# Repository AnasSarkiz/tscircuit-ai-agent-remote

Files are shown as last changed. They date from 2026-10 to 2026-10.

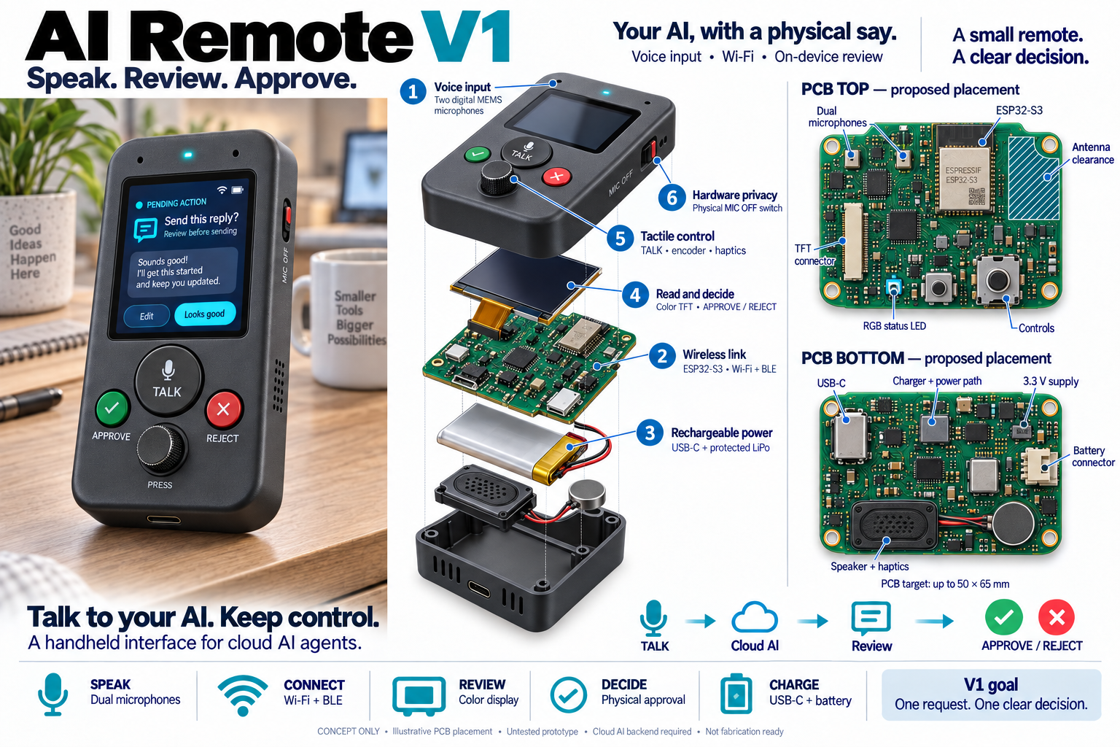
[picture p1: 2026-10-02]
assets/product-concepts/ai-remote-v1-infographic.png

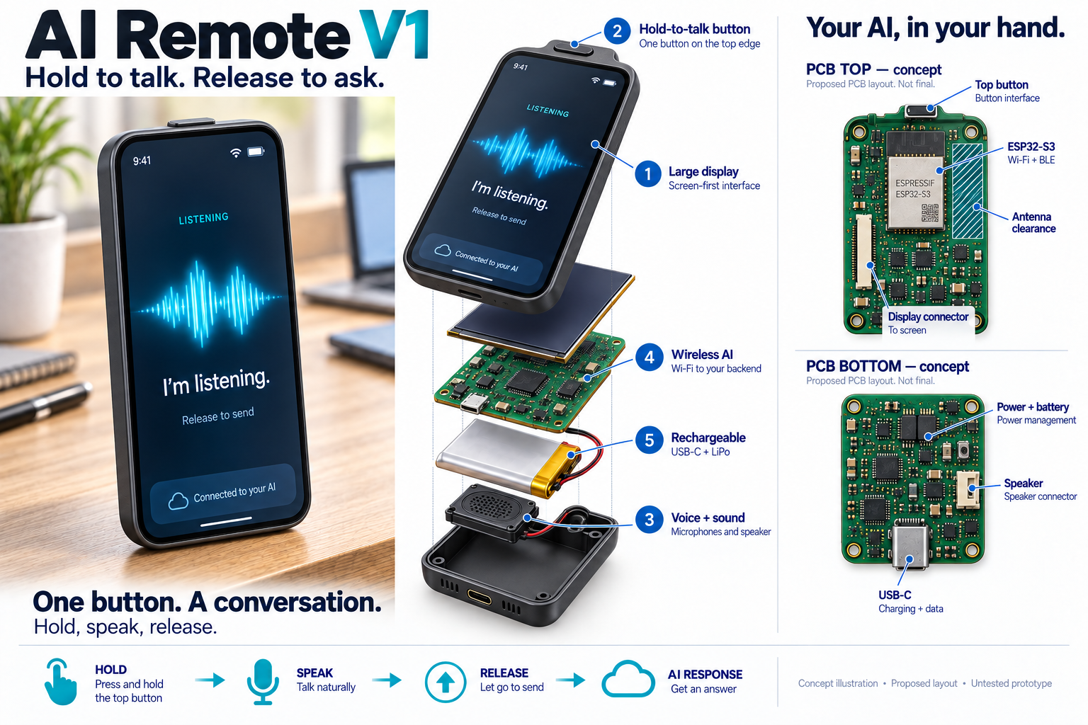
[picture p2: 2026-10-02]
assets/product-concepts/ai-remote-v1-infographic-v2.png

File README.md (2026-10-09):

**0.0.11-wip-generator-qualification — NOT READY TO ORDER.** Canonical project
runtime fixes eliminate all 169 schema failures and missing pill paste. The
untouched genuine C7848 import clears U14 supplier rotation. Local regulator
escape requirements now explicitly preserve 1 mm trunks. All 9,813 existing
connected pairs are preserved; all 125 purchased component poses are unchanged.
Fresh native checks still report 50 connection errors / 12 physically open
assigned nets plus two unassigned battery contacts. Shorts and measured copper
clearance violations are zero. The final 2.8-inch LCD, backlight, RF/mechanical
integration and battery polarity remain unqualified.

The corrected canonical Gerber library preserves USB slots. Independent strict
Gerber parsing and Excellon inspection pass; actual exports are explicitly
NOT FOR FABRICATION. Strict PnP rotation passes for all 125 parts, and the official
resolved BOM covers all 43 supplier identities. Current inventory confirms 39
identities conservatively; D2 is out of stock and three positive-stock records
require assembly-availability confirmation. Complete current/thermal and full fabrication gates remain open.
All 15 original schematic style issues are corrected in the actual schematic
trial, with identical PCB/CAD geometry. One newly exposed alignment advisory
misclassifies the VMOTOR flyback/bleeder parallel branches as a series pair;
its exact six-contact topology and conflicting orientation advice are reviewed
and retained in the schematic-style-repair evidence. Final routed checks are
recorded independently; no failure is hidden.

Core also prevents disabled subcircuits from starting autorouting during
updates; both disabled controls and an enabled control are regression-tested.
The actual isolated MCU diagnostic now has zero copper and zero routing events.
Board tests: 51 pass; the full-board fabrication gate still fails on 50
unresolved native connections. These are 50 assigned open contacts plus two
unassigned J3 contacts, not a completed board.

Receipts and source patches: `evidence/pcb-completion-2026-10-08/` and `toolchain/`.
Older entries below are historical.

---

**0.0.10-wip-microphone-bypass — NOT READY TO ORDER.** The existing C81
100 nF X7R capacitor moves beside U5 to (17.05, -28.1) mm / 180 degrees on top.
Its authored 0.3 mm top copper connects directly to the U5 supply escape and
ground pour; the remote capacitor escapes are explicitly retired.
R93 moves to (16.5, -31.42) mm to clear the capacitor; its actual supply and
clock-bias copper is rerouted while retaining/reusing existing drill positions.
A finite 2 mm supply limit is declared because the untouched supplier
courtyards impose a 1.38 mm minimum; the proposed direct route is 1.44 mm.
The ground branch has a finite 2.5 mm limit: preflight uses a GND pad 2.15 mm
away before the pour exists, while the actual top pour-entry stub is 0.60 mm. No part is
added or replaced, and no new via is required. The exact manufacturer recommends
short connections on one layer for this bypass. Actual native qualification,
remaining full-board gates and public delivery receipts are recorded in the
[current repair review](https://github.com/AnasSarkiz/tscircuit-ai-agent-remote/blob/main/evidence/microphone-local-bypass-2026-10-08/review.md).
The display/battery interfaces and fabrication gates remain unresolved; this
revision does not establish zero DRC, complete connectivity or order readiness.
Older entries below are historical.

---

**0.0.9-wip-standard-uart — NOT READY TO ORDER.** J6 now uses the genuine
JLCPCB **C160389 / JST BM03B-SRSS-TB(LF)(SN)** three-contact upward SH header.
Its UART contacts are RX/GND/TX (pins 1/2/3); hold-downs 4/5 are GND.
Authored native routes replace the former six-contact connector's connections,
with a local audio-gate detour, a 0.8 mm bottom-layer 3.3 V trunk bypass
and ordinary 0.30/0.45 mm through-via escapes.
The standard JST programmer's TX/GND/RX cable maps directly to these contacts;
the custom three-to-six adapter is removed. Programming requires separate
USB/battery power, manual BOOT/RESET and an open enclosure: mated connector
height is 6.3 mm. Hardware operation and cable assembly are untested.

The 2026-10-07 20:07 UTC official JLCPCB page reports C160389
`overseasStockCount=32191` and `canPresaleNumber=31559`, at a reference
$0.2743 each. These are public inventory fields; they do not establish global
warehouse totals, assembler allocation or an order quote. Purchased count
remains 125 parts / 43 identities. All other component poses are retained.

The requested 2.8-inch LCD is still unimplemented. Exact panel/flex/antenna
fit, J7 mapping, battery outer-contact numbering, full connectivity, toolchain
schema/paste/Gerber issues and current-carrying qualification remain gates.
See the [actual native qualification and remaining blockers](https://github.com/AnasSarkiz/tscircuit-ai-agent-remote/blob/main/evidence/programmer-direct-uart-2026-10-07/review.md).
Publication is recorded separately after exact remote byte verification.
Older status and connector references below describe historical revisions.

---

## Current speaker routing — 2026-10-07

**0.0.8-wip-speaker-routing — NOT READY TO ORDER.** Both amplifier outputs now
connect to J4 through short, explicitly authored top-layer routes. Five existing
purchased components and TP1 move to make this possible; no purchased part is
added. All 125 part identities and imported footprints/models are retained.

The completed official CLI output contains 384 traces, 325 full-span 0.30/0.45 mm
vias and 270 pours. Independent geometry checks measure **zero shorts and zero
clearance violations**, preserve all 9,842 prior terminal pairs and verify all
247 active authored regions at their nominal widths. High-current trunks use
outer layers. **50 native open-port errors and 12 physically open nets remain**
around the deferred display. J3 outer polarity is still unassigned and excluded
from that count. These measurements do not establish full zero DRC.

TypeScript, formatting, 92 routing regressions and the five source/placement
checks pass. Board tests are 48 pass / 2 fail. All 26 schematic pages were
inspected; CLI style analysis reports zero issues, while UI analysis is blocked
by the CDN certificate. Native schema, pill-pad paste, official shorts/Gerber
export, supplier rotation and current/width qualification remain blocked.

The battery PDF is retrieved, but does not number its outer harness contacts.
Display contact orientation remains unverified. Exact stock covers 42 of 43
part identities for two boards; J6/C160405 is unavailable. Reference parts cost
is $26.333 per board before fabrication, assembly, external assemblies and
shipping. This is not an orderable quotation.

[Current evidence and remaining gates](evidence/routing-continuation-2026-10-07/review.md).
[Versioned public package](https://tscircuit.com/AnasSarkiz/tscircuit-ai-agent-remote?version=0.0.8-wip-speaker-routing#files).
Publication verification is recorded in the evidence receipts. The older
checkpoints below are historical and are superseded by this entry.

---

## Historical manual routing repair — 2026-10-07

**0.0.7-wip-manual-routing-repairs — NOT READY TO ORDER.** This entry
supersedes the historical checkpoints below. U4 now has a real 0.36 mm ground
escape to a 0.30/0.45 mm through via. Its clock/data escapes were moved to make
room while retaining their original nets and minimum widths.

The supported source CLI build completes in 251.86 seconds and exits 1 with
**52 open-port errors**: 46 J7 display contacts, four U27 backlight contacts and
two SPEAKER_N contacts. The unchanged generated JSON contains 381 traces,
325 through vias and 271 pours. Independent geometric checks measure **zero
shorts and zero clearance violations**, preserve all 9,842 previously connected
numbered-terminal pairs and verify all 247 authored regions at their nominal
widths. There are still 13 physically open nets. J3's unassigned outer contacts
are excluded from that count; battery polarity and display mating remain
unqualified. Every purchased component footprint, pose and model is unchanged.

A speaker/VSYS candidate was rejected: its native output disconnected U25.2 and
C76.2 ground, losing 266 existing terminal pairs, and reported a bus-skew error.
The candidate and follow-up proposals are preserved as evidence, not accepted
routing. Original speaker constraints and original power copper remain intact.
No native errors or checks were suppressed.

The five source/placement checks pass. Board tests remain 48 pass / 2 fail;
169 strict native-schema failures, 32 missing U16/U27 paste records and the
official shorts/export error “Unsupported shape polygon” still block approval.
Two regulator traces violate explicit source widths; 63 nominal-width branches
and current/signal-integrity qualification remain open. Stock and programmer
limitations in the prior review still apply. No order or physical test occurred.

Primary supplier retrieval is blocked by HTTP 403 from the cloud policy. Add
`www.buydisplay.com` and `www.elektronik.ropla.eu` to the existing Environment
settings allowlist, then save and publish it to resume exact J3/J7 qualification.
The editable allowlist was unavailable; no unknown list was replaced.

[Current repair review and exact receipts](https://github.com/AnasSarkiz/tscircuit-ai-agent-remote/blob/main/evidence/routing-zero-drc-2026-10-07/review.md).
Matching public publication and cloud CI are separate observations; a WIP
preview does not establish zero DRC or fabrication readiness.

---

## Previous connection repairs — 2026-10-06

**0.0.6-wip-connection-repairs — NOT READY TO ORDER.** This is a historical
source/native checkpoint, superseded by the manual routing repair above.

Manual native routing reduces open-port errors from 89 to **53** and physically
open nets from 25 to **13**. The actual frozen-install CLI build completes in
256.86 seconds and exits 1 on the remaining errors. Its unchanged native output
has 380 traces, 322 full-span 0.30/0.45 mm vias and 269 pours. Independent copper
measurement finds **zero shorts and zero clearance violations**, preserves all
8,152 previously connected numbered-terminal pairs and adds 1,690 connected
pairs. All 245 authored regions meet their nominal widths after fixing an
outline-generator defect at short bends. Component footprints, poses, models
and original solver caches remain unchanged.

Source checks, CLI schematic style, TypeScript, formatting and 80 routing
regressions pass. Full board tests remain 48 pass / 2 fail. Remaining native
errors are 46 J7, four backlight U27, two SPEAKER_N contacts and U4 ground.
J3's centre NTC is routed; its outer polarity and J7 mating remain unqualified.
Two regulator routes violate their explicit source widths; 63 nominal-width
branches, current/signal integrity, 169 schema failures, 32 missing paste
records and polygon Gerber export still block fabrication. Dated stock still
shows J6/C160405 unavailable. The standard programmer needs the documented
adapter and has not been hardware-tested.

[Actual repair review and receipts](https://github.com/AnasSarkiz/tscircuit-ai-agent-remote/blob/main/evidence/connection-repair-2026-10-06/review.md).
Matching public source/native publication is established by its anonymous
verification receipts, not by preview availability or a passing cloud CI claim.
No fabrication order or physical test has been performed.

---

## Current six-point review — 2026-10-06

**0.0.5-wip-style-vias-power — NOT READY TO ORDER.** This entry supersedes the older counts and status below.

J1 now uses the requested native USB-C schematic symbol while preserving its numbered contacts, supplier identity, physical footprint and models. CLI schematic-placement analysis reports zero issues. The actual UI analysis was invoked but its external analysis module failed to load; this is a blocked check, not a passing result.

The clarified high-current requirement is implemented: all 80 authored high-current trunks and 59 audited native high-current traces use top/bottom copper. Six low-current pull-up/control/probe branches have separate documented requirements. All 217 vias physically span all four layers, with exactly 0.30 mm holes and 0.45 mm pads; blind/buried vias are explicitly disabled. All 151 native supply/control and relocated signal regions meet their nominal widths.

The supported frozen-install CLI build completes in 247.03 seconds and exits 1 with **89 real open-port errors**. Native output contains 328 traces, 217 vias and 183 pours. The independent geometry audit measures zero shorts and zero clearance violations, preserves all 8,146 previously connected port pairs, and still finds **25 physically open nets**. All 125 purchased component footprints, poses and models are unchanged. TP1 moves to (-22.2, 12.3) mm inside the main ground island. The five source checks, copper-free placement build, TypeScript, formatting and 64 routing regressions pass. Board tests report 48 pass / 2 fail (fabrication and strict native schema).

Official exact-part JLCPCB pages cover all 43 identities / 125 placements: 42 identities report enough total stock for one board; **J6 C160405 reports zero stock**. Positive stock for U1, D2 and U16 does not qualify assembly allocation. No stock reservation or assembler rotation approval is claimed.

Remaining fabrication blockers include unresolved J3 numbered outer polarity and J7 FPC mating, incomplete connections, 169 strict native-schema failures, missing pill-pad paste, unsupported polygon Gerber shorts/export, two regulator switching routes with 0.275 mm necks below their explicit 1.0 mm source requirement, 55 nominal-net-width branches requiring load review, and supplier rotations/current/stackup/signal-integrity/mechanical qualification. The standard JST programmer needs the documented adapter; direct connector mating and hardware operation are untested.

The supported source snapshot comparison completes in 61.13 seconds and fails on PCB and schematic differences; committed references are retained. All 26 native A4 pages, four copper layers, mask/paste and critical zooms were inspected. Native component guides cover all 135 references with valid annotation schema. Final component inventory confirms 32 missing pill-pad paste records on U16/U27.

[Full review and actual receipts](evidence/six-point-board-review-2026-10-06/review.md). Publication is recorded independently; native preview availability does not establish passing cloud CI or fabrication approval. No order or physical test has been performed.

---

## Schematic component explanations — 2026-10-06

Revision `0.0.4-wip-schematic-notes` adds a plain-English explanation for every
schematic component reference: 125 purchased components and 10 solder/test
pads. The 13 circuit drawings link to paired A4 component-guide pages, numbered
14–26, to keep the original symbols and connections readable.

Open the schematic sheet selector in tscircuit and choose a **Component guide**
page for the relevant circuit. Guides explain power, controls, USB/programming,
display, speaker, haptic drive, microphones, backlight and measurement access.
Battery connector polarity and display mating remain explicitly unverified.

[Annotation validation and rendered pages](https://github.com/AnasSarkiz/tscircuit-ai-agent-remote/blob/main/evidence/schematic-component-notes-2026-10-06/review.md).
This documentation revision does not establish fabrication or hardware readiness.

The fresh frozen-install native CLI build completed in249.96seconds and
retains90open-port errors. Annotation coverage/native schema, TypeScript and
formatting checks pass. AllPCB/source nets/ports and the original schematic
symbols/wires/labels match the prior board. The source checkpoint verifies
unchanged imports, models, lockfile and routing artifacts. The accepted schematic
snapshot adds all26A4pages; the PCB reference remains unchanged.

Final board checks remain blocked:47tests pass/3fail,169native schema failures
and90open ports. The placement fixture's extra mismatch is only10native test
pads receiving empty supplier maps from the CLI; strict PCB/net comparison
passes. The required source snapshot reaches its recorded360-second budget;
the supported snapshot of accepted native JSON completes, passes the reviewed
schematic reference and retains the original PCB-reference mismatch.

---

## Latest MCU correction — 2026-10-06

**Revision `0.0.3-wip-local-bypass`; NOT READY TO ORDER.** C31 now has a
native top-layer local supply/ground connection beside U1: supply-pin distance
falls from36.000mm to2.000mm, with a0.8mm branch to the existing U1 supply
escape and no additional supply via. C30 now uses the genuine imported
22µF GRM188R61A226ME15D/C84419 shown in Espressif's reference circuit.
Bulk placement/effective capacitance and microphone bypasses still need work.

Fresh native copper has306 traces,249 full-span ordinary vias and190 pours:
**0measured shorts/clearance violations**, but26 open nets/90 native errors and
35GND islands remain. All152 authored region widths pass; two switch traces
and55 nominal-width branches still need correction/current qualification.
Eight target programmer copper groups pass; programming is not hardware-tested.
The supported BOM resolver generates125 purchased rows with verified recorded
MPNs/package labels and no blank descriptions. Current stock, rotations,
169schema failures,32missing paste apertures, polygon Gerber export and exact
battery/display mating still block fabrication.

[Correction evidence](evidence/board-corrections-2026-10-06/review.md).
The complete publication package now installs with the original frozen lockfile.
Its native CLI build finishes in222.33seconds and reports the90open-port errors;
all physical copper records match the validated board. Publication/remote CI
receipts are separate; this is a WIP step, not fabrication approval.

Fresh frozen-install snapshot also completes and fails on both original SVG
references (246.93seconds); references were not updated. Source discovery is
working, while board validation remains blocked.

---

## Latest placement, component and programmer review — 2026-10-06

**NOT READY TO ORDER.** Electrical placement needs correction even though the
native overlap check passes: U1's nearest external3V3 bypass is26.160mm away;
U5's assigned100nF bypass is18.191mm away on a different supply copper island.
The manufacturer's local microphone bypass recommendation is not met by the
current separate-via arrangement.19 IC supply locations are measured in the
[new six-point review](evidence/board-programmer-stock-review-2026-10-06/review.md).

The requested Standard JST programmer v0.8.0 can use UART conditionally:
J5.1TX→J6.6RX, J5.2GND→J6.1GND, J5.3RX→J6.5TX. A custom3-to6 adapter,
separate target power, matching firmware and manual BOOT/RESET are required.
5host logical and8target logical/physical groups pass; no actual flashing test.
Fresh manufacturer pin tests5pass/0fail. Board copper/parts/imports remain
unchanged:26 open nets/90 native port errors and existing fabrication blockers.

All43 exact JLCPCB identities/125 placements have a dated stock manifest;
**current stock is unverified**, because the inherited proxy denies
jlcsearch.tscircuit.com with403. That one domain was added to the reusable
network draft; review/save and publish it in environment settings before retry.
Saving the draft does not apply or publish it. Historical C107701 stock8vs5
per board and C98220 stock22vs20 warrant priority refresh. No unchanged board
registry upload or fabrication approval is claimed.

## Current order-readiness audit — 2026-10-06

**NOT READY TO ORDER.** Fresh current native render is byte-identical to the
canonical board. Measured geometry:0 shorts/0 clearance violations, but26
physically open nets and90 native connection errors; J3 outer contacts are
additional unassigned omissions. All306 traces/792 wire segments checked:
0 below0.20 mm,2 regulator switch routes below explicit1.0 mm source minima,
and55 traces below named-net nominal widths needing current/escape review.
All152 authored region widths pass. Current critical manufacturer pin tests
pass; physical connectivity and current capacity remain unapproved.

Assembly still fails:32 missing U16/U27 paste records,169 native schema
failures,31 blank BOM descriptions,125 unqualified supplier rotations.
J3 pack polarity/J7 flex mating, stock/stackup/current/mechanical/fabrication
qualification remain open. Types and60 routing regressions pass; board tests
47pass/2real failed gates. Board/import/dependency/cache bytes unchanged.
[Full order-readiness report and measurements](evidence/order-readiness-2026-10-06/review.md).
This verification adds no copper and does not create a duplicate registry upload.

## Current cloud routing checkpoint — 2026-10-05

Public [tscircuit0.0.2-wip-cloud-routing](https://tscircuit.com/AnasSarkiz/tscircuit-ai-agent-remote?version=0.0.2-wip-cloud-routing#files) now has**116/116 exact-matching files**, including current native JSON and required display-connector STEP. A supported multipart archive resumed the existing release and enabled its normal cloud build, which has started. [Exact upload/build evidence](evidence/cloud-tsci-publication/review.md). This is an engineering WIP; fabrication is not approved.

[Board preview](https://tscircuit.com/AnasSarkiz/tscircuit-ai-agent-remote/releases/c6bd1e5c-0979-498a-bb8a-9533013cf51d/preview): the registry preview endpoint finds `index.circuit.tsx` and returns the native board array identical to the locally generated artifact. The separate cloud CI build remains running in the latest observation; no completed CI result is claimed.

**Engineering WIP — routing incomplete; NOT FABRICATION READY.** Native output from the matching current source has **306 traces, 250 ordinary full-span vias, 190 pours and 90 native open-port errors**. The independent geometry audit reports **0 measured violations / 0 shorts**, with all **152 authored region widths preserved**, but **26 physically disconnected nets** remain. J7 accounts for46 native errors; unassigned J3 outer contacts are outside that count.

[Current review](evidence/cloud-runs/review.md) · [Exact build receipt](context/build-checkpoint.json) · [Cloud continuation](CLOUD_HANDOFF.md). Native JSON SHA256 `81c31f77ac0871bfc4414b0940752e4f4fe0692a62089320b409908d4a8d5315`. TypeScript/maintained-source formatting pass; routing regressions17pass; board tests42pass/2failing fabrication/schema gates. Five electrical/placement checks and copper-free CLI placement build pass. Full routed CLI build/bitmap shorts/snapshot exceed time budgets; Gerber export/shorts fail unsupported polygon. Native schema169failures and32missing U16/U27 paste records remain. Battery/display mating, current/SI, BOM/CPL/stock and final mechanical/fabrication qualification are open.

The managed cloud instance supports the checked native workflow. Source `scripts/cloud/env.sh`; use the single-operation supervisor. Verified lossless event archives prevent CLI file-loader memory exhaustion. Clean frozen installation still needs the unapplied api.github.com network allowance; startup instructions are saved as a draft. GitHub and complete registry WIP publication do not approve fabrication; do not repeat unchanged uploads.

---

## A7 Codex Cloud migration checkpoint — 2026-10-05

Local memory-intensive routing is stopped at the user's request. Continue this existing board in Codex Cloud using [CLOUD_HANDOFF.md](CLOUD_HANDOFF.md), [cloud start prompt](context/cloud-start-prompt.txt), root AGENTS.md, repository skills and original request/decision records. Linux setup: `bash scripts/cloud/setup.sh`; task shell: `source scripts/cloud/env.sh`. Every heavy command uses the single-operation memory/time supervisor. No cloud VM execution has yet been verified; the GitHub connector currently omits this board repository and needs the user's browser connection update.

Canonical generated `dist/index/circuit.json` is byte-identical to the last completed native replay and its restored board source: **138 traces, 116 vias, 275 native unconnected-port errors**. It is a partial engineering prototype. The two battery outer contacts and contact-dependent display fanout remain deferred. Known actual U2 ordinary-via clearance is **0.192053 mm versus 0.20 mm required**; its unbuilt correction is saved separately. Full copper/placement/mechanical/current/USB/paste/BOM/fabrication gates remain open. No new registry publication is attempted under the current A7 brief.

[Exact build receipt](context/build-checkpoint.json) and [296-file checkpoint manifest](context/checkpoint-sha256.json) identify the carried-over bytes. TypeScript passes; tests **40 pass / 4 fail**, formatting **13 errors** retained. These failures are not suppressed. Linux dependency setup/supervisor execution awaits the actual cloud environment. Historical raw native trials are losslessly archived with per-file hashes; accepted route files remain directly usable. Do not restart incomplete trials as accepted copper.

---

## A6 public outcome — verified 2026-10-04

Public [GitHub A6 implementation](https://github.com/AnasSarkiz/tscircuit-ai-agent-remote/commit/a699a2d4337d5eafa26a777fee58c037de491f8f) and committed circuit JSON are anonymously byte-verified. Public [tscircuit0.0.2-wip-a6-bom-routing](https://tscircuit.com/AnasSarkiz/tscircuit-ai-agent-remote?version=0.0.2-wip-a6-bom-routing#files) has102/103matching board-only files, including this JSON and all saved routes. The required11.4MB C262650 connector STEP is404 after native compressed/fallbackHTTP413; publisher exit1, ready_to_build=false, no mismatched/unverified or extra files. **B-009 publication remains incomplete.** GitHub push succeeded. [Exact receipts](evidence/a6-bom-routing-2026-10-04/publication/review.md). Receipt-only update changes no runtime inputs and does not trigger another upload. **NOT FABRICATION READY.**

---

## A6 current checkpoint — 2026-10-04

**Engineering prototype — NOT FABRICATION READY.** This supersedes historical A5 counts below. Genuine in-stock replacements are implemented: seven C22548→C21190 (eight C21190 total), six C105588→C22775. Active125 purchased PCB parts /43identities plus10native pads. Published core0.0.2083 polygon paste fixes13 formerly missing pads;32 pill pads still lack paste. Current native copper20traces/2vias; five missing backlight traces resolved, unconnected-port errors413→402. Genuine saved phase replay and actual added-copper geometry verified; all prior11traces/2vias unchanged.

Required five native checks and copper-free placement CAD build pass. Format/types pass; tests42pass/2retained failures and full native strict schema169failures. Diagnostic PCB-image shorts passes, but **required Gerber-based shorts check fails “Unsupported shape polygon”**. Canonical routed build exits1 with402 retained unconnected-port errors. Final layout/assembly/fabrication gates remain blocked. Fresh4layer/paste/detail/13A4/3D prototype previews inspected.

Battery centreNTC confirmed; outer numbered polarity is still absent from the exact supplier drawing and stays unrouted. BuyDisplay panel has integrated ILI9341 and82.712% nominal physical coverage; actual FPC/contactface/pin1 mating and current bare-panel availability remain unqualified. JST board-thickness tolerance requires a mechanical/stackup revision; current conservative height becomes15.07 mm at a qualifying1mm PCB, above15mm. PCB stays50×65 mm; case max60×75×15 mm. No fabricated confirmation, generic imports or orders.

[Detailed A6 review](evidence/a6-bom-routing-2026-10-04/review.md) · [Active inventory](evidence/a6-bom-routing-2026-10-04/inventory.md) · [Mechanical primary sources](evidence/a6-bom-routing-2026-10-04/mechanical-search.md). Parentfaa491d22d1a55210833a8ea3086ae56dc450245. Intended public version0.0.2-wip-a6-bom-routing; verify publication receipts before claiming upload complete. Watcher stays paused; no cross-chat issue messages.

---

## A5 public publication outcome — verified 2026-10-04

Implementation [314cb1b](https://github.com/AnasSarkiz/tscircuit-ai-agent-remote/commit/314cb1b36d0a9b6d641c018ce27288eb47815c95) is on public GitHub main. Anonymous raw Circuit JSON is byte-identical to the validated local output:2,728,724bytes, SHA256 f4319f271856f07477340c3342ce9a576236be438913be4aca5bd9786487d1c5. Public [tscircuit0.0.2-wip-a5-motor-pads](https://tscircuit.com/AnasSarkiz/tscircuit-ai-agent-remote?version=0.0.2-wip-a5-motor-pads#files) verifies94of95board-only files, including current Circuit JSON and all saved phases, with no extra or unverified/mismatched files. private=false/unlisted=false. Native compressed archive and fallback both reject the required11.4MB C262650 STEP with HTTP413; publisher exit1 and ready_to_build=false. **B-009 registry publication remains incomplete**, separately from the completed J8 source removal. No same-state retry, omitted model or forced cloud readiness was used.

Native source/checks/results and169 strict-schema failures are recorded in the A5 review. All imported definitions stayed unchanged. The newly rendered native SVG/log whitespace warnings from git diff --check were accepted as generator bytes, without hand-editing output. Old dist/index/3d.glb and mechanical.html are historical and were excluded from the95-file runtime publication; PCB and native JSON are current. The public source push succeeded; registry files are partial. Receipt-only outcome commit changes no board runtime inputs and does not trigger another publication. [Detailed receipts](evidence/a5-connector-simplification-2026-10-04/publication/review.md). **NOT FABRICATION READY.**

---

## A5 — motor solder pads and independent routing, 2026-10-04

J8 is removed at the user's request. The external vibration motor remains connected through native top-side 2 mm solder pads TP_MOTOR_P (VMOTOR/M+) at (22,−8) mm and TP_MOTOR_N (HAPTIC_N/M−) at (22,−11) mm. Pad copper edge gap is 1 mm; board edge gap is 2 mm. M− is the switched motor return, not a general GND pad. The motor harness requires soldering and enclosure strain relief. J6 remains: USB-C supports ESP32-S3 flashing/debugging, while J6 is optional backup UART/BOOT/EN access. Normal USB operation is intended, not physically tested. Five plug connectors remain: J1, J3, J4, J6 and J7. No imported component definitions were changed.

Native selected phases now retain 11 actual traces and 2 ordinary 0.30/0.70 mm through vias. The original four copper records are unchanged; all saved phases replay with identical trace/via records. REG_FB, REG_PG, HOLD_BUFFER_OUT, USB_CC1, USB_CC2 and CHARGER_ILIM have no remaining native connection errors on their selected terminals. Actual new wire minima: pad clearance0.20533 mm, other-net trace0.29987 mm, drill0.33834 mm. GND pour source clearance0.21 mm gives actual via antipad clearance0.20730 mm, resolving the measured0.19735 mm aperture gap. This is partial-signal geometry review, not whole-board current/impedance/fabrication approval.

Required five native checks and shorts exit0; placement-only build0 with no traces/vias/pours. Format/types0; tests42pass/2known failures (schema fixture and full fabrication gate); full strict native JSON has169 failing elements. Canonical build exits1 with413unconnected-port/5missing-trace errors retained. PCB, all four layers, MCU A4 sheet and controls A4 sheet were inspected. Snapshot changes reviewed as prototype previews only. Full placement, display/FPC, battery outer polarity, power/paste/BOM/stackup, case/harness and complete copper gates remain open. No fabrication outputs or physical tests approved.

Earlier charger routing attempts hit native iteration limits; an R1 relocation failed actual placement (R33/U16 conflicts) and was reverted to its prior valid location. Q9/C20917 routing exports cannot save the phase due to non-unique native port selector; raw events are preserved and that gate net remains unrouted. No reconstructed cache or runtime workaround was used. The screen has an integrated ILI9341 controller per the BuyDisplay datasheet; its FPC direction is still unqualified and display routing is deferred as instructed. J3 outer contacts stay open.

Evidence: [A5 review](evidence/a5-connector-simplification-2026-10-04/review.md), [exact replay](evidence/a5-connector-simplification-2026-10-04/routing-replay-receipt.json), [via measurements](evidence/a5-independent-routing-2026-10-04/native-final-via-audit.json). Parent source bff3a87c974d4684f3fb159b0958abbb8a10620e; intended public runtime version0.0.2-wip-a5-motor-pads. Publication outcome will be recorded separately. Watcher stays paused; cross-chat messaging stays disabled. **NOT FABRICATION READY.**

---

## A4 placement-review public outcome - verified

Implementation [9364e2c8](https://github.com/AnasSarkiz/tscircuit-ai-agent-remote/commit/9364e2c817dd659daa954bf2c50e6e0bb03fdbdf) and its freshly rebuilt Circuit JSON are public on GitHub and anonymously byte-verified. Public [tscircuit 0.0.2-wip-a4-placement-review](https://tscircuit.com/AnasSarkiz/tscircuit-ai-agent-remote?version=0.0.2-wip-a4-placement-review#files) has91/92 exact-matching runtime files, including that JSON and saved routes. The required C262650 STEP remains missing after native archive/fallback HTTP413; exit1/ready_to_build=false. B-009 publication completion remains blocked separately from local placement. [Exact publication receipt](evidence/a4-placement-gate-2026-10-04/publication/review.md). This outcome changes no board inputs and does not trigger an unchanged registry retry.

## Latest placement gate review — A4

**Native PCB placement checks pass, but the full placement gate is BLOCKED before additional routing.** Added a true copper-free inspection mode: `bun run build:placement`. Its native output has zero traces/vias/pours and exactly matches canonical components, connections, pads, holes and keepouts. All five required checks pass;126 native CAD body bounds have zero overlaps. Original four traces and saved routes remain unchanged. Current tests:41 pass/2 retained fabrication-schema failures. Fresh current Circuit JSON is rebuilt from the same source.

Before additional routing: qualify the actual BuyDisplay portrait FPC/pin1/contact fold, the 0.8 mm PCB/PH-header thickness and USB stackup, and case actuators/harness/mounting fit. Battery outer contacts stay unassigned/unrouted as instructed. The431 remaining connection errors are routing work, not a circular prerequisite for starting routing. [Detailed placement review](evidence/a4-placement-gate-2026-10-04/review.md). **NOT FABRICATION READY.** Intended public runtime version `0.0.2-wip-a4-placement-review`; see its receipt before claiming publication complete. Watcher paused; cross-chat messages disabled.

## A4 publication verified — partial registry outcome

Public [GitHub A4 implementation 1a0b0d0b](https://github.com/AnasSarkiz/tscircuit-ai-agent-remote/commit/1a0b0d0b77294438c431a3e4246079e4363f2f50) and anonymous committed Circuit JSON are verified. Public [tscircuit 0.0.2-wip-a4-display-coverage](https://tscircuit.com/AnasSarkiz/tscircuit-ai-agent-remote?version=0.0.2-wip-a4-display-coverage#files) contains 91 of 92 matching runtime files, including the same fresh built Circuit JSON. The required C262650 connector STEP remains missing after HTTP413 in the official compressed upload and native fallback; publisher exit 1, ready_to_build=false. **B-009 publication remains incomplete; NOT FABRICATION READY.** [Exact receipts](evidence/a4-display-coverage-2026-10-04/publication/review.md). These outcome notes change no board input and do not trigger another registry retry.

# Latest A4 — 82.7% physical display coverage trial

**WIP prototype; NOT FABRICATION READY.** This supersedes conflicting A3/A2 selections below. Provisional external BuyDisplay **ER-TFT026-1**, 46 × 64 mm portrait body, overlaps the unchanged 50 × 65 mm PCB by **82.712%** (81.737% with stated dimensional/position allocation). Overhang, flex and bezel are excluded. Bare-panel availability and the current drawing/FPC are still unconfirmed; this is not a qualified purchasable display selection.

Implemented genuine C157929/C173752 internal side-entry PH headers, TPS60230RGTR/C1848364 four-channel backlight with 10 kΩ nominal 62.4 mA total, moved placement/mounting trial, rotated battery envelope and **0.8 mm trial PCB**. The thin stackup and USB impedance need new qualification. Battery pin2=NTC; both outer contacts stay open. Four original native traces are preserved; most connections remain unrouted. Fresh canonical build retains 431 connection errors; 38 tests pass and two fabrication/schema gates fail. Placement and short checks pass without claiming full routing or fabrication approval.

[Full A4 engineering review](evidence/a4-display-coverage-2026-10-04/review.md) · [Interactive A4 native model and display envelope](http://127.0.0.1:4949/evidence/a4-display-coverage-2026-10-04/mechanical.html). Current PCB count:134 physical components,496PCB ports,76named nets. Watcher remains paused and cross-chat issue messages remain disabled. Publication receipts are recorded separately; intended public package version `0.0.2-wip-a4-display-coverage`.

---

## Latest A3 result — verified approved compressed attempt

The human approved official compression. The registry rejected the archive with HTTP 413; the native CLI fallback exited 1. Anonymous readback of [`0.0.2-wip-a3-buydisplay-first-copper-compressed`](https://tscircuit.com/AnasSarkiz/tscircuit-ai-agent-remote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) verifies 87 of 88 matching board-only files, including the current `dist/index/circuit.json`. The required C262650 STEP model is missing. HTTP 413 blocks both supported publication modes. B-009 remains open and `ready_to_build=false`; no custom upload, model omission or retry loop was used. [Exact outcome](evidence/a3-routing-2026-10-04/buydisplay/publication/compressed/review.md).

The reviewed Espressif WROOM-1 drawing (v1.8, page 42) specifies a module height of 3.1 ± 0.15 mm. At its maximum, the glass study has only 0.05 mm clearance before other assembly tolerances. Retaining the CAD model's 0.19 mm gap would conditionally require 15.01 mm total thickness, exceeding the 15 mm enclosure maximum. No enclosure enlargement or placement freeze is claimed. [Manufacturer-height calculation](evidence/a3-routing-2026-10-04/buydisplay/module-height-tolerance.json). Runtime source, package and Circuit JSON bytes remain unchanged by these outcome and qualification notes. **NOT FABRICATION READY.**

## A3 publication result — verified 2026-10-04

Public GitHub implementation [`68d79568`](https://github.com/AnasSarkiz/tscircuit-ai-agent-remote/commit/68d79568bb39478c9745e1b5a5fc102d3687b0a7) is verified. Public tscircuit [`0.0.2-wip-a3-buydisplay-first-copper`](https://tscircuit.com/AnasSarkiz/tscircuit-ai-agent-remote?version=0.0.2-wip-a3-buydisplay-first-copper#files) contains87of88exact matching runtime files, including the current built Circuit JSON; required C262650 connector STEP is missing after HTTP413. Native publication exits1; registry ready_to_build=false. The USB STEP timeout persisted correctly. **B-009 publication remains incomplete; NOT FABRICATION READY.** Exact receipts and details: [publication review](evidence/a3-routing-2026-10-04/buydisplay/publication/review.md). No runtime/package bytes changed during upload/readback. This receipt update and viewer actuator-corridor alignment change no board inputs and require no metadata-only registry version.

# Latest A3 BuyDisplay and first-copper checkpoint — 2026-10-04

**Engineering prototype — NOT FABRICATION READY.** This supersedes conflicting A2/A1 selections below. The external screen is now **BuyDisplay/EastRising ER-TFT022-1, bare 2.2-inch 240×320 TFT, no touch**, purchased separately from the PCB. JLCPCB supplies the board electronics and the genuine **AFC07-S50ECA-00/C262650 top-contact50-pin connector**, not the screen. Its54.36×40.3 mm landscape glass spans the full50 mm PCB width. The raised-glass/flex/height tolerance study remains open inside the unchanged50×65 mm PCB and60×75×15 mm maximum enclosure.

Electrical source wiring uses panel n→J7(51−n) for the planned right-edge single fold, SPI II mode1110,2.8 V logic/level translation and three separate TPS60231 current sinks. The old HS20HS072RX,12-pin connector and resistor-fed backlight are superseded. Battery centre2 staysPACK_NTC and the outer contacts stay open.

Actual partial copper now exists: two short MCU USB traces and two compact regulator switch traces,0vias. Original native routes/events and supported replay are preserved before moves; the regulator island/cache were moved together−8 mm X. The other nets are not routed. Current whole board:134physical components(126purchased+8testpoints),502PCB ports,75named nets. Required remaining-connection errors are retained; no fabrication outputs are approved. Full technical review: [BuyDisplay integration and fit limits](evidence/a3-routing-2026-10-04/buydisplay/review.md). [Live mechanical study](http://127.0.0.1:4949/evidence/a3-routing-2026-10-04/mechanical.html).

Native placement overlap/keepout errors are zero. Source, netlist and pin-specification checks have no errors; supplier metadata warnings and connector-access warnings remain disclosed. Four orientation suggestions were applied. The source-level schematic pin-map and imported connector orientation tests are distinct from physical panel operation. Full routing/schema/fabrication tests retain their failures; publication never means fabrication approval.

Source parent0300c2eed5d591b24dba9d2bdd59e17de0f94bf7. Intended public release0.0.2-wip-a3-buydisplay-first-copper; verify receipts before claiming it published. Background watcher remains paused. The user revoked cross-thread issue messages; no issues are sent to another chat.

## Public A2 remote outcome — verified 2026-10-04

Board implementation commit **8332577b7eff34815843084d4fbe5549d5066e78** reached public GitHub main; anonymous committed Circuit JSON is identical to local: 2,300,592 bytes, SHA-256 `fbf9e2b576a9e37f695e894d9458500c33d5508b052b10692dcf99bc474dcd3f`.

Public tscircuit releases **0.0.2-wip-a2-display-mounting** and the one bounded native retry **0.0.2-wip-a2-display-mounting-retry1** both contain all75 expected board-only files with exact anonymous byte-hash matches, zero missing/extra/unverified files, private=false/unlisted=false. Native publication exits1 each time:74reported successes/one timeout on `imports/TPS63802DLAR/TPS63802DLAR.step`; the timed-out model persisted correctly in both releases. The native CLI exits before its final `ready_to_build=true` update. Both releases remain **ready_to_build=false**, so **B-009 build queuing/publication completion remains blocked despite complete public file content**. Null build errors do not prove a cloud build. No forced readiness, custom upload, compression, evidence omission, repeated retry loop or imported-model edit was used.

Receipts and safe logs are in `evidence/routing-intake-2026-10-04/`; first attempt kept separately. Runtime/source bytes were frozen and unchanged throughout. Receipt-only follow-up does not change any board input or require another registry publication. Both paste/schema and this upload completion behavior were reported to the authorized correction chat. Background watcher remains paused.

[GitHub board revision](https://github.com/AnasSarkiz/tscircuit-ai-agent-remote/commit/8332577b7eff34815843084d4fbe5549d5066e78) · [Public tscircuit A2 files](https://tscircuit.com/AnasSarkiz/tscircuit-ai-agent-remote?version=0.0.2-wip-a2-display-mounting-retry1#files).

# Latest A2 checkpoint — 2026-10-04

**NOT FABRICATION READY.** This section supersedes conflicting historical A0/A1 selections and status below. A2 updates the genuine C11051 twelve-pin display connector, manufacturer display wiring, centre battery NTC, two native M2 mounting trials and provisional placement. Battery outer numbering remains pending; both outer contacts are unconnected/unrouted. Display/flex/enclosure/RF fit is still open; routing remains disabled. Full report: [A2 fabrication checkpoint](evidence/routing-intake-2026-10-04/fabrication-report.md).

# Public board publication — 2026-10-04

Both destinations are now **public** and anonymously accessible. Published source
commit **6f8f4a270e76c7455084a1d43ea92833694179f2** and registry release
**0.0.2-wip-a1-public-board**. Native upload exited0, 75 successes/zero failures;
anonymous exact-version readback verifies all 75 hashes with no missing, extra or
unverified files. Public GitHub and registry `dist/index/circuit.json` are identical
(2,298,951 bytes; SHA-256 `0be465e43d862abd74d8fa7b8f397738fcae90f8134c330cf2311bdf54d273ca`).
Registry `is_private=false`, `is_unlisted=false`, `public_dist_enabled=true`.
`ready_to_build=true` and null reported build errors do not establish a completed
cloud build or fabrication readiness. Receipt-only follow-up changes no runtime
input and needs no additional registry release.

The user requested public GitHub and tscircuit destinations and a committed built
Circuit JSON. The ignore rule now permits only `dist/index/circuit.json` within
`dist`; other build artifacts remain excluded. The board-only preparer includes
the current native build unchanged, so GitHub and the registry receive identical
bytes. Published release: **0.0.2-wip-a1-public-board**. Public visibility and identical
remote build hashes are verified below. Native build, all five pre-routing
checks, format and root/staged TypeScript pass. Tests retain the known B-010
failure (30 pass/one fail). The native JSON matches the inspected connector
revision except its filesystem metadata; zero traces/vias/native errors. Existing WIP fabrication blockers
remain explicit; routing stays disabled and the background watcher stays paused.

# AI Remote A1 — complete unrouted placement preview

Connector review, 2026-10-04: the speaker J4 and motor J8 were rotated 180° so
their actual CAD mating cavities face the left/right board edges. USB-C, battery
and service openings already face their intended edges. The display FPC stays
internal for the raised screen; exact ribbon/latch/Z clearance remains provisional.
Current full-board and connector close-up views are in
`evidence/connector-orientation-review-2026-10-04/after/`. Native placement has
zero errors and three preserved orientation warnings, detailed in that review.
No routing was enabled.

Published connector revision: **0.0.2-wip-a1-connectors-outward**, board-source
commit **0191b8e5db4c8c29dc7d75bcd43455cb1747200e**. Normal native file-by-file
upload succeeded for all 75 board-only files; exact-version readback verified
all hashes, including the fresh `dist/index/circuit.json`. No documents/scripts
were uploaded. Still a private, unrouted prototype with fabrication gates open.

Build the current board with `bun run build:placement`, then prepare the runtime-only
registry package with `bun run publish:prepare`. The preparer copies that native build
into `.publish/board/dist/index/circuit.json` byte-for-byte; commit the same root
`dist/index/circuit.json` to GitHub. Publish from `.publish/board` through the native
CLI with `--include-dist`. Keep installed dependencies outside the upload folder. The generated package contains
only the transitive board source, referenced imported OBJ/STEP models, build manifests
and `dist/index/circuit.json`; research documents, tests and scripts remain in GitHub.
Standard native file-by-file upload is used for this reduced package. It remains an
unrouted prototype. Exact file hashes and remote verification are recorded under
`evidence/minimal-board-publication-2026-10-04/`.

Following the user's magnetic-shutter package example, 27 genuine components were
re-imported with the native model-CDN option. Their footprint/pin definitions are
unchanged, and all 54 remote model assets match the original local assets byte-for-byte.
Six imports retain their reviewed local models, including the authorized microphone
hole correction; candidates with other changes were not installed. The final runtime
package has **75 files**, including the generated Circuit JSON.

Published private runtime release **0.0.2-wip-a1-board-runtime** from board-source
commit **81e745660507007623d7c0ccc5076fce237aa4b9**. Native publisher exited0 with
75 uploads/zero failures; exact-version readback verified all 75 byte hashes,
including `dist/index/circuit.json`, and no missing/extra files. Registry publication
is complete for this reduced runtime release; earlier full-evidence releases remain
historically incomplete. `ready_to_build=true` is upload/build-queue status, not proof
of a completed cloud build or fabrication approval.

**Prototype; not for fabrication.** The complete `main.tsx` now integrates all
major subsystems on a **50 × 65 mm**, four-layer, 1.6 mm board with 3 mm rounded
corners. The requested 50 × 55 mm first trial was rendered and retained; it had
connector/passive overlaps, so the preview uses the approved maximum height.

**122 genuine JLC-imported electronic components + 8 native copper test pads**,
all on top. Hardware includes ESP32-S3, USB-C, BQ24074 charging/power path,
TPS63802, two ICS-43434 microphones, MAX98357A, display connector, three-contact
battery/NTC connector, speaker connector, external motor connector/driver,
physical top HOLD button, side privacy switch and internal BOOT/RESET/service.

Views and the complete **13-page A4 schematic** are saved in
`evidence/integrated-preview-2026-10-03/`: `pcb-top.png`, `pcb-ratsnest.png`,
`3d-top.png`, `3d-bottom.png`, `schematic.pdf` and interactive `board.glb`.
These are generated from the actual circuit/models. The blue PCB rectangles
show the provisional raised LCD body/active area. The 3D images show PCB assembly;
they do not establish LCD/enclosure/battery fit.

Run `bun run build:placement` to rebuild. **Routing stays disabled**: there are
zero copper traces/vias and no saved route cache. No fabrication outputs or
physical qualification are claimed.

Provisional: HS17QS178RX display/FPC and backlight application; protected 1S
500–1000 mAh pack/NTC/polarity; enclosure-mounted 8 Ω speaker and 3 V motor;
TALK actuator, mounting/raised display/RF mechanics and privacy transitions.
Microphone polygon solder paste B-005, final electrical/thermal/mechanical
qualification, routing/DRC/fabrication exports, strict native schema B-010,
BOM-description B-015 remain open. B-009 is resolved for the runtime release above.
See `VALIDATION.md` and `BOM-preview.md`. The background watcher remains paused.

## Historical A0 records (superseded by A1 where they conflict)

# tscircuit AI agent remote

Revision A0-reference-import-review (work in progress), updated 2026-10-03: **B-008 reference labels are corrected through official JLC imports; B-003 ground ports remain verified. Independent circuit reviews exist; no complete handheld schematic or PCB exists.** Missing polygon solder paste remains a real assembly blocker. Requirements, component choices, electrical qualification and full placement remain unfinished; no routing or fabrication approval.

Private repository: https://github.com/AnasSarkiz/tscircuit-ai-agent-remote

Private tscircuit package: https://tscircuit.com/AnasSarkiz/tscircuit-ai-agent-remote
— last fully verified private source release is **0.0.2-wip-a0-core-alignment**
(274 files; Git 8bbde6e). Latest source commit **0573bf4492817ea0263827b6f0431fb7905d4959** reached GitHub; native private release
**0.0.2-wip-a0-hold-readback-review** exited1 with1081reported successes/20failures. Exact readback proves13reported failed files arrived byte-identically, while seven are404: six persistentHTTP413 files plus timeout C105188/TLV3201AIDBVR.tsx. No failed-file cases remain mismatched or unverified. Package private=true/ready_to_build=false (B-009). Exact receipt in `evidence/hold-readback-publication-2026-10-03/`; local outcome/watch notes were created after enumeration and are excluded from that release. This is disclosed work-in-progress prototype source;
no complete-board build or fabrication approval is claimed.

The accepted device is the square, screen-dominant concept with one top-edge hold-to-talk button, a speaker and rechargeable battery. Hold, speak and release to send a Wi-Fi request; show and speak the response. All PCB electronics must assemble on the top side. The encoder and separate APPROVE/REJECT controls are removed from the active design. See `REQUIREMENTS.md` for the complete requirement changes and remaining interface decisions. Firmware implementation is outside this task.

The user approved a maximum PCB envelope of **50 x 65 mm**. A **50 x 50 mm square target** starts the mechanical study within that envelope; it is not yet validated. Four copper layers are intended. Accepted visual reference: [square product concept](assets/product-concepts/ai-remote-v1-infographic-v3.png); rendered placement is illustrative.

## Rechargeable battery

One protected **1S, nominal 3.7 V, 4.2 V-charge LiPo pack**, targeting **500–1000 mAh**, USB-C charging and operation while plugged in. BQ24074RGTR / C54313 and TPS63802DLAR / C2845237 remain the charger/power-path and 3.3 V regulator candidates. A top-side SMT battery connector, JST S2B-PH-SM4-TB(LF)(SN) / **C295747**, is now imported verbatim through the supported workflow. Exact pack, harness polarity, thermistor, charge current, protection, runtime and mechanical fit still need qualification. This is requirement/BOM preparation, not an integrated battery circuit.

## Published update check

Installed and pinned **tscircuit 0.0.2736 / CLI 0.1.2232** on 2026-10-03. Fresh C5656610 import still contains the **0.3999992 mm** acoustic opening; TDK recommends at least **0.50 mm**. **B-002 is not fixed in the tested published release.** This is historical recheck evidence; the subsequently authorized local correction is described below. Version metadata, import logs, checksums and diagnostic evidence are saved under `evidence/update-check-2026-10-03/`. Dependent placement/routing remain stopped.

## User-authorized microphone correction

C5656610 / ICS-43434 now uses a **0.60 mm** acoustic hole at the original center.
Every non-diameter byte in the imported file is unchanged. Raw supplier evidence
confirms that the original 0.3999992 mm hole comes from the LCSC-owned footprint;
the converter preserves it correctly. No supplier-library or converter change
was made.

Generated geometry confirms **0.60 mm**, nine unchanged copper pad shapes and
minimum hole-edge-to-copper clearance **0.2580203 mm**. The isolated placement
check passed with zero errors/warnings. Evidence and the original source are
saved in `evidence/microphone-local-correction-2026-10-03/`.

**B-003 is resolved:** official core 0.0.2058 now generates linked ground-pad
ports and passes the native component build/checks after supported dependency
alignment. **BLOCKING B-005:** native generation omits solder paste for the four
polygon ground pads. Diagnostic Gerber export confirms those openings are absent
from F_Paste. This assembly defect was reported to the authorized issue chat;
imported pad/paste geometry has not been patched. See the evidence below.

## Historical corrected encoder import

**ALPS EC11E15244G1 / LCSC C370970:** the user explicitly authorized correcting this imported component's symbol and footprint. Its five terminal holes are now **1.05 mm**, and its two mounting slots are **2.65 mm long**, within ALPS's 1.00–1.10 mm and 2.60–2.70 mm ranges. **B-001 is resolved locally for the reported dimensions.** The external supplier library has not been changed.

C370970 uses its existing native `<chip>` as a schematic box. Pin labels, centers, slot widths/orientation, outer pads, silkscreen, courtyard and models are unchanged. This encoder is no longer part of the accepted one-button design; its correction and evidence are retained historically. The microphone now also has a diameter-only authorized correction. Other imports remain unmodified. Isolated review artifacts are not the handheld board or fabrication package. No handheld placement, routes or fabrication outputs exist.

## Commands

Run inside this directory. `bun install` installs pinned dependencies. `bun run format:check` and `bun run typecheck` check project tooling. `bun test` currently reports **26 pass / 1 fail**: the native Circuit JSON schema regression reproduces B-010. Manufacturer connection and existing import tests pass; historical encoder checks remain evidence, not active BOM approval. `bun run build` reports that the complete board has not been authored. The original proposal is preserved in `evidence/proposals/C5656610-acoustic-hole.diff`. The latest user instruction authorized applying it locally. The microphone component build now passes; B-005 paste generation blocks assembly qualification. Whole-board design remains incomplete.

## Evidence and remaining work

See `VALIDATION.md`, `BOM.md`, `issues.md`, `references/sources.md` and `routes/README.md`. Continue in this task directory. No earlier board source or validation evidence was reused.

Latest haptic review: `HAPTICS.md` and `evidence/haptic-review-2026-10-03/`.
C2942347 motor courtyard defect and model qualification block its integration.
The independent10-part regulator/flyback fixture passes five native checks,
with reference/metadata warnings and12 strict schema failures disclosed.
Type-C publication for Git6700842 is still unready:689successful/33failed upload
reports,28reported timeout files byte-verified and five actual missing404.
The high-current detector's partial-supply startup behavior remains unqualified;
fixed USB100 is under review. Battery sourcing permission is still pending.

Import provenance: **JLCEDA/EasyEDA Official Library**, accessed through the supported JLCPCB importer. [JLCEDA](https://lceda.cn/) / [EasyEDA](https://easyeda.com/).

## A0 regulator review and current fix status

Current pins: tscircuit **0.0.2742**, CLI **0.1.2235**, core **0.0.2070**, props **0.0.682**, circuit-json **0.0.513**, easyeda **0.0.370**. Earlier version checks below are historical.
Core PR [4323](https://github.com/tscircuit/core/pull/4323) merged and is present
in the published release. Native CLI uses the locally imported tscircuit renderer;
a supported Bun override and clean installation aligned its nested dependency.
The earlier failed-release attempt is preserved in `evidence/core-fix-2026-10-03/`;
the verified resolution is in `evidence/core-alignment-2026-10-03/`.

Seven exact JLCPCB power parts were imported without edits. The draft A4
regulator application source is `src/power/regulated-3v3.tsx`; its isolated
review fixture and reviewed PNG/SVG/JSON are in `evidence/power-review-2026-10-03/`.
The fixture passes the five native placement-stage commands with no reported
errors or warnings and contains seven top-side components, zero PCB traces and
zero vias. This does not qualify the full board or the final power-loop layout.
`POWER.md` records battery, USB, thermal and effective-capacitance decisions
that remain open. Routing stays disabled until whole-board prerequisite gates pass.

Catalogue searches also returned unrelated components for an exact capacitor
MPN and a display query. This was reported to the authorized issue chat; verified
exact-part imports continued. Search evidence is saved under
`evidence/component-search-2026-10-03/`.

## Verified B-003 resolution — A0-core-alignment

The earlier CLI-bundle diagnosis was incomplete. Native build imports the local
tscircuit RootCircuit, which loaded its nested core 0.0.2056. The supported
Bun `overrides` entry now pins all core dependencies to official **0.0.2058**.
A clean `bun install --force` removed the stale nested copy; plain `bun install`
alone had left it installed. No package source or imported component was patched.

The actual microphone build and all five native checks now exit 0. Generated
geometry has nine source ports and nine PCB ports, all four ground pad shapes
linked, and an internal connection joining those four contacts. No ambiguous
port errors remain. Evidence is in `evidence/core-alignment-2026-10-03/`.
The regulator and project checks were repeated successfully after alignment.
B-003 is resolved for native component generation; final microphone application,
paste/mask, placement, routing and full-board qualification remain pending.
The complete-board entry continues to report unfinished design explicitly.

## B-005 microphone stencil blocker

C5656610 produces nine copper pad shapes but only five rectangular solder-paste
records. Its four polygon GND shapes have no paste record. Native diagnostic
Gerber export succeeds but F_Paste contains only those five rectangular flashes
and no ground-pad regions. This is an unrouted component diagnostic, not a
handheld fabrication package. Evidence: `evidence/core-alignment-2026-10-03/`
(`microphone-stencil-defect.json`, diagnostic ZIP and `F_Paste.gbr`).
Manufacturer stencil geometry review and the upstream generator/export fix remain
required. The issue was sent to the authorized issue chat; independent design
work continues. No full-board stage, fabrication readiness or physical test is
claimed by the isolated checks.

## Current controls review — 2026-10-03

The regulator now uses TI's 511 kΩ / 91 kΩ divider. A separate unrouted A4
microphone power/clock/comparator application was built and checked, with
preserved warnings. It excludes the blocked microphone and hold switch.
B-006 blocks C79174 contact/locating-hole qualification; B-008 blocks C105188's
missing schematic reference label; B-007 records C2149796's missing supply
metadata. All were sent to the authorized issue chat. Read `AUDIO.md`, `POWER.md`
and the current VALIDATION.md milestone. Requirements, full schematic, component
qualification and mechanics remain incomplete. No handheld routing/fabrication
or hardware-test pass is claimed. Standing authorization covers publication of
this WIP milestone to both configured remotes.

## Current independent engineering

Native MCU/USB A4 review and lower-bias regulator build/five checks pass as
unrouted diagnostics. Current schemas still reject generated group fields and
PCB display offsets (B-010); USB polygon paste (B-005) and ESD/comparator
reference text (B-008) remain blocked. Both switch candidates lose permanent
contact groups (B-006). Cases are reported to the authorized fix chat; no
imported definitions or native runtime were patched. Routing is disabled.

Display supply/level translation/backlight/FPC and protected-pack qualification
continue. A battery-sourcing exception question is pending, because the studied
NTC protected pack's PCM only supports 1 A continuously. No elapsed-time
approval is inferred. Publication remains incomplete until supported native
upload acknowledgement succeeds; the heartbeat stays active.

## Display logic review and tested core proposal — 2026-10-03

`DISPLAY.md` records the partial 2.8 V LCD interface: 19 exact imported top-side
parts, native A4, 45×32 mm diagnostic placement, routing disabled. Build and
all five checks exit 0; current PCB/A4 renders inspected; native snapshots match.
Manufacturer physical pin tests pass; board tests total 12 pass, 1 fail (B-010),
75 assertions. TypeScript/formatting pass. Backlight, full power sequencing,
unknown LCD supply current, cable, enclosure and actual handheld fit are pending.

A genuine B-010 source correction was tested in a separate upstream checkout:
new strict-schema regression passes205 assertions; related tests29 pass/0 fail/
1 existing skip, core TypeScript and ESM/declaration build pass. Proposal and
reviewed native snapshots are in `evidence/core-b010-proposal-2026-10-03/`, sent
to the authorized fix chat. No installed board runtime was patched or upstream
release published. B-010 remains open until an official fix is verified natively.
C11050 land comparison is a tolerance/revision qualification question, not a
proven supplier defect (B-011). No footprint patch was applied.

The independent Type-C hardware current detector is reviewed in `TYPE-C.md`;
native A4/PCB output and required checks are preserved in
`evidence/type-c-current-review-2026-10-03/`. It keeps the proposed charger in
default USB100 until higher current is advertised and controller power is stable.
The charger, protected pack, temperature circuit and system-load gating are still
unfinished. This does not enable routing or qualify a complete board.

The regulated microphone clock candidate and nominal mechanical study are in
`evidence/microphone-open-drain-review-2026-10-03/qualification.md` and
`evidence/mechanical-envelope-review-2026-10-03/findings.md`. The independent
15-part A4 fixture is unrouted; required diagnostic checks pass, while strict
native JSON still fails 17 elements (B-010). Clock loading, privacy timing and
complete mechanical fit remain unqualified. Parent Git a1e76d5 reached GitHub;
private version 0.0.2-wip-a0-haptic-driver-review remains incomplete: 771 reported
successes, 13 failures; seven timeout files byte-verified and six actual missing
HTTP413 files. Package remains private=true, ready_to_build=false. The new
milestone's publication is pending.

Battery readiness is under review in `src/power/battery-ready-review.tsx`; its isolated A4/PCB fixture passes native diagnostic checks but remains electrically unqualified for arbitrary startup/reconnect, absent pack and final battery protection/temperature policy. Canonical tests currently have 22 passes and one known strict-schema failure. This is an unrouted engineering prototype; no full-board fabrication package exists.

Latest independent studies: genuine two-contact hold candidate, current JLCPCB fabrication/USB impedance rules, measured nominal native pad clearances, saved-route APIs and native BOM export metadata. They do not complete the board. New B-015 is independently confirmed: native BOM Comment loses MPN/resolver data. The exact rechargeable pack and full circuit/placement/routing remain unfinished; no fabrication package or actual saved copper routes exists. See VALIDATION.md and the dated evidence folders.

The latest independent hardware-hold readback uses a genuine Schmitt buffer to separate the MCU read pin from the microphone-enable signal. A verified genuine higher-stock resistor replaces the low-stock part only in that candidate. Native A4/build/diagnostics/snapshots pass; full JSON still fails B-010, and the canonical suite has23passes/one known failure. The top-control mechanical study also finds a17.95mm nominal switch/antenna gap by moving the module left on the50x65trial; actual enclosure, actuation, raised LCD, battery and speaker remain unfinished. This is an unrouted, untested engineering prototype. Parent Git fa90b54 is on GitHub; its private0.0.2-wip-a0-fabrication-review upload remains incomplete with six HTTP413 files verified absent,22timeout files verified present and ready_to_build=false. See the hold-readback and top-control dated evidence.

Latest review: `evidence/blocker-recheck-2026-10-03-1357/`. Four genuine imports now carry correct native reference labels through official released tooling. All four native builds and20 diagnostics pass; current suite26pass/one existing B-010fail, formatting/types pass. Missing microphone polygon paste remains an assembly blocker. Three additional speakers have no importable libraries; genuine alternate haptic C41348533 imports but still lacks polygon paste and remains mechanically/electrically unqualified. Publication/BOM-description failures do not stop independent circuit work. Complete-board routing remains gated by actual requirements, component, connectivity and placement qualification.

### Canonical generator qualification revision

The 0.0.11 WIP revision pins audited project builds of core 0.0.2090 and Circuit
JSON 0.0.521, with canonical metadata and pill-paste fixes retained in
`toolchain/`. It uses released CLI 0.1.2270 and Gerber library 0.0.112-board-fixes.1. U14 uses
the untouched genuine C7848 exact import, including its downloaded models.
These are qualified engineering changes, not fabrication approval. The final
2.8-inch display/FPC/RF integration, battery outer-contact polarity, remaining
connections, stock and complete fabrication checks still have to pass.

The regulator's existing top-layer switch paths have 0.275 mm local pad escapes
followed by 0.4/0.7 mm widening and 1 mm trunks. Their separate source contract
requires those trunks and limits the narrow escapes to 0.751 mm. The current
bound uses TI's 5.75 A peak limit and requires 35 µm finished outer copper; it
is not a change to board-wide minimum widths or complete thermal qualification.

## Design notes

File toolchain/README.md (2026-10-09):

# Qualified canonical runtime fixes

The board pins the three package artifacts in `packages/`. These are local builds
of the exact public upstream commits in `provenance.json`, with canonical source
fixes and regression tests retained under each package's `source/` directory.
They are project packages, not claimed upstream releases. No installed bundle
was edited, no yalc link is published, and no generated board JSON was repaired.

Core emits string position offsets with millimetre units, omits unset optional
group/hole ownership metadata, and creates pill paste from emitted pad geometry.
Circuit JSON supports board-level silkscreen without inventing a purchased
component owner; malformed ownership, text and layer data remain rejected.

Canonical tests and package builds use Bun 1.4.0, matching upstream core CI.
The board uses Bun 1.3.9 and its frozen lockfile. The real CLI coupon confirms the
installed packages are used in generated native output. Package SHA-256 values
are recorded in `provenance.json`; publication staging copies these exact bytes.

Build and native qualification receipts are in
`evidence/pcb-completion-2026-10-08/`. Successful toolchain tests are not a claim
of complete routing or fabrication readiness.

The current schema build is based on upstream 0.0.521 to satisfy the released
CLI's 0.0.520 or newer schema interface. Core remains based on 0.0.2090 so saved
routing semantics do not change. Group offset regressions cover explicit zero
coordinates, which revealed the two residual mounting-group errors. Reviewed
anchor snapshot changes affect numeric text formatting (for example `1.50mm`
to `1.5mm`); component and group copper positions are unchanged.

The Gerber library fixes G85 slot commands at their canonical source: both
endpoints appear in one Excellon block at four-decimal precision. All 35 scalar
Excellon regressions pass, and the complete library builds with TypeScript
declarations. The upstream visual suite remains unverified because its
optional development dependencies could not be fetched (HTTP 503). Fresh actual
exports are independently parsed using PyGerber 2.4.3 and PCB-tools 0.1.6, with
strict Gerber parser errors enabled. This artifact builds the public library;
it does not replace or claim qualification of the standalone upstream CLI.

Retained source files are patches for three separate upstream projects, not
complete projects inside this board. Board TypeScript excludes the toolchain patch/build archive; each canonical package was type-built in its complete original
checkout. Board source and imported package declarations remain type-checked.

Core also enforces routing-disable controls during subcircuit updates. The
regression reproduced routing despite disabled platform and board flags; both
now remain unrouted while the enabled control still creates actual copper.
Ten focused core regressions and the complete typed package build pass.

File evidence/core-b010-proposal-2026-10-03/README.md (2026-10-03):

# Tested source proposal for B-010

Base: core main 18e1d11a6eaebaece6f6fb75fdfd2c680a468890, version 0.0.2061.
`core-b010.patch` contains the actual source correction, regression and reviewed
snapshot changes. The isolated checkout is excluded from board publication and
board tooling. No installed board runtime or imported component was patched.
No upstream push, PR, release or merge has been performed.

Native upstream dependency installation failed with Bun 1.3.9; the repository's
CI Bun 1.4.0 installed all 619 declared packages successfully. Same source,
same declared packages, no tarball/cache injection or dependency substitution.
Package manifest and exact validation dependency versions are preserved.

Unchanged upstream fails the new regression on numeric pcb_component offsets.
The correction emits millimeter strings for component and group offsets, omits
absent anchor_alignment and normalizes absent schematic subcircuit_id to
undefined. Group initial placement and anchor-alignment update paths both needed
the same correction. No physical layout algorithms or geometry were modified.

New regression passes (205 assertions); related group, anchor and edge/calc
suite: 29 pass, 0 fail, 1 existing skip, 332 assertions across 27 files.
TypeScript exits 0; package ESM and declaration build exits 0. Canonical formatter
ran on touched source. Full upstream suite has not been run.

All five changed existing PCB snapshots were viewed. Geometry and arrows remain
unchanged; labels change from fixed numeric formatting to schema-valid mm string
labels (e.g. X: 2mm). New PCB and A4 schematic snapshots were viewed. The fixture
uses upstream's existing untouched microphone import, not a new board component.
The current mixed-calc coordinate behavior is preserved; assertions use actual
imported pin-1 pad geometry rather than assuming a symmetric footprint center.

The board's pinned core remains 0.0.2058 and its strict schema regression still
fails B-010. This proposal is useful evidence for the authorized fix chat, not a
verified published fix or permission to resume blocked full-board validation.

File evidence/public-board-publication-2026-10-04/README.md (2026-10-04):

# Public board publication — 2026-10-04

User authorization: make the existing board GitHub repository and tscircuit package
public, and push the built Circuit JSON. No routing or fabrication approval requested.

The official package update API accepts is_private/is_unlisted/public_dist_enabled;
the inspected upstream endpoint source is preserved. Only this board package was
updated to false/false/true. GitHub repository visibility changed through gh repo edit.
Anonymous GitHub metadata confirms private=false. No credentials were printed or stored.

The native root build completed with routing disabled and network available.
The restricted-network first build added 122 source_part_not_found_warning elements;
that build was rejected for publication and replaced with the successful network build.
4808 elements; zero traces/vias/errors. Every element except source_project_metadata
matches the previously visually inspected connector revision. Its schematic/PCB/GLB
reviews remain applicable because geometry/connectivity are unchanged. Three connector
orientation warnings and previous component metadata warnings remain visible.

Format and root/staged TypeScript checks pass. Canonical tests: 30 pass/one existing
B-010 schema failure/272 assertions. Native five checks are recorded separately.
B-005 microphone polygon paste, B-010 native schema, B-015 assembly BOM fields and
all remaining electrical/mechanical/routing/fabrication gates are unchanged.

.gitignore permits dist/index/circuit.json only. The preparer requires a native root
build and copies that artifact byte-for-byte into the board-only package. The staged
source closure is identical to the validated root runtime source, and staged types pass.
The package retains 75 files, no documents/scripts/evidence/tests/unused components.
package.json private=true is the npm accidental-publication guard; registry visibility
is controlled by its official API and is public. No npm publication is requested.

Both destinations are now **public** and anonymously accessible. Published source
commit **6f8f4a270e76c7455084a1d43ea92833694179f2** and registry release
**0.0.2-wip-a1-public-board**. Native upload exited0, 75 successes/zero failures;
anonymous exact-version readback verifies all 75 hashes with no missing, extra or
unverified files. Public GitHub and registry `dist/index/circuit.json` are identical
(2,298,951 bytes; SHA-256 `0be465e43d862abd74d8fa7b8f397738fcae90f8134c330cf2311bdf54d273ca`).
Registry `is_private=false`, `is_unlisted=false`, `public_dist_enabled=true`.
`ready_to_build=true` and null reported build errors do not establish a completed
cloud build or fabrication readiness. Receipt-only follow-up changes no runtime
input and needs no additional registry release.

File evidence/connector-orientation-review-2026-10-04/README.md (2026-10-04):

# A1 connector orientation review — 2026-10-04

Board source parent: `3d6649aea36a1beac5901591659110dae014415f`.
The user's request is to verify real connector openings using the 3D models and
turn them toward board edges where appropriate. This review does not authorize
routing or establish final enclosure/cable fit.

## Reviewed result

| Connector | Genuine part | Board opening after review | Change |
| --- | --- | --- | --- |
| J1 USB-C | TYPE-C-31-M-12 / C165948 | Bottom, −Y | Existing orientation retained |
| J3 protected pack/NTC | S3B-PH-SM4-TB(LF)(SN) / C265101 | Right, +X in supplied CAD | Existing −90° placement retained |
| J4 speaker | S2B-PH-SM4-TB(LF)(SN) / C295747 | Left, −X in supplied CAD | +90° → −90° |
| J6 internal service | SM06B-SRSS-TB(LF)(SN) / C160405 | Right, +X | Existing +90° placement retained |
| J7 display FPC | AFC07-S10FCC-00 / C11050 | Internal, toward +Y | Retained for raised display; final panel/flex unselected |
| J8 haptic motor | S2B-PH-SM4-TB(LF)(SN) / C295747 | Right, +X in supplied CAD | −90° → +90° |

Before/after views show J4/J8's rear solder tails facing the edge originally;
after rotation their mating cavities face the edge and the tails face inward.
Only two board placement rotations changed. Imported definitions, pin identities,
model transforms, supplier data and all source wiring are unchanged.

JST describes these S-series PH and SH headers as side-entry types:
https://www.jst-mfg.com/product/pdf/eng/ePH.pdf and the saved
`references/jst-sh.pdf`. Supplier 3D models are supporting placement evidence,
not a replacement for final mating-housing drawings and real assembly checks.

The battery, speaker and motor are internal enclosure assemblies. Their plugs
need space outside the PCB perimeter inside the enclosure; they do not require
external openings in the case. J6 also needs its service harness inserted with
the case open. Exact plug bodies, harness bend radii, enclosure wall gaps and
display removal/service access remain unqualified. J7's latch faces the proposed
raised display; flex insertion, bend and latch clearance require the exact final
panel, contact orientation and vertical stack. It is not declared fit-qualified.

## Checks and evidence

Native complete-board build with routing disabled, PCB/SVG outputs and GLB
completed with exit0 before and after. `before/board.glb` and `after/board.glb`
are actual native outputs. `render-connectors.ts` renders those saved GLBs from
whole-board and individual connector viewpoints; all final views were inspected.
`after/pcb-top.png` was inspected; the ratsnest and all 13 schematic sheet views
were regenerated. Schematic elements and electrical source connectivity are
identical to the fresh before build; only source filesystem hash metadata differs.
`comparison.json` records full geometry differences and native warning contents.

All five native pre-routing checks exit0. Placement: **zero errors, three
warnings**, on J3/J7/J4. Core infers cable direction through
`guessCableInsertCenter`, and passes it to the orientation check without writing
that temporary center into the saved component. J3/J4 inference disagrees with
the visible supplied CAD cavities; J7 is intentionally internal. These warnings
are preserved, not suppressed or fixed by changing imported metadata. The CAD /
inference discrepancy and real cable clearance remain fabrication review items.

Format and TypeScript pass. Canonical tests retain **30 passes / one existing
B-010 strict-schema failure**, 272 assertions; historical fixture tests do not
validate the new placement. Native snapshots initially differed as expected;
after inspection only the PCB snapshot was updated, schematic snapshot unchanged.
Zero traces/vias, 130 top-side physical components and zero native errors remain.

The stale first package build was stopped before publishing after detecting its
old staging input. Staging was recreated and the corrected package rebuilt.
Only the reviewed fresh package build may be published. Publication excludes
this evidence directory and all documents/scripts, retaining required board
sources, genuine model assets, manifests and generated `dist/index/circuit.json`.

Still an unrouted prototype. B-005 paste, B-010 schema, B-015 fabrication BOM,
electrical qualification, exact screen/pack/load selection, mechanical fit,
routing, copper DRC and fabrication review remain open. The watcher stays paused.

## Verified publication

Implementation `0191b8e5db4c8c29dc7d75bcd43455cb1747200e` reached GitHub main.
The normal native file-by-file publisher exited0, 75 successes/zero failures,
creating private `0.0.2-wip-a1-connectors-outward`. Final exact readback verifies
all 75 hashes, no missing/extra/mismatched/unverified files. One initial URLError
on ControlsSheet.tsx was resolved by a targeted read-only retry; the original
receipt and retry are retained. All stage inputs stayed frozen and matched the
manifest after completion. The package includes native `dist/index/circuit.json`
and excludes documents, evidence/scripts/tests and unused assets. Registry
ready_to_build is true, errors null; completed cloud build is not established.

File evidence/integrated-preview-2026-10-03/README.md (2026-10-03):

# A1 complete native board — unrouted preview

Actual integrated `main.tsx`, based on parent `98a3f7e`. The board is 50 × 65 mm,
with four layers, 1.6 mm thickness and 3 mm corner radius. It has 122 genuine
imported electronic parts and 8 copper test pads, all on top, across 13 A4 sheets.
There are zero copper traces or vias and zero native PCB geometry errors.
This is an untested prototype, not approved for fabrication.

`board-overview.png` combines the final native PCB top, actual ratsnest and actual
GLB top/bottom renders. Individual PNGs, SVGs, `board.glb`, `circuit.json` and the
native 13-page `schematic.pdf` are retained. Render helpers use public converter
APIs and the native GLB without modifying emitted Circuit JSON. Blue rectangles
on the PCB show a provisional raised LCD body and active area. The 3D views show
the PCB assembly; enclosure, display and battery fit remain unqualified.

`command-results.json` records actual results: build, all five pre-route checks,
formatting, TypeScript and snapshots exited 0. Canonical tests have 30 passes and
one existing strict-schema failure. Full-board strict schema validation rejects
156 native elements: 130 PCB components, 13 PCB groups and 13 schematic groups.
Known B-010 union/anchor/display-offset failures are preserved in compact summaries;
raw outputs have not been rewritten.

Placement reports no errors or suboptimal orientations and two connector-facing
warnings for J6 (internal service) and J7 (internal display FPC). Imported role and
category warnings remain metadata gaps. Connector access, lands, paste, silk,
current, rails, transients, privacy, RF, thermal limits and mechanical fit need
qualification. TMR and ITERM intentionally use the manufacturer's open-pin defaults.

The battery connector assumes pin 1 BAT, pin 2 GND and pin 3 NTC. The protected
pack, 8 Ω speaker, 3 V motor, LCD/backlight and TALK actuator remain provisional.
Side-switch pin mapping, inrush and transitions need qualification. B-005 missing
polygon microphone ground paste remains a fabrication blocker.

Native snapshots and all 13 schematic pages were visually reviewed. Display and
microphone-clock sheet coordinates were moved inward after inspection. These
checks do not establish full electrical qualification. The bottom is unpopulated.

The overlapping initial 50 × 55 mm trial is retained under `initial-50x55/` and
in `initial-pcb.png`; it is historical evidence, not the final design.
`source-manifest.json` hashes final source, dependencies, imports and deliverables.
Earlier publication receipts and speaker observations accompany this actual
implementation milestone. Registry publication is tracked separately from build
success. The background watcher remains paused.

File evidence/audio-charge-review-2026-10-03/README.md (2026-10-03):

# A0 amplifier application and charging intake — 2026-10-03

Independent, unrouted diagnostic work. The complete board is still unfinished;
no copper, route cache, fabrication package or hardware tests exist.

The native 46 × 32 mm amplifier fixture has 17 top-side components, 53 rectangular
pads and 53 native paste shapes. Build and all five required connectivity / placement
checks exit 0; command results are preserved. C51 was rotated 180 degrees to
resolve a native placement advisory. Connector faces the right edge. Native A4
schematic and PCB renders were inspected. The missing Q1/Q2 schematic references
remain actionable B-008; snapshot acceptance and component qualification are
withheld. Imported components/models remain byte-for-byte native imports.

The full generated JSON fails the published schema in 19 elements (B-010),
including numeric component display offsets and null group fields. The existing
board regression remains failing; new manufacturer connection tests pass.
Board total: 14 pass, 1 fail, 107 assertions. Formatting and TypeScript pass.
No global board stage is passed by these diagnostic results.

C265101 / JST S3B-PH-SM4-TB(LF)(SN), C132554 / TI TUSB320LAIRWBR,
C2862740 / TI TPS7A2033PDBVR and C6617702 / Panasonic EVQ-P4HB3B imported
successfully as candidates. Manufacturer land, orientation, current/startup,
mechanics and actual application qualification remain unfinished. C20917 /
AO3400A and C15127 / AO3401A successfully imported but reproduce B-008.

B-012: native imports C3311258 / PUI Audio AS04008PS-4W-R, C6230316 /
Taoglas SPKM.20.8.A and C50387211 / XHXDZ 23MM-8Ω2W-JFHM fail because
no EasyEDA library records exist. The first two were independently confirmed
by the fix chat. No substitute electronic definition was authored. Speaker
selection/procurement and series inductance remain unqualified. PUI drawing
page 3 inspected: 40±0.2 × 28.3±0.2 mm body, 12±0.5 mm depth, four Ø3.1
mounting holes. It is not the earlier assumed 40 × 20 mm package.

B-004: exact MPN discovery queries for RC0603FR-07470KL and
RC0603FR-07430KL imported unrelated C16195750 (inductor) and C326810
(510 kΩ 2010 resistor). These are rejected, unwired research imports. Exact
supplier IDs must be used; query-result identity never substitutes qualification.

Git c82e7deb display review is verified on private main. Native private version
0.0.2-wip-a0-display-logic-review exited 1: 582 successes and 4 failures.
Both timed-out STEP files reached the server byte-for-byte; the HTTP413 model
and PDF return404. ready_to_build=false. Exact readback receipt and native log
are saved here. No publication success, forced-ready flag or file dropping.

All material findings were sent to the user-authorized fix chat. The protected
battery sourcing exception still awaits the human reply. No pack or thermistor
is bypassed or replaced with a fabricated definition.

Exact queries were resolved with supplier-verified C114622 / RC0603FR-07470KL
and C482869 / RC0603FR-07430KL; both imported successfully, remain unwired
charging candidates. C7666 / TI SN74LVC1G08DBVR also imported for startup
qualification logic. No wrong search result was used in the circuit.

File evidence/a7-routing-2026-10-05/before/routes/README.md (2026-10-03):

# Saved routes

No copper routes exist in revision A0. Requirements and component qualification have not passed.

The user requests persisted native routes and relocation of offending segments for DRC/shorts. This is recorded as a required future routing deliverable. Do not manufacture an empty cache or treat this directory as route evidence.

The pinned props support `pcbRouteCache: { pcbTraces, cacheKey }`. Before using it, verify the canonical cache-key generation and endpoint identity semantics in the pinned core/CLI, persist a valid routed result, rebuild from the saved routes, and run shorts plus geometric/connectivity checks. Change the saved source routes through the supported API; never patch a fabrication artifact to hide a violation. Revalidate the resulting copper and regenerate the entire fabrication package.

Source/API review2026-10-03 found the pinned supported per-phase autorouting:end.pcbTracePaths export and <autoroutingphase pcbTracePaths> replay API. Its canonical generator preserves unique connection selectors and wire/via geometry; unrepresentable junction/endpoints produce an unavailable reason rather than partial paths. Save original complete routing events and final JSON alongside versioned replay paths and source/dependency/placement/phase hashes, then verify replay before relocation. Every relevant phase must be retained; a stage's paths do not necessarily describe the complete board. Legacy pcbRouteCache key/multi-net replay remains unqualified. Detailed verified source locations and round-trip requirements: evidence/saved-route-api-review-2026-10-03/qualification.md. No copper, replay-tested routes or empty placeholder cache is created by this study.

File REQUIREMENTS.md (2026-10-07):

**0.0.9-wip-standard-uart — NOT READY TO ORDER.** J6 now uses the genuine
JLCPCB **C160389 / JST BM03B-SRSS-TB(LF)(SN)** three-contact upward SH header.
Its UART contacts are RX/GND/TX (pins 1/2/3); hold-downs 4/5 are GND.
Authored native routes replace the former six-contact connector's connections,
with a local audio-gate detour and ordinary 0.30/0.45 mm through-via escapes.
The standard JST programmer's TX/GND/RX cable maps directly to these contacts;
the custom three-to-six adapter is removed. Programming requires separate
USB/battery power, manual BOOT/RESET and an open enclosure: mated connector
height is 6.3 mm. Hardware operation and cable assembly are untested.

The 2026-10-07 20:07 UTC official JLCPCB page reports C160389
`overseasStockCount=32191` and `canPresaleNumber=31559`, at a reference
$0.2743 each. These are public inventory fields; they do not establish global
warehouse totals, assembler allocation or an order quote. Purchased count
remains 125 parts / 43 identities. All other component poses are retained.

The requested 2.8-inch LCD is still unimplemented. Exact panel/flex/antenna
fit, J7 mapping, battery outer-contact numbering, full connectivity, toolchain
schema/paste/Gerber issues and current-carrying qualification remain gates.
See the [actual native qualification and remaining blockers](https://github.com/AnasSarkiz/tscircuit-ai-agent-remote/blob/main/evidence/programmer-direct-uart-2026-10-07/review.md).
Publication is recorded separately after exact remote byte verification.
Older status and connector references below describe historical revisions.

---

## Current speaker checkpoint — 2026-10-07

**0.0.8-wip-speaker-routing remains an untested, incomplete WIP.** All 325 vias
are measured at 0.30 mm drill / 0.45 mm pad and span all four copper layers.
All 80 authored high-current trunks and 68 audited native high-current traces
use top/bottom layers. The official JLCPCB capability page supports the 0.15 mm
via pad-minus-hole diameter difference; final CAM and stackup are not approved.

The speaker pair retains 0.6 mm trunks, 0.2 mm minimum gap, 2 mm maximum skew
and 5 mm maximum uncoupled length. Actual lengths are 6.684748 mm and
5.126922 mm (1.557826 mm skew). Narrow 0.275 mm pad escapes still require
load/current/thermal qualification. Two regulator routes violate their explicit
1 mm source minima; 64 traces below named-net nominal widths remain review
items. No source-width, clearance or DRC threshold was reduced to claim a pass.

J3 outer polarity and J7 FPC face/pin-1/fold remain design-critical unknowns.
The standard JST programmer still needs the documented three-to-six adapter,
separate board power and manual BOOT/RESET. The adapter, enclosure/flex/battery
fit, signal integrity, assembly allocation and physical operation are untested.

[Measured current revision](evidence/routing-continuation-2026-10-07/review.md).
The earlier checkpoints below are historical.

---

## Historical connection repair checkpoint — 2026-10-06

**0.0.6-wip-connection-repairs remains an untested, incomplete WIP.** All high-current supply/speaker trunks require outer PCB layers. The new gain-mode inner VSYS branch is separately identified and still requires input-current qualification. The 0.30 mm hole / 0.45 mm full-span via requirement is measured on all 322 emitted vias. No minimum-width or DRC requirement is lowered to accept these repairs.

[Actual source/native review](https://github.com/AnasSarkiz/tscircuit-ai-agent-remote/blob/main/evidence/connection-repair-2026-10-06/review.md). Earlier revision requirements and BOM history follow.

---

## Current six-point review — 2026-10-06

**0.0.5-wip-style-vias-power — NOT READY TO ORDER.** This entry supersedes the older counts and status below.

J1 now uses the requested native USB-C schematic symbol while preserving its numbered contacts, supplier identity, physical footprint and models. CLI schematic-placement analysis reports zero issues. The actual UI analysis was invoked but its external analysis module failed to load; this is a blocked check, not a passing result.

The clarified high-current requirement is implemented: all 80 authored high-current trunks and 59 audited native high-current traces use top/bottom copper. Six low-current pull-up/control/probe branches have separate documented requirements. All 217 vias physically span all four layers, with exactly 0.30 mm holes and 0.45 mm pads; blind/buried vias are explicitly disabled. All 151 native supply/control and relocated signal regions meet their nominal widths.

The supported frozen-install CLI build completes in 247.03 seconds and exits 1 with **89 real open-port errors**. Native output contains 328 traces, 217 vias and 183 pours. The independent geometry audit measures zero shorts and zero clearance violations, preserves all 8,146 previously connected port pairs, and still finds **25 physically open nets**. All 125 purchased component footprints, poses and models are unchanged. TP1 moves to (-22.2, 12.3) mm inside the main ground island. The five source checks, copper-free placement build, TypeScript, formatting and 64 routing regressions pass. Board tests report 48 pass / 2 fail (fabrication and strict native schema).

Official exact-part JLCPCB pages cover all 43 identities / 125 placements: 42 identities report enough total stock for one board; **J6 C160405 reports zero stock**. Positive stock for U1, D2 and U16 does not qualify assembly allocation. No stock reservation or assembler rotation approval is claimed.

Remaining fabrication blockers include unresolved J3 numbered outer polarity and J7 FPC mating, incomplete connections, 169 strict native-schema failures, missing pill-pad paste, unsupported polygon Gerber shorts/export, two regulator switching routes with 0.275 mm necks below their explicit 1.0 mm source requirement, 55 nominal-net-width branches requiring load review, and supplier rotations/current/stackup/signal-integrity/mechanical qualification. The standard JST programmer needs the documented adapter; direct connector mating and hardware operation are untested.

The supported source snapshot comparison completes in 61.13 seconds and fails on PCB and schematic differences; committed references are retained. All 26 native A4 pages, four copper layers, mask/paste and critical zooms were inspected. Native component guides cover all 135 references with valid annotation schema. Final component inventory confirms 32 missing pill-pad paste records on U16/U27.

[Full review and actual receipts](evidence/six-point-board-review-2026-10-06/review.md). Publication is recorded independently; native preview availability does not establish passing cloud CI or fabrication approval. No order or physical test has been performed.

---

## A6 current checkpoint — 2026-10-04

**Engineering prototype — NOT FABRICATION READY.** This supersedes historical A5 counts below. Genuine in-stock replacements are implemented: seven C22548→C21190 (eight C21190 total), six C105588→C22775. Active125 purchased PCB parts /43identities plus10native pads. Published core0.0.2083 polygon paste fixes13 formerly missing pads;32 pill pads still lack paste. Current native copper20traces/2vias; five missing backlight traces resolved, unconnected-port errors413→402. Genuine saved phase replay and actual added-copper geometry verified; all prior11traces/2vias unchanged.

Required five native checks and copper-free placement CAD build pass. Format/types pass; tests42pass/2retained failures and full native strict schema169failures. Diagnostic PCB-image shorts passes, but **required Gerber-based shorts check fails “Unsupported shape polygon”**. Canonical routed build exits1 with402 retained unconnected-port errors. Final layout/assembly/fabrication gates remain blocked. Fresh4layer/paste/detail/13A4/3D prototype previews inspected.

Battery centreNTC confirmed; outer numbered polarity is still absent from the exact supplier drawing and stays unrouted. BuyDisplay panel has integrated ILI9341 and82.712% nominal physical coverage; actual FPC/contactface/pin1 mating and current bare-panel availability remain unqualified. JST board-thickness tolerance requires a mechanical/stackup revision; current conservative height becomes15.07 mm at a qualifying1mm PCB, above15mm. PCB stays50×65 mm; case max60×75×15 mm. No fabricated confirmation, generic imports or orders.

[Detailed A6 review](evidence/a6-bom-routing-2026-10-04/review.md) · [Active inventory](evidence/a6-bom-routing-2026-10-04/inventory.md) · [Mechanical primary sources](evidence/a6-bom-routing-2026-10-04/mechanical-search.md). Parentfaa491d22d1a55210833a8ea3086ae56dc450245. Intended public version0.0.2-wip-a6-bom-routing; verify publication receipts before claiming upload complete. Watcher stays paused; no cross-chat issue messages.

---

## A5 — motor solder pads and independent routing, 2026-10-04

J8 is removed at the user's request. The external vibration motor remains connected through native top-side 2 mm solder pads TP_MOTOR_P (VMOTOR/M+) at (22,−8) mm and TP_MOTOR_N (HAPTIC_N/M−) at (22,−11) mm. Pad copper edge gap is 1 mm; board edge gap is 2 mm. M− is the switched motor return, not a general GND pad. The motor harness requires soldering and enclosure strain relief. J6 remains: USB-C supports ESP32-S3 flashing/debugging, while J6 is optional backup UART/BOOT/EN access. Normal USB operation is intended, not physically tested. Five plug connectors remain: J1, J3, J4, J6 and J7. No imported component definitions were changed.

Native selected phases now retain 11 actual traces and 2 ordinary 0.30/0.70 mm through vias. The original four copper records are unchanged; all saved phases replay with identical trace/via records. REG_FB, REG_PG, HOLD_BUFFER_OUT, USB_CC1, USB_CC2 and CHARGER_ILIM have no remaining native connection errors on their selected terminals. Actual new wire minima: pad clearance0.20533 mm, other-net trace0.29987 mm, drill0.33834 mm. GND pour source clearance0.21 mm gives actual via antipad clearance0.20730 mm, resolving the measured0.19735 mm aperture gap. This is partial-signal geometry review, not whole-board current/impedance/fabrication approval.

Required five native checks and shorts exit0; placement-only build0 with no traces/vias/pours. Format/types0; tests42pass/2known failures (schema fixture and full fabrication gate); full strict native JSON has169 failing elements. Canonical build exits1 with413unconnected-port/5missing-trace errors retained. PCB, all four layers, MCU A4 sheet and controls A4 sheet were inspected. Snapshot changes reviewed as prototype previews only. Full placement, display/FPC, battery outer polarity, power/paste/BOM/stackup, case/harness and complete copper gates remain open. No fabrication outputs or physical tests approved.

Earlier charger routing attempts hit native iteration limits; an R1 relocation failed actual placement (R33/U16 conflicts) and was reverted to its prior valid location. Q9/C20917 routing exports cannot save the phase due to non-unique native port selector; raw events are preserved and that gate net remains unrouted. No reconstructed cache or runtime workaround was used. The screen has an integrated ILI9341 controller per the BuyDisplay datasheet; its FPC direction is still unqualified and display routing is deferred as instructed. J3 outer contacts stay open.

Evidence: [A5 review](evidence/a5-connector-simplification-2026-10-04/review.md), [exact replay](evidence/a5-connector-simplification-2026-10-04/routing-replay-receipt.json), [via measurements](evidence/a5-independent-routing-2026-10-04/native-final-via-audit.json). Parent source bff3a87c974d4684f3fb159b0958abbb8a10620e; intended public runtime version0.0.2-wip-a5-motor-pads. Publication outcome will be recorded separately. Watcher stays paused; cross-chat messaging stays disabled. **NOT FABRICATION READY.**

---

# Latest A4 — 82.7% physical display coverage trial

**WIP prototype; NOT FABRICATION READY.** This supersedes conflicting A3/A2 selections below. Provisional external BuyDisplay **ER-TFT026-1**, 46 × 64 mm portrait body, overlaps the unchanged 50 × 65 mm PCB by **82.712%** (81.737% with stated dimensional/position allocation). Overhang, flex and bezel are excluded. Bare-panel availability and the current drawing/FPC are still unconfirmed; this is not a qualified purchasable display selection.

Implemented genuine C157929/C173752 internal side-entry PH headers, TPS60230RGTR/C1848364 four-channel backlight with 10 kΩ nominal 62.4 mA total, moved placement/mounting trial, rotated battery envelope and **0.8 mm trial PCB**. The thin stackup and USB impedance need new qualification. Battery pin2=NTC; both outer contacts stay open. Four original native traces are preserved; most connections remain unrouted. Fresh canonical build retains 431 connection errors; 38 tests pass and two fabrication/schema gates fail. Placement and short checks pass without claiming full routing or fabrication approval.

[Full A4 engineering review](evidence/a4-display-coverage-2026-10-04/review.md) · [Interactive A4 native model and display envelope](http://127.0.0.1:4949/evidence/a4-display-coverage-2026-10-04/mechanical.html). Current PCB count:134 physical components,496PCB ports,76named nets. Watcher remains paused and cross-chat issue messages remain disabled. Publication receipts are recorded separately; intended public package version `0.0.2-wip-a4-display-coverage`.

---

# Latest A3 BuyDisplay and first-copper checkpoint — 2026-10-04

**Engineering prototype — NOT FABRICATION READY.** This supersedes conflicting A2/A1 selections below. The external screen is now **BuyDisplay/EastRising ER-TFT022-1, bare 2.2-inch 240×320 TFT, no touch**, purchased separately from the PCB. JLCPCB supplies the board electronics and the genuine **AFC07-S50ECA-00/C262650 top-contact50-pin connector**, not the screen. Its54.36×40.3 mm landscape glass spans the full50 mm PCB width. The raised-glass/flex/height tolerance study remains open inside the unchanged50×65 mm PCB and60×75×15 mm maximum enclosure.

Electrical source wiring uses panel n→J7(51−n) for the planned right-edge single fold, SPI II mode1110,2.8 V logic/level translation and three separate TPS60231 current sinks. The old HS20HS072RX,12-pin connector and resistor-fed backlight are superseded. Battery centre2 staysPACK_NTC and the outer contacts stay open.

Actual partial copper now exists: two short MCU USB traces and two compact regulator switch traces,0vias. Original native routes/events and supported replay are preserved before moves; the regulator island/cache were moved together−8 mm X. The other nets are not routed. Current whole board:134physical components(126purchased+8testpoints),502PCB ports,75named nets. Required remaining-connection errors are retained; no fabrication outputs are approved. Full technical review: [BuyDisplay integration and fit limits](evidence/a3-routing-2026-10-04/buydisplay/review.md). [Live mechanical study](http://127.0.0.1:4949/evidence/a3-routing-2026-10-04/mechanical.html).

Native placement overlap/keepout errors are zero. Source, netlist and pin-specification checks have no errors; supplier metadata warnings and connector-access warnings remain disclosed. Four orientation suggestions were applied. The source-level schematic pin-map and imported connector orientation tests are distinct from physical panel operation. Full routing/schema/fabrication tests retain their failures; publication never means fabrication approval.

Source parent0300c2eed5d591b24dba9d2bdd59e17de0f94bf7. Intended public release0.0.2-wip-a3-buydisplay-first-copper; verify receipts before claiming it published. Background watcher remains paused. The user revoked cross-thread issue messages; no issues are sent to another chat.

# Latest A2 checkpoint — 2026-10-04

**NOT FABRICATION READY.** This section supersedes conflicting historical A0/A1 selections and status below. A2 updates the genuine C11051 twelve-pin display connector, manufacturer display wiring, centre battery NTC, two native M2 mounting trials and provisional placement. Battery outer numbering remains pending; both outer contacts are unconnected/unrouted. Display/flex/enclosure/RF fit is still open; routing remains disabled. Full report: [A2 fabrication checkpoint](evidence/routing-intake-2026-10-04/fabrication-report.md).

Display HS20HS072RX/C5329582, bottom-contact twelve-pin AFC07-S12FCC-00/C11051; protected AKY2945/LP5234501000mAh3.7/4.2V, max pack35×52.5×5.7mm, PH3, 10kNTC. Approved PCBmax50×65mm; current50×65. Red/black outer contacts **PENDING PIN-NUMBER CONFIRMATION**; centre yellow NTC. No final mechanical or current acceptance implied.

# AI Remote — accepted product direction

Updated 2026-10-03 from the user's direct follow-up instructions. These requirements
supersede conflicting controls and enclosure styling in `references/user-brief.txt`.
The original brief is preserved as historical input.

## Form and interaction

- Compact square enclosure with rounded corners and a display dominating the front.
- Primary top-edge hold-to-talk button plus a side-edge physical microphone privacy switch (latest user instruction).
- Hold → speak → release → send over Wi-Fi → show and speak the AI response.
- No exterior encoder, APPROVE/REJECT buttons or separate power button. BOOT/RESET stay inside the enclosure.
- Status indication belongs on the screen; no separate front status LED is required.
- Top-side PCB assembly only: all populated electronic parts and connector solder
  joints must be assembled from the top. Four copper layers remain intended.
- Enclosure-mounted speaker and rechargeable battery connect to the top-side PCB;
  they are separate mechanical parts, not bottom-side PCB population.
- USB-C access at the bottom edge. Speaker grille and microphone acoustics must
  follow the real parts and acoustic paths, rather than the illustration alone.

Accepted visual reference: `assets/product-concepts/ai-remote-v1-infographic-v3.png`.
This is a concept illustration, not dimensioned CAD or a validated placement.

Latest preview milestone starts at **50 × 55 mm**, within the approved **50 × 65 mm** maximum. The actual A1 preview expanded to 50 × 65 mm to resolve first-trial overlaps. Enclosure square styling and final fit remain provisional. Final enclosure dimensions,
display active area/glass, mounting, speaker depth, battery thickness and antenna
clearances remain unresolved. A 1.54–1.9 inch display from the original brief must
be checked against the desired front coverage; the concept does not prove that fit.

## Rechargeable power

- One protected **1S rechargeable LiPo/Li-ion pack**, nominal 3.7 V, with a 4.2 V
  charge termination specification. No series-cell battery architecture.
- Target **500–1000 mAh**, preferring 1000 mAh if the actual protected pack fits.
- USB-C 5 V charging and power-path operation while plugged in.
- BQ24074RGTR / C54313 remains the charger/power-path candidate.
- TPS63802DLAR / C2845237 remains the 3.3 V regulator candidate.
- JST S2B-PH-SM4-TB(LF)(SN) / C295747 is a newly imported surface-mount battery
  connector candidate. Its exact mating harness polarity must be documented and
  verified; a PH connector name does not establish battery polarity.
- Pack protection must cover overcharge, overdischarge and overcurrent/short
  protection. The charger alone does not complete pack protection.
- Retain battery temperature monitoring and ADC battery-voltage measurement.
- Set charge/input current only after pack ratings, USB current policy and the
  complete peak-load/thermal budget are established. No charge current or runtime
  has been validated.
- Keep the battery, display metal and speaker clear of the ESP32 antenna region.

The exact pack manufacturer/MPN, procurement/import path, protection circuit,
thermistor and harness are still unselected. No generic purchased-part definition
or fake battery footprint is permitted by the workspace instructions.

## Retained electronics and open interface decisions

Retain ESP32-S3 Wi-Fi/BLE/native USB, two digital microphones, I2S amplifier and
external 8 Ω speaker, and internal haptic feedback from the original brief.
Firmware implementation remains outside scope.

Hardware microphone privacy remains a requirement. The new single-control design
needs a reviewed hardware mechanism that prevents firmware enabling the microphones
when disabled, without adding a second exterior control. Button-controlled power
and signal isolation are an architecture candidate, not a verified implementation.
Do not silently replace hardware privacy with a software-only mute.

Any action confirmation, navigation and power/sleep behavior must use the screen
and the single button. Touch support is not assumed without selecting a compatible
display/interface. BOOT/RESET and test access are service features inside the
enclosure, not additional exterior controls; physical access is still to be planned.

## Validation state

Stage 1 remains in progress. B-002 is corrected locally with user authorization:
C5656610 now has a 0.60 mm hole. B-003 now passes native component generation on aligned core 0.0.2058. B-005 now blocks microphone ground-paste qualification. Stage 2
remains incomplete because the complete circuit/BOM and component qualification
are still being authored. No complete schematic, PCB placement, copper routes or fabrication files
exist. See `VALIDATION.md` for evidence and gates.

## A1 preview scope — latest user priority, 2026-10-03

The user explicitly permits a complete provisional schematic/placement before
full qualification, while still prohibiting routing. External protected battery,
speaker and motor use genuine imported PCB connectors; their exact enclosure
models can remain provisional. This supersedes earlier unresolved permission
for an externally sourced protected battery and the old absent-speaker/motor
import gates for this preview. All PCB electronic components remain genuine JLC
imports; imported definitions are not manually patched. The historical C370970
and C5656610 exceptions retain their narrow scope.

Four layers/1.6 mm/3 mm board corners are preview assumptions, not a released
manufacturing stackup. The LCD envelope is 33.7 × 42.94 mm, active 28.03 × 35.04 mm,
center (0, -3); it sits above top assembly with unqualified vertical separation.
The module antenna overhang and all-layer exclusion are explicit; RF clearance
from the final LCD, harnesses, pack, metal and enclosure still needs review.
Charging starts in hardware USB100; TMR/ITERM remain intentionally open for TI's
default safety timer/termination. TS goes to actual external pack NTC, with no
fake thermistor resistor. Pack capacity alone does not qualify current or safety.

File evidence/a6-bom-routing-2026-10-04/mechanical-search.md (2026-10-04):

# A6 primary-source battery and mechanical follow-up — 2026-10-04

Exact protected pack remains AKY2945/LP523450. Supplier specification: https://www.elektronik.ropla.eu/pdf/stock/aky/aky2945.pdf (release 2026-08-20). Page 5 inspected as battery-drawing.png: red BAT+, yellow NTC, black BAT−; yellow centre. No numbered outer contacts. Page 2 and product metadata contain an inconsistent "2 pins" field even though the drawing/description show PHR-3 and three wires. This cannot establish contact 1 polarity. Generic JST housing numbering and different LP523450 packs do not qualify this harness. J3.2 remains PACK_NTC; J3.1/3 remain open. No supplier messages were sent.

The same drawing specifies thickness expansion 7% ±3%. Therefore the previously allocated 10% upper expansion is manufacturer-backed; 5.7 mm maximum pack thickness becomes 6.27 mm. Dimensions are specified under a 300 gf measurement load; uncompressed installed shape, tape, lead exit and case retention still require qualification. Supplier product https://www.elektronik.ropla.eu/en/magazyn/magazyn/?ic=AKY2945 currently lists zero stock/MOQ 10; cannot claim immediate procurement. Search found AKY1178 with PCM/NTC/3C but same cell envelope and zero stock, no mechanical benefit. AKY2531 is an 850 mAh PCM/10kNTC/3C candidate with a different Molex connector and 5.7 mm cell thickness, not a qualified thinner substitute; no change made. No compatible thinner protected, 10kNTC, sufficient-current pack with exact confirmed harness was qualified in this search.

JST PH manufacturer's https://www.jst-mfg.com/product/pdf/eng/ePH.pdf page 1 requires 0.8–1.6 mm PCB thickness. JLC https://jlcpcb.com/capabilities/pcb-capabilities gives ±0.1 mm below 1 mm and ±10% at/above 1 mm. The existing nominal 0.8 mm trial can be 0.7 mm, outside JST's specified range. A nominal 1.0 mm board would be 0.9–1.1 mm and meet it, but changes the previous conservative height sum from 14.87 to 15.07 mm. This is a specific 0.07 mm conflict with the user's 15 mm hard maximum under the present flat-cover assumptions, not proof that all possible redesigned cases fail. Actual cover/adhesive/flatness/flex tolerances remain open. Board thickness and USB impedance were not changed without a validated mechanical/stackup replacement. Arbitrarily shaving walls/clearance is not accepted.

Display remains provisional bare BuyDisplay ER-TFT026-1 no touch, integrated ILI9341, 46×64×2.55 mm, 82.712% nominal physical overlap. Current official PDF https://www.buydisplay.com/download/manual/ER-TFT026-1_Datasheet.pdf exposes Rev3 text via web reader but drawing screenshot fails with cache miss and direct download returns HTTP403. Historical Rev1 drawing cannot establish current flex shape/thickness. Physical portrait fold, contact face, and which J7 contact meets display pin 1 remain unqualified; logical manufacturer pin-map tests do not prove mating. Existing reverse contact assignment is provisional and dependent J7 routing stays deferred. No 8051 kit or touch-only panel was substituted. Existing RF display gap 0.475 mm nominal /0.175 mm under stated dimensional/position allocation remains conditional, not full enclosure approval. J8 is removed; old A4 diagrams showing J8 are historical.

PCB remains 50×65 mm; external case maximum remains 60×75×15 mm. Speaker, motor, screw heads, wire paths/strain relief, PCB pin ends and actuator tolerances still require actual assembly-envelope review. No fabrication or physical fit approval.

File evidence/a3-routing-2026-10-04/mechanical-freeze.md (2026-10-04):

# A3 prototype placement freeze

**DISPLAY / FPC PLACEMENT FROZEN FOR PROTOTYPE ROUTING. A3 PLACEMENT FROZEN FOR ROUTING.** This freezes a reviewed assembly study, not enclosure tooling or verified physical fit. Native board GLB plus actual supplier model dimensions were inspected in perspective and side views in `mechanical.html`; this is a 3D assembly envelope study, not an electronic component definition. Native models remain unchanged. Five required checks: netlist/pin specification/source/schematic placement exit0; final placement exit0 with zero errors and three reviewed insertion-direction warnings. First placement checker also detected a 0.057 mm U14/C40 clearance conflict; C40 was moved 0.3 mm and passive orientations corrected before the final pass. Exact placement/source/GLB hashes are saved in placement-freeze-manifest.json. Copper is still absent at this checkpoint.

## Enclosure and display

PCB50x65x1.6 unchanged. Maximum external study60x75x14.82 mm: X[-30,30],Y[-34,41],Z[-7.97,6.85]. Conditional walls0.8 mm,back0.6 mm and frontcover/bezel0.6 mm. These are design allowances, not a mechanically qualified case. Preference57–58x72–73x13–14 is not currently proven; maximum is needed for the present display fold.

HS20HS072RX landscape body51.8x36.2x2.05(+/-0.05) at(0,-7.3). RearZ4.15;frontnominal6.20/max6.25. Actual tallest under-glass native part J6 top3.71 leaves0.44 nominal gap. J7 top2.81;U25 top2.449. Taller J3/J4/J8 (top6.30) are all beyond glass topY10.8. LCD is supported by bezel rails; neither FPC nor parts carry the glass load. Active area40.8x30.6; exact manufacturer active-area offsets remain represented by its drawing, approximate note rectangle is not a machining datum.

C11051 bottom-contact connector rotation90 faces left, mouthX-15.15236. Contact plane~Z1.90 from supplier section. FPC glass departure~Z5.10,0.5 mm outward straight, then a cylindrical180degree1.6 mm radius fold aroundY, minimumX-28.0. InsidecaseleftwallX-29.2 allows1.2 mm nominal gap. Pre-cut L tail is retained: horizontal root atY-14.9,vertical legX-17.5 toY-7.73, terminal tongue6.5 mm wide endingX-11.22655. 20.7(+/-0.5) mm drawing projection minus1 mm straight reversal and pi*1.6 gives3.926 mm insertion versus4 mm supplier section. Last5 mm stiffener remains straight; no bent stiffener or in-plane bend invented. Root offset and undimensioned strip shape are scaled drawing study assumptions, NOT manufacturer toleranced dimensions. Radius is a design target, not a supplier-certified minimum. Physical flex, latch access and assembly trial must confirm this before fabrication approval.

Native CAD intersection check across folded strip/tongue: only C25 lies below free flex; top1.60 vsflexlower1.84 =>0.24 mm nominal clearance. U7 moved away from flex to(-17,-19). J7 contact overlap is intentional. Assemble LCD/FPC before closing the bezel; removal requires opening case and lifting display while releasing C11051 slider. Internal J6 service plug must be fitted before display installation or accessed after removing glass. No claim of external service access.

The folded contact face points toward PCB. LCD terminal1 is at the north edge, corresponding to native J7 pin12; LCDn mates J7(13-n). Board wiring is reversed accordingly, including NC at J7pin6 and power/LED polarity. Imported connector definition is unchanged. Original exact display and connector drawings are retained under references/routing-a2 and evidence/display-review.

## Battery, RF and acoustic paths

AKY2945/LP523450 rotated behindPCB:52.5x35 at(0,-8),XY[-26.25,26.25]x[-25.5,9.5],topZ-1.10;5.7 mm nominal,conditional10% swelling6.27 givesbottom-7.37. PCBbottom-.8 =>0.30 mm nominal separation; no compressive mounting. Real pack thickness, foam, wiring and swelling policy remain physical qualification. NTC centre confirmed; outer numbered contacts still unproven after final authoritative drawing review. J3pin1/pin3 remain deliberately OPEN.

U1 antenna region dimensioned6 mm antennaX[-21,-3],Y[32.675,38.675]. All-layer keepoutX[-22,-2],Y[31.675,39.675], excludes only actual U1. Antenna native modeltopY38.675;internalcaseceiling40.2 =>1.525 mm nominal plastic/air margin. Glass/FPC topY10.8 gives>=21.875 mm longitudinal separation; packtop9.5 gives>=23.175 mm. Keepout is clear through the entire enclosure height. Metal speaker/motor envelopes and right-side wiring remainX>=14, at least17 mm horizontally from antenna. No battery/screw/cable crosses antenna exclusion.

Microphones now(-16.4,-28.8) and(21,-29), below packbottom-25.5. Rear acoustic corridors lead to case bottom without traversing pack;0.6 mm native acoustic holes unchanged. Acoustic channel/gasket design and noise/isolation are untested. Slim external speaker15x11x3 study at(19.5,18) fits rear pocket; PUI AS01508AO-WP-R8ohm/.7W is a manufacturer-backed candidate, exact JLC search empty, procurement acceptance remains OPEN. LEADER LCM0720A3176F7x7x2.65 envelope at(19.5,31), wire mounted, remains clear of antenna and speaker. No external part was fabricated as a PCB component.

J4/J8 mouths face+X with actual bodyfront22.5. Conservative3.4 mm mated housing extension plus2.5 mm wire-turn radius reaches28.4 vsinsidewall29.2 (0.8 nominal gap). JST side-entry assembled drawing gives9.6 mm totalprojection;3.4 mm here is a conservative study reserve, not claimed exact outer overhang. Plug insertion/removal is performed with the unscrewed board outsidecase; leaving in-case axial withdrawal space is not assumed. J3mouth+Y,top25.525,wire path right of antenna. USBshell reachesY-33.775 withinexternalbottom-34 and requires a real shell opening throughwall. TALK plastic actuator volume is modeled fromtopedge to actualtop push switch at(19,30.4); real force/travel/lever/case tolerances remain physical qualification.

## Mounts

Nylon M2 head envelope4 mm diameter,1.5 mm height abovePCB; plasticboss6 mm diameter. No metallic fastening near antenna. All-layer native radius3 keepouts preserved; actual routedcopper still needs audit.

| Hole | X mm | Y mm | NPTH drill mm | Keepout diameter mm | Hole edge to straight PCB edge mm | RF status |
|---|---:|---:|---:|---:|---:|---|
| M1 | 2 | 13 | 2.2 | 6 | 18.4 | Outside antenna; bossleft-1 vs modulecourtyardright-2.25 gives1.25 nominal gap |
| M2 | -21.5 | -29.5 | 2.2 | 6 | 1.9 | Far below antenna; nearest roundedcorner arc gives1.94 mm; bottomstraight governs1.90 mm |

M1bossbottomY10 vspacktop9.5 gives0.5 mm nominal gap; nylonheadtop2.30 vsglassrear4.15 gap1.85. M2bossupperY-26.5 vspackbottom-25.5 gap1.0; glassbottom-25.4 gap1.1. Boss/screw hole registration, torque and tolerance stack need physical test; two-point case stiffness not claimed validated.

### Keepout amendment before first successful copper

Espressif figure11-1 (saved esp32-antenna.png) distinguishes6 mm antenna area from7.49 mm pad-centre offset. Earlier oversized RF estimate overlapped U1 ground lands. Native keepout corrected to actual6 mm antenna+1 mm longitudinal margin, without moving any component or reducing manufacturer antenna exclusion. Antenna underside beginsY32.675,0.175 mm beyond PCBedge32.5. Original failed routing artifacts and original freeze manifest preserved; amendment changes only keepout/note metadata and routing settings. No successful copper existed at amendment.

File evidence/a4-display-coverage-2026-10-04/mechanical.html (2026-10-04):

A4 — 82.7% physical display coverage trial

TopSideBottomToggle glassToggle pack

PROVISIONAL BuyDisplay ER-TFT026-1: 46 × 64 mm portrait body. Overlap with the 50 × 65 mm PCB is 82.7%, excluding overhang and flex; dimensional and ±0.2 mm positioning allocations retain 81.7%. Cyan: body; dark cyan: provisional active-area position. Grey: PH mated envelopes, mouths down the right rail. Gold: rotated battery with conditional swelling allowance. Red: antenna exclusion. Case remains 60 × 75 × 15 mm maximum.

Not fabrication ready: bare-panel availability/current drawing, portrait flex/contact orientation, 0.8 mm stackup/USB impedance and full assembly tolerance stack remain open. Original native copper preserved; four traces only. The display, battery and loads are engineering envelopes, not fabricated hardware.

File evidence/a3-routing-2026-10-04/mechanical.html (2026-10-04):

A3 mechanical study — native board + assembly envelopes

TopSideBottomToggle glassToggle pack

BuyDisplay ER-TFT022-1, no touch: 54.36 × 40.3 mm landscape glass spans the 50 mm PCB width. Cyan: glass; dark cyan: active pixels. Orange: cable planning space, NOT a qualified fold. Maximum case 60 × 75 × 15 mm; model glass-to-module gap 0.19 mm; drawing maximum leaves only 0.05 mm before other tolerances. Flex/COF, mating contact face and tolerance stack still need verification. Gold: conditional battery swelling. Red: antenna exclusion. Native components + external envelopes; not fabrication ready.

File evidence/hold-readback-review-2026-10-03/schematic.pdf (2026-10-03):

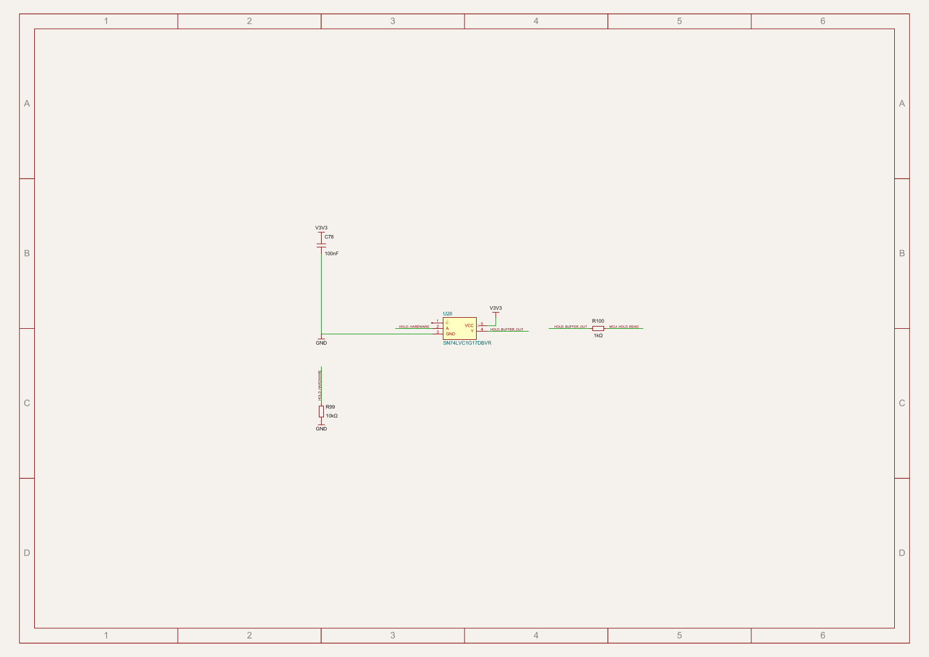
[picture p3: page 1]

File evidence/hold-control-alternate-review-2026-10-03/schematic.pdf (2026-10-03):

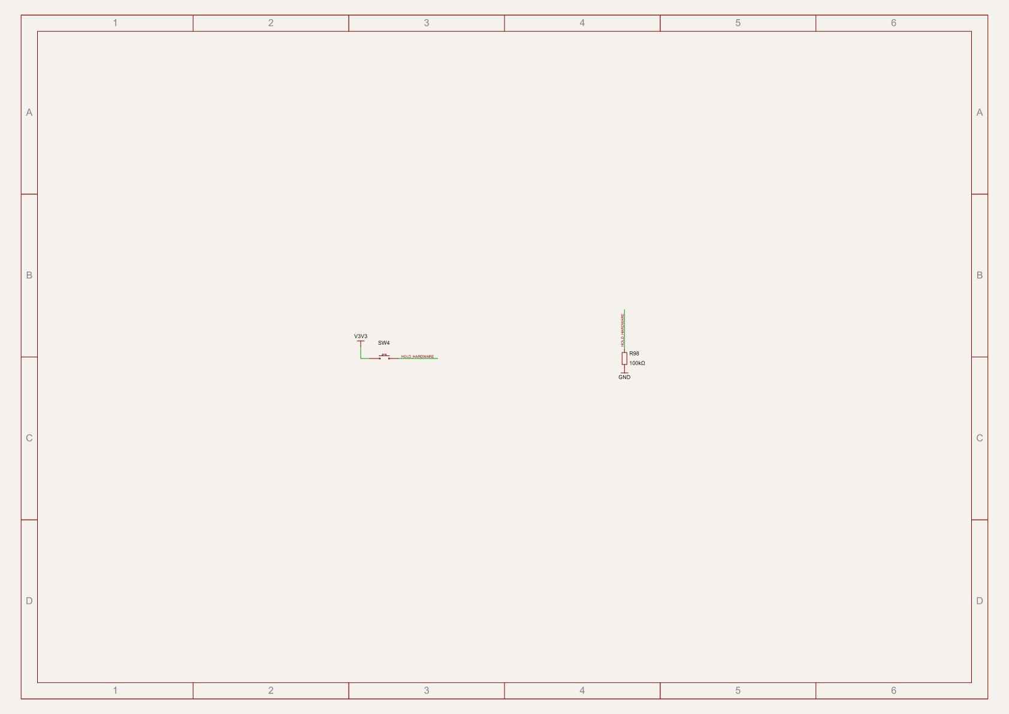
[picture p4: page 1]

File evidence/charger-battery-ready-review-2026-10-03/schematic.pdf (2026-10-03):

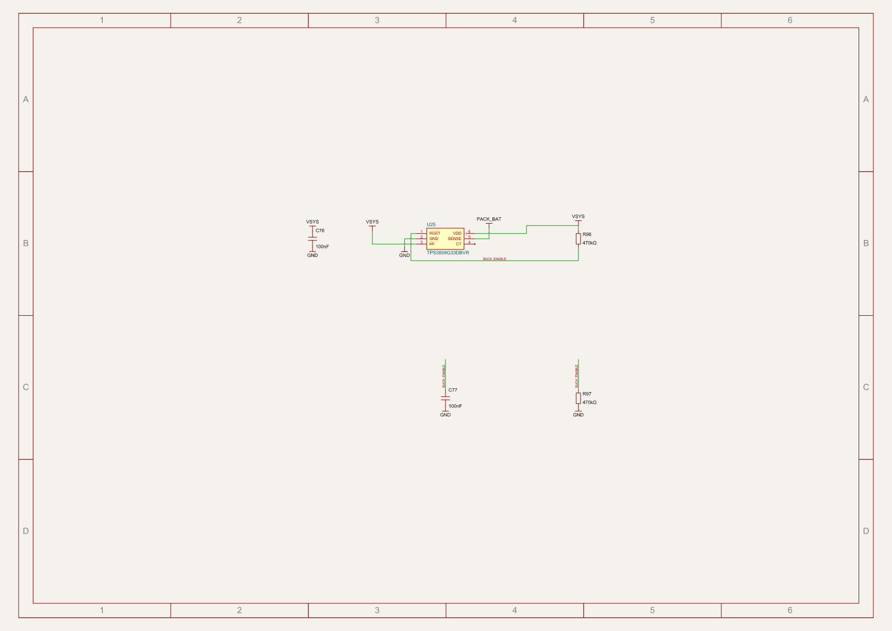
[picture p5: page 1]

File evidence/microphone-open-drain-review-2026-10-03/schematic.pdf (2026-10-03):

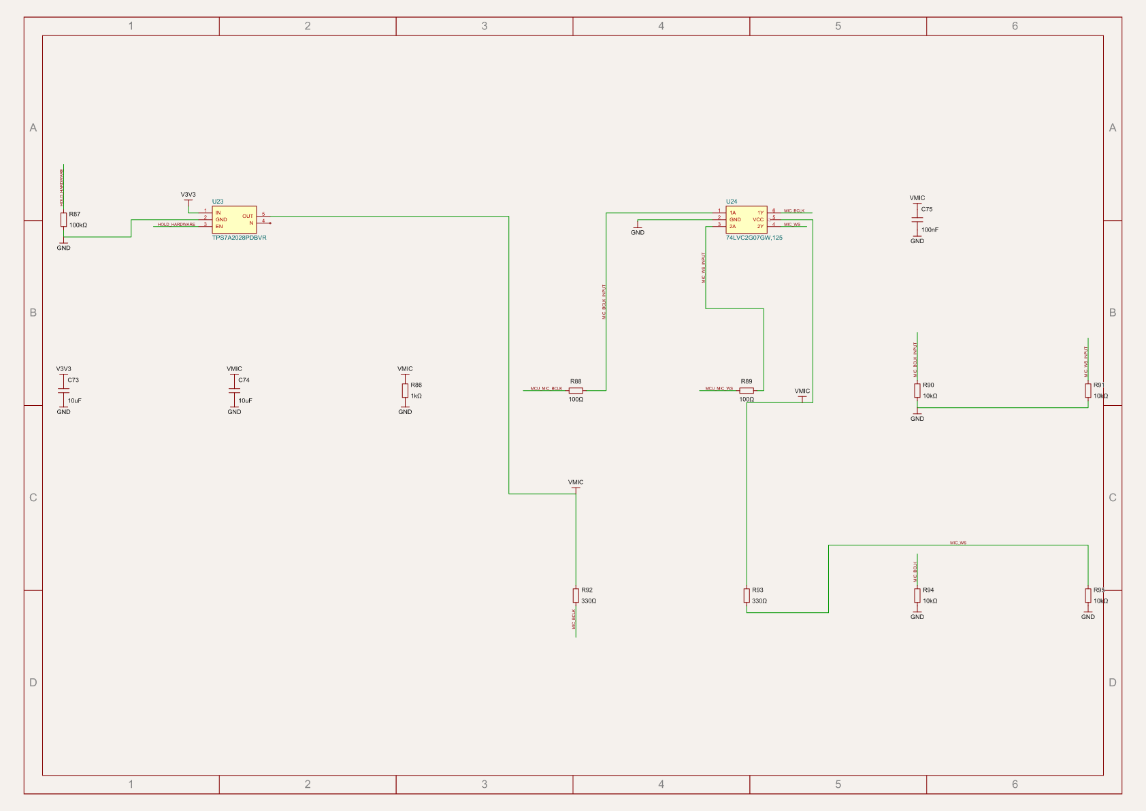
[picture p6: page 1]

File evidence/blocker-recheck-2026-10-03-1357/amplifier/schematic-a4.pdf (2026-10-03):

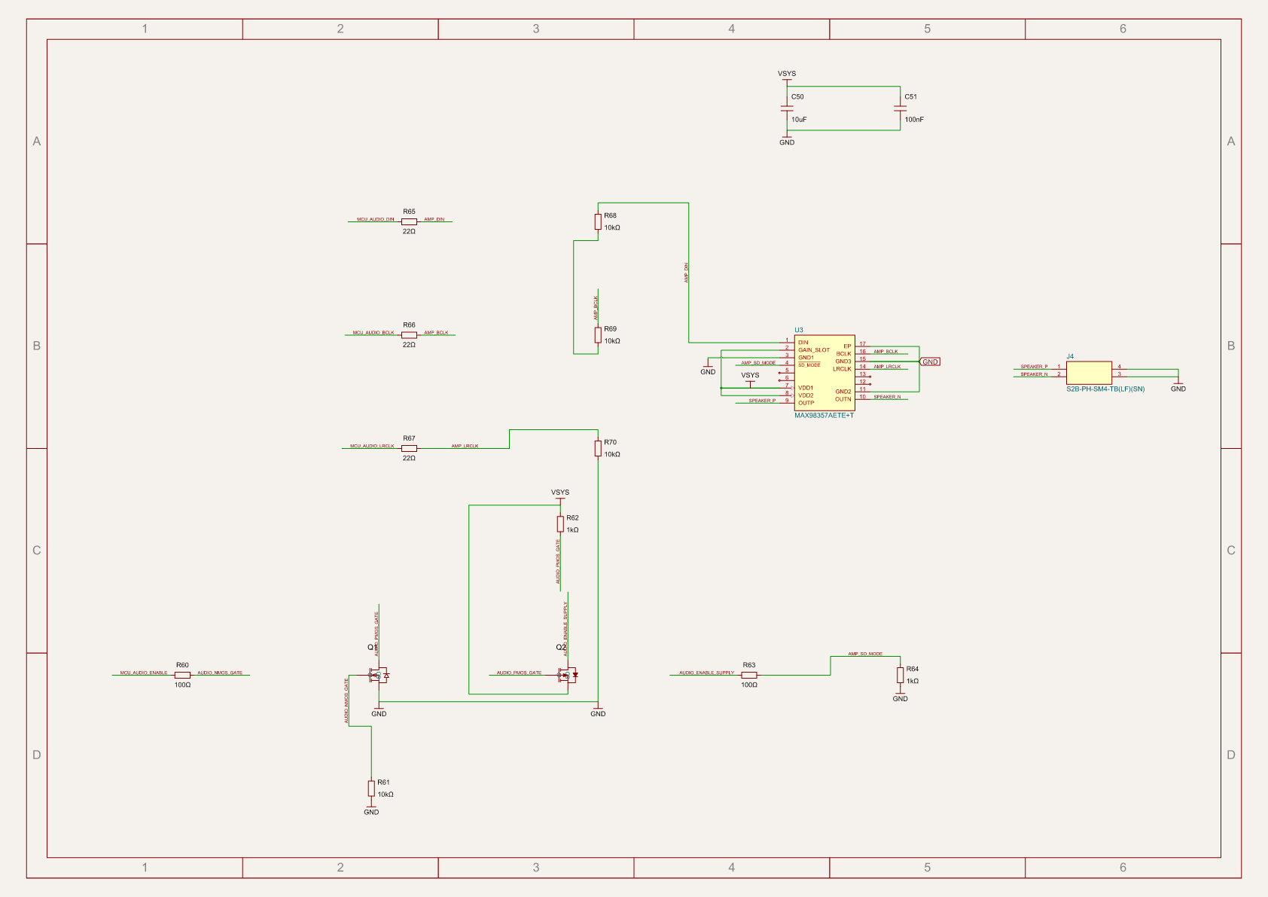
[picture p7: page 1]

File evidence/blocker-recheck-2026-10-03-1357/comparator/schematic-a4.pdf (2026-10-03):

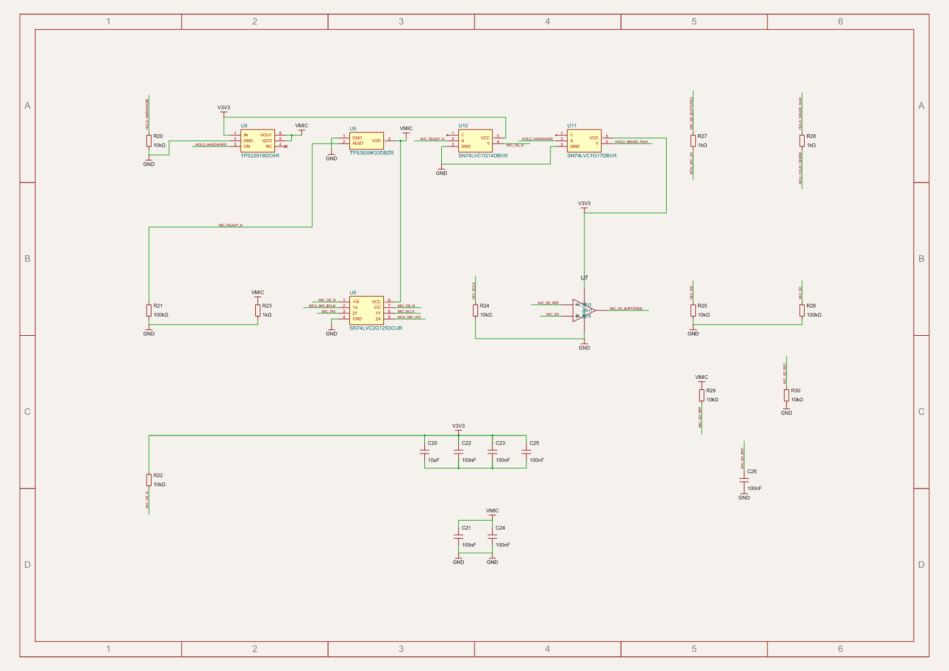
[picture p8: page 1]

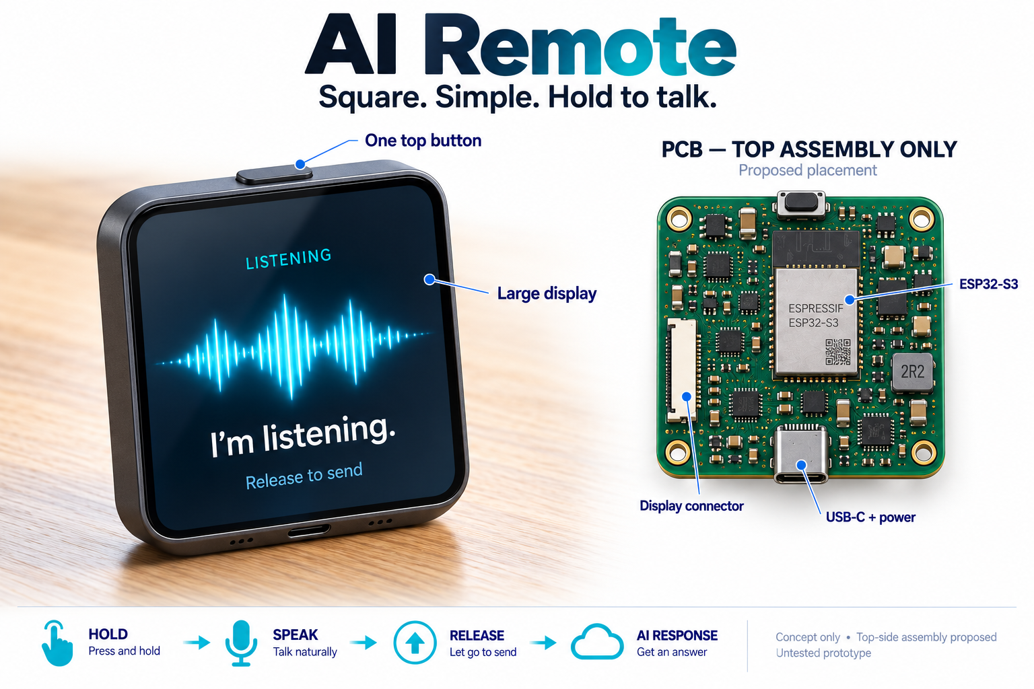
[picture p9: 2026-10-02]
assets/product-concepts/ai-remote-v1-infographic-v3.png

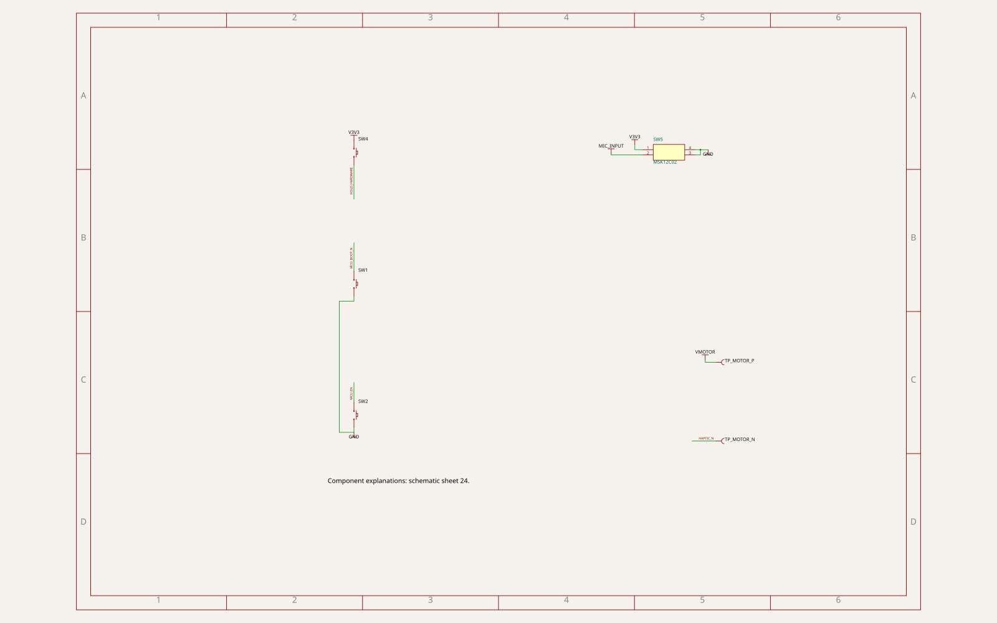
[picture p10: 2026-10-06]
evidence/microphone-local-bypass-2026-10-08/schematics/11-ControlsSheet.png

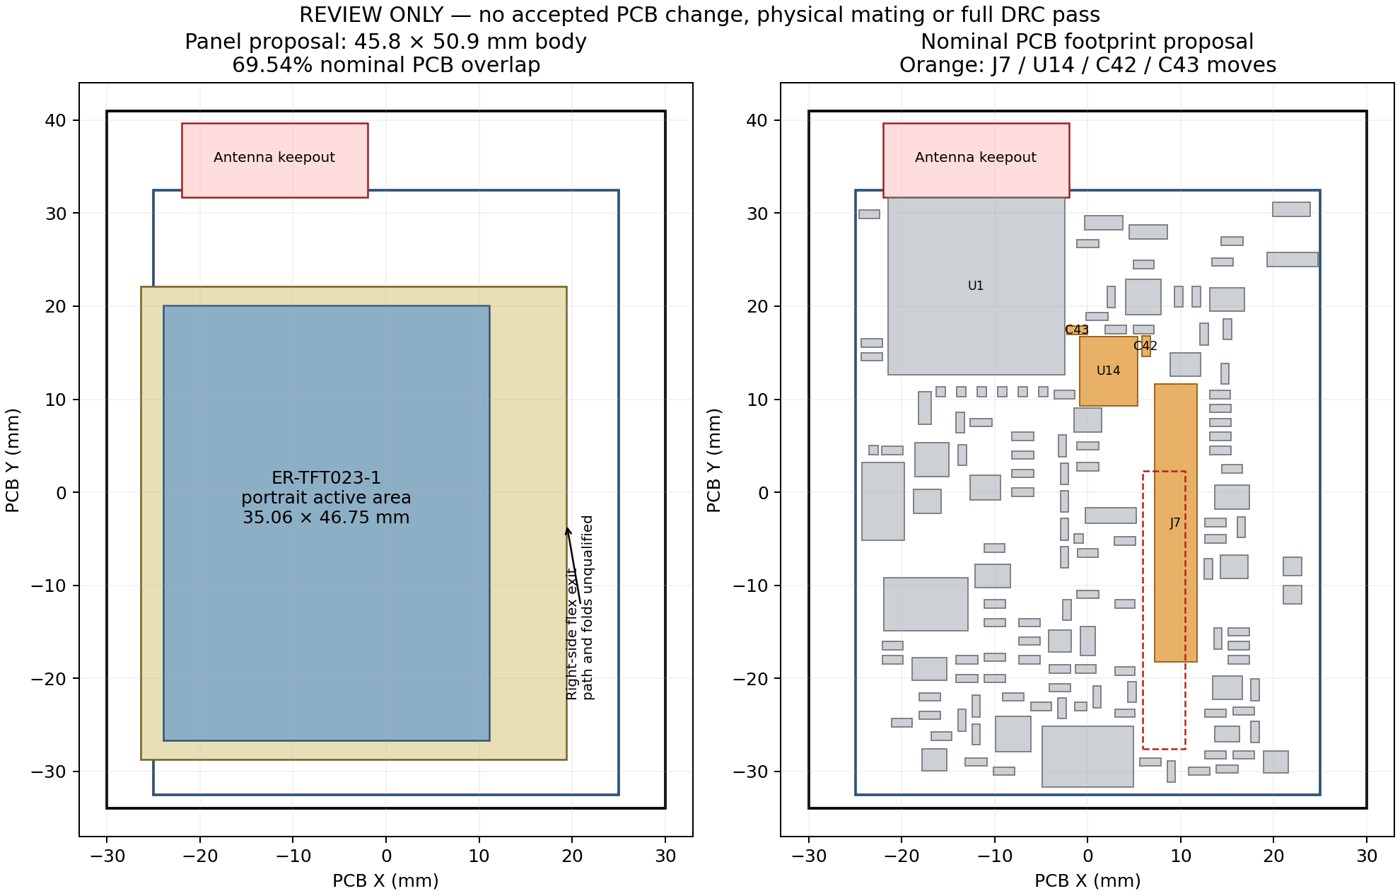
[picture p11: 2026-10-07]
evidence/display023-primary-review-2026-10-07/nominal-placement-proposal.png

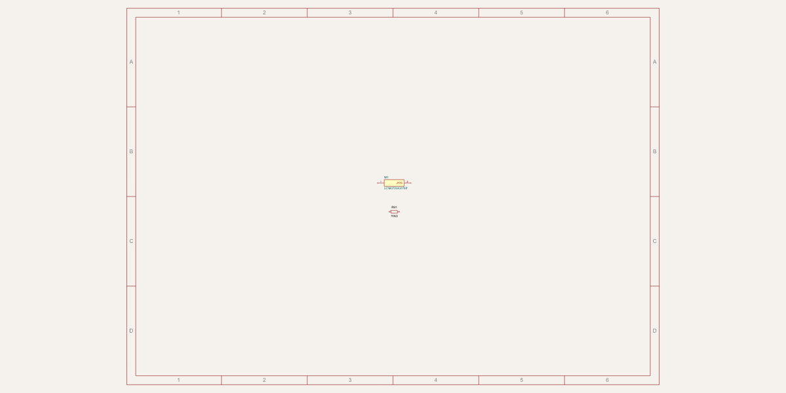
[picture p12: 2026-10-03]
evidence/haptic-review-2026-10-03/schematic.png

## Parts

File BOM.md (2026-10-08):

**0.0.10-wip-microphone-bypass — NOT READY TO ORDER.** The existing C81
100 nF X7R capacitor moves beside U5 to (17.05, -28.1) mm / 180 degrees on top.
Its authored 0.3 mm top copper connects directly to the U5 supply escape and
ground pour; the remote capacitor escapes are explicitly retired.
R93 moves to (16.5, -31.42) mm to clear the capacitor; its actual supply and
clock-bias copper is rerouted while retaining/reusing existing drill positions.
A finite 2 mm supply limit is declared because the untouched supplier
courtyards impose a 1.38 mm minimum; the proposed direct route is 1.44 mm.
The ground branch has a finite 2.5 mm limit: preflight uses a GND pad 2.15 mm
away before the pour exists, while the actual top pour-entry stub is 0.60 mm. No part is
added or replaced, and no new via is required. The exact manufacturer recommends
short connections on one layer for this bypass. Actual native qualification,
remaining full-board gates and public delivery receipts are recorded in the
[current repair review](https://github.com/AnasSarkiz/tscircuit-ai-agent-remote/blob/main/evidence/microphone-local-bypass-2026-10-08/review.md).
The display/battery interfaces and fabrication gates remain unresolved; this
revision does not establish zero DRC, complete connectivity or order readiness.
Older entries below are historical.

---

**0.0.9-wip-standard-uart — NOT READY TO ORDER.** J6 now uses the genuine
JLCPCB **C160389 / JST BM03B-SRSS-TB(LF)(SN)** three-contact upward SH header.
Its UART contacts are RX/GND/TX (pins 1/2/3); hold-downs 4/5 are GND.
Authored native routes replace the former six-contact connector's connections,
with a local audio-gate detour and ordinary 0.30/0.45 mm through-via escapes.
The standard JST programmer's TX/GND/RX cable maps directly to these contacts;
the custom three-to-six adapter is removed. Programming requires separate
USB/battery power, manual BOOT/RESET and an open enclosure: mated connector
height is 6.3 mm. Hardware operation and cable assembly are untested.

The 2026-10-07 20:07 UTC official JLCPCB page reports C160389
`overseasStockCount=32191` and `canPresaleNumber=31559`, at a reference
$0.2743 each. These are public inventory fields; they do not establish global
warehouse totals, assembler allocation or an order quote. Purchased count
remains 125 parts / 43 identities. All other component poses are retained.

The requested 2.8-inch LCD is still unimplemented. Exact panel/flex/antenna
fit, J7 mapping, battery outer-contact numbering, full connectivity, toolchain
schema/paste/Gerber issues and current-carrying qualification remain gates.
See the [actual native qualification and remaining blockers](https://github.com/AnasSarkiz/tscircuit-ai-agent-remote/blob/main/evidence/programmer-direct-uart-2026-10-07/review.md).
Publication is recorded separately after exact remote byte verification.
Older status and connector references below describe historical revisions.

---

## Current exact inventory and cost — 2026-10-07

**0.0.8-wip-speaker-routing — NOT READY TO ORDER.** The speaker repair retains
all 125 purchased placements / 43 exact JLCPCB identities and adds no electronic
parts. Five existing purchased components move; 120 remain stationary.

All 43 identities were checked against dated official stock responses. Total
stock covers two prototypes for 42 identities. **J6/C160405 has zero stock**;
C265110 is a different SHL connector and its supported exact-footprint import
fails on EasyEDA HTTP 403. It is not an accepted substitute. Total stock and
`canPresaleNumber` do not establish assembler allocation or a reservation.
U1's official page requires Standard PCBA; D2 reports only five units.

Reference component prices total **$26.333 per board**, including the unavailable
J6 reference price. PCB fabrication, assembly setup/loading, minimum quantities,
shipping/tax and the external display/battery/speaker/motor are excluded. The
two microphones account for $9.029 and the MCU for $5.0038. No feature removal,
extra purchased part, reservation or order was made to obtain this estimate.

The resolved BOM has 125 rows with no blank descriptions or supplier codes used
as packages. The raw official converter still produces 31 blank comments and
125 supplier-code footprint fields. Strict PnP rotation qualification stops at
U14 with `incompatible_pin1_locations`; the assembly files are not approved.

[Current stock binding](evidence/routing-continuation-2026-10-07/dated-stock-application.json),
[reference cost](evidence/routing-continuation-2026-10-07/complete-reference-cost-review.json)
and [remaining qualification](evidence/routing-continuation-2026-10-07/review.md).
Older inventory and status entries below are historical.

---

## Historical manual routing repair — 2026-10-07

**0.0.7-wip-manual-routing-repairs — NOT READY TO ORDER.** This entry
supersedes the historical checkpoints below. U4 now has a real 0.36 mm ground
escape to a 0.30/0.45 mm through via. Its clock/data escapes were moved to make
room while retaining their original nets and minimum widths.

The supported source CLI build completes in 251.86 seconds and exits 1 with
**52 open-port errors**: 46 J7 display contacts, four U27 backlight contacts and
two SPEAKER_N contacts. The unchanged generated JSON contains 381 traces,
325 through vias and 271 pours. Independent geometric checks measure **zero
shorts and zero clearance violations**, preserve all 9,842 previously connected
numbered-terminal pairs and verify all 247 authored regions at their nominal
widths. There are still 13 physically open nets. J3's unassigned outer contacts
are excluded from that count; battery polarity and display mating remain
unqualified. Every purchased component footprint, pose and model is unchanged.

A speaker/VSYS candidate was rejected: its native output disconnected U25.2 and
C76.2 ground, losing 266 existing terminal pairs, and reported a bus-skew error.
The candidate and follow-up proposals are preserved as evidence, not accepted
routing. Original speaker constraints and original power copper remain intact.
No native errors or checks were suppressed.

The five source/placement checks pass. Board tests remain 48 pass / 2 fail;
169 strict native-schema failures, 32 missing U16/U27 paste records and the
official shorts/export error “Unsupported shape polygon” still block approval.
Two regulator traces violate explicit source widths; 63 nominal-width branches
and current/signal-integrity qualification remain open. Stock and programmer
limitations in the prior review still apply. No order or physical test occurred.

Primary supplier retrieval is blocked by HTTP 403 from the cloud policy. Add
`www.buydisplay.com` and `www.elektronik.ropla.eu` to the existing Environment
settings allowlist, then save and publish it to resume exact J3/J7 qualification.
The editable allowlist was unavailable; no unknown list was replaced.

[Current repair review and exact receipts](https://github.com/AnasSarkiz/tscircuit-ai-agent-remote/blob/main/evidence/routing-zero-drc-2026-10-07/review.md).
Matching public publication and cloud CI are separate observations; a WIP
preview does not establish zero DRC or fabrication readiness.

---

## Connection repair checkpoint — 2026-10-06

**0.0.6-wip-connection-repairs remains an untested, incomplete WIP.** Connection repairs retain all 125 purchased placements / 43 exact JLCPCB identities and ten native pads. No part, footprint, position or model is replaced. Dated October 6 stock matches the actual current identities: J6/C160405 remains unavailable, and positive total stock does not qualify assembly allocation, reservations or rotations. U16/U27 still have 32 missing native paste records.

[Actual source/native review](https://github.com/AnasSarkiz/tscircuit-ai-agent-remote/blob/main/evidence/connection-repair-2026-10-06/review.md). Earlier revision requirements and BOM history follow.

---

## Current six-point review — 2026-10-06

**0.0.5-wip-style-vias-power — NOT READY TO ORDER.** This entry supersedes the older counts and status below.

J1 now uses the requested native USB-C schematic symbol while preserving its numbered contacts, supplier identity, physical footprint and models. CLI schematic-placement analysis reports zero issues. The actual UI analysis was invoked but its external analysis module failed to load; this is a blocked check, not a passing result.

The clarified high-current requirement is implemented: all 80 authored high-current trunks and 59 audited native high-current traces use top/bottom copper. Six low-current pull-up/control/probe branches have separate documented requirements. All 217 vias physically span all four layers, with exactly 0.30 mm holes and 0.45 mm pads; blind/buried vias are explicitly disabled. All 151 native supply/control and relocated signal regions meet their nominal widths.

The supported frozen-install CLI build completes in 247.03 seconds and exits 1 with **89 real open-port errors**. Native output contains 328 traces, 217 vias and 183 pours. The independent geometry audit measures zero shorts and zero clearance violations, preserves all 8,146 previously connected port pairs, and still finds **25 physically open nets**. All 125 purchased component footprints, poses and models are unchanged. TP1 moves to (-22.2, 12.3) mm inside the main ground island. The five source checks, copper-free placement build, TypeScript, formatting and 64 routing regressions pass. Board tests report 48 pass / 2 fail (fabrication and strict native schema).

Official exact-part JLCPCB pages cover all 43 identities / 125 placements: 42 identities report enough total stock for one board; **J6 C160405 reports zero stock**. Positive stock for U1, D2 and U16 does not qualify assembly allocation. No stock reservation or assembler rotation approval is claimed.

Remaining fabrication blockers include unresolved J3 numbered outer polarity and J7 FPC mating, incomplete connections, 169 strict native-schema failures, missing pill-pad paste, unsupported polygon Gerber shorts/export, two regulator switching routes with 0.275 mm necks below their explicit 1.0 mm source requirement, 55 nominal-net-width branches requiring load review, and supplier rotations/current/stackup/signal-integrity/mechanical qualification. The standard JST programmer needs the documented adapter; direct connector mating and hardware operation are untested.

The supported source snapshot comparison completes in 61.13 seconds and fails on PCB and schematic differences; committed references are retained. All 26 native A4 pages, four copper layers, mask/paste and critical zooms were inspected. Native component guides cover all 135 references with valid annotation schema. Final component inventory confirms 32 missing pill-pad paste records on U16/U27.

[Full review and actual receipts](evidence/six-point-board-review-2026-10-06/review.md). Publication is recorded independently; native preview availability does not establish passing cloud CI or fabrication approval. No order or physical test has been performed.

---

## Latest C30 and BOM export correction — 2026-10-06

C30 is now genuine **GRM188R61A226ME15D/C84419,22µF**, replacing
GRM188R61A106ME69D/C90053,10µF. C84419 quantity is4; C90053 quantity is10.
There are125 purchased placements and43 exact JLC identities, plus10native
solder pads. Imported definitions/models were not edited.

The official BOM0.0.19 `resolvePart` API matches each native part to a recorded
exact supplier MPN/package label:125rows,0blank descriptions,0supplier codes
used as package labels. [Export method and receipt](evidence/board-corrections-2026-10-06/resolved-bom-receipt.json).
These dated labels do not qualify current stock, land patterns, rotation or
assembly. Export remains marked NOT-FOR-FABRICATION until all board gates pass.

---

## A6 current checkpoint — 2026-10-04

**Engineering prototype — NOT FABRICATION READY.** This supersedes historical A5 counts below. Genuine in-stock replacements are implemented: seven C22548→C21190 (eight C21190 total), six C105588→C22775. Active125 purchased PCB parts /43identities plus10native pads. Published core0.0.2083 polygon paste fixes13 formerly missing pads;32 pill pads still lack paste. Current native copper20traces/2vias; five missing backlight traces resolved, unconnected-port errors413→402. Genuine saved phase replay and actual added-copper geometry verified; all prior11traces/2vias unchanged.

Required five native checks and copper-free placement CAD build pass. Format/types pass; tests42pass/2retained failures and full native strict schema169failures. Diagnostic PCB-image shorts passes, but **required Gerber-based shorts check fails “Unsupported shape polygon”**. Canonical routed build exits1 with402 retained unconnected-port errors. Final layout/assembly/fabrication gates remain blocked. Fresh4layer/paste/detail/13A4/3D prototype previews inspected.

Battery centreNTC confirmed; outer numbered polarity is still absent from the exact supplier drawing and stays unrouted. BuyDisplay panel has integrated ILI9341 and82.712% nominal physical coverage; actual FPC/contactface/pin1 mating and current bare-panel availability remain unqualified. JST board-thickness tolerance requires a mechanical/stackup revision; current conservative height becomes15.07 mm at a qualifying1mm PCB, above15mm. PCB stays50×65 mm; case max60×75×15 mm. No fabricated confirmation, generic imports or orders.

[Detailed A6 review](evidence/a6-bom-routing-2026-10-04/review.md) · [Active inventory](evidence/a6-bom-routing-2026-10-04/inventory.md) · [Mechanical primary sources](evidence/a6-bom-routing-2026-10-04/mechanical-search.md). Parentfaa491d22d1a55210833a8ea3086ae56dc450245. Intended public version0.0.2-wip-a6-bom-routing; verify publication receipts before claiming upload complete. Watcher stays paused; no cross-chat issue messages.

---

## Current layout/BOM audit — 2026-10-04

Preliminary native placement/connectivity/shorts checks pass; final layout and assembly BOM remain **blocked**. Current 135 components = 125 purchased parts + 10 native pads. Fresh supplier audit:43/44 exact identities match; C22548 stock 5 versus 7 required, C105588 (six 100 Ω parts) has no in-stock result. Current native paste is missing on45 SMT pads: U16 (17), U27 (16), U4/U5 (8), J1 (4). Official BOM probe125 rows / 31 blank Comment fields / 125 supplier-code footprints. Fresh current 3D and 13 A4 sheets reviewed; display physical mating, pack outer polarity,0.8 mm stackup/case fit and full routing remain open. Tests42 pass / 2 retained failures. In-stock resistor alternatives were found but not substituted. [Full audit](evidence/layout-bom-audit-2026-10-04/review.md) · [Current inventory](evidence/layout-bom-audit-2026-10-04/inventory.md). Source/copper/imports unchanged; no new package retry, watcher resume or cross-chat message. **NOT FABRICATION READY.**

---

## A5 BOM change — 2026-10-04

J8/C173752 quantity reduced by one. Native TP_MOTOR_P/TP_MOTOR_N solder pads are PCB features, not purchased components. J6 remains. Earlier component counts below are historical; current total135 includes125purchased parts and10native testpoints. Motor remains external and its exact assembly/harness qualification is open. No manually repaired fabrication BOM is approved.

# Latest A4 — 82.7% physical display coverage trial

**WIP prototype; NOT FABRICATION READY.** This supersedes conflicting A3/A2 selections below. Provisional external BuyDisplay **ER-TFT026-1**, 46 × 64 mm portrait body, overlaps the unchanged 50 × 65 mm PCB by **82.712%** (81.737% with stated dimensional/position allocation). Overhang, flex and bezel are excluded. Bare-panel availability and the current drawing/FPC are still unconfirmed; this is not a qualified purchasable display selection.

Implemented genuine C157929/C173752 internal side-entry PH headers, TPS60230RGTR/C1848364 four-channel backlight with 10 kΩ nominal 62.4 mA total, moved placement/mounting trial, rotated battery envelope and **0.8 mm trial PCB**. The thin stackup and USB impedance need new qualification. Battery pin2=NTC; both outer contacts stay open. Four original native traces are preserved; most connections remain unrouted. Fresh canonical build retains 431 connection errors; 38 tests pass and two fabrication/schema gates fail. Placement and short checks pass without claiming full routing or fabrication approval.

[Full A4 engineering review](evidence/a4-display-coverage-2026-10-04/review.md) · [Interactive A4 native model and display envelope](http://127.0.0.1:4949/evidence/a4-display-coverage-2026-10-04/mechanical.html). Current PCB count:134 physical components,496PCB ports,76named nets. Watcher remains paused and cross-chat issue messages remain disabled. Publication receipts are recorded separately; intended public package version `0.0.2-wip-a4-display-coverage`.

## Active A4 substitutions

| Reference | Exact part | Source | Quantity |
|---|---|---|---:|
|External provisional display|ER-TFT026-1 no-touch bare panel|BuyDisplay; no current bare-panel orderability verified|1|
|J3|S3B-PH-K-S(LF)(SN)|JLC C157929, genuine untouched import|1|
|J4|S2B-PH-K-S(LF)(SN)|JLC C173752, genuine untouched import; J8 removed in A5|1|
|U27|TPS60230RGTR|JLC C1848364, genuine untouched import|1|
|R102|RC0603FR-0710KL, 10 kΩ|existing genuine JLC import|1|
|J7 retained|AFC07-S50ECA-00|JLC C262650; portrait mating provisional|1|

No fresh whole-BOM assembly availability guarantee. External pack AKY2945/LP523450 centre contact NTC10k; outer polarity remains pending. PH headers are top-inserted through-hole parts and need manual/selective assembly qualification. Superseded A3 choices below are historical.

---

# Latest A3 BuyDisplay and first-copper checkpoint — 2026-10-04

**Engineering prototype — NOT FABRICATION READY.** This supersedes conflicting A2/A1 selections below. The external screen is now **BuyDisplay/EastRising ER-TFT022-1, bare 2.2-inch 240×320 TFT, no touch**, purchased separately from the PCB. JLCPCB supplies the board electronics and the genuine **AFC07-S50ECA-00/C262650 top-contact50-pin connector**, not the screen. Its54.36×40.3 mm landscape glass spans the full50 mm PCB width. The raised-glass/flex/height tolerance study remains open inside the unchanged50×65 mm PCB and60×75×15 mm maximum enclosure.

Electrical source wiring uses panel n→J7(51−n) for the planned right-edge single fold, SPI II mode1110,2.8 V logic/level translation and three separate TPS60231 current sinks. The old HS20HS072RX,12-pin connector and resistor-fed backlight are superseded. Battery centre2 staysPACK_NTC and the outer contacts stay open.

Actual partial copper now exists: two short MCU USB traces and two compact regulator switch traces,0vias. Original native routes/events and supported replay are preserved before moves; the regulator island/cache were moved together−8 mm X. The other nets are not routed. Current whole board:134physical components(126purchased+8testpoints),502PCB ports,75named nets. Required remaining-connection errors are retained; no fabrication outputs are approved. Full technical review: [BuyDisplay integration and fit limits](evidence/a3-routing-2026-10-04/buydisplay/review.md). [Live mechanical study](http://127.0.0.1:4949/evidence/a3-routing-2026-10-04/mechanical.html).

Native placement overlap/keepout errors are zero. Source, netlist and pin-specification checks have no errors; supplier metadata warnings and connector-access warnings remain disclosed. Four orientation suggestions were applied. The source-level schematic pin-map and imported connector orientation tests are distinct from physical panel operation. Full routing/schema/fabrication tests retain their failures; publication never means fabrication approval.

Source parent0300c2eed5d591b24dba9d2bdd59e17de0f94bf7. Intended public release0.0.2-wip-a3-buydisplay-first-copper; verify receipts before claiming it published. Background watcher remains paused. The user revoked cross-thread issue messages; no issues are sent to another chat.

## Active A3 substitutions

| Reference | Exact part | Supplier | Quantity |
|---|---|---|---:|
|External screen, not PCB population|ER-TFT022-1 no-touch bare panel|BuyDisplay/EastRising; no JLC part number|1|
|J7|AFC07-S50ECA-00|JLC C262650|1|
|U27|TPS60231RGTR|JLC C544659|1|
|C82/C83|CL10A105KB8NNNC,1uF|JLC C15849|2|
|C1|CL10A475KO8NNNC,4.7uF±10%|JLC C19666|1|

C11063 bottom-contact connector is an unselected trial. Active external pack remainsAKY2945/LP523450; connectorJ3centre2NTC and unresolved outer1/3 remain unchanged. PCB assembly includes126purchased components,8native testpoints excluded; no manually repaired fabrication CSV or claimed availability guarantee.

# Latest A2 checkpoint — 2026-10-04

**NOT FABRICATION READY.** This section supersedes conflicting historical A0/A1 selections and status below. A2 updates the genuine C11051 twelve-pin display connector, manufacturer display wiring, centre battery NTC, two native M2 mounting trials and provisional placement. Battery outer numbering remains pending; both outer contacts are unconnected/unrouted. Display/flex/enclosure/RF fit is still open; routing remains disabled. Full report: [A2 fabrication checkpoint](evidence/routing-intake-2026-10-04/fabrication-report.md).

A2 active J7 is AFC07-S12FCC-00/C11051; old C11050 is inactive. J3 active C265101 is PH3: pin2PACK_NTC;1/3unassigned pending outer polarity. HS20HS072RX/C5329582 and AKY2945 are external modules, not PCB population. Native export122purchasedrows plus8coppertestpoints excluded from BOM/CPL;32blankCommentfields and U14rotation unresolved.

# Candidate BOM — A0

**Not an assembly/fabrication BOM.** Import success alone does not qualify a part. Regulator review references are provisional; final designators require the complete schematic.

| Function | MPN | LCSC | Package | Intended qty | Status |
|---|---|---|---|---|---|
| MCU/Wi-Fi | ESP32-S3-WROOM-1-N8R8 | C2913201 | Antenna module | 1 | Imported; complete review pending |
| Charger/power path | BQ24074RGTR | C54313 | QFN-16 + EP | 1 | Imported; battery/current/thermal design pending |
| 3.3 V buck-boost | TPS63802DLAR | C2845237 | DLA-10 2 × 3 mm | 1 | Imported; pin identities pass; application review pending |
| Digital microphones | ICS-43434 | C5656610 | LGA-6 bottom port | 2 | B-002 locally corrected to 0.60 mm with user authorization; B-003 resolved on aligned official core 0.0.2058; B-005 ground paste missing; lifecycle/full qualification pending |
| I2S speaker amplifier | MAX98357AETE+T | C910544 | TQFN-16 + EP | 1 | Imported; full application review pending |
| USB-C receptacle | TYPE-C-31-M-12 | C165948 | USB2.0 hybrid mount | 1 | Imported; orientation/protection/mechanics pending |
| Battery connector candidate | S2B-PH-SM4-TB(LF)(SN) | C295747 | SMT right-angle, 2 mm pitch | 1 | Imported verbatim with CLI 0.1.2232; top-side assembly candidate; drawing/polarity/full qualification pending |
| Microphone clock buffer candidate | SN74LVC2G125DCUR | C21404 | VSSOP-8 | 1 | Imported; architecture/ratings pending |
| Microphone SD receiver candidate | TLV3201AIDBVR | C105188 | SOT-23-5 | 1 | Imported; comparator application review; B-008 missing reference label; final timing/rail review pending |

| Regulator inductor | DFE201612E-R47M=P2 | C668312 | 0806, 470 nH | 1 | Imported verbatim; TI recommended series; footprint/current qualification pending |
| Regulator input capacitor | GRM188R61A106ME69D | C90053 | 0603, 10 µF, 10 V, X5R | 1 | C4 review; effective capacitance and footprint qualification pending |
| Regulator output capacitor | GRM188R61A226ME15D | C84419 | 0603, 22 µF, 10 V, X5R | 1 | C5 review; effective capacitance and footprint qualification pending |
| Regulator high feedback | RC0603FR-0751K1L | C364359 | 0603, 51.1 kΩ, 1% | 1 | R5 lower-bias-error divider; provisional static corners recorded |
| Regulator low feedback | RC0603FR-079K1L | C114639 | 0603, 9.1 kΩ, 1% | 1 | R6 lower-bias-error divider; provisional maximum 9.2456 kΩ |
| PG pullup / control candidate | RC0603FR-07100KL | C14675 | 0603, 100 kΩ, 1% | TBD | R7 and isolation-review applications; final allocation pending |
| Charger current candidate | RC0603FR-073KL | C126358 | 0603, 3 kΩ, 1% | TBD | Imported only; 296.7 mA nominal candidate, pack selection pending |
| Bypass capacitor candidate | GRM188R71C104KA01D | C45000 | 0603, 100 nF, 16 V, X7R | TBD | Imported only; application allocation pending |

## Rejected or unselected imports

| Part | LCSC | Reason |
|---|---|---|
| TPS63070RNMR | C109322 | Missing separate physical identities 8/13 and PS/SYNC alias; alternate TPS63802 under review |
| EC11J1525402 | C209762 | Alternative investigation only; ALPS Not Recommended for New Designs; unselected/unqualified |
| EC11E15244G1 | C370970 | Historical locally corrected encoder; removed from active design by accepted single-button concept |
| DSK110 | C908227 | Unrelated diode returned by display search; not active BOM |

All definitions/models originated through the supported JLCPCB importer. The user explicitly authorized C370970's native chip-box symbol and footprint correction: five holes to 1.05 mm and two slot lengths to 2.65 mm. Pin labels, supplier identity, all centers, other geometry and models remain unchanged. This is a local correction, not a corrected official supplier library. The user also authorized C5656610's acoustic hole diameter correction to 0.60 mm; all other microphone bytes and its center remain unchanged. Other imports remain unmodified. Rejected imports are retained as evidence.

## Required parts still unselected

Screen-dominant display/module and connector; exact protected 1S 3.7 V, 4.2 V-charge LiPo pack (500–1000 mAh target), protection/thermistor/harness; speaker and speaker connector; haptic connector/MOSFET/flyback protection; single top-edge hold-to-talk control and compatible hardware microphone isolation; internal BOOT/RESET service access; remaining charger/audio/logic passives; USB CC resistors, ESD/current protection and decoupling; programming/test connectors. No placeholders represent these parts. Separate encoder, APPROVE/REJECT buttons, privacy slider, exterior power control and front RGB LED are not part of the accepted concept.

The rechargeable pack and battery circuit are not yet integrated. C295747 is a real imported connector candidate, not a qualified battery pack. All electronic parts and connector solder joints must use top-side assembly; bottom-side population is prohibited by the accepted requirements. Exact current and thermal budgets remain pending.

Waveshare 1.54 inch LCD Module was researched, not selected as an imported component. PH2.0 J2 order is **BL/RST/DC/CS/SCK/DIN/GND/VCC**, opposite schematic J1 ordering. Contact orientation requires independent verification.

Catalogue identities/manufacturer sources checked on 2026-10-02 and 2026-10-03; see `references/sources.md`. Final JLCPCB assembly allocation, basic/extended classification, external procurement, costs and exact availability remain unverified. Do not order from this document.

## A0-controls-review milestone — 2026-10-03

All new imports use the supported exact-footprint/download workflow and remain
unmodified. `evidence/controls-review-2026-10-03/import-source-manifest.json`
records their source checksums. The single hold switch EVQPUC02K / **C79174**
is blocked by B-006 (lost 1↔3 / 2↔4 internal contact pairs, locating holes
0.9000236 mm instead of Panasonic's maximum 0.85 mm). Do not integrate it.

Independent microphone isolation application candidates:

| Function | Exact MPN | LCSC | Application status |
|---|---|---|---|
| VMIC switch | TPS22919DCKR | C2149796 | B-007 supply metadata warning visible; actual pin 1 wiring verified against TI |
| VMIC startup supervisor | TPS3839K33DBZR | C96333 | VMIC threshold and delay review; final rail/leakage/timing pending |
| Supervisor inversion | SN74LVC1G14DBVR | C7835 | Review fixture only |
| Hold-state isolation | SN74LVC1G17DBVR | C7836 | Review fixture; no MCU-to-button control path |
| SD comparator | TLV3201AIDBVR | C105188 | VMIC/2 reference; B-008 label defect; not qualified for integration |
| Control/reference resistor | RC0603FR-0710KL | C98220 | 10 kΩ, 1%; candidate allocations |
| GPIO isolation / VMIC bleed | RC0603FR-071KL | C22548 | 1 kΩ, 1%; candidate allocations |
| Contact current limit candidate | RC0603FR-07100RL | C105588 | 100 Ω, 1%; unused until switch qualifies |

The isolated review excludes the blocked button and microphone. Every populated
PCB component is top-side; fixture dimensions are not the handheld envelope.
Native generation/connectivity/placement pass with the documented metadata and
symbol warnings. It is not a tested privacy circuit or a complete schematic.
See `AUDIO.md`. C23654 / SN74LVC1G125DBVR and newly imported C100024 /
SN74LV1T34DBVR are rejected as microphone SD receivers: their input low thresholds
do not cover the microphone's guaranteed VOL. No imported definitions were changed.

Previous 8bbde6e core-alignment publication was verified on GitHub and private
release 0.0.2-wip-a0-core-alignment (274 files); receipt is saved with this milestone.
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

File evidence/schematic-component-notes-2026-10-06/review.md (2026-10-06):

# Schematic component explanations — 2026-10-06

Revision: `0.0.4-wip-schematic-notes`. Parent public commit:
`540f5c84e37ea882b7d24db39b9731b2c40ebb74`.

The user requested text in the schematic explaining every component. Native
`schematictext` annotations explain all 135 component references, covering 125
purchased devices/passives/connectors and 10 native solder/test pads. No component
is omitted or represented only by an unrendered source comment.

The 13 original A4 circuit sheets carry a short cross-reference to 13 paired
A4 guide pages (indices 14–26). These pages provide each component's reference
and purpose. They retain the battery connector's unverified outer polarity,
display contact-orientation uncertainty and programmer-adapter requirement.
Descriptions explain intended functions; they are not physical-test evidence.

## Layout choice

Initial side-column and side-panel proposals clipped annotation text or circuit
symbols at A4 boundaries. Those proposals were rejected. Their actual native
previews and rendered views are retained and identified in `layout-review.json`.
Paired guide pages preserve space for circuits and readable prose. Guide pages
use native schematic rectangles and text; imported definitions/models and
manufacturing constraints are not patched.

`ComponentNotes.tsx` holds the reference-specific descriptions, guide-page
metadata, diagram cross-references and native guide rendering. The board entry
remains declarative. Existing React is used for keyed fragments; the package
collector recognizes that dependency without changing the original lockfile
or dependency pins.

## Verification

Final native render, source snapshots, physical/electrical comparison, annotation
coverage/schema checks, rendered pages, configured checks and public readback
have separate command outcomes and receipts here. A passing annotation check
does not imply that the existing board's complete routing/fabrication gates pass.

## Accepted build and visual evidence

The fresh publication runtime installed all 303 packages with the original
frozen lockfile. Its supported native command
`tsci build index.circuit.tsx --pcb-png --pcb-svgs --schematic-svgs`
completed in 249.96 seconds and exited 1 on the existing 90 native open-port
errors. This completed build, not the preliminary RootCircuit capture, provides
`final-native/circuit.json` and the byte-identical committed canonical output.
SHA-256: `8a68235d7b446165de53665adb2e53ca971e7e179969c2eb07c1e1185b140042`.
Source snapshots and `cli-runtime-inputs.json` identify the exact inputs.

The final annotation audit passes: all 135 references have exactly one purpose
on the appropriate A4 guide, all 13 diagram cross-references exist, and all new
annotation elements satisfy the installed native schema. Every PCB/copper/CAD
record, source net/port and imported purchased component is unchanged.
The supported CLI adds empty supplier maps to 10 native test pads and replaces
project metadata with its source-filesystem hash; neither changes circuitry.
Ten retained missing-manufacturer warnings differ only in internal instance
serials. These differences are explicitly checked and retained in the actual
native JSON; no native records are edited or removed.

All 135 schematic components, 479 ports, 328 traces and 149 net labels are
record-for-record identical to the parent board. The 336-file parent checkpoint
has only 16 changed existing entries, covering the version, source annotations
and generated JSON. The original dependency pins/lockfile, JLCPCB imports,
manufacturer models and routing artifacts are unchanged.

All 26 pages were rendered and inspected. The final 13 guides and 12 circuit
pages have exactly the same SVG drawing elements as the reviewed preliminary
pages; the CLI only omits the producer metadata attribute. The microphone
caption was moved from -11.82 to -10.5 to keep the top VMIC labels inside A4.
That corrected page and the largest display guide were inspected separately.
Actual final SVG/PNG pages are in `accepted-views/`; detailed comparisons are in
`accepted-visual-review.json`. Rejected previews remain separately identified.

Configured formatting and final TypeScript checks pass. The supported CLI's
schematic-only snapshot update uses the accepted native JSON and produces the
same `index.circuit-schematic.snap.svg` baseline name. The complete 26-page
stacked schematic baseline was accepted for this visible documentation change;
the PCB baseline is unchanged. The required source-entry snapshot and final
board test outcomes are recorded separately below after they complete.

## Final checks and remaining blockers

- Configured formatting: passed, 98 files. TypeScript: passed, 13.06 seconds.
- Full source-entry `tsci snapshot index.circuit.tsx`: budget stopped after
  370.45 seconds (360-second bound plus termination grace), peak14.80GB;
  no completed/pass result. Two regenerated phase artifacts are retained under
  `source-snapshot-trial/` and rejected; original checkpoint bytes were restored.
  The unchanged native output from the completed build remains canonical.
- Supported `tsci snapshot index.circuit.json` on the exact accepted CLI native
  bytes: completed in7.52seconds. The reviewed 26-page schematic reference
  passes; the unchanged original PCB reference reports its prior mismatch.
  This separate native-input result does not turn the source timeout into a pass.
- Configured board tests:47passed/3failed. Two existing schema/fabrication gates
  fail. The placement-preservation fixture additionally differs only because
  the native CLI adds empty supplier maps to10test pads; the dedicated strict
  comparison verifies every remaining component field and all physical records.
  No existing tests or criteria were changed to hide this mismatch.
- Full current native strict-schema audit:169failures, exactly the retained
  types:15schematic groups,135PCB components,15PCB groups,2silkscreen texts and
  2holes. New guide annotations pass individually; whole-board schema does not.
- Prior independent geometry/width results remain applicable because all PCB
  records are exactly equal:0measured shorts/clearance violations,26open nets,
  90native open-port errors,35GND islands,2explicit width and55nominal-width
  branches still requiring qualification.32missing pill paste apertures and
  unsupported polygon Gerber export remain unresolved.

The source-entry snapshot timeout and unchanged fabrication failures remain
explicit. Documentation/coverage validation passes; complete board validation
and ordering remain blocked. No imported part/model, source connection, copper
geometry, test criterion or native error has been edited to obtain a pass.
Native events are archived losslessly with every original byte verified before
removing uncompressed duplicates; they are evidence, not replacement route caches.

## Public publication

Accepted implementation source is public GitHub commit
[`81c066f`](https://github.com/AnasSarkiz/tscircuit-ai-agent-remote/commit/81c066f8044f98c4d25e685a65edb3bc792affcb).
Anonymous raw readback verifies the exact native JSON, ComponentNotes, board
entry and declarative main against local bytes. The public repository visibility
receipt is retained separately.

Public tscircuit version
[`0.0.4-wip-schematic-notes`](https://tscircuit.com/AnasSarkiz/tscircuit-ai-agent-remote/releases/7fe00b28-1971-41f3-b4e5-c327c6b6b3e0/preview)
(release7fe00b28-1971-41f3-b4e5-c327c6b6b3e0) is the latest public listed release.
All120staged runtime files match anonymous remote byte hashes, with no missing
or extra files, and ready_to_build=true. Its native preview discovers
index.circuit.tsx and matches the complete accepted native JSON object, including
all26A4sheets. Its public preview page responds HTTP200. No browser thumbnail
or successful cloud CI result is inferred from that HTTP response.

The native publisher initially encountered HTTP413 and reported three fallback
file failures. Anonymous readback found118/120matching files and only two
actually missing; the TPS63802 model had already persisted. The supported
multipart archive helper uploaded the exact missing native JSON and AFC07 model
in one byte-verified2,144,942-byte archive, with no native/model modifications,
full repush, duplicate version or readiness override. Fresh anonymous readback
then confirmed120/120exact files. Large raw CLI error payloads are retained in
/tmp with a hash receipt; only diagnostic status lines and command outcomes are
committed. Full schema diagnostics are preserved in a lossless gzip archive,
with every original byte verified and a separate restore/hash receipt.

The registry automatically scheduled cloud build
6873fe90-66f8-45be-8122-3a5fd15e15b9. Its observed status is retained separately;
no duplicate build was requested. Publication/annotation validation is complete;
whole-board fabrication and hardware qualification remain blocked.

The80-second bounded observation finished while the automatic cloud job remained
in progress, with no completed result or error. This observation deadline neither
cancels the job nor means it passed/failed. Its logs/status remain recorded in
cloud-build-observation.json; successful remote CI is not claimed. Local native
build completion, exact publication bytes and preview discovery are verified
independently. No further cloud build was queued.

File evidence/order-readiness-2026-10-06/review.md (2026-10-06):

# Current board order-readiness review — 2026-10-06

**NOT READY TO ORDER.** The board does not satisfy zero DRC and complete
connectivity. Passing clearance checks alone does not establish a working board.

Reviewed source parent: `999001f04798250e75e5508fd21d38cf22461cbb`.
The fresh native render completed in 190.24 seconds and is byte-identical to
`dist/index/circuit.json`: SHA256
`81c31f77ac0871bfc4414b0940752e4f4fe0692a62089320b409908d4a8d5315`.
Board: 50 × 65 × 1.0 mm, four layers; top population. Pipeline9 remains selected.
This review adds verification tooling/evidence, not new copper or a new routing
completion claim. Imported parts, saved routes, board inputs and dependencies
remain unchanged.

## Physical copper and connections

Independent exact supported pad/drill/wire/BREP geometry measurement reports:

| Check | Actual result | Qualification |
|---|---:|---|
| Measured shorts | 0 | Pass within audited geometry |
| Measured clearance/geometry violations | 0 | Pass within audited geometry |
| Merged named nets | 0 | Pass |
| Physically disconnected nets | 26 | **Fail** |
| Native unconnected-port errors | 90, including 46 J7 errors | **Fail** |
| Ordinary vias | 250, 0.70 mm copper / 0.30 mm drill, full four-layer span | Geometry passes |
| Required overall zero-DRC, zero-shorts, connected gate | false | **Fail** |

Minimum measured ordinary via drill-to-pad clearance is 0.200001194 mm
(requirement 0.20 mm, including same-net cases). Copper pad-to-trace minimum is
0.200075098 mm (requirement 0.20 mm). These nominal geometry checks do not
qualify manufacturing tolerances or current/impedance. Every pad-to-net island is
retained in [copper-audit.json](copper-audit.json) and the current
[496-pin table](pin-assignments.csv). Error markers are not used as a substitute
for actual physical copper contact. J3's two unassigned outer battery contacts
are **additional omissions**, absent from the 26/90 counts.

Disconnected nets and physically separate copper groups:

| Net | Islands |
|---|---:|
| GND | 35 |
| MCU_LCD_RESET_N | 2 |
| USB_DN | 4 |
| USB_DP | 4 |
| VBUS | 4 |
| PACK_BAT | 2 |
| VSYS | 5 |
| VLCD | 8 |
| LCD_SDA | 3 |
| LCD_SCLK | 3 |
| LCD_DC | 3 |
| LCD_RESET_N | 2 |
| LCD_CS_N | 2 |
| LCD_BACKLIGHT_RETURN_4 | 2 |
| LCD_BACKLIGHT_RETURN_3 | 2 |
| LCD_BACKLIGHT_RETURN_2 | 2 |
| LCD_BACKLIGHT_RETURN_1 | 2 |
| LCD_BACKLIGHT_OUTPUT | 2 |
| AMP_SD_MODE | 2 |
| SPEAKER_P | 2 |
| SPEAKER_N | 2 |
| AUDIO_ENABLE_SUPPLY | 2 |
| VMIC | 5 |
| MIC_WS | 2 |
| MIC_BCLK | 3 |
| MIC_SD | 2 |

The missing USB, battery/system power, display, speaker and microphone paths
prevent approval of their real operation. A correct logical net assignment does
not connect these separate copper islands.

## Every trace width

[trace-widths.csv](trace-widths.csv) lists **all 306 native traces**.
[trace-widths.json](trace-widths.json) measures **all 792 actual wire segments**,
including segment lengths, layers, coordinates, source minima and named-net
nominal widths. Native constant-mode segment widths use the starting route
point, verified against the installed renderer; widths were not inferred solely
from board settings. Missing named-net width settings are disclosed rather than
assigned an invented requirement.

- No segment is below the general 0.20 mm board minimum.
- **Two regulator switching traces fall below their explicit 1.0 mm source
  minimum.** `saved_phase_null_0_0` (U2.pin7→L1.pin2) and
  `saved_phase_null_0_1` (U2.pin9→L1.pin1) each have approximately 0.75 mm of
  0.275 mm width, then 0.4/0.7 mm sections before widening to 1.0 mm.
  Existing pad escapes cannot be accepted as rated switching-current paths
  merely because the 1.0 mm section exists. They require proper current,
  switching-loop and layout qualification or a qualified redesign.
- **55 other traces fall below their named net's nominal width.** They meet
  their explicitly authored branch minimum where present. Many are authored
  short pad escapes, but the nominal/actual differences remain review items;
  this audit does not convert them into approved thermal exceptions.
- All **152 authored copper regions** preserve their required strip widths in
  actual native BREP copper, excluding drilled apertures. This is independently
  measured in [region-widths.json](region-widths.json).

| Named net | Nominal width (mm) | Smallest actual trace width (mm) | Traces below net nominal |
|---|---:|---:|---:|
| VSYS | 1.0 | 0.275 | 15 |
| V3V3 | 0.8 | 0.275 | 24 |
| PACK_BAT | 1.0 | 0.3 | 4 |
| VBUS | 0.5 | 0.3 | 2 |
| HAPTIC_N | 0.4 | 0.3 | 4 |
| GND | 0.3 | 0.2 | 6 |

**Trace-width suitability for the real load is not approved.** The load/peak
current budget, guaranteed copper/barrel thickness, enclosure temperature,
voltage-drop/temperature-rise and narrow-section limits remain unqualified.
The historical IPC-2221 screening study uses an earlier provisional stackup and
cannot qualify the current 1.0 mm board. USB's existing 0.2979 mm sections are
not evidence of a complete differential pair; USB_DN/DP remain disconnected.
Speaker paths, return geometry and final stackup/impedance need qualification.

## Components and real pin assignments

Fresh [component inventory](component-inventory.json): **125 purchased PCB
parts /43 exact JLCPCB identities plus10 native pads**, all on top. Exact MPNs,
supplier codes, placement, pad shapes and paste omissions are recorded.
New current-whole-board manufacturer regression checks pass for MCU
power/USB/reset/boot and reserved PSRAM pins, BQ24074 charger, TPS3808 supervisor,
TPS63802 power/feedback/switch pin identities, MAX98357A supply/speaker polarity,
and dual ICS-43434 microphone supply/data/clock/channel selection. The existing
current-board display/backlight logical tests remain part of the canonical suite.
These reapply the stored manufacturer requirements; they do not stand in for a
fresh vendor stock check, complete datasheet review, physical assembly or runtime
hardware testing.

**Unqualified external connections:**

- J3/C157929 and AKY2945/LP523450 pack: centre pin2 is PACK_NTC, consistent with
  the supplier's yellow centre10kNTC wire. The exact pack drawing does not number
  the keyed BAT+/GND outer contacts, so J3.pin1/3 remain unassigned/unrouted.
  Generic JST numbering does not establish this particular pack's polarity.
  [Stored supplier drawing review](../a6-bom-routing-2026-10-04/mechanical-search.md).
- J7/C262650 and ER-TFT026-1: current logical panel-pin mapping is provisional.
  Exact current-revision contact face, pin1 direction, fold and mating orientation
  remain unqualified. The historical drawing cannot qualify the current flex.
  Thus logical pin-map tests do not approve the physical display connection.
- Speaker/motor harness strain relief, PH connector pin tails, acoustic/RF
  clearance and actual enclosure fit remain pending. The latest accepted
  enclosure maximum is60 ×75 ×16 mm, superseding older15 mm references.

## Fabrication and assembly

| Check | Actual result |
|---|---|
| Full installed Circuit JSON schema | **169 failing elements**:135 pcb_component,15 pcb_group,15 schematic_group,2 pcb_silkscreen_text,2 pcb_hole |
| Native paste on purchased pads | **32 missing**:16 pill pads each on U16/BQ24074/C54313 and U27/TPS60230/C1848364 |
| Official BOM converter | 125 rows; **31 blank Comment fields**,125 supplier-code footprint fields |
| Official JLC supplier placement conversion | 125 top-side rows; **125 missing supplier pin1 metadata warnings**; strict rotation conversion rejects U1 |
| Current whole-BOM stock | Not refreshed; earlier dated stock receipts are historical |
| Stackup, mask/stencil, enclosure/harness and assembler approval | Not qualified |

Exact official converter outputs are named **NOT-FOR-FABRICATION** and are not
an approved assembly package. All supplier rotation warnings and the strict
failure are retained in [assembly-export-audit.json](assembly-export-audit.json).
A missing supplier orientation field is a qualification failure; it does not by
itself prove that125 actual footprints are rotated incorrectly.
Imported definitions were not patched to manufacture paste/schema/orientation
success. Component/import-generator failures remain blocking instead.
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

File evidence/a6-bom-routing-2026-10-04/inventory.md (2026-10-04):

# A6 active native inventory — 2026-10-04

125 purchased PCB parts, 43 supplier identities and 10 native pads. External screen/pack/speaker/motor are not JLC PCB population. Fresh availability below covers changed resistors only; the previous dated whole-BOM audit remains historical and must be refreshed before ordering.

| Part | Quantity | References |
|---|---:|---|
| C105188 | 1 | U7 |
| C105580 | 2 | R33, R34 |
| C105881 | 2 | R92, R93 |
| C107701 | 5 | R31, R32, R65, R66, R67 |
| C114622 | 2 | R96, R97 |
| C114639 | 1 | R6 |
| C126358 | 2 | R1, R2 |
| C14675 | 13 | R37, R3, R4, R7, R40, R47, R48, R49, R50, R51, R85, R87, R26 |
| C15127 | 1 | Q2 |
| C157929 | 1 | J3 |
| C15849 | 2 | C82, C83 |
| C160405 | 1 | J6 |
| C165948 | 1 | J1 |
| C173752 | 1 | J4 |
| C1848364 | 1 | U27 |
| C19666 | 1 | C1 |
| C20917 | 2 | Q1, Q9 |
| C21190 | 8 | R38, R41, R62, R64, R82, R86, R100, R27 |
| C22775 | 6 | R60, R63, R83, R88, R89, R103 |
| C24478 | 1 | U24 |
| C2480 | 1 | D3 |
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

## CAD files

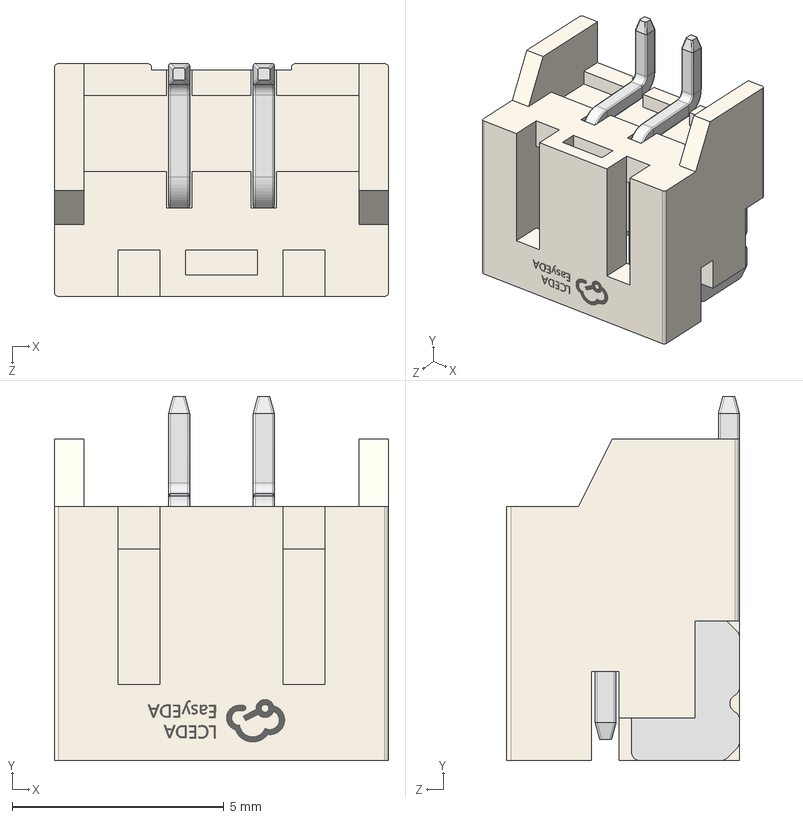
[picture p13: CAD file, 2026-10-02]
evidence/update-check-2026-10-03/fresh-import/imports/S2B_PH_SM4_TB_LF__SN_/S2B_PH_SM4_TB_LF__SN_.step
7.90 x 8.60 x 5.50 mm

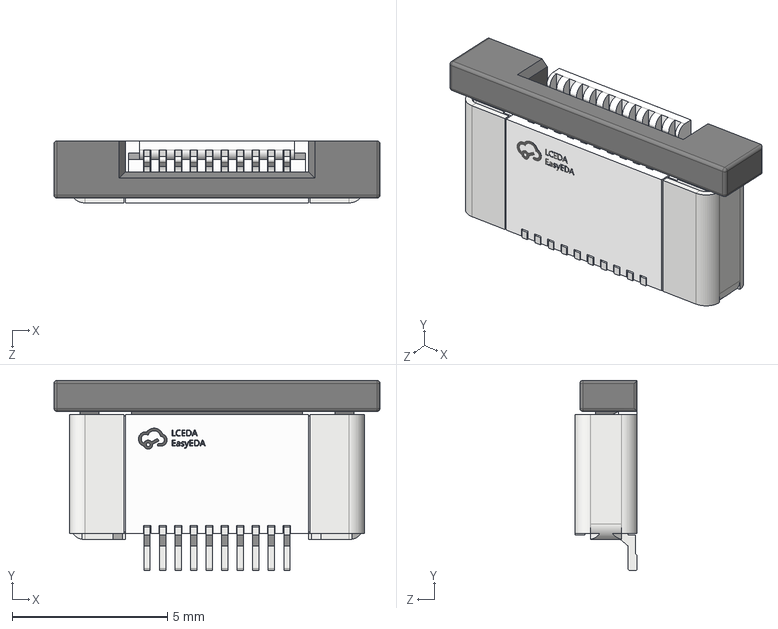
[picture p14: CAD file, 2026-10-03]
imports/AFC07_S10FCC_00/AFC07_S10FCC_00.step
10.5 x 6.13 x 2.01 mm

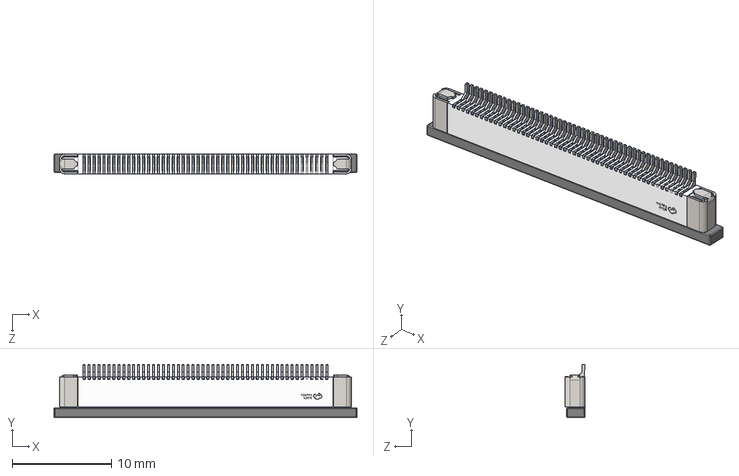
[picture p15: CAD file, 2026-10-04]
imports/AFC07_S50FCC_00/AFC07_S50FCC_00.step
30.6 x 5.40 x 2.01 mm

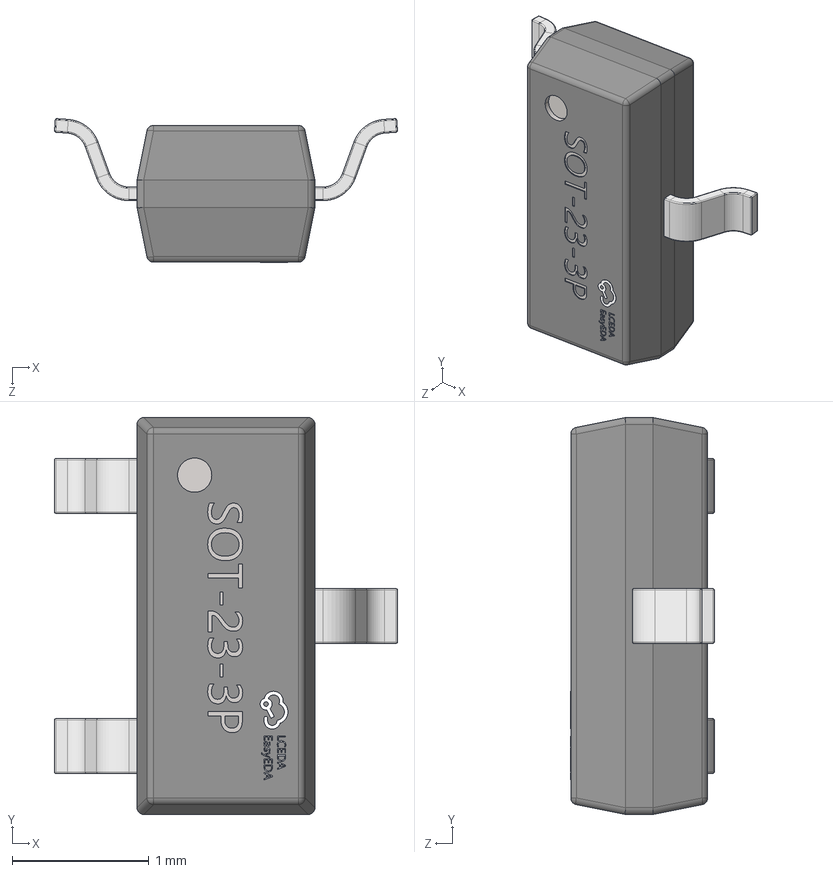
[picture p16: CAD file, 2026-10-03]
imports/AO3400A/AO3400A.step
2.51 x 2.90 x 1.05 mm

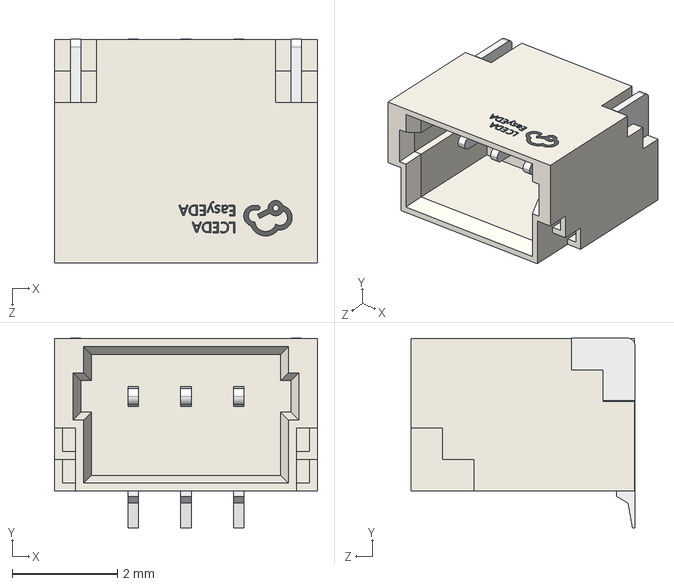
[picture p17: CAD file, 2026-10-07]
imports/BM03B_SRSS_TB_LF__SN_/BM03B_SRSS_TB_LF__SN_.step
5.00 x 3.61 x 4.26 mm

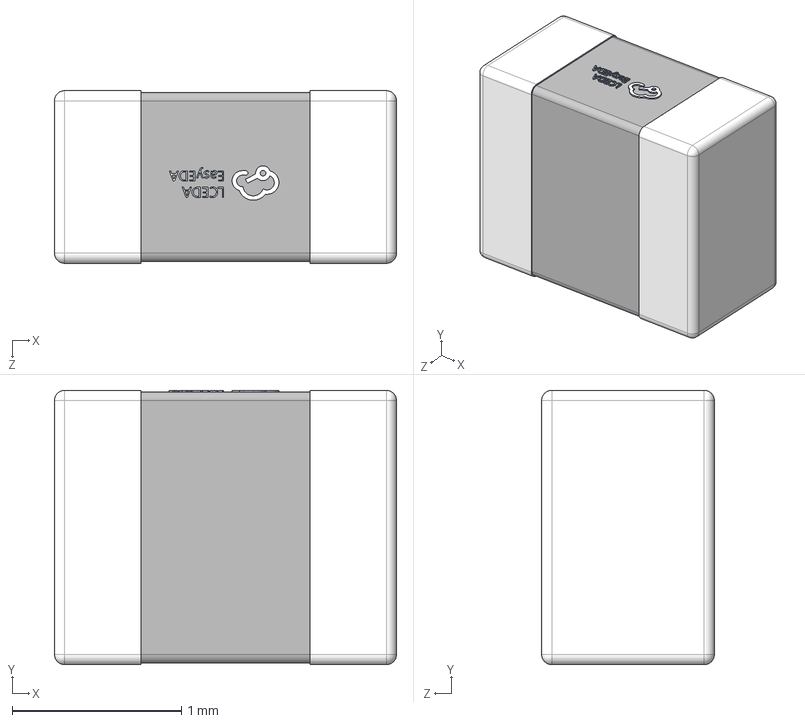
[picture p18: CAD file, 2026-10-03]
imports/CIGT201610EHR47MNE/CIGT201610EHR47MNE.step
2.02 x 1.62 x 1.02 mm

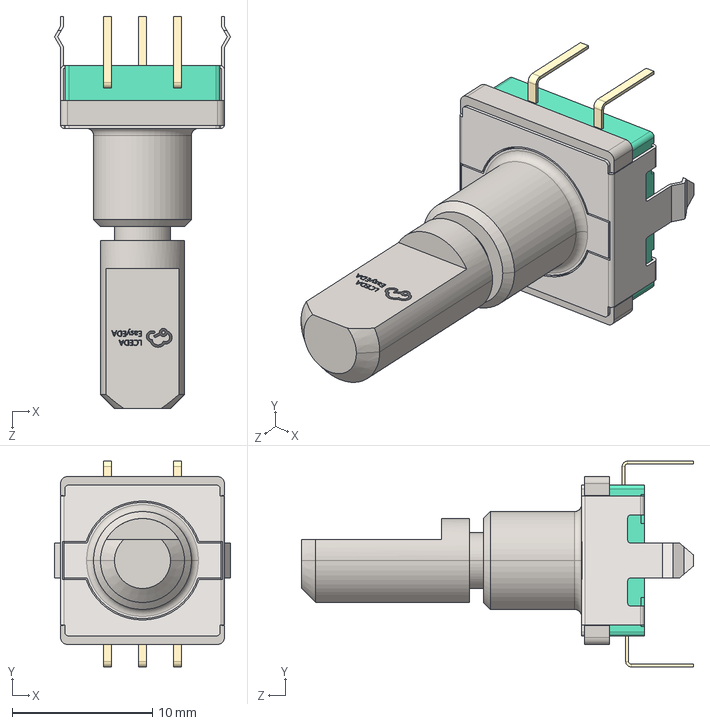
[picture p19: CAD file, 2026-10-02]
imports/EC11E15244G1/EC11E15244G1.step
12.6 x 14.7 x 28.0 mm

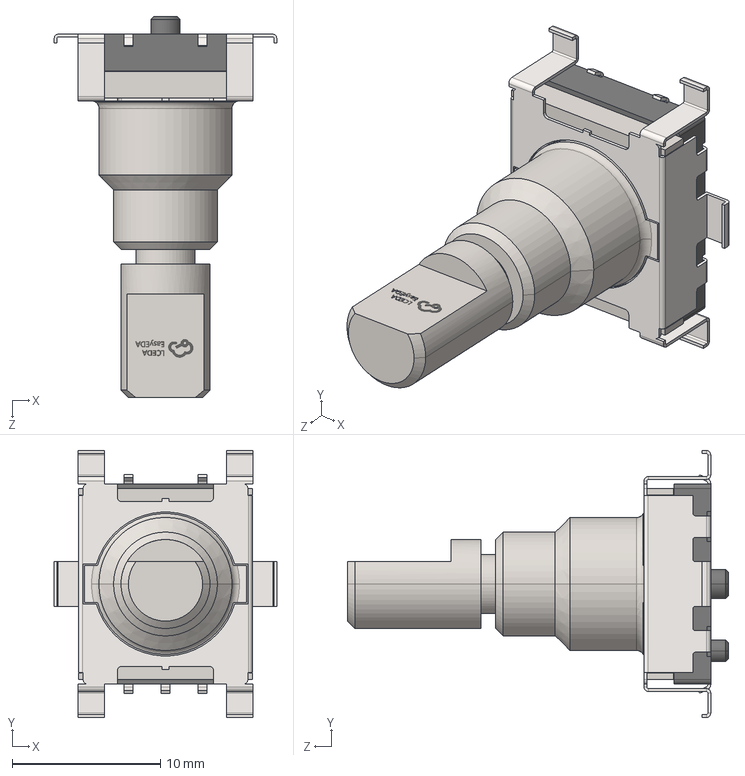
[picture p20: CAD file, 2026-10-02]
imports/EC11J1525402/EC11J1525402.step
15.0 x 18.0 x 25.7 mm

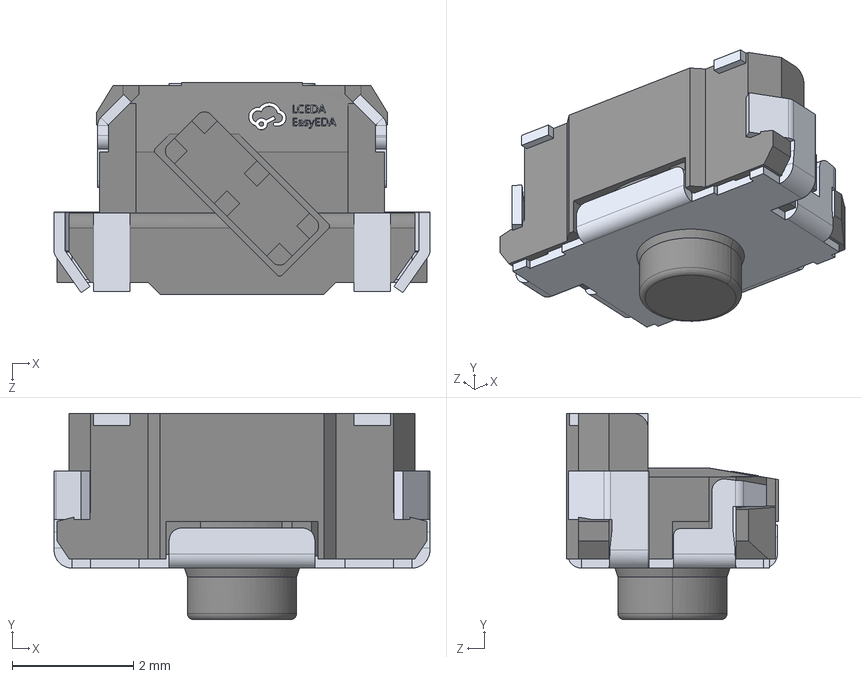
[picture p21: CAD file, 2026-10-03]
imports/EVQ_P4HB3B/EVQ_P4HB3B.step
6.20 x 3.40 x 3.50 mm

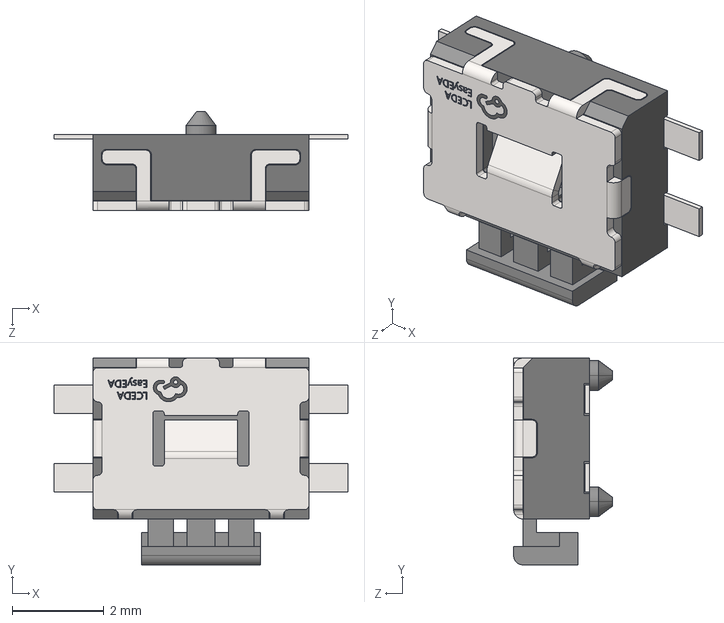
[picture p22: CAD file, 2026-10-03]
imports/EVQPUC02K/EVQPUC02K.step
6.40 x 4.50 x 2.15 mm

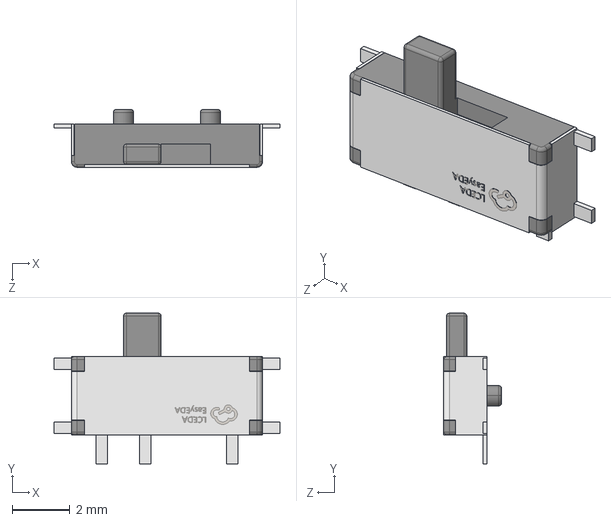
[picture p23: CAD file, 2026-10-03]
imports/MSK12C02/MSK12C02.step
7.80 x 5.20 x 2.01 mm

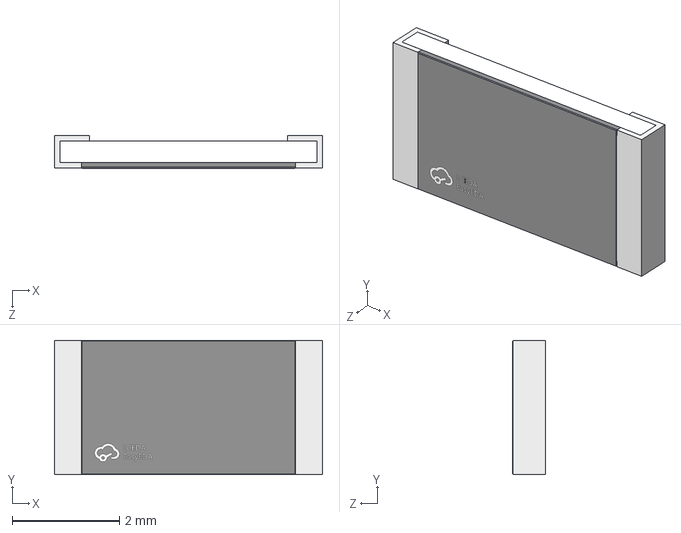
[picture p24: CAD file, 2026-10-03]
imports/RC2010JK_07510KL/RC2010JK_07510KL.step
5.00 x 2.50 x 0.611 mm

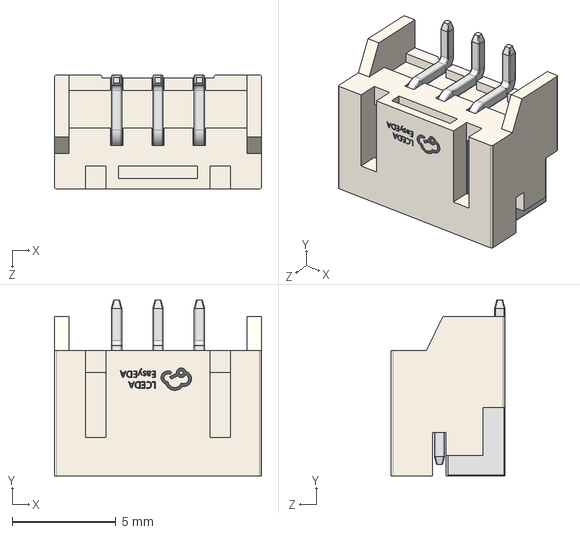
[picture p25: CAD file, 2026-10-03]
imports/S3B_PH_SM4_TB_LF__SN_/S3B_PH_SM4_TB_LF__SN_.step
10.0 x 8.50 x 5.50 mm

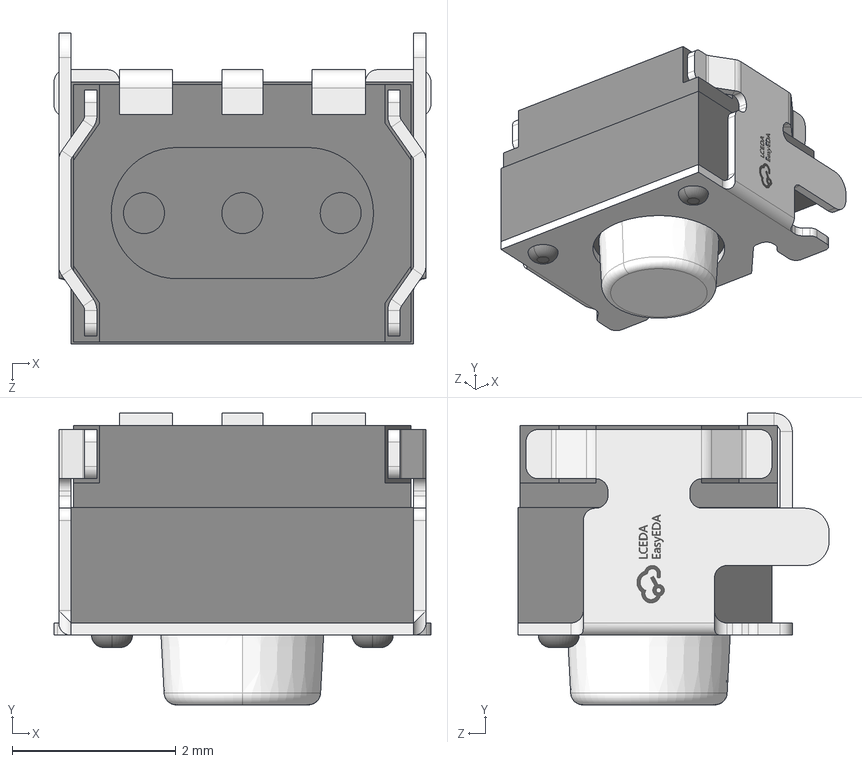
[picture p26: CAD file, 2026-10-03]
imports/SKRTLAE010/SKRTLAE010.step
4.60 x 3.56 x 3.80 mm

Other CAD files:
imports/SKSWCFE010/SKSWCFE010.step
imports/SM06B_SRSS_TB_LF__SN_/SM06B_SRSS_TB_LF__SN_.step
evidence/haptic-review-2026-10-03/C2942347-native-model.obj
evidence/update-check-2026-10-03/fresh-import/imports/S2B_PH_SM4_TB_LF__SN_/S2B_PH_SM4_TB_LF__SN_.obj
imports/AFC07_S10FCC_00/AFC07_S10FCC_00.obj
imports/AFC07_S50FCC_00/AFC07_S50FCC_00.obj
imports/AO3400A/AO3400A.obj
imports/AO3401A/AO3401A.obj
imports/BM03B_SRSS_TB_LF__SN_/BM03B_SRSS_TB_LF__SN_.obj
imports/CIGT201610EHR47MNE/CIGT201610EHR47MNE.obj
imports/DFE201612E_R47M_P2/DFE201612E_R47M_P2.obj
imports/DFE201612E_R47M_P2/DFE201612E_R47M_P2.step
imports/EC11E15244G1/EC11E15244G1.obj
imports/EC11J1525402/EC11J1525402.obj
imports/EVQPUC02K/EVQPUC02K.obj
imports/EVQ_P4HB3B/EVQ_P4HB3B.obj
imports/MSK12C02/MSK12C02.obj
imports/RC2010JK_07510KL/RC2010JK_07510KL.obj
imports/S2B_PH_SM4_TB_LF__SN_/S2B_PH_SM4_TB_LF__SN_.obj
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

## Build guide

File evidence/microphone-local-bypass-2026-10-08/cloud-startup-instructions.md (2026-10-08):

Current continuation priority (2026-10-08): public WIP 0.0.10-wip-microphone-bypass, implementation commit 3d88ca2fe4d617de73e757aec6522ba3d79c4a3a, native SHA-256 8be25ca28e6271890aab0d450ffdc62088ced91967ae1b6185ab8267ff9f1177; release d17c1129-2a2a-4834-a186-e562b77aa268. Read evidence/microphone-local-bypass-2026-10-08/review.md and exact public/native receipts first, then AGENTS.md, CLOUD_HANDOFF.md and checkpoint/user-decision files. Genuine C81/R93 rigid moves now provide actual 1.442790mm supply and .599976mm ground top-layer .30mm U5 bypass, no bypass via. All 9,813 prior contacts preserved; 123 stationary purchased geometries and 244 genuine asset/solver files unchanged. All 128 public package files and preview native are verified. Full-board gates remain failed: 50 J7/U27 errors / 12 assigned physical open nets plus two unassigned J3 outer contacts; 169 installed-schema failures, 15 actual UI style issues, 32 native paste omissions, two explicit width minima and paste/export/rotation/stock/mechanical qualification. Requested centered ~2.8-inch landscape LCD is unimplemented: verify exact folded flex/contact/pin1/minimum bend/RF clearance and common-cathode backlight before final J7 layout or wiring. Never guess contacts or suppress failures. Current official stock confirms 12/43 identities covering one board; U1/D2 zero public buyability and 29 HTTP503 unknown results. Previous $26.3055 subtotal is a dated reference, not an order quote. Previous .9 cloud source job has now actually completed without a user-code job error; this does not qualify DRC or fabrication. New .10 cloud source job remains a separate observation. Official core .2110 still lacks the tested canonical paste fix; active validated runtime stays frozen, no local package links/import/model/cache/JSON edits. Use Bun1.3.9, scripts/cloud/env.sh and one budgeted heavy Linux operation at a time. For source rebuilds run bun run publish:prepare, link .publish/board/node_modules to ../../node_modules, then python3 evidence/microphone-local-bypass-2026-10-08/restore-supplier-orientation.py .publish/board /tmp/restored-board-supplier-orientation.json. Those 43 inputs are exact prior official pin-one analyses, not fabricated solver data or current stock. Preserve actual source/native/events before changes; clean stage with publish:prepare before publication. Standing authorization covers public own main/tsci WIP pushes, not orders/upstream merges/other-chat messages/subagents. Saved draft preserves installation, repositories, requirements, presets and all 20 custom hosts; draft saving does not apply or publish configuration and does not prove fresh restoration.

Earlier saved instructions below are historical where superseded:

Current continuation priority (2026-10-07): public board WIP 0.0.9-wip-standard-uart, native SHA-256 bcee32a49486610d7379583efb2b378846cc75f232272b50c717ad129c495704; release f520e705-7b21-4a06-89d2-a66b70ced491. Read evidence/programmer-direct-uart-2026-10-07/review.md and its exact public receipts first, then AGENTS.md, CLOUD_HANDOFF.md and current context/checkpoint files. The genuine C160389 J6 direct SH3 UART, ground links, audio clearance detour and 0.8 mm bottom V3V3 bypass are implemented. All 128 public package files and preview native are byte/object verified. Board still has 50 J7/U27 errors / 12 open nets, 169 schema failures, 15 actual UI style issues and paste/export/width/stock/mechanical gates; no fabrication or hardware-test approval. Requested centered ~2.8-inch landscape LCD remains unimplemented: A2 candidate has RF overlap, unqualified folded flex/contact/bend/latch geometry and opposite common-cathode backlight topology; do not reuse the superseded 2.3-inch poses or guess J3 outer battery contacts. Latest official core 0.0.2108 still lacks the tested canonical paste fix; keep frozen validated dependencies and no active local package links. Use Bun 1.3.9 and scripts/cloud/env.sh; one heavy Linux cloud operation through run_with_budget.py at a time. For source builds use publish:prepare, link .publish/board/node_modules to the frozen root dependencies as in the completed run, preserve actual generated native/source/events, then remove that link before publishing. Never patch imports/generated JSON/installed bundles or weaken gates. Standing authorization covers public board main/tsci WIP pushes, not orders/upstream merges/other-chat messages. Saved network draft preserves 20 custom hosts; saving does not apply/publish it and does not prove fresh restoration.

Earlier setup and continuation instructions are retained below:

Continue the actual AI remote PCB in /workspace/tscircuit-ai-agent-remote; do not create another worktree or replacement board. Read AGENTS.md, CLOUD_HANDOFF.md, context/user-decisions.md and context/build-checkpoint.json, then apply the local tscircuit skill and current official handbook. Use bash scripts/cloud/setup.sh for frozen setup and source scripts/cloud/env.sh for each shell. Run one heavy operation at a time through scripts/cloud/run_with_budget.py. Latest human request replaces the unfinished ER-TFT023-1 plan with a BuyDisplay approximately 2.8-inch LANDSCAPE LCD, preferably ER-TFT028A3-4 or an exact-datasheet-qualified close variant. PCB remains approximately50x65mm and front face approximately60x75mm; these can be viewed as65x50/75x60 in the finished landscape orientation. Display flex must exit LEFT or RIGHT in the finished device, never top/bottom. Verify exact manufacturer body/active area/FPC/pitch/thickness/contact face/pin1 before changing PCB; no guessed dimensions, folded mating or bend radius. Move J7 and interfering components only after verified mechanical/antenna fit; update schematic and backlight for exact pins, then actual routes/connectivity/fullDRC. The old unaccepted2.3-inch staged source is preserved separately and restored from public HEAD; do not treat its zero-overlap proposal as accepted placement. Read evidence/display028-integration-2026-10-07/review.md before any continuation. An accessible primary manufacturer PDF mirror for ER-TFT028A2-4 confirms69.3x50.2mm landscape body,57.6x43.2mm active area,ILI9341,50pins/.5mm,common-cathode backlight and26.7mm flex extension. It is a candidate only: current antenna overlap and mating/minimum-bend qualification are unresolved. Preserve the exact accepted native circuit SHA35c5fb2bfc870daf11b5f5e30847f1e5a86fd886ebb8ef11fc3cf6e88e77e63d, saved caches and9842 prior connected terminal pairs. Explicit manual native copper is authorized, labelled manual; no fabricated solver cache or patched circuit.json. Canonical C7848 exact re-import with --download now fixes pin-1 metadata, downloads byte-identical genuine OBJ/STEP assets and preserves the original model origin. Its canonical coupon has 20 pill pads with zero native paste records, so the replacement is not applied to the active board. Earlier 16-byte Domain forbidden downloads and the no-download 4.05mm origin are rejected trials. See evidence/display028-integration-2026-10-07/u14-canonical-import/qualification.json; do not hand-patch the import or claim stencil qualification. Genuine component imports must not be hand-edited. J3 outer numbered polarity, J6 stock, schema/paste/Gerber and actual connectivity/fabrication gates remain documented. No order, upstream merge, watcher, subagents or other-chat messages. Public GitHub main and matching tscircuit WIP updates remain authorized; verify exact anonymous source/native bytes after completed implementation. Chromium may use the previously approved proxy CA; retain TLS verification and inherited proxy. Actual BuyDisplay challenge also requests brunhild.challenges.cloudflare.com; modelcdn currently responds, while the saved wildcard challenge access remains pending runtime application. Do not automate CAPTCHA or bypass proxy policy. Saving a configuration draft does not apply it or publish an environment.

Latest independent source fix: read evidence/core-pill-paste-fix-2026-10-07/review.md. A canonical SmtPad pill/rotated_pill paste patch is implemented against official core source commit90785dbb91162d8ff7a25dbad6533929d8546f4c (package0.0.2106). Use the upstream CI Bun1.4.0 for that checkout; the older preserved Bun1.3.9 install stalled, while current-source Bun1.4.0 with network-concurrency4 completed. Seventeen relevant tests, full TypeScript, formatting, build and dist smoke pass. Genuine C7848 coupon has20 valid paste records and identical physical pads; unmodified U16/U27 coupons have34 valid paste records. Yalc links were removed and official packages restored; official0.0.2106 still reproduces zero U14 paste. This is a tested source fix, not a released board runtime fix. Active board remains frozen officialcore0.0.2090 and exact nativeSHA35c5fb2bfc870daf11b5f5e30847f1e5a86fd886ebb8ef11fc3cf6e88e77e63d. Never deploy local yalc links or claim the board's missing32 paste records are solved. A supported released generator fix and full board requalification remain necessary. Saved custom host list now also includes pkg.pr.new (20 hosts); saving still does not apply runtime settings.

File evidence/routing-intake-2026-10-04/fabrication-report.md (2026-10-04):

# A2 fabrication checkpoint — 2026-10-04

**NOT FABRICATION READY**

This continues the existing handheld AI remote. It uses a dominant front display, one hold-to-talk button, a side hardware privacy switch, ESP32-S3 Wi-Fi/BLE/USB, two digital microphones, an I2S speaker amplifier, external speaker and haptic connections, rechargeable 1S power and top-side assembly. Firmware and physical testing are not completed.

The human confirmed the exact AKY2945 harness as red BAT+, yellow 10 kΩ NTC, black GND. Yellow is the physical centre contact. The outer contacts are not numbered in the drawing. J3 pin 2 is now PACK_NTC; J3 pins 1 and 3 have no source connections and remain unrouted. Documentation reads **outer — NTC — outer**, with both red/black outer assignments **PENDING PIN-NUMBER CONFIRMATION**. Written supplier confirmation or a keyed physical pack/multimeter measurement must establish the outer numbering. These contacts are unresolved required connections, not final intentional NCs. Mechanical anchors remain grounded.

## Board and current build

| Item | Actual result |
|---|---|
| Outline | 50 × 65 mm, nominal 3 mm rounded corners; exported coordinate extrema X ±25, Y ±32.5 mm |
| Stack | Four layers, nominal 1.6 mm; proposed JLC04161H-7628 stack, not a completed impedance order |
| Population | 122 purchased PCB parts plus 8 native copper test points; 130 PCB component records, all top |
| Schematic | 13 native A4 sheets |
| Routed traces / vias | 0 / 0; routing disabled |
| Routed trace length | 0 mm; no routed connection validation exists |
| Native error records | 0 in the current unrouted JSON |
| Placement DRC | 0 errors, 3 preserved connector orientation warnings |
| Full native schema | 162 failing records: 130 components, 15 PCB groups, 15 schematic groups, 2 standalone mounting holes |
| Tests | 35 pass / 1 existing strict-schema failure, 319 assertions |
| Required unrouted count | Completion count not evaluated; all intended inter-component connections lack routed copper. 388 source-trace records are logical declarations, not a count of physical routes |
| Shorts | Unrouted diagnostic only; cannot establish zero shorts for a future routed board |

Current native Circuit JSON SHA-256: `fbf9e2b576a9e37f695e894d9458500c33d5508b052b10692dcf99bc474dcd3f`. Parent GitHub main: `420d8239ab03d360c0a837a89562ea4a1ffd86ef`. Dependencies unchanged: CLI 0.1.2235, core 0.0.2070, tscircuit 0.0.2742, easyeda 0.0.370, props 0.0.682, Circuit JSON 0.0.513.

## Completed independent changes

- Imported genuine AFC07-S12FCC-00 / C11051 unchanged and replaced the old ten-contact J7 with this twelve-contact bottom-contact FPC connector.
- Connected the HS20HS072RX drawing's contacts: 1/12 GND, 2 CS, 3 DC, 4 SCLK, 5 SDA, 6 RESET, 7 NC, 8/9 VLCD, 10 backlight anode, 11 backlight cathode. Anchors 13/14 are grounded. Display C5329582's supplier library contains a non-PCB placeholder, so it is preserved as evidence and not placed or remade as a fake screen footprint.
- Corrected J3 centre NTC and removed both unconfirmed outer assignments.
- Added two native 2.2 mm NPTH mounting trials and 6 mm all-layer circular copper keepouts. Moved the privacy switch, speaker connector and nearby passives to clear their actual native courtyards.
- Expanded the four-layer antenna keepout to cover the nominal antenna body plus 1 mm planar margin. This does not establish enclosure RF clearance.
- Updated the native LCD body outline to 36.2 × 51.8 mm and active area to 30.6 × 40.8 mm. They are PCB notes, not external assembly CAD.
- Built and inspected the unrouted PCB, ratsnest, current A4 sheet renders and native GLB board/connector views. Reviewed snapshots before updating them. GLB omits the external display/pack/speaker/motor and lacks some detailed component models; it cannot certify the complete enclosure.

## Mounting trial

Coordinates use the native PCB origin. Prefer plastic M2 hardware. Exact screw length, head/standoff envelope, enclosure wall and load/deflection qualification remain pending. A 6 mm keepout is a constraint on the eventual hardware, not evidence that any chosen screw fits.

| Mount | X / Y mm | NPTH | Keepout diameter | Hole edge to PCB edge | Minimum native courtyard gap to keepout | Nominal antenna-body distance from keepout |
|---|---|---|---|---|---|---|
| M1 | −21.5 / +6.7 | 2.2 mm | 6 mm, all four layers | 2.4 mm | 0.2501 mm to SW5 | 19.0657 mm |
| M2 | −21.5 / −29.5 | 2.2 mm | 6 mm, all four layers | 1.9 mm | 0.3266 mm to U4 | 55.2621 mm |

The nearest nominal board edges are straight segments at these points; the lower hole is near the rounded corner. The keepout-to-LCD trial envelope gaps are 0.4 / 1.2802 mm; pack trial gaps are 1.0 / 1.5894 mm. These conservative XY studies exclude real flex/cables, assembly tolerance and Z. Support against USB/TALK/switch forces is not yet proven. The diagnostic drill file explicitly declares NonPlated and contains T13C2.200000 at both coordinates. No 2.2 mm hole is in the plated drill file. Copper intrusion after routing is untested.

## Display, battery and RF prerequisites

The HS20HS072RX mechanical drawing is 36.2 × 51.8 × 2.05 ±0.05 mm, with a 12-contact 0.5 mm tail. The drawing and pin table agree on contact functions. Its text/drawing disagree on ST7789T3 versus ST7789V2 and LED topology, and one description calls it 2.4 inches. Exact supplied revision and backlight behavior need confirmation. The current 100 Ω VSYS backlight branch is unqualified for the listed 80 mA nominal backlight and low-battery brightness; no regulated-current replacement has been selected.

The connector is bottom contact; current J7 rotation 0 presents its opening in +Y and is internal. Actual screen contact-side/pin-1 orientation, 20.7 mm tail path, fold, bend radius, latch access and raised Z fit remain unqualified. The shortest planar distance to the current mouth may exceed the drawn tail extension; a real keyed assembly path is required before final J7 placement.

Exact AKY2945 maximum pack envelope is 35 × 52.5 × 5.7 mm, not just the cell size. The supplier states 1000 mAh, 1C maximum charge and 3C maximum discharge; protection thresholds, peak duration and NTC Beta remain unqualified. A conditional 10% thickness expansion gives 6.27 mm before installation clearance. The 80 mm cable exits a short edge. Availability and a final harness have not passed procurement review.

The trial LCD top at Y24.9 and pack top at Y25.25 are only 3.86 and 3.51 mm from the nominal antenna region beginning Y28.76. Espressif recommends at least 15 mm antenna clearance in all directions inside the housing and prefers the module antenna outside/cut away from the baseboard. The expanded PCB copper keepout does not resolve display/battery metal proximity, baseboard cutout or enclosure fit. Do not treat a raised display as automatic RF approval.

## Power review

All rows below **FAIL final qualification** because no actual routes exist. TBD means current allocation has not been verified, not zero current. Layer/via/width columns describe actual emitted routed copper, not desired configuration.

| Net | Expected peak current basis | Actual route width | Actual routed layer | Via count | Result |
|---|---|---|---|---:|---|
| VBUS | USB default 100 mA policy candidate; higher-current negotiation/partial-rail behavior unqualified | None | None | 0 | FAIL — current policy and route open |
| PACK_BAT | Pack capability up to 3 A; system provisional around 1.5 A, pulse/PCM limits unresolved | None | None | 0 | FAIL — outer polarity and current qualification open |
| VSYS | Approximately 1.5 A provisional combined load; actual coincident peak TBD | None | None | 0 | FAIL |
| V3V3 | ESP32/transient and peripheral allocation TBD | None | None | 0 | FAIL |
| BACKLIGHT | Datasheet nominal 80 mA; current 100 Ω branch does not establish this | None | None | 0 | FAIL |
| SPEAKER SUPPLY | 8 Ω load; output power/volume/duty and peak input current TBD | None | None | 0 | FAIL |
| HAPTIC | External motor operating/stall current and duty TBD | None | None | 0 | FAIL |

Saved TI/IPC-2221 empirical screening at a 20 °C rise yields nominal external 35 µm widths of 0.3450 mm at 1.5 A and 0.8976 mm at 3 A. Reserving −20% width tolerance gives design widths 0.4313 and 1.1220 mm, before copper-thickness/thermal qualification. For 15.2 µm inner copper the corresponding tolerance-reserved widths are 2.5836 and 6.7210 mm. This is screening, not an IPC-2152 thermal qualification or a selected final net class. Manufacturer process minima still apply. A 0.30 mm finished via with assumed 25 µm plating has 0.025525 mm² barrel area; equivalent trace area does not prove via ampacity. Plating guarantees, sharing and temperatures must be reviewed.

## Critical interfaces

| Interface | Final result | Remaining review |
|---|---|---|
| USB D+/D− | FAIL — unrouted | Pair/reference/ESD/stubs and real impedance geometry |
| Display SPI | FAIL — unrouted | Logical pin mapping corrected; FPC fit, controller revision, timing/power sequence open |
| Microphone I2S | FAIL — unrouted | Clock/SD timing, privacy ramp/off behavior, quiet returns and paste |
| Speaker I2S | FAIL — unrouted | Clock/data timing and actual amplifier supply/output return geometry |
| ESP32 antenna | FAIL — mechanical fit unqualified | Battery/display metal, 15 mm housing clearance/baseboard cutout, every copper layer |
| Charger | FAIL | BAT pin order, thermal copper, input/OUT/BAT paths, all charger paste absent |
| Buck-boost | FAIL — unrouted | Switch loops, caps, feedback/ground and actual current paths |
| Battery ADC/NTC | FAIL | Centre NTC corrected; outer polarity, NTC curve, fault/threshold behavior open |

USB D+/D− routed lengths: unavailable; mismatch unavailable; vias zero because routing is disabled. The earlier selected-stack study targets 90 Ω with L1 width 0.2906 mm/gap 0.1999 mm over L2, 0.2104 mm 7628 dielectric, εr4.4 and outer 35 µm copper. This is a conditional calculation, not measured/validated USB copper. Intended layers remain L1 components/critical signals, L2 continuous GND, L3 power/slower signals, L4 additional signals. No planes or route replay cache have been generated.

## Fabrication outputs and blockers

Native diagnostic ZIP contains four copper layers, mask/paste/silk, outline, separate PTH/NPTH drills, BOM and CPL (16 files). It is explicitly **NOT-FOR-FABRICATION**. The outline and mounting drills were checked in exported coordinates; routed copper, planes, final thermal/clearance and assembler review remain absent.

| Output | Result |
|---|---|
| Gerbers | FAIL final release — unrouted diagnostic only |
| Mounting drills | PASS limited exported 2.2 mm NPTH identity/coordinates; whole assembly/clearance not passed |
| BOM | FAIL — 122 native rows, 32 blank Comment fields; B-015 unresolved; whole BOM/lifecycle/availability/physical lands unqualified |
| CPL | FAIL — 122 top-side rows; U14 C7848 rotation 0 unverified (`incompatible_pin1_locations`) |
| Paste | FAIL — U4/U5 C5656610 each have 9 SMT pads but only 5 paste records; J1 C165948 has 12/8; U16 C54313 has 17/0, including 16 pill pads and its polygon exposed pad |
| Schema | FAIL — B-010, including standalone mounting-hole null component relation |

Official core PR4344 polygon paste support was merged and then reverted by PR4349. Manual latest core0.0.2080 verification does not establish a released B-005 fix; no unrelated dependency upgrade was installed. The charger pill-pad coverage observation was sent to the authorized correction chat as additional B-005 evidence, without assuming a common root cause. B-003 ground identity remains resolved in the current runtime.

Mechanical prerequisites and unresolved battery polarity block final placement/routing. Paste, schema and assembly metadata separately block fabrication. Existing lifecycle/catalogue/land qualification, source metadata/reference warnings, startup/privacy/timing and full current budget also remain open; they are not invented copper shorts. No actual routed short or clearance failure is asserted when no routed copper exists.

## Checks, evidence and next actions

Native build and all five required pre-routing checks pass (netlist, pin_specification, source, schematic-placement, placement). Format and TypeScript pass; reviewed native snapshots were updated and the final comparison passes. The unrouted shorts diagnostic exits0 (zero reported shorts), which does not validate routed copper. Tests retain the strict-schema failure; full current schema audit retains all 162 failed records without rewriting output. Native connector warnings remain visible. A4 sheets and board CAD renders were inspected for this preview; some supplied symbols/models and edge text still need final schematic/assembly readability qualification.

Evidence is in this directory: manufacturer PDFs under `references/routing-a2/`; rendered datasheet pages; current PCB/ratsnest/A4/3D images; native command logs; `native-analysis.json`, `schema-failures-summary.json`, `diagnostic-export-review.json`, `power-width-study.json`; failed earlier placement builds preserved separately. The native root `dist/index/circuit.json` is included in the runtime-only publication. Documents, scripts, evidence and unused imports are excluded from the tscircuit runtime package; GitHub retains the engineering evidence.

Next: confirm battery outer numbering, close real display/FPC/enclosure/RF fit and final backlight/current decisions, resolve footprint/paste and assembly export blockers, then enable native routing. Save genuine router events/full JSON/per-phase replay data before any route-moving work and verify actual copper connectivity/shorts/clearances/widths/returns. Regenerate and inspect final fabrication files only from the routed validated revision. The background watcher stays paused. No order or physical-test result exists.

## Public A2 remote outcome — verified 2026-10-04

Board implementation commit **8332577b7eff34815843084d4fbe5549d5066e78** reached public GitHub main; anonymous committed Circuit JSON is identical to local: 2,300,592 bytes, SHA-256 `fbf9e2b576a9e37f695e894d9458500c33d5508b052b10692dcf99bc474dcd3f`.

Public tscircuit releases **0.0.2-wip-a2-display-mounting** and the one bounded native retry **0.0.2-wip-a2-display-mounting-retry1** both contain all75 expected board-only files with exact anonymous byte-hash matches, zero missing/extra/unverified files, private=false/unlisted=false. Native publication exits1 each time:74reported successes/one timeout on `imports/TPS63802DLAR/TPS63802DLAR.step`; the timed-out model persisted correctly in both releases. The native CLI exits before its final `ready_to_build=true` update. Both releases remain **ready_to_build=false**, so **B-009 build queuing/publication completion remains blocked despite complete public file content**. Null build errors do not prove a cloud build. No forced readiness, custom upload, compression, evidence omission, repeated retry loop or imported-model edit was used.

Receipts and safe logs are in `evidence/routing-intake-2026-10-04/`; first attempt kept separately. Runtime/source bytes were frozen and unchanged throughout. Receipt-only follow-up does not change any board input or require another registry publication. Both paste/schema and this upload completion behavior were reported to the authorized correction chat. Background watcher remains paused.

[GitHub board revision](https://github.com/AnasSarkiz/tscircuit-ai-agent-remote/commit/8332577b7eff34815843084d4fbe5549d5066e78) · [Public tscircuit A2 files](https://tscircuit.com/AnasSarkiz/tscircuit-ai-agent-remote?version=0.0.2-wip-a2-display-mounting-retry1#files).

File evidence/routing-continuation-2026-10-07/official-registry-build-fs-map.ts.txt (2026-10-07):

import { KyselyDatabaseInstance } from "lib/db/kysely-types"

type NormalizedFilePath = string
type FileContent = string

export interface PackageFileWithMetadata {
  path: string
  content: string
  isBinary: boolean
}

export const getPackageReleaseFsMap = async (
  package_release_id: string,
  ctx: { db: KyselyDatabaseInstance },
): Promise<Record<string, string>> => {
  const files = await getPackageReleaseFsMapWithMetadata(
    package_release_id,
    ctx,
  )
  const fsMap: Record<NormalizedFilePath, FileContent> = {}
  for (const file of files) {
    fsMap[file.path] = file.content
  }
  return fsMap
}

export const getPackageReleaseFsMapWithMetadata = async (
  package_release_id: string,
  ctx: { db: KyselyDatabaseInstance },
): Promise<PackageFileWithMetadata[]> => {
  const { db } = ctx

  const files: PackageFileWithMetadata[] = []

  // Get all the files in the package release (except those in the dist/ directory)
  // make sure to use normalize_file_path
  const result = await db
    .selectFrom("main.package_file")
    .select([
      "normalized_file_path",
      "content_text",
      "content_bytes",
      "is_text",
    ])
    .where("package_release_id", "=", package_release_id)
    .where("normalized_file_path", "not like", "dist/%")
    .execute()

  // Populate the files array with normalized file paths and their content
  for (const row of result) {
    if (row.is_text && row.content_text) {
      files.push({
        path: row.normalized_file_path!,
        content: row.content_text,
        isBinary: false,
      })
    } else if (row.content_bytes) {
      files.push({
        path: row.normalized_file_path!,
        content: Buffer.from(row.content_bytes).toString("base64"),
        isBinary: true,
      })
    } else {
      // Log warning for files with no content
      console.warn(`File ${row.normalized_file_path} has no content`)
    }
  }

  return files
}

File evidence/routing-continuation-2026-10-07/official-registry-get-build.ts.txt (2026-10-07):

import { withWinterSpec } from "lib/with-winter-spec"
import { z } from "zod"
import * as ZT from "lib/zod"
import { publicMapPackageBuild } from "lib/public-mapping/public-map-package-build"

const routeSpec = {
  methods: ["GET", "POST"],
  auth: "none",
  commonParams: z.object({
    package_build_id: z.string().uuid(),
    include_logs: z.boolean().optional().default(false),
  }),
  jsonResponse: z.object({
    ok: z.boolean(),
    package_build: ZT.public_package_build,
  }),
} as const

export default withWinterSpec(routeSpec)(async (req, ctx) => {
  const { package_build_id, include_logs } = req.commonParams

  const packageBuild = await ctx.unsafe_db
    .selectFrom("main.package_build as pb")
    .selectAll()
    .where("pb.package_build_id", "=", package_build_id)
    .executeTakeFirst()

  if (!packageBuild) {
    return ctx.error(404, {
      error_code: "package_build_not_found",
      message: "Package build not found",
    })
  }

  return ctx.json({
    ok: true,
    package_build: publicMapPackageBuild(packageBuild, {
      include_logs,
    }),
  })
})

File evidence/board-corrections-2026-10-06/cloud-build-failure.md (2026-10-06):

# Public cloud build failure — 2026-10-06

Public release: `AnasSarkiz/tscircuit-ai-agent-remote@0.0.3-wip-local-bypass`.
Release ID: `8dd2f2c2-5ce3-4826-a126-aa7cc7ea78b8`.
Build ID: `5f93c81b-9582-428b-872d-654926e8d60d`.
Exact complete package inputs: `publication-inputs.json`; all 119 files are
verified by `final-registry-receipt.json`. Native JSON SHA256:
`772195341bd21450085576075af162a3a45adc9c311e5fcc747488d01bb56ebe`.

The registry automatically scheduled the normal cloud build after the supported
archive transaction completed. Its runner wrote all files, created bundled
dependency symlinks and executed `bunx tscircuit build --ci --concurrency 4`.
Heartbeats showed one busy worker for `/workspace/index.circuit.tsx`, waiting
on `analyze-part-orientation`, including at 210,005 and 240,005 ms.
The stream then failed: `ReadableStream received over RPC disconnected prematurely.`
The registry recorded `user_code_job_infrastructure_error`, completed at
2026-10-06T13:42:50.630Z. No successful cloud CI result is claimed.

Expected: the worker completes supplier orientation analysis or returns a bounded,
explicit analysis failure, then completes the board build with its actual board
validation results. Observed: infrastructure stream disconnect during that phase.
The exact supplier part and remote dependency versions are not exposed by these
logs; the wait and disconnect do not prove which service caused the failure.

Evidence: `cloud-build-followup.json` contains the actual final registry status
and logs. Read the existing build anonymously with:

```sh
curl 'https://registry-api.tscircuit.com/package_builds/get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'
```

The current canonical core source queues the named orientation effect and awaits
`partsEngine.fetchPartCircuitJson`; this matches the phase named in logs, not
proof of remote root cause. No check was disabled, supplier orientation invented,
import/model omitted or generated output patched to work around this failure.
No duplicate cloud build was queued. The clean locally frozen package build
completes, generates identical physical copper records and fails correctly on
90 open-port errors. Both original SVG snapshots also mismatch.

The existing uploaded native JSON is independently discoverable in the public
[preview](https://tscircuit.com/AnasSarkiz/tscircuit-ai-agent-remote/releases/8dd2f2c2-5ce3-4826-a126-aa7cc7ea78b8/preview).
That does not clear cloud CI or the board's separate fabrication gates.

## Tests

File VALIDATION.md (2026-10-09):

## Current native and canonical qualification — 2026-10-08

**0.0.11-wip-generator-qualification — NOT READY TO ORDER.** Canonical project
runtime fixes eliminate all 169 schema failures and missing pill paste. The
untouched genuine C7848 import clears U14 supplier rotation. Local regulator
escape requirements now explicitly preserve 1 mm trunks. All 9,813 existing
connected pairs are preserved; all 125 purchased component poses are unchanged.
Fresh native checks still report 50 connection errors / 12 physically open
assigned nets plus two unassigned battery contacts. Shorts and measured copper
clearance violations are zero. The final 2.8-inch LCD, backlight, RF/mechanical
integration and battery polarity remain unqualified.

The corrected canonical Gerber library preserves USB slots. Independent strict
Gerber parsing and Excellon inspection pass; actual exports are explicitly
NOT FOR FABRICATION. Strict PnP rotation passes for all 125 parts, and the official
resolved BOM covers all 43 supplier identities. Current inventory confirms 39
identities conservatively; D2 is out of stock and three positive-stock records
require assembly-availability confirmation. Complete current/thermal and full fabrication gates remain open.
All 15 original schematic style issues are corrected in the actual schematic
trial, with identical PCB/CAD geometry. One newly exposed alignment advisory
misclassifies the VMOTOR flyback/bleeder parallel branches as a series pair;
its exact six-contact topology and conflicting orientation advice are reviewed
and retained in the schematic-style-repair evidence. Final routed checks are
recorded independently; no failure is hidden.

Core also prevents disabled subcircuits from starting autorouting during
updates; both disabled controls and an enabled control are regression-tested.
The actual isolated MCU diagnostic now has zero copper and zero routing events.
Board tests: 51 pass; the full-board fabrication gate still fails on 50
unresolved native connections. These are 50 assigned open contacts plus two
unassigned J3 contacts, not a completed board.

Receipts and source patches: `evidence/pcb-completion-2026-10-08/` and `toolchain/`.
Older entries below are historical.

---
**0.0.10-wip-microphone-bypass — NOT READY TO ORDER.** The existing C81
100 nF X7R capacitor moves beside U5 to (17.05, -28.1) mm / 180 degrees on top.
Its authored 0.3 mm top copper connects directly to the U5 supply escape and
ground pour; the remote capacitor escapes are explicitly retired.
R93 moves to (16.5, -31.42) mm to clear the capacitor; its actual supply and
clock-bias copper is rerouted while retaining/reusing existing drill positions.
A finite 2 mm supply limit is declared because the untouched supplier
courtyards impose a 1.38 mm minimum; the proposed direct route is 1.44 mm.
The ground branch has a finite 2.5 mm limit: preflight uses a GND pad 2.15 mm
away before the pour exists, while the actual top pour-entry stub is 0.60 mm. No part is
added or replaced, and no new via is required. The exact manufacturer recommends
short connections on one layer for this bypass. Actual native qualification,
remaining full-board gates and public delivery receipts are recorded in the
[current repair review](https://github.com/AnasSarkiz/tscircuit-ai-agent-remote/blob/main/evidence/microphone-local-bypass-2026-10-08/review.md).
The display/battery interfaces and fabrication gates remain unresolved; this
revision does not establish zero DRC, complete connectivity or order readiness.
Older entries below are historical.

---

**0.0.9-wip-standard-uart — NOT READY TO ORDER.** J6 now uses the genuine
JLCPCB **C160389 / JST BM03B-SRSS-TB(LF)(SN)** three-contact upward SH header.
Its UART contacts are RX/GND/TX (pins 1/2/3); hold-downs 4/5 are GND.
Authored native routes replace the former six-contact connector's connections,
with a local audio-gate detour, a 0.8 mm bottom-layer 3.3 V trunk bypass
and ordinary 0.30/0.45 mm through-via escapes.
The standard JST programmer's TX/GND/RX cable maps directly to these contacts;
the custom three-to-six adapter is removed. Programming requires separate
USB/battery power, manual BOOT/RESET and an open enclosure: mated connector
height is 6.3 mm. Hardware operation and cable assembly are untested.

The 2026-10-07 20:07 UTC official JLCPCB page reports C160389
`overseasStockCount=32191` and `canPresaleNumber=31559`, at a reference
$0.2743 each. These are public inventory fields; they do not establish global
warehouse totals, assembler allocation or an order quote. Purchased count
remains 125 parts / 43 identities. All other component poses are retained.

The requested 2.8-inch LCD is still unimplemented. Exact panel/flex/antenna
fit, J7 mapping, battery outer-contact numbering, full connectivity, toolchain
schema/paste/Gerber issues and current-carrying qualification remain gates.
See the [actual native qualification and remaining blockers](https://github.com/AnasSarkiz/tscircuit-ai-agent-remote/blob/main/evidence/programmer-direct-uart-2026-10-07/review.md).
Final copper qualification: 381 native traces, 322 full-span 0.30/0.45 mm
vias and 273 native pours; 0 measured shorts / 0 geometry violations;
50 native open-port errors (46 J7 + 4 U27) / 12 physically open nets.
All 250 active authored regions pass their nominal width checks. All 9,813
retained terminal pairs are preserved under the explicitly qualified J6 contact
migration; 124 other purchased geometries remain identical. High-current
trunks use top/bottom. Five source checks, TypeScript, formatting and 94
routing regressions pass. Board tests: 49 pass / 2 fail. Actual schematic UI:
15 style issues; strict native schema: 169 failures. Source snapshots complete
and fail against unchanged references. Two explicit regulator width minima,
32 missing paste records and fabrication export gates remain unresolved.

Exact public visibility/source/native verification is recorded in the linked
review and its `github-publication-receipt.json`, `final-registry-receipt.json`
and `final-public-preview-receipt.json`; publication is complete only after
those receipts establish exact matching anonymous access. The current source
hash, revision and public links are recorded there without a fabrication claim.
Older status and connector references below describe historical revisions.

---

## Canonical paste source repair — 2026-10-07

**Tested source repair; active board and fabrication remain blocked.** Canonical
core pill paste fix passes 17 relevant tests (308 assertions), full TypeScript,
formatting, build and dist smoke. Genuine U14 yields 20 valid native apertures
with unchanged pads; genuine U16/U27 yield 34. All four visual captures inspected.
Yalc links removed, official packages restored; official core 0.0.2106 still
reproduces zero U14 paste. The active frozen board remains core 0.0.2090 and its
native/source/routes are unchanged. No new board implementation or tscircuit
version is claimed. Exact source patch, local-build receipts, genuine coupon
outputs and remaining mechanical/publication gates:
[evidence/core-pill-paste-fix-2026-10-07/review.md](evidence/core-pill-paste-fix-2026-10-07/review.md).
One required context marker in the archived patch triggers a staged whitespace
warning; the actual upstream source diff is clean and the patch applies.

## Latest landscape replacement qualification —2026-10-07

**BLOCKED — no 2.8-inch PCB implementation or routing accepted.** The exact
manufacturer A2 candidate is reviewed,including all 50 pins,69.3×50.2mm body,
57.6×43.2mm active area and common-cathode backlight. Centred body/RF overlap is
59.5mm²;the 26.7mm flat tail leaves the enclosure and no numerical minimum bend
radius is published. A3 download needs the blocked Cloudflare subdomain.
Native/source remain the acceptedWIP,not a new routed display revision.
Genuine exact/download U14 import fixes supplier metadata/CAD alignment in a
canonical coupon,but generates no paste for20 pads and is not applied. TypeScript,
formatting and 5 geometry regressions pass. Full DRC,placement,mating,routing,
stock and fabrication gates remain open. Saved network/startup draft is separate
from applied runtime or environment publication. Exact sources,measurements,
resource outcomes and next required actions:
[evidence/display028-integration-2026-10-07/review.md](evidence/display028-integration-2026-10-07/review.md).
No new board build/version,order or physical-test pass is claimed. Six trailing-whitespace warnings
remain only in byte-preserved genuine-import evidence;authored CSV uses LF.

Historical validation follows.

## Current speaker implementation step — 2026-10-07

**0.0.8-wip-speaker-routing — NOT READY TO ORDER.** The qualified local speaker
repair is a WIP step. It preserves all 9,842 prior numbered-terminal pairs,
adds U3.10–J4.2, retains all 125 purchased identities and changes five purchased
poses plus TP1. Original imports/models/solver caches remain byte-identical.

The official isolated CLI build completes in 254.38 seconds and exits 1 with
50 actual open-port errors. Its untouched JSON is committed at
`dist/index/circuit.json` (SHA-256
`35c5fb2bfc870daf11b5f5e30847f1e5a86fd886ebb8ef11fc3cf6e88e77e63d`).
There are 384 traces, 325 through vias, 270 pours and 12 physically open nets,
all involving the deferred display; J3 unassigned outer contacts are excluded.
Independent geometry measures zero shorts/clearance violations. All 247 active
authored regions meet their unchanged nominal widths. This is not zero DRC.

| Gate | Current result |
| --- | --- |
| Requirements/interfaces | Blocked: J3 polarity, J7 mating, load/current/stackup/mechanics |
| Schematic/BOM | Blocked: exact J6 unavailable and supplier/assembly qualification incomplete |
| Placement | Automated checks pass; final mechanical qualification in progress |
| Routing | Blocked: 50 native opens, 12 physical open nets, two explicit-width failures |
| Automated/visual | In progress: type/format/92 routing tests/five source checks pass; board tests 48/2 |
| Prototype fabrication | Blocked: schema, paste, polygon exporter/shorts, rotations, interfaces and widths |
| Physical prototype | Not started |
| Public prototype package | Qualified WIP step; exact GitHub/package/preview verification in publication receipts |

The direct native placement capture uses the official `getPlatformConfig` API
and completes with zero errors, zero traces/vias/pours and 125 genuine supplier
orientation maps. Its router-start assertion remains active. The CLI placement
entry still emits copper, including with `--routing-disabled`, and is retained
as a tooling failure. No generated metadata was copied into native JSON.

All 26 schematic pages and four copper layers were inspected. CLI schematic
style analysis reports zero issues. Actual UI analysis was invoked but fails to
load its CDN module with `ERR_CERT_AUTHORITY_INVALID`; TLS was not disabled.
The supported source snapshot completes in 61.60 seconds and reports both
historical reference mismatches. References are unchanged and no new baseline
is accepted merely to obtain a pass. An earlier 180-second interrupted attempt
is retained separately. The frozen runtime installs 317 packages successfully.

Remaining strict gates: 169 native-schema failures; 32 missing U16/C54313 and
U27/C1848364 pill-pad paste records; official shorts/Gerber polygon failure;
U14/C7848 incompatible supplier pin-1 rotation metadata; two 0.275 mm regulator
sections below explicit 1 mm requirements; 64 nominal-width branches needing
current review. Latest official core/JSON/CLI tarballs retain the investigated
generator issues, so dependencies and imported definitions were not patched.

J6 replacement C265110 cannot be imported because EasyEDA returns HTTP 403.
Under AGENTS.md, “If a required part cannot be imported, or an imported component
has any issue, report it ... as a blocking issue ... and stop dependent work.”
The local [tscircuit skill](.agents/skills/tscircuit/SKILL.md) also says,
“When the canonical approach is blocked, diagnose it ... never conceal it with
a hack or fallback.” These block component-dependent fabrication approval;
independent routing, audits and authorized WIP publication are completed.

Full [review and receipts](evidence/routing-continuation-2026-10-07/review.md)
identify the remaining primary drawings, stock/import and toolchain work. The
environment domain draft is saved but requires Save/Publish in Environment
settings. No ordering, upstream merge, new issue or physical test occurred.
Historical checkpoints follow.

---

## Historical manual routing repair — 2026-10-07

**0.0.7-wip-manual-routing-repairs — NOT READY TO ORDER.** This entry
supersedes the historical checkpoints below. U4 now has a real 0.36 mm ground
escape to a 0.30/0.45 mm through via. Its clock/data escapes were moved to make
room while retaining their original nets and minimum widths.

The supported source CLI build completes in 251.86 seconds and exits 1 with
**52 open-port errors**: 46 J7 display contacts, four U27 backlight contacts and
two SPEAKER_N contacts. The unchanged generated JSON contains 381 traces,
325 through vias and 271 pours. Independent geometric checks measure **zero
shorts and zero clearance violations**, preserve all 9,842 previously connected
numbered-terminal pairs and verify all 247 authored regions at their nominal
widths. There are still 13 physically open nets. J3's unassigned outer contacts
are excluded from that count; battery polarity and display mating remain
unqualified. Every purchased component footprint, pose and model is unchanged.

A speaker/VSYS candidate was rejected: its native output disconnected U25.2 and
C76.2 ground, losing 266 existing terminal pairs, and reported a bus-skew error.
The candidate and follow-up proposals are preserved as evidence, not accepted
routing. Original speaker constraints and original power copper remain intact.
No native errors or checks were suppressed.

The five source/placement checks pass. Board tests remain 48 pass / 2 fail;
169 strict native-schema failures, 32 missing U16/U27 paste records and the
official shorts/export error “Unsupported shape polygon” still block approval.
Two regulator traces violate explicit source widths; 63 nominal-width branches
and current/signal-integrity qualification remain open. Stock and programmer
limitations in the prior review still apply. No order or physical test occurred.

Primary supplier retrieval is blocked by HTTP 403 from the cloud policy. Add
`www.buydisplay.com` and `www.elektronik.ropla.eu` to the existing Environment
settings allowlist, then save and publish it to resume exact J3/J7 qualification.
The editable allowlist was unavailable; no unknown list was replaced.

[Current repair review and exact receipts](https://github.com/AnasSarkiz/tscircuit-ai-agent-remote/blob/main/evidence/routing-zero-drc-2026-10-07/review.md).
Matching public publication and cloud CI are separate observations; a WIP
preview does not establish zero DRC or fabrication readiness.

Current validation receipts: supported source checks pass, TypeScript and
formatting pass, and all 87 routing regressions pass. Full board tests remain
48 pass / 2 fail. The required source snapshot completes in 61.10 seconds and
fails on PCB/schematic differences; references are unchanged. All five cloud
supervisor smoke cases pass, including cleanup of a live descendant after its
parent exits. The final source build and measured copper are bound by SHA-256
in the repair review. Requirements/interfaces and schematic/BOM remain
**blocked**; final placement is **in progress**; routing, automated checks and
fabrication qualification remain **blocked**; ordering/hardware tests are
**not started**.

---

## Previous connection repairs — 2026-10-06

**0.0.6-wip-connection-repairs — NOT READY TO ORDER.** This is a historical
source/native checkpoint, superseded by the manual routing repair above.

Manual native routing reduces open-port errors from 89 to **53** and physically
open nets from 25 to **13**. The actual frozen-install CLI build completes in
256.86 seconds and exits 1 on the remaining errors. Its unchanged native output
has 380 traces, 322 full-span 0.30/0.45 mm vias and 269 pours. Independent copper
measurement finds **zero shorts and zero clearance violations**, preserves all
8,152 previously connected numbered-terminal pairs and adds 1,690 connected
pairs. All 245 authored regions meet their nominal widths after fixing an
outline-generator defect at short bends. Component footprints, poses, models
and original solver caches remain unchanged.

Source checks, CLI schematic style, TypeScript, formatting and 80 routing
regressions pass. Full board tests remain 48 pass / 2 fail. Remaining native
errors are 46 J7, four backlight U27, two SPEAKER_N contacts and U4 ground.
J3's centre NTC is routed; its outer polarity and J7 mating remain unqualified.
Two regulator routes violate their explicit source widths; 63 nominal-width
branches, current/signal integrity, 169 schema failures, 32 missing paste
records and polygon Gerber export still block fabrication. Dated stock still
shows J6/C160405 unavailable. The standard programmer needs the documented
adapter and has not been hardware-tested.

[Actual repair review and receipts](https://github.com/AnasSarkiz/tscircuit-ai-agent-remote/blob/main/evidence/connection-repair-2026-10-06/review.md).
Matching public source/native publication is established by its anonymous
verification receipts, not by preview availability or a passing cloud CI claim.
No fabrication order or physical test has been performed.

Current gates: requirements **blocked** on J3/J7 physical interfaces; schematic/BOM **blocked** on supplier/assembly and electrical qualification; physical placement **in progress** pending bypass/mechanics; routing **blocked** on the remaining opens and source widths; automated/fabrication checks **blocked** on the retained native-schema/paste/Gerber errors; prototype order and hardware tests **not started**. The source snapshot comparison completes in 58.59 seconds and fails on PCB/schematic differences; committed references are preserved. Cloud setup passes 397 file checks and all four supervisor smoke cases without launching board routing.

---

## Current six-point review — 2026-10-06

**0.0.5-wip-style-vias-power — NOT READY TO ORDER.** This entry supersedes the older counts and status below.

J1 now uses the requested native USB-C schematic symbol while preserving its numbered contacts, supplier identity, physical footprint and models. CLI schematic-placement analysis reports zero issues. The actual UI analysis was invoked but its external analysis module failed to load; this is a blocked check, not a passing result.

The clarified high-current requirement is implemented: all 80 authored high-current trunks and 59 audited native high-current traces use top/bottom copper. Six low-current pull-up/control/probe branches have separate documented requirements. All 217 vias physically span all four layers, with exactly 0.30 mm holes and 0.45 mm pads; blind/buried vias are explicitly disabled. All 151 native supply/control and relocated signal regions meet their nominal widths.

The supported frozen-install CLI build completes in 247.03 seconds and exits 1 with **89 real open-port errors**. Native output contains 328 traces, 217 vias and 183 pours. The independent geometry audit measures zero shorts and zero clearance violations, preserves all 8,146 previously connected port pairs, and still finds **25 physically open nets**. All 125 purchased component footprints, poses and models are unchanged. TP1 moves to (-22.2, 12.3) mm inside the main ground island. The five source checks, copper-free placement build, TypeScript, formatting and 64 routing regressions pass. Board tests report 48 pass / 2 fail (fabrication and strict native schema).

Official exact-part JLCPCB pages cover all 43 identities / 125 placements: 42 identities report enough total stock for one board; **J6 C160405 reports zero stock**. Positive stock for U1, D2 and U16 does not qualify assembly allocation. No stock reservation or assembler rotation approval is claimed.

Remaining fabrication blockers include unresolved J3 numbered outer polarity and J7 FPC mating, incomplete connections, 169 strict native-schema failures, missing pill-pad paste, unsupported polygon Gerber shorts/export, two regulator switching routes with 0.275 mm necks below their explicit 1.0 mm source requirement, 55 nominal-net-width branches requiring load review, and supplier rotations/current/stackup/signal-integrity/mechanical qualification. The standard JST programmer needs the documented adapter; direct connector mating and hardware operation are untested.

The supported source snapshot comparison completes in 61.13 seconds and fails on PCB and schematic differences; committed references are retained. All 26 native A4 pages, four copper layers, mask/paste and critical zooms were inspected. Native component guides cover all 135 references with valid annotation schema. Final component inventory confirms 32 missing pill-pad paste records on U16/U27.

[Full review and actual receipts](evidence/six-point-board-review-2026-10-06/review.md). Publication is recorded independently; native preview availability does not establish passing cloud CI or fabrication approval. No order or physical test has been performed.

---

## Schematic component explanations — 2026-10-06

Revision `0.0.4-wip-schematic-notes` adds a plain-English explanation for every
schematic component reference: 125 purchased components and 10 solder/test
pads. The 13 circuit drawings link to paired A4 component-guide pages, numbered
14–26, to keep the original symbols and connections readable.

Open the schematic sheet selector in tscircuit and choose a **Component guide**
page for the relevant circuit. Guides explain power, controls, USB/programming,
display, speaker, haptic drive, microphones, backlight and measurement access.
Battery connector polarity and display mating remain explicitly unverified.

[Annotation validation and rendered pages](https://github.com/AnasSarkiz/tscircuit-ai-agent-remote/blob/main/evidence/schematic-component-notes-2026-10-06/review.md).
This documentation revision does not establish fabrication or hardware readiness.

The fresh frozen-install native CLI build completed in249.96seconds and
retains90open-port errors. Annotation coverage/native schema, TypeScript and
formatting checks pass. AllPCB/source nets/ports and the original schematic
symbols/wires/labels match the prior board. The source checkpoint verifies
unchanged imports, models, lockfile and routing artifacts. The accepted schematic
snapshot adds all26A4pages; the PCB reference remains unchanged.

Final board checks remain blocked:47tests pass/3fail,169native schema failures
and90open ports. The placement fixture's extra mismatch is only10native test
pads receiving empty supplier maps from the CLI; strict PCB/net comparison
passes. The required source snapshot reaches its recorded360-second budget;
the supported snapshot of accepted native JSON completes, passes the reviewed
schematic reference and retains the original PCB-reference mismatch.

---
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

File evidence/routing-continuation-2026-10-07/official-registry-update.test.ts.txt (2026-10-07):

import { test, expect } from "bun:test"
import { getTestServer } from "tests/fixtures/get-test-server"

test("POST /package_releases/update - only changes is_latest for specified package_release", async () => {
  const { jane_axios, seed } = await getTestServer()

  // Create a package
  const packageRes = await jane_axios.post("/packages/create", {
    creator_account_id: seed.jane.account_id,
    name: "@jane/test-package",
  })
  expect(packageRes.data.package).toBeTruthy()

  // Create two package releases
  const packageReleaseRes1 = await jane_axios.post("/package_releases/create", {
    package_id: packageRes.data.package.package_id,
    version: "1.0.0",
  })
  expect(packageReleaseRes1.data.package_release).toBeTruthy()

  const packageReleaseRes2 = await jane_axios.post("/package_releases/create", {
    package_id: packageRes.data.package.package_id,
    version: "2.0.0",
  })
  expect(packageReleaseRes2.data.package_release).toBeTruthy()

  // Update the first package release to be is_latest
  const updateRes1 = await jane_axios.post("/package_releases/update", {
    package_name_with_version: "@jane/test-package@1.0.0",
    is_latest: true,
  })
  expect(updateRes1.data.ok).toBe(true)

  // Ensure the first package release is_latest is true and second is false
  const checkRes1 = await jane_axios.post("/package_releases/list", {
    package_id: packageRes.data.package.package_id,
  })
  expect(
    checkRes1.data.package_releases.some(
      (pr) => pr.version === "1.0.0" && pr.is_latest,
    ),
  ).toBe(true)
  expect(
    checkRes1.data.package_releases.some(
      (pr) => pr.version === "2.0.0" && pr.is_latest,
    ),
  ).toBe(false)

  // Update the second package release to be is_latest
  const updateRes2 = await jane_axios.post("/package_releases/update", {
    package_name_with_version: "@jane/test-package@2.0.0",
    is_latest: true,
  })
  expect(updateRes2.data.ok).toBe(true)

  // Ensure the second package release is_latest is true and first is false
  const checkRes2 = await jane_axios.post("/package_releases/list", {
    package_id: packageRes.data.package.package_id,
  })
  expect(
    checkRes2.data.package_releases.some(
      (pr) => pr.version === "1.0.0" && pr.is_latest,
    ),
  ).toBe(false)
  expect(
    checkRes2.data.package_releases.some(
      (pr) => pr.version === "2.0.0" && pr.is_latest,
    ),
  ).toBe(true)
})

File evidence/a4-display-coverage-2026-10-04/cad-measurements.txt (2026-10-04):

module {'min': [-21.000999450683594, 13.174036835998535, 0.4], 'max': [-2.9990005493164062, 38.675037240356446, 3.509999895095825], 'max_z_under_lcd': 3.509999895095825}
connectors {'J1': {'min': [-4.46999979019165, -33.77507254169922, -0.45001099109649656], 'max': [4.46999979019165, -25.875072446331785, 3.650988960266113]}, 'J3': {'min': [18.0495126247406, 18.74999237060547, -3.099993085861206], 'max': [25.950512647628784, 26.349992156028748, 5.10000696182251]}, 'J4': {'min': [19.024999856948853, 1.7249984741210938, -3.099993085861206], 'max': [25.024999856948853, 9.42499852180481, 5.4500068664550785]}, 'J6': {'min': [-21.399923706054686, -14.522001018524168, 0.4], 'max': [-13.399923706054686, -9.572000970840453, 3.3100000858306884]}, 'J7': {'min': [6.174960088729856, -27.925000190734863, 0.4], 'max': [11.924960088729856, 2.6750001907348633, 2.4]}, 'J8': {'min': [19.024999856948853, -15.275001525878906, -3.099993085861206], 'max': [25.024999856948853, -7.57500147819519, 5.4500068664550785]}}
under LCD [('J1', 3.650988960266113), ('U1', 3.509999895095825), ('J6', 3.3100000858306884), ('D3', 2.449999952316284), ('J7', 2.4), ('U25', 2.04893901348114), ('SW5', 1.9000009536743163), ('U26', 1.6490830421447753), ('U7', 1.6490830421447753), ('U13', 1.5000000238418578), ('U23', 1.5000000238418578), ('U24', 1.5000000238418578), ('U12', 1.44920494556427), ('U14', 1.44920494556427), ('Q1', 1.44920494556427), ('Q2', 1.44920494556427), ('U22', 1.44920494556427), ('Q9', 1.44920494556427), ('U27', 1.4099999904632567), ('L1', 1.4)]

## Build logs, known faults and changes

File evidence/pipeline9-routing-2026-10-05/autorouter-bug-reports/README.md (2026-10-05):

# Pipeline9 bug-report SRJ inputs

These files contain only the original `simpleRouteJson` objects extracted from
the preserved native `autorouting:start` events. They are inputs, not routed
outputs or solver caches. No obstacles, connections or routing constraints were
changed during extraction. Both captures selected
`AutoroutingPipelineSolver9_PreloadedTraceGraph`, capacity-autorouter 0.0.958,
effort 1.

| Input | Observed failure | Connections | Obstacles |
| --- | --- | ---: | ---: |
| [pipeline9-iteration-limit.srj.json](pipeline9-iteration-limit.srj.json) | Native routing returned `aJ ran out of iterations (capacity-autorouter@0.0.958)` | 2 | 2,996 |
| [pipeline9-memory-limit.srj.json](pipeline9-memory-limit.srj.json) | Direct-library run exceeded its memory budget at 22,385,528,832 bytes sampled RSS | 2 | 9,279 |

The iteration-limit input is the reduced-copper trial, not the accepted board.
Its direct-library reproduction has not been tested. The memory-limit input
includes the existing copper and is the exact input tested through both native
rendering and the direct public-library runner.

See the [full report](../bug-report.md) for reproduction commands and measured
outcomes. The archives in the adjacent capture directories preserve the
original start events and their byte checksums.

SHA256 of these extracted files:

```text
a52c76d5e914aa543271c0236195212231db212e0ef84e425d3289c95a122e38  pipeline9-iteration-limit.srj.json
49c2ed28a8454d1bfd19ca561a282c4d6d8d8940cfcb9a86681526304ca1bf62  pipeline9-memory-limit.srj.json
```

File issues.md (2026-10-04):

## A6 public outcome — verified 2026-10-04

Public [GitHub A6 implementation](https://github.com/AnasSarkiz/tscircuit-ai-agent-remote/commit/a699a2d4337d5eafa26a777fee58c037de491f8f) and committed circuit JSON are anonymously byte-verified. Public [tscircuit0.0.2-wip-a6-bom-routing](https://tscircuit.com/AnasSarkiz/tscircuit-ai-agent-remote?version=0.0.2-wip-a6-bom-routing#files) has102/103matching board-only files, including this JSON and all saved routes. The required11.4MB C262650 connector STEP is404 after native compressed/fallbackHTTP413; publisher exit1, ready_to_build=false, no mismatched/unverified or extra files. **B-009 publication remains incomplete.** GitHub push succeeded. [Exact receipts](evidence/a6-bom-routing-2026-10-04/publication/review.md). Receipt-only update changes no runtime inputs and does not trigger another upload. **NOT FABRICATION READY.**

---

## A6 current checkpoint — 2026-10-04

**Engineering prototype — NOT FABRICATION READY.** This supersedes historical A5 counts below. Genuine in-stock replacements are implemented: seven C22548→C21190 (eight C21190 total), six C105588→C22775. Active125 purchased PCB parts /43identities plus10native pads. Published core0.0.2083 polygon paste fixes13 formerly missing pads;32 pill pads still lack paste. Current native copper20traces/2vias; five missing backlight traces resolved, unconnected-port errors413→402. Genuine saved phase replay and actual added-copper geometry verified; all prior11traces/2vias unchanged.

Required five native checks and copper-free placement CAD build pass. Format/types pass; tests42pass/2retained failures and full native strict schema169failures. Diagnostic PCB-image shorts passes, but **required Gerber-based shorts check fails “Unsupported shape polygon”**. Canonical routed build exits1 with402 retained unconnected-port errors. Final layout/assembly/fabrication gates remain blocked. Fresh4layer/paste/detail/13A4/3D prototype previews inspected.

Battery centreNTC confirmed; outer numbered polarity is still absent from the exact supplier drawing and stays unrouted. BuyDisplay panel has integrated ILI9341 and82.712% nominal physical coverage; actual FPC/contactface/pin1 mating and current bare-panel availability remain unqualified. JST board-thickness tolerance requires a mechanical/stackup revision; current conservative height becomes15.07 mm at a qualifying1mm PCB, above15mm. PCB stays50×65 mm; case max60×75×15 mm. No fabricated confirmation, generic imports or orders.

[Detailed A6 review](evidence/a6-bom-routing-2026-10-04/review.md) · [Active inventory](evidence/a6-bom-routing-2026-10-04/inventory.md) · [Mechanical primary sources](evidence/a6-bom-routing-2026-10-04/mechanical-search.md). Parentfaa491d22d1a55210833a8ea3086ae56dc450245. Intended public version0.0.2-wip-a6-bom-routing; verify publication receipts before claiming upload complete. Watcher stays paused; no cross-chat issue messages.

---

## Current layout/BOM audit — 2026-10-04

Preliminary native placement/connectivity/shorts checks pass; final layout and assembly BOM remain **blocked**. Current 135 components = 125 purchased parts + 10 native pads. Fresh supplier audit:43/44 exact identities match; C22548 stock 5 versus 7 required, C105588 (six 100 Ω parts) has no in-stock result. Current native paste is missing on45 SMT pads: U16 (17), U27 (16), U4/U5 (8), J1 (4). Official BOM probe125 rows / 31 blank Comment fields / 125 supplier-code footprints. Fresh current 3D and 13 A4 sheets reviewed; display physical mating, pack outer polarity,0.8 mm stackup/case fit and full routing remain open. Tests42 pass / 2 retained failures. In-stock resistor alternatives were found but not substituted. [Full audit](evidence/layout-bom-audit-2026-10-04/review.md) · [Current inventory](evidence/layout-bom-audit-2026-10-04/inventory.md). Source/copper/imports unchanged; no new package retry, watcher resume or cross-chat message. **NOT FABRICATION READY.**

---

## A5 routing and connector checkpoint — 2026-10-04

J8 removed; native motor pads preserve connections. Required native placement/source checks and partial-copper shorts pass. B-009/publication and B-010/schema remain separate from physical copper review. Remaining routing:413unconnected-port/5missing-trace errors. Q9/C20917 native route export reports “PCB port selector is not unique: .Q9 > port.pin1”; dependent gate routing is left unsaved/unrouted, with full raw events in evidence/a5-independent-routing-2026-10-04/native-controls. Charger ISET/combined phases exhausted capacity-autorouter0.0.953; failed sources/events/output preserved, proposed R1 move reverted after native overlaps. GND via aperture gap corrected in source with0.21clearance; measured final0.20730mm≥0.2mm. No new upstream chat messages authorized.

## A4 publication verified — partial registry outcome

Public [GitHub A4 implementation 1a0b0d0b](https://github.com/AnasSarkiz/tscircuit-ai-agent-remote/commit/1a0b0d0b77294438c431a3e4246079e4363f2f50) and anonymous committed Circuit JSON are verified. Public [tscircuit 0.0.2-wip-a4-display-coverage](https://tscircuit.com/AnasSarkiz/tscircuit-ai-agent-remote?version=0.0.2-wip-a4-display-coverage#files) contains 91 of 92 matching runtime files, including the same fresh built Circuit JSON. The required C262650 connector STEP remains missing after HTTP413 in the official compressed upload and native fallback; publisher exit1, ready_to_build=false. **B-009 publication remains incomplete; NOT FABRICATION READY.** [Exact receipts](evidence/a4-display-coverage-2026-10-04/publication/review.md). These outcome notes change no board input and do not trigger another registry retry.

## A4 coverage trial qualification — 2026-10-04

The real source trial reaches82.712%physical PCB overlap, but current bare-panel availability/current manufacturer drawing, portrait FPC contact/pin1/fold, 0.8mm stackup/USB impedance, JST actual thickness acceptance and complete case/battery/harness tolerance fit remain open. These are design qualification tasks, not newly proven tool defects. Battery outer polarity remains unrouted. 431 unconnected/missing native connection errors remain and stage6 is not started. Existing B005/B010/B015/B009 are not cleared. [A4 review](evidence/a4-display-coverage-2026-10-04/review.md). No cross-chat message sent.

# Latest A2 checkpoint — 2026-10-04

**NOT FABRICATION READY.** This section supersedes conflicting historical A0/A1 selections and status below. A2 updates the genuine C11051 twelve-pin display connector, manufacturer display wiring, centre battery NTC, two native M2 mounting trials and provisional placement. Battery outer numbering remains pending; both outer contacts are unconnected/unrouted. Display/flex/enclosure/RF fit is still open; routing remains disabled. Full report: [A2 fabrication checkpoint](evidence/routing-intake-2026-10-04/fabrication-report.md).

A2 real blockers: battery outer numbering; screen tail/contact/raised assembly/RF clearance; backlight/current qualification; B-005paste (U4/U5 C5656610 9pads/5paste each, USB C16594812/8, charger C5431317/0); B-010162strict failures; B-01532blankBOMCommentfields; U14C7848CPLrotation unverified. Core4344paste PR was reverted4349, not resolved in checked2080. B-003 remains resolved. No routed copper exists; no actual route short/clearance diagnosis is asserted.

# Issues — A0

## RESOLVED LOCALLY B-001: C370970 terminal holes and mounting-slot lengths

Part: **C370970, ALPS EC11E15244G1**. Imported using pinned CLI 0.1.2228 with `--jlcpcb --use-exact-footprint --download`.

- Five terminal holes: 1.3000228 mm imported; manufacturer 1.00-1.10 mm.
- Two mounting slots: 3.200019 mm long imported; manufacturer 2.60-2.70 mm.
- Hole pattern row spacing 14.5 mm is correct (7 + 7.5 mm); no false row-spacing discrepancy is reported.
- Manufacturer 12.5 mm dimension is measured across outside slot edges, not between slot centers.

Affected gates: schematic/BOM import qualification (stage 2), placement/mechanics (stage 3), then routing, checks and fabrication (stages 4-6).

Evidence: `evidence/imports/C370970-audit.json`, original supplier JSON, `references/alps-ec11e15244g1-mounting.gif`, `references/alps-ec11e.pdf` and `evidence/datasheets/alps-ec11e-2.png`. Independent manufacturer-range tests reproduce both failures.

Original resolution rule prohibited local component edits. The user's subsequent explicit instructions authorized updating both C370970's symbol and footprint. The local import now has five **1.05 mm** terminal holes and two **2.65 mm** mounting-slot lengths, within the original unchanged manufacturer-range tests. Other geometry, centers, pin mappings, identity and models are preserved. This exception applies to C370970 only; no supplier library update is claimed.

Current evidence: `evidence/imports/C370970-footprint-change.json`, `evidence/encoder-footprint-circuit.json`, `evidence/encoder-footprint-pcb.svg` and PNG. Generated geometry was measured, the PCB preview inspected, and the isolated component placement check passed with zero errors/warnings. All four existing qualification tests pass without changing their limits. Final finished-hole tolerances, complete board integration, mechanical assembly and physical fit remain pending; this does not approve fabrication.

Historical alternative investigation: **C209762 / EC11J1525402** imported successfully through the supported workflow. ALPS marks this exact part Not Recommended for New Designs, so it was not selected or fully qualified. The user-authorized C370970 correction resolves the reported dimension issue instead.

Historical symbol-only change (revision 1f63764, 2026-10-02): removed C370970's custom `symbol` JSX prop. Native `chip` renders a box and preserves seven source pins (6–12). At that revision the footprint was unchanged and B-001 remained open. Audit: `evidence/imports/C370970-symbol-change.json`; preview: `evidence/encoder-chip-box-schematic.svg`. The subsequent authorized footprint correction is recorded above.

## Candidate rejection R-001: TPS63070RNMR C109322

The original import omits physical pin identities 8 and 13 and loses pin 1's PS/SYNC functional alias. TI assigns 7/8 to VOUT and 12/13 to VIN; grouped pads are electrically equivalent but do not satisfy exact pin identity qualification. This is not evidence of a short.

The supported import of genuine TI **TPS63802DLAR C2845237** retains all ten manufacturer pin numbers/functions and is an alternative candidate. No TPS63070 dependent circuit was authored. Old TPS63070 source and failed qualification evidence are retained; it is excluded from the proposed active BOM. TPS63802 placement, passives, complete power design and model qualification remain pending. This change resolves selection dependency on TPS63070, not the board validation stage.

## Other pending items

### RESOLVED LOCALLY B-002 — C5656610 / ICS-43434 acoustic opening

Unmodified import has a 0.3999992 mm acoustic hole. TDK DS-000069 v1.2 page 17 recommends a minimum 0.50 mm PCB opening. Original six pin identities/functions match page 10. This is a manufacturer-recommendation discrepancy, not a diagnosed short or absolute electrical-rating violation. The independent opening test fails; stage 2 and dependent stages 3–6 remain blocked.

Audit: `evidence/imports/C5656610-audit.json`. Prepared but **not applied**: `evidence/proposals/C5656610-acoustic-hole.diff`, diameter-only correction to 0.60 mm. Existing C370970 authorization does not cover this microphone, so approval for other documented import corrections was requested. Original microphone source/pads/models remain unchanged. The user requested waiting for an upstream correction. Fresh import with tscircuit 0.0.2736 / CLI 0.1.2232 on 2026-10-03 still measures 0.3999992 mm. Evidence: `evidence/update-check-2026-10-03/microphone-check.json`; the published fix is not verified. The user reaffirmed waiting for the upstream correction after this recheck; no local microphone edits or substitutions are authorized. No board routing is authorized before the remaining prerequisite gates pass.

TDK's manufacturer pages differ on lifecycle (Production/NRND versus EOL). Final selection/availability must be checked; this does not itself establish a bad import. Local datasheet download returned HTML, preserved as download evidence. Official PDF text was accessible through web tools; no local PDF render is claimed.

### Remaining design work

- Display: manufacturer documentation obtained for Waveshare 1.54inch LCD Module, ST7789, 240 x 240, 3.3 V operation, 50 x 35 mm module with PH2.0 eight-pin connection. Exact JLCPCB-sourced display/connector and permitted external assembly need final qualification; no display component or footprint has been authored.
- A free-text supported-import search for `1.54 LCD` selected the unrelated **DSK110 diode C908227**. That file is preserved as evidence of the search behavior and is not a display or active BOM selection. Future imports must use verified exact part numbers.
- Supplier catalogue stock/prices are inconsistent between catalogue/search endpoints. Exact JLCPCB assembly availability/classification and costs remain unverified.
- Accepted 2026-10-03: square, dominant screen, one top hold-to-talk button, top-side assembly only, speaker and rechargeable battery. See `REQUIREMENTS.md`. Prior encoder/extra-button/front-LED requirements are superseded; their imports remain historical evidence.
- Privacy: retain hardware microphone disable and prevent audio clock/data phantom power, using the single-control design. Exact architecture and Ioff buffer qualification remain pending; no software-only mute substitution.
- Battery: protected 1S nominal 3.7 V / 4.2 V-charge, 500–1000 mAh pack; exact MPN, sourcing/import, protection, thermistor, polarity and peak current rating remain pending. New SMT connector candidate C295747 is imported verbatim. Official JST drawing fetch returned 403; full footprint qualification is still pending. Charger/connector imports do not establish an integrated rechargeable system.
- Power budget, USB enumeration/current policy, passive component selection and regulator loop layout remain pending.
- A4 schematic, complete pin allocation, board outline/mounting, component placement, RF keepout and enclosure/ergonomics remain pending.
- Saved native routes and DRC/short repair remain pending because pre-routing gates have not passed.
- No physical prototype is available; no hardware results or physical photos are claimed.

## Tooling notes

- Initial optional skill download failed in the sandbox; the installed tscircuit skill and official handbook were read directly.
- A first formatter run changed import whitespace. All four affected imports were restored with the supported importer; regulator checksum matched the original. `imports/**` is now excluded from formatting.
- Initial diagnostic-script TypeScript errors were corrected by making the script a module; no component source was patched.
- LCSC encoder datasheet download returned an HTML challenge despite HTTP 200. Preserved as `evidence/downloads/C370970-datasheet-challenge.html`; actual official ALPS PDF and mounting diagram were obtained and inspected.
- Initial GitHub creation was rejected by automatic approval review. A narrower empty-private-repository creation succeeded after proving the attached brief explicitly requested it. Repository identity: AnasSarkiz/tscircuit-ai-agent-remote.

## User-authorized local C5656610 correction — 2026-10-03

The user's latest direct instruction authorizes manual correction after confirming
that the supplier footprint is undersized. This supersedes the prior wait for
upstream for this local correction. Only the acoustic diameter changed from
0.3999992 to **0.60 mm**. A byte comparison proves all other imported source is
unchanged. Source center, pads, pin mappings and models are preserved.

Audit: `evidence/microphone-local-correction-2026-10-03/change-audit.json`.
Generated diameter is 0.60 mm, minimum hole-to-copper gap is 0.2580203 mm,
and the isolated placement check passes with 0 errors / 0 warnings. All five
existing import tests pass. Supplier raw data and the converter remain unchanged.
Previous B-002 failure and wait entries above are historical evidence.

## RESOLVED B-003 — C5656610 native ground-pad port generation

Historical reproduction before core alignment: the native renderer reported `source_ambiguous_port_reference` for MIC1.GND.
Pin 3 consists of four separated polygon pad shapes, matching the imported
supplier layout. The renderer requires matched shapes to overlap before it
creates a PCB port for that logical pin. It produces six logical ports but only
five PCB ports, with all four ground shapes carrying `pcb_port_id: null`.

Using the documented `MIC1.pin3` selector correctly creates a source trace to
GND; the PCB-port generation still fails. Changing selector aliases therefore
does not resolve this error. The corrected component build exits 1. No DRC
suppression or geometry/pin-map workaround was applied. This is not a diagnosed
short or proof that the four-segment supplier pad geometry is itself incorrect.

Evidence: `evidence/microphone-local-correction-2026-10-03/build.log`, `circuit.json`
and `change-audit.json`. Affected stage: 2 and dependent stages 3–6. Full-board
schematic, component selection, battery/display mechanics and placement are
also unfinished. Stop dependent routing until native port handling and all
prerequisite checks are resolved.

## Publication status

Standing authorization covers milestone pushes to GitHub main and private
tscircuit WIP source publication. The human explicitly authorized the corrected
C5656610 revision after the initial automatic-review rejection. GitHub main was
verified at 671eb00579db27cc4dc232fe701a4ba98e7a19ac; the complete private
tscircuit source publication is 0.0.2-wip-c5656610-hole-060-publication-record,
176 files. Cloud build was pending when checked; this does not approve fabrication.
The power-review milestone was subsequently verified at fa5375fdbe457343e31852dbb706146ee6fe5841 and private release 0.0.2-wip-a0-power-review (238 files); its receipt is retained in the next milestone.

## Historical B-003 release attempt — 2026-10-03

Core PR 4323 merged at 51b6b9789aa6e8c1d58d2ac98783f243aa4f1ebf. Published
core 0.0.2058 (gitHead e6d010593f4739747de9c3fc8ff9f6651b862c5d) contains
that change. Project pins are tscircuit 0.0.2742 / CLI 0.1.2235 / direct core
0.0.2058. Native CLI rendering still reproduces the microphone failure: six
source ports, five PCB ports, four ground pads with null PCB-port IDs and
source_ambiguous_port_reference. The CLI bundle lacks the new polygon-bounds
method even though the direct core bundle contains it. A fixed CLI release is
initially inferred to be needed. This inference was superseded by the active-runtime diagnosis and supported dependency alignment below. No local runtime
patch was applied. Evidence: `evidence/core-fix-2026-10-03/`. This release gap
was sent to the authorized issue chat. Independent regulator work continued.

## BLOCKING B-004 — catalogue search returns unrelated components

CLI 0.1.2232 and 0.1.2235 both return unrelated parts for:

- `tsci search --jlcpcb --json 'Waveshare 1.54'`: C275301 inductor / C2068886 fuse holder.
- `tsci search --jlcpcb --json 'GRM188R60J226MEA0'`: C7431187 oscillator / C269729 200 Ω resistor.

Expected: matching components or an explicit no-result response. None of those
returned parts was selected or substituted. Root cause is not established.
Evidence: `evidence/component-search-2026-10-03/`, including release rechecks.
Reported to `codex://threads/01a0f218-ce92-7671-b666-efccdef3aed2`. Search-based
display/capacitor discovery in stage 2 is blocked; verified exact-part imports
remain usable and continue. This is not a claim that all imports fail.

## B-003 closed after supported dependency alignment

The earlier missing-method CLI-bundle inference did not identify the active
renderer. CLI's native build uses importFromUserLand("tscircuit") and its
RootCircuit. The tscircuit installation retained nested core 0.0.2056. A supported
package.json override to official core 0.0.2058 and clean `bun install --force`
resolved this. Plain install changed the lock but left the stale nested files.
The final native microphone build and five checks exit 0, with four linked
ground contacts, nine source/PCB ports and their native internal connection.
No runtime or component-source workaround was used. Current logs and reviewed
artifacts are in `evidence/core-alignment-2026-10-03/`; the issue chat received
the measured resolution. Historical failed-release evidence above is preserved.
B-004 search discovery and full component/application qualification remain open.

## BLOCKING B-005 — C5656610 polygon ground pads have no solder paste

Reproduced on tscircuit 0.0.2742 / CLI 0.1.2235 / aligned core 0.0.2058.
The microphone fixture now passes native generation, but Circuit JSON contains
nine pcb_smtpad shapes and only five pcb_solder_paste records. Each of the four
polygon ground pad shapes lacks paste. Installed core's polygon SmtPad branch
inserts a copper pad without a corresponding paste record. No importer geometry
edit was made in this milestone.

Supported native diagnostic export:
`tsci export evidence/microphone-local-correction.circuit.tsx --format gerbers --output <absolute-path>/microphone-diagnostic-gerbers.zip`.
Export exits 0; circuit-json-to-gerber 0.0.109 emits only five rectangular flashes
and zero G36 regions in F_Paste.gbr. The four ground apertures are missing.
The ZIP is an unrouted component diagnostic, not the handheld fabrication package.

Evidence: `evidence/core-alignment-2026-10-03/microphone-stencil-defect.json`,
`microphone-circuit.json`, `F_Paste.gbr`, `microphone-diagnostic-gerbers.zip` and
`microphone-gerber-export-native.log`. Earlier failed export attempts were an
unsupported JSON-input invocation and an incorrectly relative output path;
the final native TSX export with absolute output path succeeded.

Affected stages: 2, 5 and 6; assembly/stencil qualification remains blocked.
Exact manufacturer aperture geometry still needs visual datasheet review. Official
TDK PDF fetch returned 403; alternate TDK/Mouser downloads returned HTML rather
than PDF. This availability limitation does not weaken the generated-file evidence.
Reported to `codex://threads/01a0f218-ce92-7671-b666-efccdef3aed2` with reproduction,
versions and evidence. Do not locally patch imported paste geometry or emit a
hand-authored fabrication substitute. Continue independent power, controls,
battery, interfaces and mechanical work while the upstream defect is investigated.

## BLOCKING B-006 — C79174 / Panasonic EVQPUC02K contacts and holes

The untouched exact import has four separate contacts and no declared internal
pairs. Panasonic ANCTB23E July 2025 printed page 2 specifies permanent pairs
1↔3 and 2↔4. Native generation confirms four source/PCB ports with no internal
connection. Its two 0.9000236 mm NPTH locating holes exceed the manufacturer
Ø0.75 +0.10/−0 recommendation (0.85 mm maximum). The issue chat confirmed the
raw supplier retains contact grouping that conversion loses; the oversized holes
originate in the supplier footprint. Stage 2 and dependent hold-control work stop.
No symbol, mapping or holes were patched. Evidence: button-discrepancies.json,
button-circuit.json and the reviewed Panasonic printed pages 1–2 under
`evidence/controls-review-2026-10-03/`; original manufacturer PDF in references.

## B-007 — C2149796 / TPS22919DCKR supply metadata limitation

Native pin_specification exits 0 with zero errors and one warning:
`source_no_power_pin_defined_warning: U8 has no pin with requires_power=true`.
The import declares ground and NC but not pin 1's power role. Manufacturer
SLVSEN5B page 3 and generated JSON verify the actual pin 1→V3V3 connection,
pin 2 ground, pin 3 hardware-only ON, pin 4 open, pins 5/6 VMIC. The issue chat
confirmed raw source electrical types are Undefined; converter data loss is not
established. Do not infer every IN label is a power pin or patch the definition.
Manual connection review passes, but the metadata warning stays visible and
complete application qualification is pending. No warning was suppressed.

## BLOCKING B-008 — C105188 / TLV3201AIDBVR missing schematic reference

The exact supported import's custom symbol has no reference-designator text.
Native build warns `U7 is missing schematic reference designator text` and the
current A4 render visibly lacks the comparator identifier. Pins and footprint
remain unmodified. Stage 2 schematic readability/import qualification is blocked;
no full-board integration or schematic completion is claimed. Reproduction:
`evidence/controls-review-2026-10-03/isolation-ics.circuit.tsx`, current build log,
JSON and PNG/SVG. Reported with B-006/B-007 to the authorized issue chat.

## Application correction — microphone SD levels

ICS-43434's 0.35/0.65 VDD guaranteed output levels do not meet both input limits
of direct ESP32-S3 or the proposed LVC/LV1T SD receivers. This is our application
selection issue, not a newly diagnosed supplier microphone defect. The review
now uses exact imported C105188 with a VMIC/2 reference and a provisional 16 kHz
voice target. Full switching/rail/load and power-off analysis remain pending.
The blocked microphone, switch and comparator are not integrated into a complete
board. Independent power, USB, MCU, charger and mechanical work continues.

## B-005 additional scope — C165948 TYPE-C-31-M-12

Current native MCU/USB fixture has four polygon VBUS/GND copper pads (13–16)
with no linked paste records. Diagnostic F_Paste Gerber has zero polygon regions;
97 flashes cover 93 rectangular SMD pads and four connector anchor paste records.
This extends the confirmed core/export assembly defect beyond microphone GND.
Evidence: `evidence/mcu-usb-review-2026-10-03/circuit.json`, `F_Paste.gbr`,
`diagnostic-only-gerbers.zip`. Reported once as a material update.

## B-008 additional scope — C94934 TPD2EUSB30ADRTR

Untouched exact import lacks custom-symbol reference text. Native current A4
render visibly lacks D2 and build emits the corresponding warning. Pins 1 D+,
2 D− and 3 GND were checked against TI. New application does not resolve this
import readability defect. Reported once; no symbol edit authorized/applied.

## BLOCKING B-009 — supported private publication timeouts

GitHub main contains controls commit de5c6e45d7cf2e8077ad77be5abff97892fbb6f0.
Native private release 0.0.2-wip-a0-controls-review exits 1: 406/410 successful,
four large STEP TimeoutErrors. Canonical fresh-tag retry controls-retry1 exits 1:
409/410 successful, one TimeoutError. Authenticated remote readback confirms
all timed-out model bytes match local files, but both releases remain
ready_to_build=false. Completion still requires official acknowledgement of
all files; no force-finalization or upload-success claim was made. Native gzip
bundle would exceed service size limit (41.3 MB base64 before missing file),
so compression is not a valid remedy. No runtime patch, model omission or token
persistence. Reported to authorized fix chat; evidence under MCU/USB review.
Last fully verified private source release remains 0.0.2-wip-a0-core-alignment.

## BLOCKING B-010 — native Circuit JSON/schema contract

Installed core 0.0.2058 / CLI 0.1.2235 / circuit-json 0.0.510 output is rejected
by its published schema: schematic_group.subcircuit_id=null, 16 pcb_component
numeric display_offset_x/y where string required, pcb_group.anchor_alignment=null.
Eighteen element failures are saved in circuit-json-schema-failures.json.
The explicit regression remains failing. Nine other meaningful tests pass,
including module supply/reset/USB/BOOT physical pins, PSRAM exclusion and all
nine native exposed-ground shape ports/internal group. Extra shape ports carry
pin41 hints rather than duplicate pin_number; the regression uses the documented
native identities. No JSON conversion, schema suppression or runtime patch.
Reported to authorized fix chat. Native five checks exiting 0 do not waive this
stage-5 blocker. Continue independent manufacturer circuit and mechanical review.

C110293 / ALPS SKRTLAE010 alternative is also blocked: manufacturer circuit
diagram permanently joins pins 1↔3; untouched import/native generation has no
internal group. Native schematic exposes only 1/2 while footprint has 1–5.
The two Ø0.9000236 mm locating holes DO match ALPS's Ø0.9 recommendation; no
ALPS hole defect is alleged. Current official dimension/land/circuit GIFs were
visually inspected. This extends B-006 contact-import scope, not a permitted
component patch. Evidence: MCU/USB review switch-discrepancy.json and native
switch JSON/PNG/SVG. Do not integrate this unqualified alternate.

## B-009 additional scope — MCU/USB native upload

Git02950fb published natively as0.0.2-wip-a0-mcu-usb-review:535reported success,
4failures,exit1. Timeout models SN74LVC1G125/TPS63802 have matching remote hashes.
HTTP413-rejected SN74LVC245STEP and TPS7A20PDF return404; ready_to_build=false.
This is not only an acknowledgement issue. Receipt and log in display evidence;
reported as material update. No file dropping/forced finalization.

## B-010 tested upstream source proposal — still blocked on board

Base18e1d11…core2061, strict native regression baseline fails; minimal corrected
source passes205assertions. Group offsets also require mm strings in both initial
and anchor update paths. Related suite29pass/0fail/1existing skip, TypeScript/
ESM/declaration build pass. Proposal/versions/snapshots saved in
evidence/core-b010-proposal-2026-10-03 and sent to fix chat. Board runtime2058
unchanged:12pass/1fail75assertions. Official fix publication/verification pending.

## B-011 correction — C11050 land qualification question

Initial nominal comparison was reported for review, then corrected. Raw supplier
and import match. Drawing2004.6.16 has X.X ±0.20 mm; both0.20mm nominal pad
differences lie at this boundary. No supplier/converter defect demonstrated,
and no local footprint patch is justified. Revision applicability and cable
mating fit remain pending. Follow-up clarification sent to fix chat.

## B-008 additional exact parts — amplifier diagnostic

C20917 / AO3400A and C15127 / AO3401A imported custom symbols omit reference
text, reproduced in native amplifier output. Reported to authorized fix chat.
Symbols untouched; qualification/snapshot acceptance withheld. Prefix/type
advisories and absence of MOSFET power pins are not treated as electrical defects.

## B-012 — speaker supplier libraries unavailable

Native exact imports C3311258 / PUI AS04008PS-4W-R, C6230316 / Taoglas
SPKM.20.8.A and C50387211 / XHXDZ23MM-8Ω2W-JFHM report no EasyEDA
library data. Stage2 speaker qualification/integration stops; no authored
speaker or generic substitution. First two independently confirmed by fix chat.
Evidence: audio-charge-review-2026-10-03 speaker import logs. Continue actual
supplier search and independent amplifier/charging work.

## B-004 additional exact manufacturer queries

RC0603FR-07470KL discovers C16195750 unrelated inductor;
RC0603FR-07430KL discovers C326810 unrelated510kΩ2010 resistor. Native
import logs preserved; both unselected. Reported as query matching, not data loss.

## B-009 — display publication exact receipt

Gitc82e7deb is verified on private main. Native version
0.0.2-wip-a0-display-logic-review exits1,582successes/4failures. Timeouts
SN74LVC1G17/TPS3839STEP reached server with matching hashes; HTTP413
SN74LVC245STEP/TPS7A20PDF return404. ready_to_build=false. Exact receipt
and log in audio/charge evidence; material update sent. No dropped models,
forced readiness, publisher bypass or success claim.

### 2026-10-03 Type-C review update

- B-006: C6617702 / EVQ-P4HB3B imported cutout is 5.334 mm wide; historical Panasonic drawing max 5.2 mm. Current drawing confirmation is needed; candidate stays unqualified and import untouched. Exact drawing/provenance/reproduction under `evidence/type-c-current-review-2026-10-03/`. Sent to fix chat.
- B-009: native amplifier publication has 665 successes / 13 failures, with nine failed files actually absent and ready_to_build=false. Exact hashes distinguish late-arriving uploads. Saved log/read-back receipt in the same evidence folder and forwarded to fix chat.
- B-010: hardware Type-C diagnostic has 19 strict schema failures; existing full-board test remains failing. Native build/five checks do not clear this blocker.
- Battery procurement question remains unanswered. Charger/pack/TS/system enable are not integrated by the new current-detector fixture.

## B-014 — C2942347 haptic motor body and model qualification

Supported imported LCM0720A3176F courtyard excludes most of the top-side motor
body. Deliberate real-resistor overlap at its center returns placement0errors/
0warnings; native PCB and3D were inspected. Fix chat confirms converter
body-bounds/courtyard generation defect from raw EasyEDA body data. Exact model
height3.85mm differs from manufacturer drawing-derived provisional2.65mm maximum
stack; that model concern remains separately unclassified. Alternate C2895081
has no importable EasyEDA library. Stage2/3 motor qualification blocked; no
import edit or authored substitute. Evidence: `evidence/haptic-review-2026-10-03/`.
All three concerns sent to the authorized fix chat.

### Haptic milestone — other open issues

- B-007/B-008: C963429 supply metadata, C20917 underspecified pins and missing
  reference text remain visible; manufacturer physical pins reviewed.
- B-010:12 strict native haptic schema failures; canonical suite19pass/1fail.
- B-009: Type-C package exited1,689successful/33failed upload reports;28timeout
  files byte-verified, five actual404,private=true,ready_to_build=false.
- Hardware Type-C startup gap is an electrical qualification issue, not a
  demonstrated library bug. Do not integrate the high-current detector until
  guaranteed low EN2 behavior across partial supply is established. Fixed
  USB100 direction remains unqualified; pack sourcing permission is pending.

### Regulated microphone clock milestone — remaining qualification

- Hardware: C5656610 I2S Table 5 specifies 1.8 < VDD < 3.3 V; the provisional
  main rail reaches 3.43818 V. The dedicated 2.8 V supply/open-drain clock
  candidate has better static margins; total clock capacitance must fit about
  30 pF. Timing, partial-power behavior and off deadline remain unqualified.
- B-010: 17 strict native candidate JSON failures; canonical tests 21 pass, 1 fail.
- B-009: haptic a1e76d5 private publication exits 1: archive HTTP413/native
  fallback 771 successes, 13 failures. Seven timeout files match exact hashes;
  six actual HTTP413 files are missing. Package is private=true, ready=false.
  Native error logging duplicates private archive content; fix chat reproduced
  this separately. Raw log retained privately in tmp; diagnostic copy substitutes
  only the payload line with its path, byte count and hash. No upload omissions.
- Mechanical: this 50 x 50 mm trial fails land support and RF separation. The
  approved 50 x 65 mm trial gives a nominal 15.82 mm LCD-to-antenna gap, but raised
  LCD, tolerances, substrate, top button and case fit remain pending. This does
  not prove all square layouts impossible or validate a replacement for the
  accepted square exterior. No imported definition was modified.

### 2026-10-03 battery-readiness and publication evidence

C43698 TPS3808G33DBVR imports successfully and supplies an independent documented low-voltage-reset candidate. Seven native Circuit JSON errors reproduce B-010; battery readiness/presence, dynamic reset current/timing, actual pack cutoff/NTC and charger policy remain open hardware qualification, not an importer defect. Unrelated exact resistor, speaker and battery results reproduce B-004 and were excluded.

B-009 persists at Git 435493d: supported private mic-clock publication reports 834 uploaded and nine failures, including six HTTP413 files and three timeout files. Readback receipts are retained in `evidence/charger-battery-ready-review-2026-10-03`. Circuit JSON 0.0.511 changes only missing-MPN warning metadata and does not resolve B-010; no dependency update applied.

Publication identity correction: native --version-tag prefixes package version. Actual previous release is `0.0.2-0.0.2-wip-a0-mic-clock-review`. The initial single-prefix lookup was invalid and its404 results are excluded from absence conclusions; corrected readback is retained separately.

## B-015 — native BOM exporter loses MPN and resolver Comment

Affected genuine imported parts reproduced: C2913201 (ESP32-S3-WROOM-1-N8R8), C165948 (TYPE-C-31-M-12), C43698 (TPS3808G33DBVR), C255576 (SKSWCFE010). Official latest circuit-json-to-bom-csv0.0.19, also bundled in pinned CLI0.1.2235, leaves Comment empty even though native manufacturer_part_number is present; a documented resolvePart comment is also ignored. JLCPCB IDs remain exact. Blocks final native stage6 BOM approval after earlier gates; no assembler misidentification or fullboard fabrication claim. Footprint C-number fallback is separately unqualified. Evidence/public API runtime/lock/input hashes: evidence/bom-export-review-2026-10-03/qualification.md. Sent to authorized fix chat01a0f218-ce92-7671-b666-efccdef3aed2; independently confirmed. No imported definition, library, schema or output patched. Continue independent work while official fix is pending.

Additional B-006 candidate review: C255576 has two actual contacts and no locating holes, but is unselected pending supplier-land/current-ALPS-pattern acceptance and mechanism/electrical review. Raw and converted pad dimensions match; no new converter defect or model-height defect alleged. C202371 supplier alternate has the same lands. Detailed evidence saved under hold-control-alternate-review-2026-10-03.

B-009 latest exact readback: battery-ready private release0.0.2-wip-a0-battery-ready-review native834success/62fail;55timeout files match, six prior413missing plus new actual404 timeout imports/SN74LVC1G17DBVR/SN74LVC1G17DBVR.tsx. Seven currently missing, no unverified files. Ready=false/private=true. Exact receipt and native log saved under fabrication-rule-review-2026-10-03 and sent to fix chat; do not call all62 missing.

### 2026-10-03 hold-readback and top-control continuation

B-009 current parent fa90b5420f8e567270697c68132f311444a42424: native private0.0.2-wip-a0-fabrication-review exits1 with957reported successes/28failures. All22timeouts are byte-verified present; six priorHTTP413 files remain404, no unverified cases. private=true/ready=false. Exact receipt/log/readback and sent update are saved under hold-readback-review-2026-10-03. Publication remains incomplete; no files omitted, checks weakened or readiness forced.

B-009 current0573bf4492817ea0263827b6f0431fb7905d4959: native private0.0.2-wip-a0-hold-readback-review exits1 with1081reported successes/20failures.13timeout files are byte-verified present; six priorHTTP413 files plus timeout imports/TLV3201AIDBVR/TLV3201AIDBVR.tsx (C105188) are404. No mismatched/unverified failed files; private=true/ready=false. Exact evidence in hold-readback-publication-2026-10-03, result sent to authorized fix chat. GitHub0573bf4 pushed; publication incomplete. These local outcome/watch notes were created after enumeration, pending a future implementation revision; no new board version or full-publication claim.

B-010 remains reproduced by six unchanged native elements in the independent hold-readback candidate. Canonical23pass/one existing strict JSON fail/228assertions; native build/allfive diagnostics/A4/snapshots/types/format pass only within their stated scopes. Hardware leakage, power-ramp/bounce/off timing, selected MCU pin/pulls and decoupling loops remain unqualified; this is not a complete privacy circuit or full-board gate pass.

Procurement observation: native C22548 stock5 and C98220 stock22 require final whole-BOM quantity/availability review. Genuine unchanged C21190/0603WAF1001T5E stock8,013,731 is used only in the new readback-series candidate. C25804/0603WAF1002T5E is genuinely imported but unselected: empty native stock-filtered searches and separate EasyEDA library success do not prove a bug or JLC assembly availability. Sent to fix chat; its independent finding is saved in supplier-search-observation.json. No false new B-number assigned.

Top-control nominal study addresses one RF placement conflict: shifting the MCU physical center left8mm increases the switch body/terminal-to-antenna gap9.95→17.95mm on the50x65trial, with actual native pads still supported. Raised LCD/tolerances/substrate, enclosure/control mechanics, pack/speaker and dominant front coverage remain open. No native placement/keepout/cutout or component definition was created by this sketch. Core0.0.2066's published changes concern bends/tear-relief/checks dependency, not these blockers. Board dependencies remain pinned; no copper or fabrication files exist.

## Current reassessment — 2026-10-03, A0-reference-import-review

**B-008 resolved on board:** C105188/C94934/C20917/C15127 reimported through official easyeda0.0.370 CLI and validated with core0.0.2070. Physical footprint and pin-label blocks unchanged; native U7/D2/Q1/Q2 reference text belongs to the correct component. All four builds/all20 diagnostics pass, three A4 exports/snapshots visually reviewed. B-003 rechecked successfully. Earlier B-008 entries are historical reproductions.

**Assembly blocker B-005 persists:** current microphone four polygon grounds still have no solder paste. Native C41348533/LD-SM-430 alternate motor imports successfully, but its three polygon lands also have zero paste; candidate remains unselected. Three additional speaker imports C20613566/C49246973/C7430168 lack supplier library data (B-012). No invented substitutions or component patches. Full power/privacy/pack/hold mechanics/speaker qualification and final placement still gate whole-board routing. B-010 remains a strict automated-check blocker, not permission to hide native failures. B-009/B-015 gate publication/final fabrication exports and do not stop independent circuit authoring. B-007/B-011 are documented qualification questions, not newly proven manufacturing defects. Evidence: `evidence/blocker-recheck-2026-10-03-1357/`.

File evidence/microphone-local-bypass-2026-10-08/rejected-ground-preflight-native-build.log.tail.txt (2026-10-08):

TP_MOTOR_N has no courtyard
TP1 has no courtyard
TP2 has no courtyard
TP3 has no courtyard
TP4 has no courtyard
TP5 has no courtyard
TP6 has no courtyard
TP7 has no courtyard
TP8 has no courtyard
<testpoint#1372(.ControlsSheet-group>.TP_MOTOR_P) /> is missing a manufacturer part number and could not be resolved to a supplier part. Specify mpn, manufacturerPartNumber, or mfn, provide supplierPartNumbers, or configure a parts engine to select a part. If this part will not be assembled, mark it doNotPlace.
<testpoint#1378(.ControlsSheet-group>.TP_MOTOR_N) /> is missing a manufacturer part number and could not be resolved to a supplier part. Specify mpn, manufacturerPartNumber, or mfn, provide supplierPartNumbers, or configure a parts engine to select a part. If this part will not be assembled, mark it doNotPlace.
<testpoint#1485(.test-access-group>.TP1) /> is missing a manufacturer part number and could not be resolved to a supplier part. Specify mpn, manufacturerPartNumber, or mfn, provide supplierPartNumbers, or configure a parts engine to select a part. If this part will not be assembled, mark it doNotPlace.
<testpoint#1491(.test-access-group>.TP2) /> is missing a manufacturer part number and could not be resolved to a supplier part. Specify mpn, manufacturerPartNumber, or mfn, provide supplierPartNumbers, or configure a parts engine to select a part. If this part will not be assembled, mark it doNotPlace.
<testpoint#1497(.test-access-group>.TP3) /> is missing a manufacturer part number and could not be resolved to a supplier part. Specify mpn, manufacturerPartNumber, or mfn, provide supplierPartNumbers, or configure a parts engine to select a part. If this part will not be assembled, mark it doNotPlace.
<testpoint#1503(.test-access-group>.TP4) /> is missing a manufacturer part number and could not be resolved to a supplier part. Specify mpn, manufacturerPartNumber, or mfn, provide supplierPartNumbers, or configure a parts engine to select a part. If this part will not be assembled, mark it doNotPlace.
<testpoint#1509(.test-access-group>.TP5) /> is missing a manufacturer part number and could not be resolved to a supplier part. Specify mpn, manufacturerPartNumber, or mfn, provide supplierPartNumbers, or configure a parts engine to select a part. If this part will not be assembled, mark it doNotPlace.
<testpoint#1515(.test-access-group>.TP6) /> is missing a manufacturer part number and could not be resolved to a supplier part. Specify mpn, manufacturerPartNumber, or mfn, provide supplierPartNumbers, or configure a parts engine to select a part. If this part will not be assembled, mark it doNotPlace.
<testpoint#1521(.test-access-group>.TP7) /> is missing a manufacturer part number and could not be resolved to a supplier part. Specify mpn, manufacturerPartNumber, or mfn, provide supplierPartNumbers, or configure a parts engine to select a part. If this part will not be assembled, mark it doNotPlace.
<testpoint#1527(.test-access-group>.TP8) /> is missing a manufacturer part number and could not be resolved to a supplier part. Specify mpn, manufacturerPartNumber, or mfn, provide supplierPartNumbers, or configure a parts engine to select a part. If this part will not be assembled, mark it doNotPlace.
Trace [U2.pin3 to U2.pin2] is routed thinner than requested (requested: 0.3mm, actual: 0.2mm).
Trace [U2.pin8 to U2.pin3] is routed thinner than requested (requested: 0.28mm, actual: 0.2mm).
Trace [.U5 > .pin3 to .CONNECTION_VIA_46 > .top] is routed thinner than requested (requested: 0.4mm, actual: 0.2mm).
Trace [.U4 > .pin3 to .CONNECTION_VIA_47 > .top] is routed thinner than requested (requested: 0.36mm, actual: 0.2mm).
Autorouting was skipped because the 2mm maximum length for C81.pin2 to net.GND cannot be satisfied: its endpoints are 2.15mm apart.
Port [U1.TXD0] is not connected to net [MCU_UART_TX] by a PCB trace.
Port [R38.pin1] is not connected to net [MCU_UART_TX] by a PCB trace.
Port [J1.B5] is not connected to net [USB_CC2] by a PCB trace.
Port [R34.pin1] is not connected to net [USB_CC2] by a PCB trace.
Port [U1.IO21] is not connected to net [MCU_HOLD_READ] by a PCB trace.
Port [U1.IO5] is not connected to net [MCU_HAPTIC_ENABLE] by a PCB trace.
Ports [U2.L1, L1.pin1] are not connected together through the same net.
Ports [U2.L2, L1.pin2] are not connected together through the same net.
Port [R5.pin2] is not connected to net [REG_FB] by a PCB trace.
Port [R6.pin1] is not connected to net [REG_FB] by a PCB trace.
Port [U2.FB] is not connected to net [REG_FB] by a PCB trace.
Port [R7.pin2] is not connected to net [REG_PG] by a PCB trace.
Port [U2.PG] is not connected to net [REG_PG] by a PCB trace.
Port [J7.pin50] is not connected to net [LCD_BACKLIGHT_OUTPUT] by a PCB trace.
Port [J7.pin49] is not connected to net [LCD_BACKLIGHT_RETURN_1] by a PCB trace.
Port [J7.pin48] is not connected to net [LCD_BACKLIGHT_RETURN_2] by a PCB trace.
Port [J7.pin47] is not connected to net [LCD_BACKLIGHT_RETURN_3] by a PCB trace.
Port [J7.pin46] is not connected to net [LCD_BACKLIGHT_RETURN_4] by a PCB trace.
Port [J7.pin45] is not connected to net [GND] by a PCB trace.
Port [J7.pin44] is not connected to net [VLCD] by a PCB trace.
Port [J7.pin43] is not connected to net [VLCD] by a PCB trace.
Port [J7.pin42] is not connected to net [VLCD] by a PCB trace.
Port [J7.pin41] is not connected to net [LCD_RESET_N] by a PCB trace.
Port [J7.pin40] is not connected to net [GND] by a PCB trace.
Port [J7.pin39] is not connected to net [GND] by a PCB trace.
Port [J7.pin38] is not connected to net [GND] by a PCB trace.
Port [J7.pin37] is not connected to net [GND] by a PCB trace.
Port [J7.pin36] is not connected to net [GND] by a PCB trace.
Port [J7.pin35] is not connected to net [GND] by a PCB trace.
Port [J7.pin34] is not connected to net [GND] by a PCB trace.
Port [J7.pin33] is not connected to net [GND] by a PCB trace.
Port [J7.pin32] is not connected to net [GND] by a PCB trace.
Port [J7.pin31] is not connected to net [GND] by a PCB trace.
Port [J7.pin30] is not connected to net [GND] by a PCB trace.
Port [J7.pin29] is not connected to net [GND] by a PCB trace.
Port [J7.pin28] is not connected to net [GND] by a PCB trace.
Port [J7.pin27] is not connected to net [GND] by a PCB trace.
Port [J7.pin26] is not connected to net [GND] by a PCB trace.
Port [J7.pin25] is not connected to net [GND] by a PCB trace.
Port [J7.pin24] is not connected to net [GND] by a PCB trace.
Port [J7.pin23] is not connected to net [GND] by a PCB trace.
Port [J7.pin22] is not connected to net [GND] by a PCB trace.
Port [J7.pin21] is not connected to net [GND] by a PCB trace.
Port [J7.pin20] is not connected to net [GND] by a PCB trace.
Port [J7.pin19] is not connected to net [GND] by a PCB trace.
Port [J7.pin17] is not connected to net [LCD_SDA] by a PCB trace.
Port [J7.pin16] is not connected to net [VLCD] by a PCB trace.
Port [J7.pin15] is not connected to net [LCD_DC] by a PCB trace.
Port [J7.pin14] is not connected to net [LCD_SCLK] by a PCB trace.
Port [J7.pin13] is not connected to net [LCD_CS_N] by a PCB trace.
Port [J7.pin11] is not connected to net [VLCD] by a PCB trace.
Port [J7.pin10] is not connected to net [VLCD] by a PCB trace.
Port [J7.pin9] is not connected to net [VLCD] by a PCB trace.
Port [J7.pin8] is not connected to net [GND] by a PCB trace.
Port [J7.pin3] is not connected to net [GND] by a PCB trace.
Port [J7.pin2] is not connected to net [GND] by a PCB trace.
Port [J7.pin1] is not connected to net [GND] by a PCB trace.
Port [J7.pin51] is not connected to net [GND] by a PCB trace.
Port [J7.pin52] is not connected to net [GND] by a PCB trace.
Port [U3.OUTP] is not connected to net [SPEAKER_P] by a PCB trace.
Port [U3.OUTN] is not connected to net [SPEAKER_N] by a PCB trace.
Port [J4.pin1] is not connected to net [SPEAKER_P] by a PCB trace.
Port [J4.pin2] is not connected to net [SPEAKER_N] by a PCB trace.
Port [U22.EN] is not connected to net [MCU_HAPTIC_ENABLE] by a PCB trace.
Port [R83.pin1] is not connected to net [MCU_HAPTIC_ENABLE] by a PCB trace.
Port [R85.pin1] is not connected to net [MCU_HAPTIC_ENABLE] by a PCB trace.
Port [U26.Y] is not connected to net [HOLD_BUFFER_OUT] by a PCB trace.
Port [R100.pin1] is not connected to net [HOLD_BUFFER_OUT] by a PCB trace.
Port [R100.pin2] is not connected to net [MCU_HOLD_READ] by a PCB trace.
Ports [U27.ISET, R102.pin1] are not connected together through the same net.
Port [U27.D4] is not connected to net [LCD_BACKLIGHT_RETURN_4] by a PCB trace.
Port [U27.D3] is not connected to net [LCD_BACKLIGHT_RETURN_3] by a PCB trace.
Port [U27.D2] is not connected to net [LCD_BACKLIGHT_RETURN_2] by a PCB trace.
Port [U27.D1] is not connected to net [LCD_BACKLIGHT_RETURN_1] by a PCB trace.
Ports [U27.C2_POS, C83.pin1] are not connected together through the same net.
Ports [U27.C2_NEG, C83.pin2] are not connected together through the same net.
Ports [U27.C1_POS, C82.pin1] are not connected together through the same net.
Ports [U27.C1_NEG, C82.pin2] are not connected together through the same net.
Port [U3.OUTP] is not connected to net [SPEAKER_P] by a PCB trace.
Trace [U2.pin9 to L1.pin1] is not connected (it has no PCB trace)
Trace [U2.pin7 to L1.pin2] is not connected (it has no PCB trace)
Trace [U27.pin1 to R102.pin1] is not connected (it has no PCB trace)
Trace [U27.pin9 to C83.pin1] is not connected (it has no PCB trace)
Trace [U27.pin12 to C83.pin2] is not connected (it has no PCB trace)
Trace [U27.pin10 to C82.pin1] is not connected (it has no PCB trace)
Trace [U27.pin11 to C82.pin2] is not connected (it has no PCB trace)
Generating preview images...
[index] Generating PCB SVG...
[index] Written pcb.svg
[index] Generating PCB PNG...
[index] Written pcb.png
[index] Generating schematic SVG...
[index] Written schematic.svg

Build complete
  Circuits  0 passed 1 failed
  Options   pcb-png, pcb-svgs, schematic-svgs, autorouter-dump-srj
  Output    dist

⚠ Build completed with errors
Build exiting with code 1: circuit build errors occurred

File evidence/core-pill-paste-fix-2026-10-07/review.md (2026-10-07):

# Canonical rounded-pad paste repair — tested source, unreleased runtime

The missing paste is a generator defect. `SmtPad.doInitialPcbPrimitiveRender`
emits rounded copper pads for `pill` and `rotated_pill`, but neither branch creates
solder paste. The native schema already supports both rounded paste shapes.

The source repair is implemented against
[tscircuit/core commit 90785db](https://github.com/tscircuit/core/commit/90785dbb91162d8ff7a25dbad6533929d8546f4c),
whose package version is **0.0.2106**. `source.patch` contains the complete six-file
change, including two visual regression tests. No imported component definition,
installed library bundle or generated native JSON was hand-patched.

The focused helper copies the emitted pad's actual position, rotation, layer and
component/group links. Its default aperture scales width, height and radius by
0.7. Explicit margins apply per side, corner radius cannot exceed the aperture's
half-dimensions, and covered or fully removed apertures produce no paste.

## Reproduction and checks

Before the repair, both new tests fail: zero paste records instead of 16 and 8.
Afterwards, **17 relevant tests pass with 308 assertions**, including existing
rectangle, circle, polygon, pill, imported-footprint and rotation regressions.
The full upstream TypeScript check, canonical formatting, package build and
distribution smoke tests pass. The entire upstream test suite was not run.
The upstream source diff passes whitespace and reverse-application checks
against its base. The archived patch retains one required blank context marker;
Git flags that marker as trailing whitespace when the patch itself is staged.
It is preserved byte for byte, rather than corrupting the applicable patch.

The older Bun 1.3.9 dependency installs stalled within their recorded budgets.
Using the repository's CI Bun **1.4.0**, current official source and supported
`--network-concurrency 4`, installation completed in 12.04 seconds. One install
postinstall was blocked by Bun's normal trust policy; the required build and
tests nevertheless ran successfully. Verbose install logs remain private because
they can contain transient redirect headers; resource outcomes are archived.

Cross-package checks use the handbook's build/yalc workflow in an isolated
coupon project. The unmodified canonical C7848 import produces **20 pads and 20
schema-valid native paste apertures**. Every physical pad field matches the
earlier coupon exactly. Its source SHA remains
`7713a61c8f3d2f1c8108d2fcb9ba89f494a129bf5481e5ed4b8e93682e6e386e`.
The existing genuine BQ24074RGTR/U16 and TPS60230RGTR/U27 imports produce
**34 pads and 34 valid apertures**, including both exposed center pads, with
rotation and bottom-layer reflection. All four PNGs were visually inspected.
These are component coupons, not a routed-board or stencil approval.

Yalc links were removed and official packages restored before this evidence was
committed. An initial link briefly targeted the board directory and was removed;
no board build ran with it. The board's package/lock are unchanged, and its
installed core package, JavaScript and types match a fresh official 0.0.2090 npm
tarball byte for byte. The coupon's restored official 0.0.2106 runtime reproduces
**0 versus 20** paste records. Therefore this tested fix is still unreleased.
The source emits a literal software stamp of 0.0.2107 despite package metadata
0.0.2106; the exact source commit identifies these local captures.

## Actual requested PCB outcome

The prior [exact display review](../display028-integration-2026-10-07/review.md)
and [mechanical overlay](../display028-integration-2026-10-07/mechanical-review.pdf)
remain applicable. This source repair does not resolve those mechanical gates.

| Requested result | Verified current result |
| --- | --- |
| Final display | Not selected; ER-TFT028A2-4 is an exact-datasheet candidate. Preferred A3 PDF remains challenged. |
| Manufacturer drawing | Archived exact EastRising ER-TFT028A2-4 no-touch drawing, 2019-12-10; SHA in the prior review. |
| Landscape body / active area | 69.3 × 50.2 mm / 57.6 × 43.2 mm. Body remains centered in the reviewed overlay. |
| FPC exit | Right side in the reviewed finished landscape orientation. |
| Final J7 pose | Unassigned. Current accepted native pose is (8.2, −12.625) mm, 90°; it is not a qualified replacement pose. |
| Components moved | None accepted in the active board. |
| Schematic / routing changes | None accepted. Candidate needs SPI mode 0110 and common-cathode backlight changes; final numbered connector mapping is unqualified. |
| Connectivity / DRC | Fresh unchanged-board audit: 0 measured shorts, 0 measured clearance violations, 12 physical open nets. Native has 50 open-port errors. Full pass is false. |
| Fabrication | Blocked; no fabrication package or order approval. |

Centered LCD body overlaps the current antenna keepout by **59.5 mm²**. The flat
26.7 mm tail extends beyond the enclosure; a compatible return path needs verified
contact face, numbered mating order, bend radius, latch access and Z clearance.
The manufacturer PDF gives no numerical minimum bend radius. Moving J7 or routing
its contacts before those checks would rely on assumptions the user forbids.

The accepted native SHA remains
`35c5fb2bfc870daf11b5f5e30847f1e5a86fd886ebb8ef11fc3cf6e88e77e63d`.
Existing schema, stock, trace-width, Gerber, battery-contact and programmer gates
remain open. The board's 32 missing U16/U27 paste records are not claimed fixed.
Next dependencies are a supported released generator repair and the exact
LCD/RF/flex qualification, followed by actual placement, schematic changes,
rerouting and full board requalification. No upstream release, merge, order or
physical-test claim is made.

The saved cloud draft is revision **28**, with 20 custom hosts and updated
continuation instructions. It adds `pkg.pr.new`; saving does not apply runtime
network settings or publish the environment. The initial public verification
confirms GitHub commit 0684f56 and tscircuit release
`0.0.8-wip-speaker-routing` are public and carry the exact accepted native bytes.

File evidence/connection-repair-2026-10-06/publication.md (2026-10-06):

# Verified public connection-repair publication

Source commit: [d2da371](https://github.com/AnasSarkiz/tscircuit-ai-agent-remote/commit/d2da371641867f83c2a141bbc9f44baeb4f304ec).
Public version: **0.0.6-wip-connection-repairs**.
[Native board preview](https://tscircuit.com/AnasSarkiz/tscircuit-ai-agent-remote/releases/09585856-d339-4615-b86b-b13eeca0115e/preview).

Anonymous verification confirms all 125/125 registry files match the supported
package stage, with public/listed/ready-to-build=true. All125/125 corresponding
GitHub files match repository source/model/native bytes; the supported runtime
package.json intentionally curates scripts/description while preserving version,
dependency declarations and overrides. GitHub's anonymous HTML shows Public;
its API metadata request returned 401 and was not used to infer visibility.

The actual public preview contains the exact native object generated by the
frozen CLI: SHA256 fb2f9c96ff000de1e18d6bf4d35bd41fea2323fc0b10730df4a0262b0bbdb73d,
7,543 elements and 26 A4 sheets. The first supported CLI upload returned 413/502;
123 files were verified before the supported SDK resumed only the missing
native JSON and original display STEP model. No file was dropped or changed
for publication, and authenticated upload logs remain outside the repository.

The sole automatically queued cloud build is a5f966cc-ea8c-4c0e-80b7-a676792340bd.
Its read-only observation is recorded separately; no duplicate build was
requested. Preview availability does not mean passing CI, zero connection errors,
fabrication approval or working hardware. The current board still has 53 native
opens, 13 physically open nets, source-width and schema/paste/Gerber/stock/interface
qualification blockers. See review.md and the actual qualification receipts.

The exact current official resolvePart BOM export has 125 rows, zero blank
descriptions and zero supplier codes used as package names; it remains marked
NOT-FOR-FABRICATION and makes no current stock, rotation or assembly claim.

Original native/event/schema evidence retains its generated line endings and
whitespace. The source whitespace check passes with generated evidence excluded;
raw evidence is preserved without normalizing it to pass that check.

Cloud setup verifies 397 exact checkpoint files and all four supervisor smoke
cases. The install/start-instruction draft was saved; review and save it in
Environment settings, then publish the environment. Network/secrets/repository
settings were preserved. Fresh-container restoration has not been verified.

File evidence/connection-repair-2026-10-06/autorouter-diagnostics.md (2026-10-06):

# Speaker routing diagnostics

These are actual failures, not accepted routes or proof that the layout is
unroutable. The remaining negative speaker output needs an outer-layer corridor
that preserves both speaker connections, the existing copper and their widths.

`current-native.srj.json` was exported with the installed public core converter
from untouched `usb-clock-native/circuit.json` and the actual source board's
pair declarations. Its receipt records native SHA-256
`3faeacd8b974b94cbbf85306326e7247d238c27e3923b2242795ee6538bc52ef`,
verified original port identities, 108 connections and 670 obstacles. The full
input is retained separately from the selected-pair diagnostic inputs.

Both speaker members (`source_net_65`, `source_net_64`) are selected together.
Their original 0.6 mm nominal widths, 0.2 mm pair gap, 2 mm skew tolerance,
5 mm maximum uncoupled length, board outline, native obstacles, clearances and
0.30/0.45 mm through-via geometry remain in the diagnostic request. Input bounds
include outboard keepouts; the actual outline still defines the PCB boundary.

Run from the Linux checkout after `source scripts/cloud/env.sh`, under the cloud
supervisor and with no other heavy operation running:

```sh
python3 scripts/cloud/run_with_budget.py --seconds 150 --log /tmp/speaker-bus.log -- bun scripts/routing/solve-native-pair.mjs evidence/connection-repair-2026-10-06/current-native.srj.json source_net_65 source_net_64 /tmp/speaker-bus.json
python3 scripts/cloud/run_with_budget.py --seconds 100 --log /tmp/speaker-fanout.log -- bun scripts/routing/solve-native-pair.mjs evidence/connection-repair-2026-10-06/current-native.srj.json source_net_65 source_net_64 /tmp/speaker-fanout.json fanout pcb_component_51
```

Core 0.0.2090's `BusLanesPipelineSolver` failed after four iterations with
`No collision-free local dogbone assignment`. `FanoutSolver`, using the actual
PCB component ID and explicit 0.275 mm package escapes, failed after 55
iterations with `best layer assignment routed 0/2 connections`. Original inputs,
requests, logs and outcomes are retained. An earlier fanout attempt mistakenly
used the source component ID; the corrected PCB-ID attempt supersedes it.

The independent copper audit finds SPEAKER_P physically connected through native
authored strips, while the exported P connection has no
`externallyConnectedPointIds`. This is a diagnostic observation requiring
converter investigation, not a confirmed upstream bug or an accepted route.
The selected-pair inputs have not been modified to claim that result came from
the native converter. No GitHub issue or other-chat message was sent.

The manual simultaneous-pair proposals are also retained. They reserve both
package escapes but find only one complete trunk; none of those partial paired
replacements was integrated. No nominal speaker width, DRC threshold, imported
pad, generated native JSON or original Pipeline9 cache was weakened or edited
to declare the speaker routed.

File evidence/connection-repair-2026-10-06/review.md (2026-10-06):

# Connection repairs — 0.0.6-wip-connection-repairs

**Engineering WIP; not ready to order.** The actual source-generated board has
53 native open-port errors, down from 89, and 13 physically open nets, down
from 25. No zero-error or working-hardware claim is made.

## Accepted source and native copper

`nominal-envelope-native/circuit.json` is the unmodified output of CLI 0.1.2237,
core 0.0.2090 and the frozen Bun 1.3.9 installation. The CLI ran inside the
complete publication runtime, completed in 256.86 seconds, and exited 1 on the
53 genuine native errors. The native SHA-256 is
`fb2f9c96ff000de1e18d6bf4d35bd41fea2323fc0b10730df4a0262b0bbdb73d`.
It contains 380 traces, 322 vias and 269 pours. The canonical
`dist/index/circuit.json` is byte-identical. Source snapshots and runtime input
hashes are retained; supported package metadata differs from repository scripts
and descriptions, while board source, dependency versions and models match.

Manual native paths repair charger supply/control and centre battery NTC,
USB data/control, display controller clock/reset and control escapes,
amplifier inputs/mode/positive output, microphone supply/clock branches and
U5's explicit ground connection. The J3 outer contacts and contact-dependent
J7 fanout remain untouched. No purchased component moves or import/model edits
were made. TP1 retains the preceding accepted placement.

Four complete replay phases (3, 5, 19 and 21) are replaced by labelled authored
native copper; 13 genuine retained phases replay without changing their original
cache files. Retired source routes and replacement receipts are explicit.
No new Pipeline9 or FreeRouting trial is represented as an accepted solve.

## Measured checks

- Zero physical shorts, zero clearance violations and zero merged named nets.
  The continuity audit still exits 1 because 13 nets are disconnected.
- All 8,152 terminal pairs connected in the v5 baseline remain connected;
  1,690 additional numbered-terminal pairs are connected. The rounded-pad audit
  honours the actual native corner radius and rotation. Earlier 8,146-pair
  receipts used the older contour method and remain historical evidence.
- All 245 authored regions preserve their nominal widths: 97 new connection
  regions, 124 retained power/control regions and 24 inner signal regions.
- All 322 vias have 0.30 mm drilled holes, 0.45 mm pads and a physical span over
  all four layers. No blind/buried via is accepted.
- All 80 retained authored high-current trunks and 67 checked high-current
  native traces use outer layers. The new inner VSYS segment is the separately
  identified U3 GAIN_SLOT input branch; its input-current qualification remains
  open, rather than being approved as a supply trunk.
- All 380 traces / 654 wire segments meet the 0.20 mm board minimum. **Two
  regulator source routes still violate their explicit 1.0 mm minimum with
  0.275 mm sections; 63 traces fall below named-net nominal widths.** Current,
  package necks, USB impedance and speaker pair quality are not qualified.
- All 125 purchased identities, footprints, poses and CAD models are unchanged.
  Source netlist, pin specification, source, schematic-placement and placement
  checks pass. Final native CLI schematic-placement reports zero issues.
- TypeScript and formatting pass; 80 routing regressions pass. Full board tests
  report 48 pass / 2 fail: fabrication completeness and strict native schema.
- Full installed schema still rejects 169 native elements. Official shorts/
  Gerber conversion still fails with `Unsupported shape polygon`. These are
  blocked official checks, even though the independent geometry audit finds no
  shorts. No generated record, import or check was weakened to bypass them.
- All 135 component explanations cover the 26 native A4 sheets and pass the
  annotation schema. Twenty-five rendered sheet SVGs exactly match the reviewed
  v5 pages; the changed speaker page and representative other pages were viewed.
  Four copper layers, mask/paste and USB/charger, both microphone, speaker and
  display details were viewed. Visual review is not fabrication approval.

## Outline generator defect and verified repair

The VBUS width failures were in the authored strip outline, not solely a via
termination. Flat-cap offset buffers at a short bend are not monotonic: increasing
drawn width can remove a wedge required by the nominal width. The generated
outline now unions the width-reserve contour with the complete nominal contour.
The real failing bend is covered by a regression test. Native verification then
passes the original full 0.5 mm trunks. Rejected 0.35 mm via-neck experiments
were removed; all prior native candidates and failed width receipts are retained.

## Remaining connections and fabrication gates

`remaining-native-errors.json` binds every remaining error to this native SHA:
46 J7 contacts, four U27 backlight contacts, U3/J4's two SPEAKER_N contacts and
U4's ground report. Both microphone ground pads physically contact the main
ground island; U4's native connection report remains an unresolved gate. The
disconnected GND islands are J7 pads. The physical open-net list consists of
GND, VLCD, five display logic nets, five backlight nets and SPEAKER_N.

J3's confirmed centre NTC is routed. Its outer numbered BAT+/GND polarity is
unassigned and excluded from the open-net count. J7 FPC contact face, pin-1 and
fold/mating orientation remain unqualified. Do not guess these interfaces.

The dated October 6 stock receipts still match all 125 exact identities; they
report J6/C160405 out of stock and do not qualify U1/D2/U16 assembly allocation
or reservations. Missing pill-pad paste, assembler rotations, bypass placement,
current/stackup, signal integrity, mechanics and final Gerbers remain blockers.
The standard JST programmer requires the documented three-to-six adapter,
separate target power and manual BOOT/RESET; no hardware test is claimed.

## Reproduction and publication

Use `scripts/cloud/setup.sh`, source `scripts/cloud/env.sh`, and run one heavy
operation at a time through `scripts/cloud/run_with_budget.py`. Do not resume
the old whole-net coordinator or run heavy routing on the Mac. The source/native
audit commands, per-command logs and explicit failures are retained here.
Snapshot and setup outcomes are recorded separately; references are not changed
merely to pass a comparison. Exact original native events and schema failure
trees are losslessly archived only after verifying every original byte.

`final-native.srj.json` is the latest actual converter input, with its own native
SHA receipt. The earlier speaker bus-lane and fanout failures and full inputs are
documented in [autorouter-diagnostics.md](autorouter-diagnostics.md); no external
issue or other-chat message was sent. Partial paired routes were not integrated.

GitHub and public tscircuit publication are completed only when their separate
anonymous verification receipts show exact source/native bytes. Native preview
availability does not establish passing cloud CI. No duplicate build, order,
watcher resume or physical-test claim is authorized by this WIP publication.

Final component inventory binds 496 numbered pin assignments to this native output and confirms 32 missing paste records on U16/U27. All eight documented programmer target paths remain logically and physically connected; both microphone grounds contact main GND. The original snapshot references are byte-identical after the completed 58.59-second failing comparison. Cloud setup verifies 397 checkpoint files, installs locked dependencies and passes all four supervisor smoke cases; its saved configuration draft still requires Environment settings publication.

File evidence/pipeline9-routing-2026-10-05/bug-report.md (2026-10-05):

# Pipeline9: high memory use and iteration exhaustion on a four-layer USB routing input

## Summary

`AutoroutingPipelineSolver9_PreloadedTraceGraph` from
`@tscircuit/capacity-autorouter@0.0.958` did not complete routing two USB nets
in the attached board input. A native run exceeded its time budget; a direct
public-library run of the same input exceeded its memory budget while in
`topologyMergingSolver`. A separate native trial with less existing copper
returned an iteration-limit error.

These are observed failures for specific inputs, not a confirmed root-cause
diagnosis or proof that a valid route exists. The original board copper was
restored, and no routes from these failed trials were accepted.

Observed: 2026-10-05. All reproduction artifacts below are pinned to public
repository revision
[`8d478c7ccb2cfb0df53f14447c7d71cad78c43d2`](https://github.com/AnasSarkiz/tscircuit-ai-agent-remote/tree/8d478c7ccb2cfb0df53f14447c7d71cad78c43d2).

## Environment

| Item | Version / setting |
| --- | --- |
| Runtime | Bun 1.3.9, Linux cloud |
| Capacity autorouter | 0.0.958 |
| tscircuit core | 0.0.2090 |
| tscircuit props | 0.0.688 |
| tscircuit | 0.0.2744 |
| tscircuit CLI | 0.1.2237 |
| Explicit selection | `autorouterVersion="beta_pipeline9"` |
| Recorded native solver | `AutoroutingPipelineSolver9_PreloadedTraceGraph` |
| Routing preset / effort | `auto_local` / 1 |
| Solver cache | Disabled: `no_cache_engine` |
| Supervisor memory limit | 22,333,829,939 bytes, 65% of available instance memory |

No dependency, router runtime, iteration-limit or manufacturing-rule patches
were applied. Exact installed-source hashes and selection references are in
[`supported-pipeline9-reference.json`](https://github.com/AnasSarkiz/tscircuit-ai-agent-remote/blob/8d478c7ccb2cfb0df53f14447c7d71cad78c43d2/evidence/pipeline9-routing-2026-10-05/supported-pipeline9-refer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).

## Routing input

The board is 50 × 65 mm with four copper layers and 135 electronic components.
The selected phase contains two nets, `source_net_68` (USB_DN) and
`source_net_69` (USB_DP), each with four terminals. These routes cross much of
the board, from the lower connector toward the MCU area; this is not a minimal
two-pin routing example.

- Net trace widths: 0.2979 mm; global minimum trace width: 0.20 mm.
- Via pad diameter: 0.70 mm; drill diameter: 0.30 mm; blind/buried vias disabled.
- Trace-to-pad-edge clearance: 0.20 mm; board-edge clearance: 0.25 mm.
- Differential pair: 0.2101 mm gap, 0.5 mm length tolerance, maximum
  uncoupled length 5 mm.
- Full-copper input: 9,279 obstacles and 7 preloaded traces.
- Reduced-copper input: 2,996 obstacles and 0 preloaded input traces. This
  temporary source trial omitted manual signal/power copper while retaining
  the components, placements, constraints and original saved-route files.

The exact full-input metadata is recorded in
[`actual-pipeline9-start-receipt.json`](https://github.com/AnasSarkiz/tscircuit-ai-agent-remote/blob/8d478c7ccb2cfb0df53f14447c7d71cad78c43d2/evidence/pipeline9-routing-2026-10-05/actual-pipeline9-start-re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).
Original inputs and events are preserved losslessly, rather than recreated
from the current board source.

## Actual results

Peak memory below is the supervisor's sampled process-group RSS, in bytes.

| Attempt | Elapsed seconds | Peak RSS | Observed result |
| --- | ---: | ---: | --- |
| Full input, native rendering | 660.99 | 11,803,729,920 | Supervisor `TIME_BUDGET_REACHED`; process terminated with SIGTERM, exit −15. Last reported progress approximately 0.2323. No completed route or phase-end event. |
| Same full input, direct public-library runner | 96.84 | 22,385,528,832 | Supervisor `MEMORY_BUDGET_REACHED`; SIGTERM, exit −15. Last recorded phase `topologyMergingSolver`, progress 0.2327936323, iteration 167014. No completed output. |
| Reduced-copper input, native rendering | 448.21 | 17,378,430,976 | Router returned `aJ ran out of iterations (capacity-autorouter@0.0.958)` after progress reached 0.44. Native render process exited 0 but its output retained a routing error. |

The first two are externally stopped incomplete runs, not solver-returned
iteration failures. The direct-library run generated no intermediate preview
frames, so that attempt's memory-limit failure does not require preview
generation. The precise source of the memory growth remains unconfirmed.

The reduced-copper native error was:

```text
Async effect error in PcbTraceRender "autorouting":
AutorouterError: aJ ran out of iterations (capacity-autorouter@0.0.958)
    at runCycleAndQueueNextCycle (.../@tscircuit/core/dist/index.js:107448:24)
    at <anonymous> (.../@tscircuit/core/dist/index.js:107483:27)
```

That rejected trial output contains one `pcb_autorouting_error`, 418
`pcb_port_not_connected_error` elements and seven `pcb_trace_missing_error`
elements. The additional disconnected ports cannot all be attributed to a
router defect: manual copper was intentionally omitted in this trial.
Rendering exit 0 must not be interpreted as successful routing.

## Reproduce the observed direct-library failure

Use a fresh disposable checkout, Bun 1.3.9, Python 3 and GNU tar on Linux.
Dependency installation needs access to the package sources used by the
lockfile. Commands use the public API and unchanged captured route input:

```sh
git clone https://github.com/AnasSarkiz/tscircuit-ai-agent-remote.git
cd tscircuit-ai-agent-remote
git checkout 8d478c7ccb2cfb0df53f14447c7d71cad78c43d2
source scripts/cloud/env.sh
bun install --frozen-lockfile

tar -xOzf evidence/pipeline9-routing-2026-10-05/usb-net-phase-native/native-events.tar.gz \
  start-35.json > /tmp/pipeline9-start.json
sha256sum /tmp/pipeline9-start.json

python3 scripts/cloud/run_with_budget.py \
  --seconds 600 --log /tmp/pipeline9-repro.log -- \
  bun scripts/routing/solve-pipeline9.mjs \
  /tmp/pipeline9-start.json /tmp/pipeline9-output.srj.json
```

Expected extracted-file SHA256:
`01445de85cc77738ea9aec7ff79f7beeda0b5f1e99de323104bbc72c86d16e04`.
The supervisor chooses 65% of available RAM, so a smaller machine may stop
earlier. It writes the actual resource limit and result to
`/tmp/pipeline9-repro.log.outcome.json`; observed time and RSS are not guaranteed
to match on other machines.

The runner calls:

```js
const solver = new AutoroutingPipelineSolver9_PreloadedTraceGraph(
  capturedStart.simpleRouteJson,
  { effort: capturedStart.effort ?? 1 },
)
// Repeated solver.step() until solver.solved or solver.failed.
```

It writes `getOutputSimpleRouteJson()` only after the solver succeeds and
throws if the solver reports failure. This is a diagnostic runner, not a
replacement cache or a generated board artifact.

## Reproduce the reduced-copper native iteration error

In the same fresh disposable checkout, after the preceding operation has
ended, restore the three preserved trial source files. This overwrites those
files with the historical reduced-copper trial; do not apply it to an active
board checkout.

```sh
trial=evidence/pipeline9-routing-2026-10-05/usb-before-manual-copper/source-snapshot
cp "$trial/main.tsx.txt" main.tsx
cp "$trial/src/board/Routing.tsx.txt" src/board/Routing.tsx
cp "$trial/src/board/nets.tsx.txt" src/board/nets.tsx

python3 scripts/cloud/run_with_budget.py \
  --seconds 900 --log /tmp/pipeline9-native-repro.log -- \
  bun evidence/a7-routing-2026-10-05/capture-native.tsx \
  /tmp/pipeline9-native-repro 840000
```

Inspect both the log and emitted `circuit.json` for `pcb_autorouting_error`;
the observed native process exited 0 despite the error. The corresponding
historical native input can also be extracted as `start-35.json` from
`usb-before-manual-copper/native-events.tar.gz`. Its SHA256 is
`795cee7ba121e876bebc6228704f698de47f80a591b3b4204f7aa67ac448cc99`.
A direct-library run of this reduced input has not been tested.

## Expected behavior and investigation request

For a supported input, return valid routes if feasible, or an actionable
failure describing the stage and limiting constraint. Investigate memory
growth during topology merging and the reduced-input iteration exhaustion.
If the input is unsupported or infeasible, identify the relevant constraint
or validation rule so the caller can correct it before an expensive solve.

Only effort 1 and the versions above were tested. No claim is made about
higher effort, newer releases, repeatability across machines or a known
memory leak. The native timeout does not establish a deadlock. The input is
large in obstacle count and has strict differential-pair constraints; its
routability has not been independently proven.

## Evidence links

All links refer to the pinned revision above:

- [Full native event/input archive](https://github.com/AnasSarkiz/tscircuit-ai-agent-remote/blob/8d478c7ccb2cfb0df53f14447c7d71cad78c43d2/evidence/pipeline9-routing-2026-10-05/usb-net-phase-native/nati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)
  and [native timeout receipt](https://github.com/AnasSarkiz/tscircuit-ai-agent-remote/blob/8d478c7ccb2cfb0df53f14447c7d71cad78c43d2/evidence/pipeline9-routing-2026-10-05/usb-net-phase-native.log.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).
- [Direct-library progress log](https://github.com/AnasSarkiz/tscircuit-ai-agent-remote/blob/8d478c7ccb2cfb0df53f14447c7d71cad78c43d2/evidence/pipeline9-routing-2026-10-05/pipeline9-library.log)
  and [memory-limit receipt](https://github.com/AnasSarkiz/tscircuit-ai-agent-remote/blob/8d478c7ccb2cfb0df53f14447c7d71cad78c43d2/evidence/pipeline9-routing-2026-10-05/pipeline9-library.log.out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).
- [Reduced-copper event/input archive](https://github.com/AnasSarkiz/tscircuit-ai-agent-remote/blob/8d478c7ccb2cfb0df53f14447c7d71cad78c43d2/evidence/pipeline9-routing-2026-10-05/usb-before-manual-copper/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),
  [native error log](https://github.com/AnasSarkiz/tscircuit-ai-agent-remote/blob/8d478c7ccb2cfb0df53f14447c7d71cad78c43d2/evidence/pipeline9-routing-2026-10-05/usb-before-manual-copper.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),
  [resource receipt](https://github.com/AnasSarkiz/tscircuit-ai-agent-remote/blob/8d478c7ccb2cfb0df53f14447c7d71cad78c43d2/evidence/pipeline9-routing-2026-10-05/usb-before-manual-copper.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)
  and [rejected native output](https://github.com/AnasSarkiz/tscircuit-ai-agent-remote/blob/8d478c7ccb2cfb0df53f14447c7d71cad78c43d2/evidence/pipeline9-routing-2026-10-05/usb-before-manual-copper/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).
- [Public-library reproduction helper](https://github.com/AnasSarkiz/tscircuit-ai-agent-remote/blob/8d478c7ccb2cfb0df53f14447c7d71cad78c43d2/scripts/routing/solve-pipeline9.mjs).

## Board impact

Routing remains incomplete. The restored accepted board retains 90 native
open-port errors and 26 independently identified disconnected nets. Its
physical copper audit reports zero measured geometry violations and zero
shorts, but its full connectivity/fabrication gate fails. These Pipeline9
failures do not explain every outstanding board error, and the board is not
fabrication-ready.

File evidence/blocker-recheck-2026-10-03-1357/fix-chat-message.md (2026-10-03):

Material update sent to authorized chat01a0f218-ce92-7671-b666-efccdef3aed2 (“Clarify issue status”), hostlocal, on2026-10-03: B-008 corrected using official core2070/easyeda370 and complete native imports; pin-label/footprint blocks unchanged; all24 native build/check commands pass; B-003 linked ground ports persist. B-005 polygon paste remains absent on the microphone and imported C41348533 motor. Three fresh speaker alternatives return no EasyEDA library. No upstream landing authority was granted; continued independent work remains authorized.

Independent fix-chat response (cursor e835563c-0889-4b95-8c60-6ba5d9671068:2): core PR4344 remains open; the reported polygon paste generation covers microphone and motor pads. Release and subsequent Gerber export support remain outstanding. No published fix is inferred from green PR checks.

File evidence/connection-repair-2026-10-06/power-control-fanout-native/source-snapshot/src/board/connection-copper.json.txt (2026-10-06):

{
  "classification": "Authored native connection repairs and low-current signal relocation; not autorouter caches",
  "paths": [
    {
      "net": "MCU_LCD_RESET_N",
      "from": ".U14 > .pin3",
      "to": "net.MCU_LCD_RESET_N",
      "width": 0.2,
      "pcbPath": [
        {
          "x": -1.625,
          "y": -4.67095
        },
        {
          "x": -1.625,
          "y": -4.67095,
          "via": true,
          "fromLayer": "top",
          "toLayer": "bottom"
        }
      ],
      "global_path_mm": [
        [
          7.375,
          5.12905
        ],
        [
          7.375,
          3.32905
        ]
      ],
      "segment_layers": [
        "top",
        "top"
      ],
      "classification": "manual native ordinary via escape; power current qualification pending",
      "top_length_mm": 1.8000000000000003
    },
    {
      "net": "MIC_SD",
      "from": ".U5 > .pin6",
      "to": "net.MIC_SD",
      "width": 0.2,
      "pcbPath": [
        {
          "x": -2.692826,
          "y": -0.800127
        },
        {
          "x": -2.692826,
          "y": -0.800127,
          "via": true,
          "fromLayer": "top",
          "toLayer": "bottom"
        }
      ],
      "global_path_mm": [
        [
          19.1928144,
          -29.000127
        ],
        [
          17.807174,
          -29.800127
        ]
      ],
      "segment_layers": [
        "top",
        "top"
      ],
      "classification": "manual native ordinary via escape; power current qualification pending",
      "top_length_mm": 1.599999786910036
    },
    {
      "net": "MIC_BCLK",
      "from": ".R92 > .pin2",
      "to": "net.MIC_BCLK",
      "width": 0.2,
      "pcbPath": [
        {
          "x": 0.75335,
          "y": -0.8
        },
        {
          "x": 0.75335,
          "y": -0.8,
          "via": true,
          "fromLayer": "top",
          "toLayer": "bottom"
        }
      ],
      "global_path_mm": [
        [
          15.75335,
          -29.75
        ],
        [
          15.75335,
          -30.55
        ]
      ],
      "segment_layers": [
        "top",
        "top"
      ],
      "classification": "manual native ordinary via escape; power current qualification pending",
      "top_length_mm": 0.8000000000000007
    },
    {
      "net": "GND",
      "from": ".R41 > .pin2",
      "to": "net.GND",
      "width": 0.3,
      "pcbPath": [
        {
          "x": 0.35,
          "y": 0.9
        },
        {
          "x": 0.35,
          "y": 0.9,
          "via": true,
          "fromLayer": "top",
          "toLayer": "bottom"
        }
      ],
      "global_path_mm": [
        [
          14.50335,
          -5
        ],
        [
          14.100000000000549,
          -4.0999999999996035
        ]
      ],
      "segment_layers": [
        "top",
        "top"
      ],
      "classification": "manual native GND via escape",
      "top_length_mm": 0.9862510950565635
    },
    {
      "net": "GND",
      "from": ".R69 > .pin2",
      "to": "net.GND",
      "width": 0.3,
      "pcbPath": [
        {
          "x": 2.9,
          "y": -1.1
        },
        {
          "x": 2.9,
          "y": -1.1,
          "via": true,
          "fromLayer": "top",
          "toLayer": "bottom"
        }
      ],
      "global_path_mm": [
        [
          -12.753364,
          7.5
        ],
        [
          -14.899999999999864,
          8.600000000000577
        ]
      ],
      "segment_layers": [
        "top",
        "top"
      ],
      "classification": "manual native GND via escape",
      "top_length_mm": 2.412062626984773
    },
    {
      "net": "GND",
      "from": ".C70 > .pin2",
      "to": "net.GND",
      "width": 0.3,
      "pcbPath": [
        {
          "x": -0.25,
          "y": -0.9
        },
        {
          "x": -1.75,
          "y": -1.2
        },
        {
          "x": -3.85,
          "y": -1.5
        },
        {
          "x": -3.85,
          "y": -1.5,
          "via": true,
          "fromLayer": "top",
          "toLayer": "bottom"
        }
      ],
      "global_path_mm": [
        [
          16.5,
          -3.049976
        ],
        [
          17.400000000000595,
          -3.999999999999602
        ],
        [
          17.7000000000006,
          -5.499999999999623
        ],
        [
          18.000000000000604,
          -7.599999999999653
        ]
      ],
      "segment_layers": [
        "top",
        "top",
        "top",
        "top"
      ],
      "classification": "manual native GND via escape",
      "top_length_mm": 4.959668853436398
    },
    {
      "net": "LCD_DC",
      "from": ".U14 > .pin16",
      "to": "net.LCD_DC",
      "width": 0.2,
      "pcbPath": [
        {
          "x": -0.15,
          "y": 3.95
        },
        {
          "x": 0.15,
          "y": 4.1
        },
        {
          "x": 1.15,
          "y": 4.2
        },
        {
          "x": 1.55,
          "y": 4.6
        },
        {
          "x": 1.55,
          "y": 4.6,
          "via": true,
          "fromLayer": "top",
          "toLayer": "bottom"
        }
      ],
      "global_path_mm": [
        [
          8.675,
          10.87095
        ],
        [
          8.850000000000477,
          11.950000000000628
        ],
        [
          9.150000000000475,
          12.100000000000627
        ],
        [
          10.150000000000489,
          12.200000000000628
        ],
        [
          10.550000000000495,
          12.600000000000634
        ]
      ],
      "segment_layers": [
        "top",
        "top",
        "top",
        "top",
        "top"
      ],
      "classification": "manual native ordinary via escape; power current qualification pending",
      "top_length_mm": 2.9992318023569515
    },
    {
      "net": "LCD_DC",
      "from": ".R44 > .pin1",
      "to": "net.LCD_DC",
      "width": 0.2,
      "pcbPath": [
        {
          "x": -0.753364,
          "y": 1.8
        },
        {
          "x": -0.753364,
          "y": 1.8,
          "via": true,
          "fromLayer": "top",
          "toLayer": "bottom"
        }
      ],
      "global_path_mm": [
        [
          12.996636,
          -3.25
        ],
        [
          12.996636,
          -1.45
        ]
      ],
      "segment_layers": [
        "top",
        "top"
      ],
      "classification": "manual native ordinary via escape; power current qualification pending",
      "top_length_mm": 1.8
    },
    {
      "net": "MIC_BCLK_INPUT",
      "from": ".U24 > .pin1",
      "to": "net.MIC_BCLK_INPUT",
      "width": 0.2,
      "pcbPath": [
        {
          "x": 2.0999,
          "y": -0.65
        },
        {
          "x": 2.0999,
          "y": -0.65,
          "via": true,
          "fromLayer": "top",
          "toLayer": "bottom"
        }
      ],
      "global_path_mm": [
        [
          15.8999,
          -26.65
        ],
        [
          17.0999,
          -26.65
        ]
      ],
      "segment_layers": [
        "top",
        "top"
      ],
      "classification": "manual native ordinary via escape; power current qualification pending",
      "top_length_mm": 1.200000000000001
    },
    {
      "net": "MIC_BCLK_INPUT",
      "from": ".R88 > .pin2",
      "to": "net.MIC_BCLK_INPUT",
      "width": 0.2,
      "pcbPath": [
        {
          "x": 1.75,
          "y": -0.75
        },
        {
          "x": 2.95,
          "y": -0.75
        },
        {
          "x": 2.95,
          "y": -0.75,
          "via": true,
          "fromLayer": "top",
          "toLayer": "bottom"
        }
      ],
      "global_path_mm": [
        [
          14.503364,
          -28.25
        ],
        [
          15.500000000000568,
          -28.999999999999957
        ],
        [
          16.700000000000585,
          -28.999999999999957
        ]
      ],
      "segment_layers": [
        "top",
        "top",
        "top"
      ],
      "classification": "manual native ordinary via escape; power current qualification pending",
      "top_length_mm": 2.4473104330907813
    },
    {
      "net": "MIC_BCLK_INPUT",
      "from": ".R90 > .pin1",
      "to": "net.MIC_BCLK_INPUT",
      "width": 0.2,
      "pcbPath": [
        {
          "x": -0.8,
          "y": -0.8
        },
        {
          "x": -0.8,
          "y": -0.8,
          "via": true,
          "fromLayer": "top",
          "toLayer": "bottom"
        }
      ],
      "global_path_mm": [
        [
          12.996636,
          -23.75
        ],
        [
          12.950000000000529,
          -24.549999999999894
        ]
      ],
      "segment_layers": [
        "top",
        "top"
      ],
      "classification": "manual native ordinary via escape; power current qualification pending",
      "top_length_mm": 0.801358169918908
    },
    {
      "net": "AMP_BCLK",
      "from": ".R69 > .pin1",
      "to": "net.AMP_BCLK",
      "width": 0.2,
      "pcbPath": [
        {
          "x": 1.65,
          "y": -1.9
        },
        {
          "x": 1.65,
          "y": -1.9,
          "via": true,
          "fromLayer": "top",
          "toLayer": "bottom"
        }
      ],
      "global_path_mm": [
        [
          -11.246636,
          7.5
        ],
        [
          -13.649999999999846,
          9.400000000000588
        ]
      ],
      "segment_layers": [
        "top",
        "top"
      ],
      "classification": "manual native ordinary via escape; power current qualification pending",
      "top_length_mm": 3.0636838147069767
    },
    {
      "net": "AMP_BCLK",
      "from": ".R66 > .pin2",
      "to": "net.AMP_BCLK",
      "width": 0.2,
      "pcbPath": [
        {
          "x": 3.75335,
          "y": 0.0
        },
        {
          "x": 3.75335,
          "y": 0.0,
          "via": true,
          "fromLayer": "top",
          "toLayer": "bottom"
        }
      ],
      "global_path_mm": [
        [
          -6.24665,
          2
        ],
        [
          -3.24665,
          2.0
        ]
      ],
      "segment_layers": [
        "top",
        "top"
      ],
      "classification": "manual native ordinary via escape; power current qualification pending",
      "top_length_mm": 3.0
    },
    {
      "net": "MIC_WS",
      "from": ".U5 > .pin1",
      "to": "net.MIC_WS",
      "width": 0.2,
      "pcbPath": [
        {
          "x": -2.000006,
          "y": -1.300049
        },
        {
          "x": -2.000006,
          "y": -1.300049,
          "via": true,
          "fromLayer": "top",
          "toLayer": "bottom"
        }
      ],
      "global_path_mm": [
        [
          19.1928144,
          -29.900049
        ],
        [
          18.499994,
          -30.300049
        ]
      ],
      "segment_layers": [
        "top",
        "top"
      ],
      "classification": "manual native ordinary via escape; power current qualification pending",
      "top_length_mm": 0.8000000666600972
    },
    {
      "net": "AUDIO_ENABLE_SUPPLY",
      "from": ".Q2 > .pin3",
      "to": "net.AUDIO_ENABLE_SUPPLY",
      "width": 0.2,
      "pcbPath": [
        {
          "x": -3.1,
          "y": -1.1
        },
        {
          "x": -3.1,
          "y": -1.1,
          "via": true,
          "fromLayer": "top",
          "toLayer": "bottom"
        }
      ],
      "global_path_mm": [
        [
          -12.149985000000001,
          0.5
        ],
        [
          -14.099999999999852,
          -0.5999999999995538
        ]
      ],
      "segment_layers": [
        "top",
        "top"
      ],
      "classification": "manual native ordinary via escape; power current qualification pending",
      "top_length_mm": 2.2388743824126083
    },
    {
      "net": "AUDIO_ENABLE_SUPPLY",
      "from": ".R63 > .pin1",
      "to": "net.AUDIO_ENABLE_SUPPLY",
      "width": 0.2,
      "pcbPath": [
        {
          "x": -0.753364,
          "y": -0.8
        },
        {
          "x": -0.753364,
          "y": -0.8,
          "via": true,
          "fromLayer": "top",
          "toLayer": "bottom"
        }
      ],
      "global_path_mm": [
        [
          -7.003364,
          -16
        ],
        [
          -7.003364,
          -16.8
        ]
      ],
      "segment_layers": [
        "top",
        "top"
      ],
      "classification": "manual native ordinary via escape; power current qualification pending",
      "top_length_mm": 0.8000000000000007
    },
    {
      "net": "VMIC",
      "from": ".U24 > .pin5",
      "to": "net.VMIC",
      "width": 0.3,
      "pcbPath": [
        {
          "x": -2.25,
          "y": -0.25
        },
        {
          "x": -3.1,
          "y": -1.15
        },
        {
          "x": -3.1,
          "y": -1.8
        },
        {
          "x": -3.1,
          "y": -1.8,
          "via": true,
          "fromLayer": "top",
          "toLayer": "bottom"
        }
      ],
      "global_path_mm": [
        [
          14.1001,
          -26
        ],
        [
          12.750000000000526,
          -26.24999999999992
        ],
        [
          11.900000000000517,
          -27.14999999999993
        ],
        [
          11.900000000000517,
          -27.79999999999994
        ]
      ],
      "segment_layers": [
        "top",
        "top",
        "top",
        "top"
      ],
      "classification": "manual native ordinary via escape; power current qualification pending",
      "top_length_mm": 3.2609931904093235
    },
    {
      "net": "VMIC",
      "from": ".R93 > .pin1",
      "to": "net.VMIC",
      "width": 0.3,
      "pcbPath": [
        {
          "x": 0.35,
          "y": 0.9
        },
        {
          "x": 2.6,
          "y": 0.9
        },
        {
          "x": 2.6,
          "y": 0.9,
          "via": true,
          "fromLayer": "top",
          "toLayer": "bottom"
        }
      ],
      "global_path_mm": [
        [
          15.99665,
          -28.25
        ],
        [
          17.10000000000059,
          -27.349999999999934
        ],
        [
          19.35000000000062,
          -27.349999999999934
        ]
      ],
      "segment_layers": [
        "top",
        "top",
        "top"
      ],
      "classification": "manual native ordinary via escape; power current qualification pending",
      "top_length_mm": 3.6738613775580484
    },
    {
      "net": "VMIC",
      "from": ".U5 > .pin2",
      "to": "net.VMIC",
      "width": 0.3,
      "pcbPath": [
        {
          "x": -0.485242,
          "y": -1.700049
        },
        {
          "x": -0.485242,
          "y": -1.700049,
          "via": true,
          "fromLayer": "top",
          "toLayer": "bottom"
        }
      ],
      "global_path_mm": [
        [
          20.0147584,
          -29.900049
        ],
        [
          20.014758,
          -30.700049
        ]
      ],
      "segment_layers": [
        "top",
        "top"
      ],
      "classification": "manual native ordinary via escape; power current qualification pending",
      "top_length_mm": 0.8000000000001007
    },
    {
      "net": "VMIC",
      "from": ".U5 > .pin5",
      "to": "net.VMIC",
      "width": 0.3,
      "pcbPath": [
        {
          "x": -1.0,
          "y": 2.2
        },
        {
          "x": -1.0,
          "y": 2.2,
          "via": true,
          "fromLayer": "top",
          "toLayer": "bottom"
        }
      ],
      "global_path_mm": [
        [
          19.1928144,
          -28.099951
        ],
        [
          19.500000000000625,
          -26.799999999999926
        ]
      ],
      "segment_layers": [
        "top",
        "top"
      ],
      "classification": "manual native ordinary via escape; power current qualification pending",
      "top_length_mm": 1.3357528196672237
    },
    {
      "net": "MIC_WS",
      "from": ".R93 > .pin2",
      "to": "net.MIC_WS",
      "width": 0.2,
      "pcbPath": [
        {
          "x": 1.55335,
          "y": 0.0
        },
        {
          "x": 1.55335,
          "y": 0.0,
          "via": true,
          "fromLayer": "top",
          "toLayer": "bottom"
        }
      ],
      "global_path_mm": [
        [
          17.50335,
          -28.25
        ],
        [
          18.30335,
          -28.25
        ]
      ],
      "segment_layers": [
        "top",
        "top"
      ],
      "classification": "manual native ordinary via escape; power current qualification pending",
      "top_length_mm": 0.7999999999999972
    },
    {
      "net": "MIC_BCLK",
      "from": ".U5 > .pin4",
      "to": "net.MIC_BCLK",
      "width": 0.2,
      "pcbPath": [
        {
          "x": 0.207579,
          "y": 1.300049
        },
        {
          "x": 0.207579,
          "y": 1.300049,
          "via": true,
          "fromLayer": "top",
          "toLayer": "bottom"
        }
      ],
      "global_path_mm": [
        [
          20.0147584,
          -28.099951
        ],
        [
          20.707579,
          -27.699951
        ]
      ],
      "segment_layers": [
        "top",
        "top"
      ],
      "classification": "manual native ordinary via escape; power current qualification pending",
      "top_length_mm": 0.8000002398651879
    },
    {
      "net": "AMP_DIN",
      "from": ".R68 > .pin1",
      "to": "net.AMP_DIN",
      "width": 0.2,
      "pcbPath": [
        {
          "x": -2.65,
          "y": -1.1
        },
        {
          "x": -2.65,
          "y": -1.1,
          "via": true,
          "fromLayer": "top",
          "toLayer": "bottom"
        }
      ],
      "global_path_mm": [
        [
          -7.753364,
          6
        ],
        [
          -9.649999999999789,
          4.900000000000524
        ]
      ],
      "segment_layers": [
        "top",
        "top"
      ],
      "classification": "manual native ordinary via escape; power current qualification pending",
      "top_length_mm": 2.1925391938330416
    },
    {
      "net": "AMP_DIN",
      "from": ".U3 > .pin1",
      "to": "net.AMP_DIN",
      "width": 0.2,
      "pcbPath": [
        {
          "x": -2.134052,
          "y": -2.299997
        },
        {
          "x": -2.134052,
          "y": -2.299997,
          "via": true,
          "fromLayer": "top",
          "toLayer": "bottom"
        }
      ],
      "global_path_mm": [
        [
          -17.498411,
          2.500003
        ],
        [
          -18.884052,
          1.700003
        ]
      ],
      "segment_layers": [
        "top",
        "top"
      ],
      "classification": "manual native ordinary via escape; power current qualification pending",
      "top_length_mm": 1.6000003065252828
    },
    {
      "net": "AMP_SD_MODE",
      "from": ".U3 > .pin4",
      "to": "net.AMP_SD_MODE",
      "width": 0.2,
      "pcbPath": [
        {
          "x": 0.65,
          "y": -2.25
        },
        {
          "x": 0.65,
          "y": -2.25,
          "via": true,
          "fromLayer": "top",
          "toLayer": "bottom"
        }
      ],
      "global_path_mm": [
        [
          -15.998541,
          2.500003
        ],
        [
          -16.09999999999988,
          1.7500000000004832
        ]
      ],
      "segment_layers": [
        "top",
        "top"
      ],
      "classification": "manual native ordinary via escape; power current qualification pending",
      "top_length_mm": 0.7568344790568484
    },
    {
      "net": "VSYS",
      "from": ".U16 > .pin10",
      "to": "net.VSYS",
      "width": 0.275,
      "pcbPath": [
        {
          "x": 2.4,
          "y": -0.25
        },
        {
          "x": 2.2,
          "y": -3.65
        },
        {
          "x": 2.2,
          "y": -3.65,
          "via": true,
          "fromLayer": "top",
          "toLayer": "bottom"
        }
      ],
      "global_path_mm": [
        [
          -6.5000029999999995,
          -26.249809
        ],
        [
          -5.599999999999731,
          -26.24999999999992
        ],
        [
          -5.799999999999734,
          -29.649999999999967
        ]
      ],
      "segment_layers": [
        "top",
        "top",
        "top"
      ],
      "classification": "manual native ordinary via escape; power current qualification pending",
      "top_length_mm": 4.305880293452751,
      "via_outer_mm": 0.45,
      "via_hole_mm": 0.3
    },
    {
      "net": "VSYS",
      "from": ".U16 > .pin11",
      "to": "net.VSYS",
      "width": 0.275,
      "pcbPath": [
        {
          "x": 2.4,
          "y": -0.65
        },
        {
          "x": 1.65,
          "y": -3.8
        },
        {
          "x": 1.65,
          "y": -3.8,
          "via": true,
          "fromLayer": "top",
          "toLayer": "bottom"
        }
      ],
      "global_path_mm": [
        [
          -6.5000029999999995,
          -25.749937
        ],
        [
          -5.599999999999731,
          -26.649999999999924
        ],
        [
          -6.349999999999742,
          -29.79999999999997
        ]
      ],
      "segment_layers": [
        "top",
        "top",
        "top"
      ],
      "classification": "manual native ordinary via escape; power current qualification pending",
      "top_length_mm": 4.510893847629043,
      "via_outer_mm": 0.45,
      "via_hole_mm": 0.3
    },
    {
      "net": "VSYS",
      "from": ".U3 > .pin2",
      "to": "net.VSYS",
      "width": 0.2,
      "pcbPath": [
        {
          "x": -0.248539,
          "y": -2.299997
        },
        {
          "x": -0.248539,
          "y": -2.299997,
          "via": true,
          "fromLayer": "top",
          "toLayer": "bottom"
        }
      ],
      "global_path_mm": [
        [
          -16.998539,
          2.500003
        ],
        [
          -16.998539,
          1.700003
        ]
      ],
      "segment_layers": [
        "top",
        "top"
      ],
      "classification": "manual native ordinary via escape; power current qualification pending",
      "top_length_mm": 0.8,
      "via_outer_mm": 0.45,
      "via_hole_mm": 0.3
    }
  ],
  "pours": [
    {
      "net": "MCU_LCD_RESET_N",
      "layer": "inner1",
      "nominal_width_mm": 0.2,
      "drawn_width_mm": 0.202,
      "path_mm": [
        [
          7.375,
          3.32905
        ],
        [
          10.00000000000049,
          6.400000000000546
        ],
        [
          9.800000000000487,
          7.000000000000554
        ],
        [
          8.700000000000472,
          7.700000000000564
        ],
        [
          8.100000000000463,
          7.700000000000564
        ],
        [
          5.800000000000431,
          4.500000000000519
        ],
        [
          1.1000000000003638,
          1.6000000000004775
        ],
        [
          -3.2999999999996987,
          -0.39999999999955094
        ],
        [
          -3.8999999999997073,
          -0.1999999999995481
        ],
        [
          -3.9999999999997087,
          0.40000000000046043
        ],
        [
          -3.4999999999997016,
          1.1000000000004704
        ],
        [
          -1.633975,
          1.746636
        ]
      ],
      "outline": [
        {
          "x": 9.886128,
          "y": 6.422226
        },
        {
          "x": 9.715523,
          "y": 6.934042
        },
        {
          "x": 8.670589,
          "y": 7.599
        },
        {
          "x": 8.151788,
          "y": 7.599
        },
        {
          "x": 5.882014,
          "y": 4.441053
        },
        {
          "x": 5.880534,
          "y": 4.439047
        },
        {
          "x": 5.879006,
          "y": 4.437079
        },
        {
          "x": 5.87743,
          "y": 4.435149
        },
        {
          "x": 5.875806,
          "y": 4.433259
        },
        {
          "x": 5.874137,
          "y": 4.431409
        },
        {
          "x": 5.872422,
          "y": 4.429601
        },
        {
          "x": 5.870663,
          "y": 4.427836
        },
        {
          "x": 5.868862,
          "y": 4.426115
        },
        {
          "x": 5.867018,
          "y": 4.424438
        },
        {
          "x": 5.865134,
          "y": 4.422808
        },
        {
          "x": 5.863209,
          "y": 4.421225
        },
        {
          "x": 5.861247,
          "y": 4.419689
        },
        {
          "x": 5.859247,
          "y": 4.418203
        },
        {
          "x": 5.857211,
          "y": 4.416766
        },
        {
          "x": 5.85514,
          "y": 4.41538
        },
        {
          "x": 5.853036,
          "y": 4.414045
        },
        {
          "x": 1.153036,
          "y": 1.514045
        },
        {
          "x": 1.150849,
          "y": 1.512734
        },
        {
          "x": 1.148631,
          "y": 1.511478
        },
        {
          "x": 1.146381,
          "y": 1.510279
        },
        {
          "x": 1.144102,
          "y": 1.509137
        },
        {
          "x": 1.141794,
          "y": 1.508053
        },
        {
          "x": -3.258206,
          "y": -0.491947
        },
        {
          "x": -3.260512,
          "y": -0.492961
        },
        {
          "x": -3.262843,
          "y": -0.493917
        },
        {
          "x": -3.265198,
          "y": -0.494815
        },
        {
          "x": -3.267573,
          "y": -0.495653
        },
        {
          "x": -3.269969,
          "y": -0.496432
        },
        {
          "x": -3.272384,
          "y": -0.497151
        },
        {
          "x": -3.274816,
          "y": -0.49781
        },
        {
          "x": -3.277263,
          "y": -0.498408
        },
        {
          "x": -3.279725,
          "y": -0.498944
        },
        {
          "x": -3.282199,
          "y": -0.499419
        },
        {
          "x": -3.284685,
          "y": -0.499832
        },
        {
          "x": -3.28718,
          "y": -0.500183
        },
        {
          "x": -3.289683,
          "y": -0.500472
        },
        {
          "x": -3.292192,
          "y": -0.500698
        },
        {
          "x": -3.294706,
          "y": -0.500861
        },
        {
          "x": -3.297224,
          "y": -0.500962
        },
        {
          "x": -3.299743,
          "y": -0.501
        },
        {
          "x": -3.302262,
          "y": -0.500975
        },
        {
          "x": -3.30478,
          "y": -0.500887
        },
        {
          "x": -3.307295,
          "y": -0.500736
        },
        {
          "x": -3.309805,
          "y": -0.500523
        },
        {
          "x": -3.31231,
          "y": -0.500247
        },
        {
          "x": -3.314806,
          "y": -0.499909
        },
        {
          "x": -3.317294,
          "y": -0.499508
        },
        {
          "x": -3.319771,
          "y": -0.499046
        },
        {
          "x": -3.322235,
          "y": -0.498522
        },
        {
          "x": -3.324686,
          "y": -0.497937
        },
        {
          "x": -3.327121,
          "y": -0.497291
        },
        {
          "x": -3.329539,
          "y": -0.496584
        },
        {
          "x": -3.331939,
          "y": -0.495817
        },
        {
          "x": -3.931939,
          "y": -0.295817
        },
        {
          "x": -3.934289,
          "y": -0.295001
        },
        {
          "x": -3.936619,
          "y": -0.294128
        },
        {
          "x": -3.938926,
          "y": -0.293197
        },
        {
          "x": -3.94121,
          "y": -0.29221
        },
        {
          "x": -3.943469,
          "y": -0.291167
        },
        {
          "x": -3.945701,
          "y": -0.290069
        },
        {
          "x": -3.947906,
          "y": -0.288916
        },
        {
          "x": -3.950082,
          "y": -0.287709
        },
        {
          "x": -3.952227,
          "y": -0.286449
        },
        {
          "x": -3.95434,
          "y": -0.285136
        },
        {
          "x": -3.956421,
          "y": -0.283772
        },
        {
          "x": -3.958467,
          "y": -0.282356
        },
        {
          "x": -3.960478,
          "y": -0.280891
        },
        {
          "x": -3.962452,
          "y": -0.279377
        },
        {
          "x": -3.964388,
          "y": -0.277815
        },
        {
          "x": -3.966286,
          "y": -0.276205
        },
        {
          "x": -3.968143,
          "y": -0.274549
        },
        {
          "x": -3.969958,
          "y": -0.272848
        },
        {
          "x": -3.971731,
          "y": -0.271103
        },
        {
          "x": -3.973461,
          "y": -0.269315
        },
        {
          "x": -3.975146,
          "y": -0.267484
        },
        {
          "x": -3.976785,
          "y": -0.265613
        },
        {
          "x": -3.978378,
          "y": -0.263701
        },
        {
          "x": -3.979923,
          "y": -0.261751
        },
        {
          "x": -3.98142,
          "y": -0.259764
        },
        {
          "x": -3.982868,
          "y": -0.25774
        },
        {
          "x": -3.984265,
          "y": -0.255682
        },
        {
          "x": -3.985611,
          "y": -0.253589
        },
        {
          "x": -3.986905,
          "y": -0.251464
        },
        {
          "x": -3.988146,
          "y": -0.249308
        },
        {
          "x": -3.989334,
          "y": -0.247122
        },
        {
          "x": -3.990467,
          "y": -0.244907
        },
        {
          "x": -3.991546,
          "y": -0.242665
        },
        {
          "x": -3.992569,
          "y": -0.240397
        },
        {
          "x": -3.993536,
          "y": -0.238105
        },
        {
          "x": -3.994446,
          "y": -0.23579
        },
        {
          "x": -3.995299,
          "y": -0.233452
        },
        {
          "x": -3.996094,
          "y": -0.231095
        },
        {
          "x": -3.996831,
          "y": -0.228718
        },
        {
          "x": -3.997509,
          "y": -0.226325
        },
        {
          "x": -3.998128,
          "y": -0.223915
        },
        {
          "x": -3.998687,
          "y": -0.221491
        },
        {
          "x": -3.999187,
          "y": -0.219053
        },
        {
          "x": -3.999626,
          "y": -0.216604
        },
        {
          "x": -4.099626,
          "y": 0.383396
        },
        {
          "x": -4.100003,
          "y": 0.385846
        },
        {
          "x": -4.100321,
          "y": 0.388304
        },
        {
          "x": -4.100577,
          "y": 0.39077
        },
        {
          "x": -4.100774,
          "y": 0.393241
        },
        {
          "x": -4.100909,
          "y": 0.395716
        },
        {
          "x": -4.100984,
          "y": 0.398194
        },
        {
          "x": -4.100998,
          "y": 0.400672
        },
        {
          "x": -4.100951,
          "y": 0.403151
        },
        {
          "x": -4.100843,
          "y": 0.405627
        },
        {
          "x": -4.100675,
          "y": 0.4081
        },
        {
          "x": -4.100446,
          "y": 0.410569
        },
        {
          "x": -4.100156,
          "y": 0.413031
        },
        {
          "x": -4.099806,
          "y": 0.415485
        },
        {
          "x": -4.099396,
          "y": 0.417929
        },
        {
          "x": -4.098926,
          "y": 0.420363
        },
        {
          "x": -4.098396,
          "y": 0.422785
        },
        {
          "x": -4.097808,
          "y": 0.425193
        },
        {
          "x": -4.09716,
          "y": 0.427585
        },
        {
          "x": -4.096454,
          "y": 0.429962
        },
        {
          "x": -4.095689,
          "y": 0.43232
        },
        {
          "x": -4.094867,
          "y": 0.434658
        },
        {
          "x": -4.093988,
          "y": 0.436976
        },
        {
          "x": -4.093052,
          "y": 0.439271
        },
        {
          "x": -4.092061,
          "y": 0.441543
        },
        {
          "x": -4.091013,
          "y": 0.44379
        },
        {
          "x": -4.089911,
          "y": 0.44601
        },
        {
          "x": -4.088755,
          "y": 0.448203
        },
        {
          "x": -4.087545,
          "y": 0.450367
        },
        {
          "x": -4.086283,
          "y": 0.4525
        },
        {
          "x": -4.084969,
          "y": 0.454602
        },
        {
          "x": -4.083603,
          "y": 0.45667
        },
        {
          "x": -4.082187,
          "y": 0.458705
        },
        {
          "x": -3.582187,
          "y": 1.158705
        },
        {
          "x": -3.580713,
          "y": 1.160715
        },
        {
          "x": -3.579191,
          "y": 1.162688
        },
        {
          "x": -3.57762,
          "y": 1.164623
        },
        {
          "x": -3.576001,
          "y": 1.166519
        },
        {
          "x": -3.574337,
          "y": 1.168374
        },
        {
          "x": -3.572627,
          "y": 1.170188
        },
        {
          "x": -3.570873,
          "y": 1.171959
        },
        {
          "x": -3.569076,
          "y": 1.173686
        },
        {
          "x": -3.567236,
          "y": 1.175368
        },
        {
          "x": -3.565356,
          "y": 1.177004
        },
        {
          "x": -3.563436,
          "y": 1.178593
        },
        {
          "x": -3.561477,
          "y": 1.180135
        },
        {
          "x": -3.559481,
          "y": 1.181627
        },
        {
          "x": -3.557449,
          "y": 1.18307
        },
        {
          "x": -3.555381,
          "y": 1.184462
        },
        {
          "x": -3.55328,
          "y": 1.185803
        },
        {
          "x": -3.551147,
          "y": 1.187092
        },
        {
          "x": -3.548982,
          "y": 1.188327
        },
        {
          "x": -3.546788,
          "y": 1.189509
        },
        {
          "x": -3.544565,
          "y": 1.190637
        },
        {
          "x": -3.542315,
          "y": 1.191709
        },
        {
          "x": -3.540039,
          "y": 1.192725
        },
        {
          "x": -3.537738,
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

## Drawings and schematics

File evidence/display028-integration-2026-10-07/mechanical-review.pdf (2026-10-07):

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

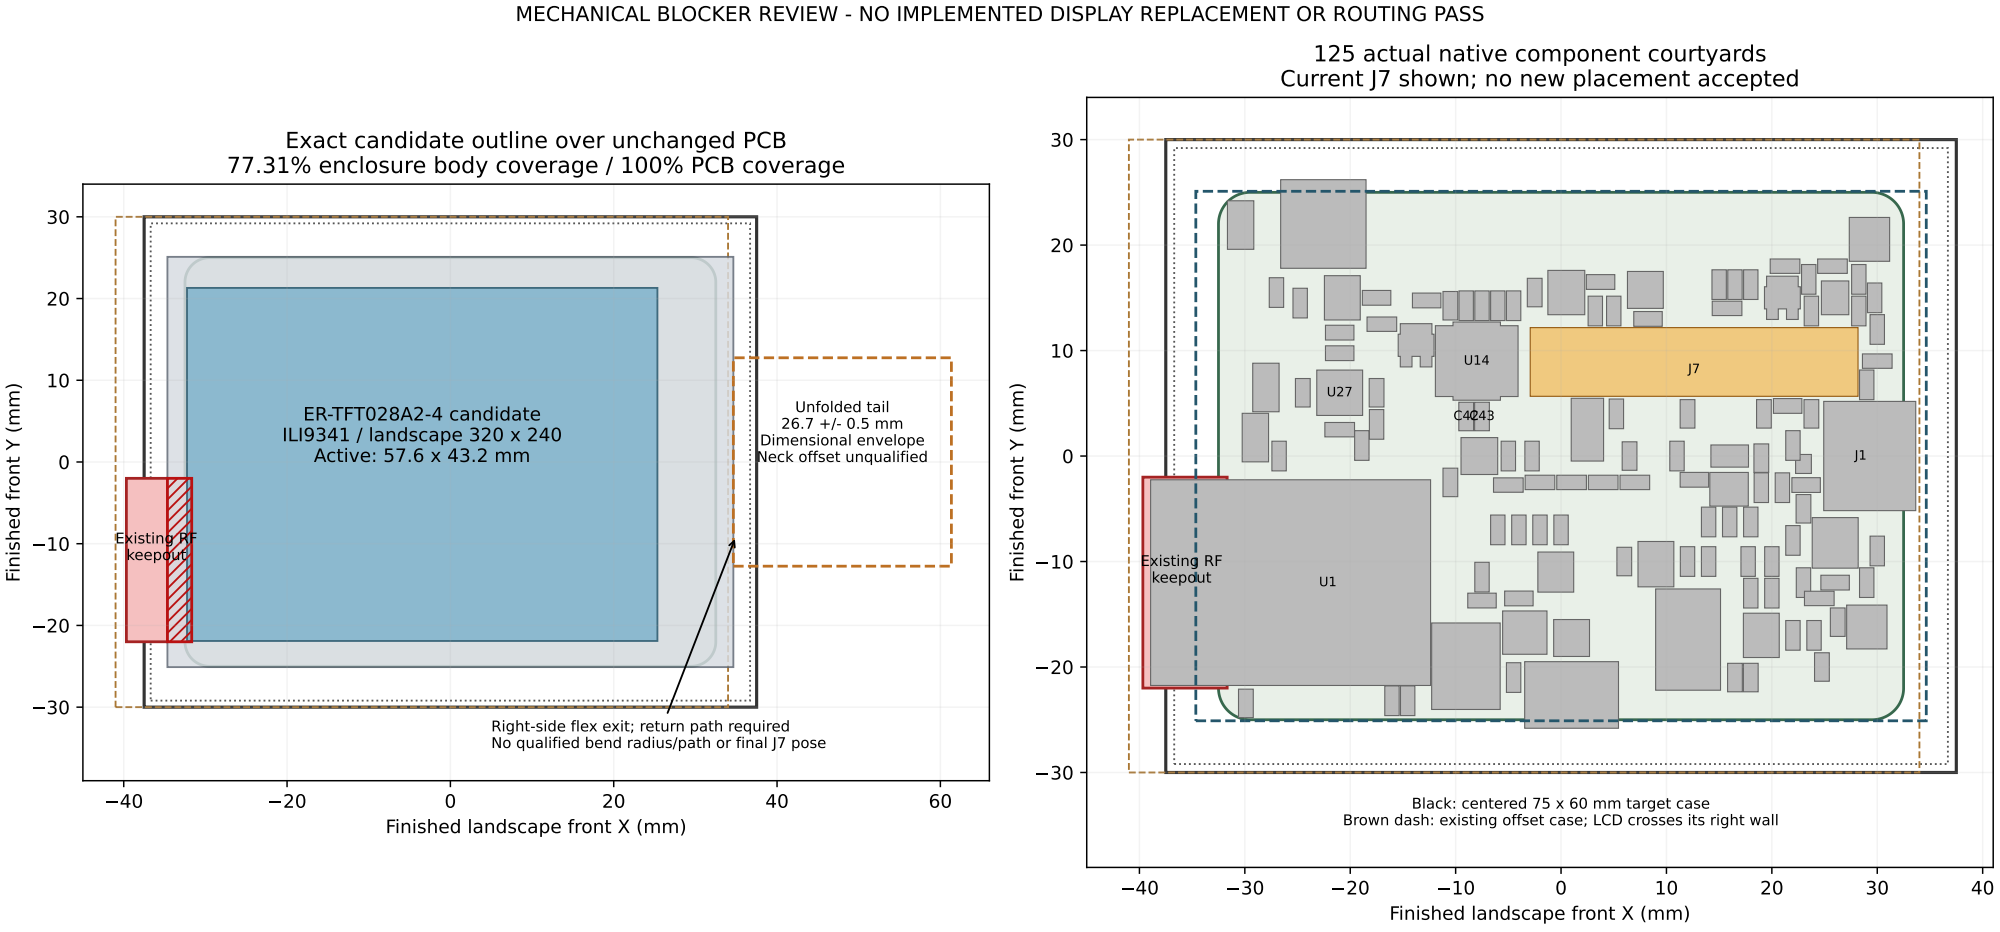
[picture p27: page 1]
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

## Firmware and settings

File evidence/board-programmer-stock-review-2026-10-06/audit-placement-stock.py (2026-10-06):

"""Measure native bypass placements and retain exact dated supplier evidence.

No numeric distance rule, current stock, or hardware success is inferred.
"""
import csv
import datetime
import hashlib
import json
import math
from pathlib import Path


ROOT = Path(__file__).resolve().parents[2]
REVIEW = Path(__file__).resolve().parent
PRIOR = ROOT / 'evidence/order-readiness-2026-10-06'


def read_json(path):
    return json.loads(path.read_text())


def capacitor_distance(context, row):
    capacitor = context['ports'][row['pcb_port_id']]
    supply = context['supply']
    ground = context['pins'][(row['reference'], 2)]
    return {
        'capacitor': row['reference'],
        'capacitance_f': context['components'][row['reference']]['capacitance'],
        'supply_pin_center_mm': {'x': capacitor['x'], 'y': capacitor['y']},
        'supply_pin_center_distance_mm': math.hypot(capacitor['x'] - supply['x'],
                                                   capacitor['y'] - supply['y']),
        'same_supply_copper_island': bool(set(row['physical_island_ids']) &
                                         set(context['supply_pin']['physical_island_ids'])),
        'native_cap_supply_error': row['native_port_error'],
        'ground_island_ids': ground['physical_island_ids'],
    }


def measure_decoupling(context):
    supplies = [
        ('U1', 2, 'V3V3', ['C30', 'C31', 'C32']),
        ('U12', 3, 'V3V3', []),
        ('U2', 10, 'VSYS', ['C4']), ('U2', 6, 'V3V3', ['C5']),
        ('U13', 1, 'V3V3', ['C40']), ('U13', 5, 'VLCD', ['C41']),
        ('U14', 20, 'VLCD', ['C42', 'C43']),
        ('U3', 2, 'VSYS', ['C50', 'C51']),
        ('U3', 7, 'VSYS', ['C50', 'C51']),
        ('U3', 8, 'VSYS', ['C50', 'C51']),
        ('U22', 1, 'VSYS', ['C70']), ('U22', 5, 'VMOTOR', ['C71']),
        ('U23', 1, 'MIC_INPUT', ['C73']), ('U23', 5, 'VMIC', ['C74', 'C75']),
        ('U24', 5, 'VMIC', []),
        ('U4', 5, 'VMIC', ['C80']), ('U5', 5, 'VMIC', ['C81']),
        ('U7', 5, 'V3V3', ['C25']), ('U26', 5, 'V3V3', ['C78']),
    ]
    measurements = []
    for reference, pin_number, net, assigned in supplies:
        supply_pin = context['pins'][(reference, pin_number)]
        assert supply_pin['named_nets'] == [net], (reference, pin_number, supply_pin)
        supply = context['ports'][supply_pin['pcb_port_id']]
        measurement_context = {**context, 'supply': supply, 'supply_pin': supply_pin}
        capacitors = []
        for row in context['pins'].values():
            if not row['reference'].startswith('C') or row['pin_number'] != 1:
                continue
            if row['named_nets'] != [net]:
                continue
            ground = context['pins'][(row['reference'], 2)]
            if ground['named_nets'] != ['GND']:
                continue
            capacitors.append(capacitor_distance(measurement_context, row))
        capacitors.sort(key=lambda row: row['supply_pin_center_distance_mm'])
        assert capacitors, (reference, pin_number)
        assigned_rows = [row for row in capacitors if row['capacitor'] in assigned]
        assert len(assigned_rows) == len(assigned), (reference, assigned)
        measurements.append({
            'reference': reference, 'pin': pin_number, 'net': net,
            'ic_supply_pin_center_mm': {'x': supply['x'], 'y': supply['y']},
            'nearest_same_rail_bypass': capacitors[0],
            'assigned_bypass_measurements': assigned_rows,
            'scope': 'Euclidean native port-centre distance; not routed length, loop inductance or a datasheet maximum-distance rule.',
        })
    (REVIEW / 'decoupling-placement.json').write_text(json.dumps({
        'target_native_sha256': context['sha256'],
        'measurements': measurements,
        'placement_electrical_qualification': 'blocked',
        'scope': 'Current assigned capacitors and nearest same-rail capacitor with GND return. No invented pass threshold.',
    }, indent=2) + '\n')
    return measurements


def retain_stock(context):
    historical_path = ROOT / 'evidence/layout-bom-audit-2026-10-04/supplier-receipt.json'
    historical = read_json(historical_path)
    old = {row['jlc']: row for row in historical['records']}
    quantities = read_json(PRIOR / 'component-summary.json')['supplier_quantities']
    rows = []
    for part, references in sorted(quantities.items()):
        matching = old.get(part, {}).get('exact_results', [])
        receipt = historical_path
        checked_at = historical['checked_at_utc']
        if part == 'C22775':
            receipt = ROOT / 'evidence/a6-bom-routing-2026-10-04/C22775-current-stock.json'
            matching = read_json(receipt)['results']
            checked_at = '2026-10-04 (A6 saved lookup; exact UTC timestamp unavailable)'
        exact = [row for row in matching if 'C' + str(row['lcsc']) == part]
        assert len(exact) == 1, part
        listing = exact[0]
        rows.append({
            'jlcpcb_part': part, 'references': references,
            'required_per_board': len(references),
            'native_mpns': sorted({context['components'][ref]['manufacturer_part_number']
                                   for ref in references}),
            'historical_listing_mpn': listing['mfr'],
            'historical_stock': listing.get('stock'),
            'historical_checked_at': checked_at,
            'historical_receipt': str(receipt.relative_to(ROOT)),
            'current_stock': None,
            'current_availability_status': 'UNVERIFIED_PROXY_ACCESS_BLOCKED',
            'historical_covers_one_board_before_assembly_loss': listing.get('stock', 0) >= len(references),
            'historical_stock_covers_less_than_two_boards': listing.get('stock', 0) < 2 * len(references),
        })
    assert len(rows) == 43 and sum(row['required_per_board'] for row in rows) == 125
    (REVIEW / 'stock-audit.json').write_text(json.dumps({
        'manifest_created_at_utc': datetime.datetime.now(datetime.timezone.utc).isoformat(),
        'target_native_sha256': context['sha256'], 'identity_count': 43,
        'purchased_count': 125, 'fresh_stock_verified_count': 0,
        'lookup_probe': 'supplier-http-receipt.json', 'parts': rows,
        'stock_reserved': False,
        'notes': [
            'Historical listings are not current stock or assembly reservations.',
            'Exact part identities remain; blocked access is not zero stock.',
            'Batch size, assembly allowance, minimum quantity, stock origin and actual JLC order feedback need qualification.',
            'External display, battery, speaker and motor are not PCB assembly parts.',
        ],
    }, indent=2) + '\n')
    fields = ['jlcpcb_part', 'references', 'required_per_board', 'native_mpns',
              'historical_stock', 'historical_checked_at', 'current_stock',
              'current_availability_status']
    with (REVIEW / 'stock-audit.csv').open('w', newline='') as output:
        writer = csv.DictWriter(output, fieldnames=fields)
        writer.writeheader()
        for row in rows:
            writer.writerow({key: ', '.join(row[key]) if isinstance(row[key], list) else row[key]
                             for key in fields})
    return rows


def main():
    native_path = ROOT / 'dist/index/circuit.json'
    native = read_json(native_path)
    sha256 = hashlib.sha256(native_path.read_bytes()).hexdigest()
    assert sha256 == read_json(PRIOR / 'component-summary.json')['source_sha256']
    context = {
        'sha256': sha256,
        'components': {row['name']: row for row in native if row['type'] == 'source_component'},
        'ports': {row['pcb_port_id']: row for row in native if row['type'] == 'pcb_port'},
        'pins': {(row['reference'], row['pin_number']): row
                 for row in read_json(PRIOR / 'pin-assignments.json')},
    }
    measurements = measure_decoupling(context)
    stocks = retain_stock(context)
    print(json.dumps({
        'supply_positions_measured': len(measurements), 'stock_identities': len(stocks),
        'historical_low_margin_parts': [row['jlcpcb_part'] for row in stocks
                                       if row['historical_stock_covers_less_than_two_boards']],
        'fresh_stock_verified': False, 'placement_electrical_qualification': 'blocked',
    }, indent=2))


if __name__ == '__main__':
    main()

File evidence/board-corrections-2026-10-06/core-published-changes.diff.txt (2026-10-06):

--- node_modules/@tscircuit/core/dist/index.js

+++ .upstream-work/published-corrections/tscircuit-core-0.0.2095/package/dist/index.js

@@ -4002,6 +4002,7 @@

           },
           width: element.width,
           height: element.height,
+          ccwRotationDegrees: element.rotation,
           connectedTo: []
         });
       } else if (element.shape === "circle") {
@@ -7708,6 +7709,12 @@

 import { getUnitVectorFromDirection } from "@tscircuit/math-utils";
 
 // lib/utils/autorouting/getBoundsForSchematic.ts
+import {
+  applyToPoint as applyToPoint5,
+  compose as compose4,
+  rotateDEG,
+  translate as translate3
+} from "transformation-matrix";
 function normalizeAngle(angle) {
   const normalized = angle % 360;
   return normalized < 0 ? normalized + 360 : normalized;
@@ -7804,6 +7811,19 @@

       cy2 = elm.center?.y;
       w2 = elm.width;
       h2 = elm.height;
+      if (elm.rotation && cx2 !== void 0 && cy2 !== void 0 && w2 !== void 0 && h2 !== void 0) {
+        const transform = compose4(translate3(cx2, cy2), rotateDEG(elm.rotation));
+        for (const x2 of [-w2 / 2, w2 / 2]) {
+          for (const y2 of [-h2 / 2, h2 / 2]) {
+            const point6 = applyToPoint5(transform, { x: x2, y: y2 });
+            minX = Math.min(minX, point6.x);
+            maxX = Math.max(maxX, point6.x);
+            minY = Math.min(minY, point6.y);
+            maxY = Math.max(maxY, point6.y);
+          }
+        }
+        continue;
+      }
     } else if (elm.type === "schematic_circle") {
       cx2 = elm.center?.x;
       cy2 = elm.center?.y;
@@ -9271,7 +9291,7 @@

 // lib/components/primitive-components/CourtyardOutline.ts
 import { courtyardOutlineProps } from "@tscircuit/props";
 import { getBoundsFromPoints } from "@tscircuit/math-utils";
-import { applyToPoint as applyToPoint5 } from "transformation-matrix";
+import { applyToPoint as applyToPoint6 } from "transformation-matrix";
 var CourtyardOutline = class extends PrimitiveComponent2 {
   pcb_courtyard_outline_id = null;
   isPcbPrimitive = true;
@@ -9299,7 +9319,7 @@

       pcb_component_id,
       layer,
       outline: props.outline.map((p2) => {
-        const transformedPosition = applyToPoint5(transform, {
+        const transformedPosition = applyToPoint6(transform, {
           x: p2.x,
           y: p2.y
         });
@@ -9443,7 +9463,7 @@

 };
 
 // lib/components/primitive-components/Cutout.ts
-import { applyToPoint as applyToPoint6 } from "transformation-matrix";
+import { applyToPoint as applyToPoint7 } from "transformation-matrix";
 import { cutoutProps } from "@tscircuit/props";
 var Cutout = class extends PrimitiveComponent2 {
   pcb_cutout_id = null;
@@ -9491,7 +9511,7 @@

     } else if (props.shape === "polygon") {
       const transform = this._computePcbGlobalTransformBeforeLayout();
       const transformedPoints = props.points.map(
-        (p2) => applyToPoint6(transform, p2)
+        (p2) => applyToPoint7(transform, p2)
       );
       const polygonData = {
         shape: "polygon",
@@ -9624,7 +9644,7 @@

 
 // lib/components/primitive-components/FabricationNotePath.ts
 import { fabricationNotePathProps } from "@tscircuit/props";
-import { applyToPoint as applyToPoint7 } from "transformation-matrix";
+import { applyToPoint as applyToPoint8 } from "transformation-matrix";
 var FabricationNotePath = class extends PrimitiveComponent2 {
   fabrication_note_path_id = null;
   isPcbPrimitive = true;
@@ -9653,7 +9673,7 @@

       layer,
       color: props.color,
       route: props.route.map((p2) => {
-        const transformedPosition = applyToPoint7(transform, {
+        const transformedPosition = applyToPoint8(transform, {
           x: p2.x,
           y: p2.y
         });
@@ -10190,7 +10210,7 @@

 
 // lib/components/primitive-components/PcbNoteLine.ts
 import { pcbNoteLineProps } from "@tscircuit/props";
-import { applyToPoint as applyToPoint9 } from "transformation-matrix";
+import { applyToPoint as applyToPoint10 } from "transformation-matrix";
 var PcbNoteLine = class extends PrimitiveComponent2 {
   pcb_note_line_id = null;
   isPcbPrimitive = true;
@@ -10207,8 +10227,8 @@

     const subcircuit = this.getSubcircuit();
     const group = this.getGroup();
     const transform = this._computePcbGlobalTransformBeforeLayout();
-    const start = applyToPoint9(transform, { x: props.x1, y: props.y1 });
-    const end = applyToPoint9(transform, { x: props.x2, y: props.y2 });
+    const start = applyToPoint10(transform, { x: props.x1, y: props.y1 });
+    const end = applyToPoint10(transform, { x: props.x2, y: props.y2 });
     const pcb_component_id = this.parent?.pcb_component_id ?? this.getPrimitiveContainer()?.pcb_component_id ?? void 0;
     const pcb_note_line = db2.pcb_note_line.insert({
       pcb_component_id,
@@ -10253,7 +10273,7 @@
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

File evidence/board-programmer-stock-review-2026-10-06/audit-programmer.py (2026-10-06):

"""Review the exact published UART pinout against unchanged target copper.

Source topology is checked separately from physical contact. Existing physical
measurements are reused only after their native-input SHA256 is verified.
This does not qualify a cable, flashed programmer, supply or working hardware.
"""
import datetime
import gzip
import hashlib
import json
from pathlib import Path


ROOT = Path(__file__).resolve().parents[2]
REVIEW = Path(__file__).resolve().parent
PREVIOUS = ROOT / 'evidence/order-readiness-2026-10-06'


def read_json(path):
    return json.loads(path.read_text())


def source_components(circuit):
    return {row['name']: row for row in circuit if row['type'] == 'source_component'}


def port_lookup(circuit):
    names = {row['source_component_id']: row['name']
             for row in circuit if row['type'] == 'source_component'}
    return {(names[row['source_component_id']], row.get('pin_number', row['name'])): row
            for row in circuit if row['type'] == 'source_port'
            and row.get('source_component_id') in names}


def electrically_joined(circuit, endpoints):
    ports = port_lookup(circuit)
    parent = {}

    def root(identifier):
        parent.setdefault(identifier, identifier)
        if parent[identifier] != identifier:
            parent[identifier] = root(parent[identifier])
        return parent[identifier]

    for trace in circuit:
        if trace['type'] != 'source_trace':
            continue
        identifiers = trace['connected_source_port_ids'] + trace['connected_source_net_ids']
        for identifier in identifiers[1:]:
            parent[root(identifier)] = root(identifiers[0])
    return len({root(ports[endpoint]['source_port_id']) for endpoint in endpoints}) == 1


def main():
    target_path = ROOT / 'dist/index/circuit.json'
    target_sha256 = hashlib.sha256(target_path.read_bytes()).hexdigest()
    target = read_json(target_path)
    host_path = REVIEW / 'programmer-source/dist/circuits/programmer/circuit.json.gz'
    host_native_bytes = gzip.decompress(host_path.read_bytes())
    host = json.loads(host_native_bytes)
    copper = read_json(PREVIOUS / 'copper-audit.json')
    inventory = read_json(PREVIOUS / 'component-summary.json')
    assert target_sha256 == copper['source_sha256'] == inventory['source_sha256']
    host_components = source_components(host)
    target_components = source_components(target)
    assert target_components['J6']['supplier_part_numbers']['jlcpcb'] == ['C160405']
    assert target_components['U1']['manufacturer_part_number'] == 'ESP32-S3-WROOM-1-N8R8'
    assert target_components['U12']['manufacturer_part_number'] == 'TPS3839G33DBZR'
    for reference, resistance in [('R35', 4700), ('R36', 10000),
                                  ('R37', 100000), ('R38', 1000)]:
        assert target_components[reference]['resistance'] == resistance
    assert host_components['J5']['supplier_part_numbers']['jlcpcb'] == ['C160403']
    assert host_components['R_UART_TX']['resistance'] == 100
    assert host_components['R_UART_RX']['resistance'] == 100
    host_checks = []
    for endpoints in [
        [('J5', 1), ('R_UART_TX', 2)],
        [('R_UART_TX', 1), ('U1', 11)],
        [('J5', 3), ('R_UART_RX', 2)],
        [('R_UART_RX', 1), ('U1', 12)],
        [('J5', 2), ('U1', 57)],
    ]:
        result = electrically_joined(host, endpoints)
        host_checks.append({'endpoints': endpoints, 'logical_connected': result})
        assert result, endpoints
    host_ports = port_lookup(host)
    assert [host_ports[('J5', pin)]['name'] for pin in [1, 2, 3]] == ['TX', 'GND', 'RX']
    assert host_ports[('U1', 11)]['name'] == 'GPIO8'
    assert host_ports[('U1', 12)]['name'] == 'GPIO9'

    assignments = read_json(PREVIOUS / 'pin-assignments.json')
    target_pins = {(row['reference'], row['pin_number']): row for row in assignments}
    target_checks = []
    for endpoints in [
        [('J6', 6), ('U1', 36)],
        [('J6', 5), ('R38', 2)],
        [('R38', 1), ('U1', 37)],
        [('J6', 1), ('J6', 7), ('J6', 8), ('U1', 1), ('U1', 40), ('U1', 41),
         ('U12', 1), ('R37', 2), ('SW1', 2), ('SW2', 2)],
        [('J6', 3), ('U1', 3), ('R35', 2), ('R37', 1), ('SW2', 1)],
        [('U12', 2), ('R35', 1)],
        [('J6', 4), ('U1', 27), ('R36', 2), ('SW1', 1)],
        [('J6', 2), ('U1', 2), ('U12', 3), ('R36', 1)],
    ]:
        rows = [target_pins[endpoint] for endpoint in endpoints]
        groups = [set(row['physical_island_ids']) for row in rows]
        physical_connected = all(len(group) == 1 for group in groups) and bool(set.intersection(*groups))
        logical_connected = electrically_joined(target, endpoints)
        no_port_errors = all(not row['native_port_error'] for row in rows)
        target_checks.append({'endpoints': endpoints, 'logical_connected': logical_connected,
                              'physical_connected': physical_connected,
                              'no_native_port_errors': no_port_errors})
        assert physical_connected and logical_connected and no_port_errors, endpoints
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

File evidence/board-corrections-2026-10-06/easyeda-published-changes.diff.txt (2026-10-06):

--- node_modules/easyeda/dist/index.js

+++ .upstream-work/published-corrections/easyeda-0.0.371/package/dist/index.js

@@ -14273,6 +14273,43 @@

 // lib/utils/easyeda-unit-to-mm.ts
 var mil10ToMm = (value) => value * 10 * 0.0254;
 
+// lib/utils/expand-easyeda-path-data.ts
+var expandEasyEdaPathData = (pathData) => {
+  const rawRoute = [];
+  let currentPoint;
+  for (const commandMatch of pathData.matchAll(/([MLAZ])([^MLAZ]*)/gi)) {
+    const command = commandMatch[1]?.toUpperCase();
+    const values = commandMatch[2]?.match(/[-+]?(?:\d*\.\d+|\d+\.?)(?:[eE][-+]?\d+)?/g)?.map(Number) ?? [];
+    if ((command === "M" || command === "L") && values.length >= 2) {
+      currentPoint = { x: values[0], y: values[1] };
+      rawRoute.push(currentPoint);
+    } else if (command === "A" && currentPoint && values.length >= 7) {
+      const [radiusX, , , largeArcFlag, sweepFlag, endX, endY] = values;
+      const generatedArcRoute = generateArcFromSweep(
+        currentPoint.x,
+        currentPoint.y,
+        endX,
+        endY,
+        radiusX,
+        largeArcFlag === 1,
+        sweepFlag === 1
+      );
+      const maxArcSegments = 16;
+      const arcRoute = generatedArcRoute.length <= maxArcSegments + 1 ? generatedArcRoute : Array.from(
+        { length: maxArcSegments + 1 },
+        (_, pointIndex) => generatedArcRoute.at(
+          Math.round(
+            pointIndex * (generatedArcRoute.length - 1) / maxArcSegments
+          )
+        )
+      ).filter((point4) => !!point4);
+      rawRoute.push(...arcRoute.slice(1));
+      currentPoint = { x: endX, y: endY };
+    }
+  }
+  return rawRoute;
+};
+
 // node_modules/@tscircuit/math-utils/dist/chunk-EFLPMB4J.js
 function orientation(p, q, r) {
   const val = (q.y - p.y) * (r.x - q.x) - (q.x - p.x) * (r.y - q.y);
@@ -14386,6 +14423,22 @@

     if (route.length >= 3 && Math.abs(area) > 1e-8) polygons.push(route);
   }
   return polygons;
+};
+
+// lib/utils/get-easyeda-npth-slot-geometry.ts
+var getEasyEdaNpthSlotGeometry = (solidRegion) => {
+  const rawRoute = expandEasyEdaPathData(solidRegion.pathData);
+  if (rawRoute.length < 2) return null;
+  const points = rawRoute.map((point4) => ({
+    x: mil2mm(point4.x) * 10,
+    y: mil2mm(point4.y) * 10
+  }));
+  const firstPoint = points[0];
+  const lastPoint = points.at(-1);
+  if (firstPoint.x !== lastPoint.x || firstPoint.y !== lastPoint.y) {
+    points.push({ ...firstPoint });
+  }
+  return { points };
 };
 
 // lib/utils/normalize-pin-labels.ts
@@ -14976,40 +15029,7 @@

   stroke_width: mil10ToMm(track.width)
 });
 var handleFabricationNoteSolidRegion = (solidRegion, index) => {
-  const rawRoute = [];
-  let currentPoint;
-  for (const commandMatch of solidRegion.pathData.matchAll(
-    /([MLAZ])([^MLAZ]*)/gi
-  )) {
-    const command = commandMatch[1]?.toUpperCase();
-    const values = commandMatch[2]?.match(/[-+]?(?:\d*\.\d+|\d+\.?)(?:[eE][-+]?\d+)?/g)?.map(Number) ?? [];
-    if ((command === "M" || command === "L") && values.length >= 2) {
-      currentPoint = { x: values[0], y: values[1] };
-      rawRoute.push(currentPoint);
-    } else if (command === "A" && currentPoint && values.length >= 7) {
-      const [radiusX, , , largeArcFlag, sweepFlag, endX, endY] = values;
-      const generatedArcRoute = generateArcFromSweep(
-        currentPoint.x,
-        currentPoint.y,
-        endX,
-        endY,
-        radiusX,
-        largeArcFlag === 1,
-        sweepFlag === 1
-      );
-      const maxArcSegments = 16;
-      const arcRoute = generatedArcRoute.length <= maxArcSegments + 1 ? generatedArcRoute : Array.from(
-        { length: maxArcSegments + 1 },
-        (_, pointIndex) => generatedArcRoute.at(
-          Math.round(
-            pointIndex * (generatedArcRoute.length - 1) / maxArcSegments
-          )
-        )
-      ).filter((point4) => !!point4);
-      rawRoute.push(...arcRoute.slice(1));
-      currentPoint = { x: endX, y: endY };
-    }
-  }
+  const rawRoute = expandEasyEdaPathData(solidRegion.pathData);
   const route = rawRoute.map((point4) => ({
     x: mil10ToMm(point4.x),
     y: mil10ToMm(point4.y)
@@ -15140,9 +15160,11 @@

   });
 };
 var LEAD_SHAPE_LAYER = 100;
+var NPTH_FILL_STYLE = "npth";
 var isPcbSolidRegionCutout = (shape) => {
   return shape.fillStyle === "cutout" && shape.layermask !== LEAD_SHAPE_LAYER;
 };
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

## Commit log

2026-10-02 Initialize AI remote project and document blocked import qualification
    [1_54inch_lcd_module.dxf, BQ24074RGTR.obj, BQ24074RGTR.step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]
2026-10-02 Use native chip box for user-authorized C370970 schematic review
2026-10-02 Correct user-authorized C370970 drill geometry to ALPS ranges
2026-10-02 Record square rechargeable design and recheck published microphone import
    [ICS_43434.obj, ICS_43434.step, S2B_PH_SM4_TB_LF__SN_.obj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]
2026-10-02 Correct authorized C5656610 acoustic hole and document ground-port blocker
2026-10-03 Add unrouted A4 regulator review and verify microphone release gap
    [DFE201612E_R47M_P2.obj, DFE201612E_R47M_P2.step, GRM188R61A106ME69D.obj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]
2026-10-03 Align official core and verify microphone ports and stencil blocker
    [F_Paste.gbr]
2026-10-03 Review hardware microphone isolation and correct regulator divider
    [EVQPUC02K.obj, EVQPUC02K.step, RC0603FR_07100RL.obj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]
2026-10-03 Review MCU USB connections and improve regulator bias margin
    [AFC07_S10FCC_00.obj, AFC07_S10FCC_00.step, RC0603FR_0722RL.obj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]
2026-10-03 Review default-off speaker amplifier and USB charging candidates
    [AO3400A.obj, AO3400A.step, AO3401A.obj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]
2026-10-03 Review hardware Type-C current detection and hold-button cutout
2026-10-03 Review haptic driver and report motor body qualification blockers
    [C2942347-native-model.obj, motor-rail-search.json]
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2026-10-03 Review battery supervisor startup and preserve publication evidence
    [TPS3808G33DBVR.obj, TPS3808G33DBVR.step]
2026-10-03 Review fabrication rules, saved route APIs and BOM metadata loss
    [NOT-FOR-FABRICATION-bom-characterization.csv, SKSWCFE010.obj, SKSWCFE010.step]
2026-10-03 Review hardware hold readback and top-control antenna clearance
    [A_0603WAF1001T5E.obj, A_0603WAF1001T5E.step, A_0603WAF1002T5E.obj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]
2026-10-03 fix(board): qualify official imported reference labels and recheck alternatives
2026-10-03 Build complete A1 unrouted AI remote placement preview
    [MSK12C02.obj, MSK12C02.step]
2026-10-03 Prepare minimal board runtime package with native Circuit JSON
2026-10-04 Use verified native CDN imports for minimal board publication
2026-10-04 Face speaker and haptic connectors toward board edges after 3D review
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2026-10-04 Publish public board runtime with committed native circuit JSON
2026-10-04 Prepare A2 display interface and M2 mounting; leave battery outer polarity pending
2026-10-04 feat: integrate BuyDisplay screen and preserve first native copper routes
    [AFC07_S50ECA_00.obj, AFC07_S50ECA_00.step, AFC07_S50FCC_00.obj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]
2026-10-04 docs: record A3 public upload hashes and missing connector model
2026-10-04 Implement A4 provisional 82 percent display coverage and harness rail
    [S2B_PH_K_S_LF__SN_.obj, S2B_PH_K_S_LF__SN_.step, S3B_PH_K_S_LF__SN_.obj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]
2026-10-04 Record verified public A4 JSON and blocked connector model upload
2026-10-04 Record public placement review receipts and remaining assembly gates
2026-10-04 Replace motor connector with solder pads and save independent routing phases
2026-10-04 Record public motor-pad revision and exact package readback
2026-10-04 Audit current layout, paste coverage and exact BOM availability
2026-10-04 Qualify available resistors and save A6 partial backlight routes
    [A_0603WAF1000T5E.obj, A_0603WAF1000T5E.step]
2026-10-05 Route independent board circuitry and qualify full-span copper WIP
2026-10-05 Verify registry board preview data and record pending cloud build
2026-10-05 Verify public routing report and unchanged board publication
2026-10-06 Audit current board connectivity, trace widths and fabrication readiness
    [NOT-FOR-FABRICATION-bom.csv, NOT-FOR-FABRICATION-pick-and-place.csv, pin-assignments.csv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]
2026-10-06 Review decoupling placement, exact JST programmer pinout and stock blockers
    [stock-audit.csv]
2026-10-06 Record public board review and exact artifact verification
2026-10-06 Correct local MCU bypass and reproducible WIP publication package
    [NOT-FOR-FABRICATION-bom.csv, NOT-FOR-FABRICATION-pick-and-place.csv, NOT-FOR-FABRICATION-resolved-bom.csv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]
2026-10-06 Record exact public board publication and cloud infrastructure failure
2026-10-06 Explain every board component on paired A4 schematic guides
    [source-diff-check.txt]
2026-10-06 Record verified schematic publication and preserve native check outcomes
2026-10-06 Use native USB schematic and qualify through vias and outer power copper
    [NOT-FOR-FABRICATION-bom.csv, NOT-FOR-FABRICATION-pick-and-place.csv, NOT-FOR-FABRICATION-resolved-bom.csv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]
2026-10-06 Repair verified board connections and preserve full-width native copper
    [NOT-FOR-FABRICATION-bom.csv, NOT-FOR-FABRICATION-pick-and-place.csv, pin-assignments.csv]
2026-10-06 Record verified public connection-repair source and native preview
    [NOT-FOR-FABRICATION-resolved-bom.csv]
2026-10-06 Repair microphone ground with qualified manual copper and retain failed speaker trials
    [NOT-FOR-FABRICATION-bom.csv, NOT-FOR-FABRICATION-pick-and-place.csv, NOT-FOR-FABRICATION-resolved-bom.csv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]
2026-10-07 Route both speaker outputs with qualified manual copper
    [NOT-FOR-FABRICATION-bom.csv, NOT-FOR-FABRICATION-pick-and-place.csv, NOT-FOR-FABRICATION-resolved-bom.csv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]
2026-10-07 Review uploaded display and record blocked right-side replacement selection
    [display-pin-audit.csv]
2026-10-07 Record independent display search and actual schematic UI findings
    [external-secondary-pin-table.tsv]
2026-10-07 docs: review approved ER-TFT023-1 display and connector proposals
    [primary-pin-audit.csv]
2026-10-07 Record exact landscape LCD blockers and preserve rejected display staging
    [panel-pin-review.csv]
2026-10-07 Replace service header with standard UART and repair supply copper
    Use untouched genuine JLCPCB C160389 with direct programmer pin roles. Preserve retained terminal connectivity, clear its audio gate, and restore a full-width 0.8 mm outer-layer supply bypass. Save completed native generation, exact source/model provenance, all failed trials and unsuppressed fabrication gates. Publish as WIP; display integration and full fabrication qualification remain open.
    [BM03B_SRSS_TB_LF__SN_.obj, BM03B_SRSS_TB_LF__SN_.step, NOT-FOR-FABRICATION-bom.csv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]
2026-10-07 Record exact public UART repair publication and remaining fabrication gates
2026-10-08 Place and qualify the genuine local U5 microphone bypass
    [NOT-FOR-FABRICATION-bom.csv, NOT-FOR-FABRICATION-pick-and-place.csv, NOT-FOR-FABRICATION-resolved-bom.csv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]
2026-10-08 Record exact public WIP delivery and current fabrication blockers
2026-10-09 Qualify canonical board runtime, exports and schematic source
    [B_Cu.gbr, B_Mask.gbr, B_Paste.gbr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]
2026-10-09 Preserve and qualify complete cloud-generated board artifact
    [B_Cu.gbr, B_Mask.gbr, B_Paste.gbr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]
